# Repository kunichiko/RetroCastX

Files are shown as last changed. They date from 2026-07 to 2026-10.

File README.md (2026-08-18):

# RetroCastX

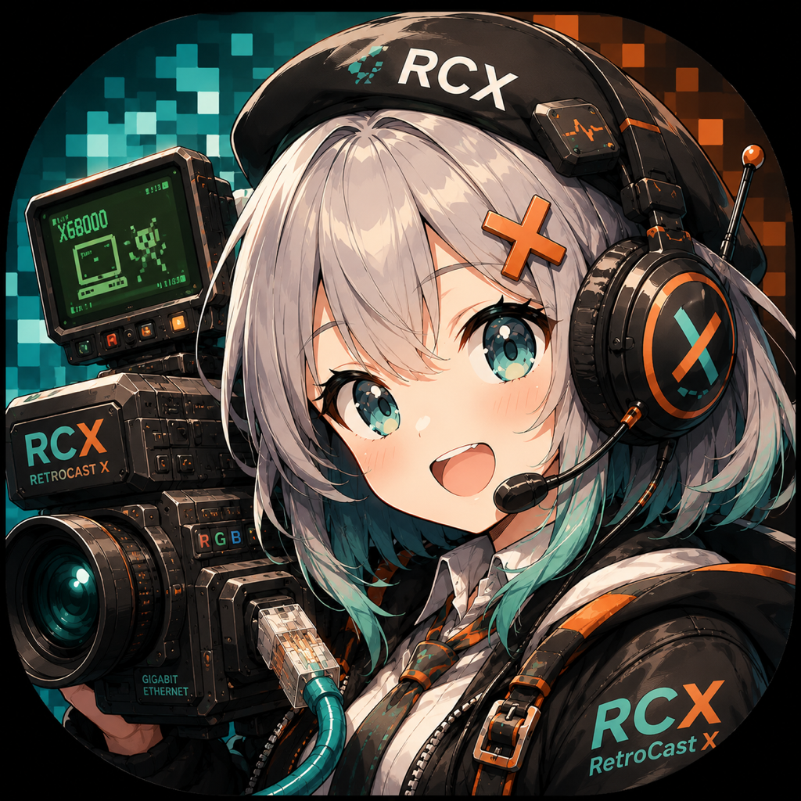
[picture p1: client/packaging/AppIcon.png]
RetroCastX


レトロPC(X68000 / PC-98 など)のアナログRGB信号を、フレームバッファレスで PC/Mac に伝送・表示するプロジェクト。

```
Retro PC ──アナログRGB──▶ ADC(TVP7002) ──24bit+PCLK──▶ FPGA(ECP5) ──UDP/GbE──▶ PC/Mac(再構成・表示)
```

## 設計思想

一般的なアップスキャンコンバータは変換器内でフレームバッファを構築し標準的なHDMI信号に整形するため、
機種固有のタイミング情報が失われ、遅延・モード切替時のブラックアウト・価格の問題が生じる。

RetroCastX は「変換器は馬鹿に徹し、知性はPC側に置く」:

- ADC でドットクロックを再生してサンプリングした**生のピクセルデータを、タイミング情報ごと**
  「1パケット≒1ライン」の UDP で送出する(FPGA はラインFIFO程度しか持たない)
- フレームの再構成・スケーリング・表示は PC/Mac 側で行う

これにより:

- **生タイミング保存**: VRR対応モニタなら 55.46Hz(X68000)等の非標準リフレッシュをそのまま表示可能
- **モード切替の無切断追従**: ゲーム中の解像度切替もヘッダ通知で追従
- **真のロスレス**: 8bit で取得し PC 側でパレット吸着(X68000 は本来 RGB 各5bit)
- **低遅延**: サブフレーム(ライン単位)伝送
- **安価**: フレームバッファ用メモリも高度な画像処理も変換器側に不要

## リポジトリ構成

```
docs/
  protocol-v0.md    伝送プロトコル仕様 v0(ドラフト)
  research/         部品・ボード調査レポート
gateware/           FPGA側(LiteX / Colorlight i5)※sim検証済み、実機未検証
hardware/           ADCフロントエンド基板(Atopile、HAT形式)
host/python/        PC側リファレンス実装(送信シミュレータ・受信・検証)
client/             ビューアアプリ(Rust + eframe/egui、Mac/Win/Linux)
```

## クイックスタート(ハードウェア不要)

送信シミュレータと受信器をループバックで動かす:

```sh
cd host/python
python3 -m retrocastx.tests.test_loopback   # プロトコルのE2E検証
python3 -m retrocastx.tests.test_videoin    # コンポジットの波形解析(合成波形で検証)
python3 -m retrocastx.tests.test_ntsc       # NTSC復調(合成6色で真値と照合)
python3 -m retrocastx.sender_sim &          # テストパターンをUDP送出
python3 -m retrocastx.receiver --dump out   # 受信して out/frame_NNNN.ppm に保存
```

## ハードウェア(フェーズ1〜2 想定)

| 役割 | 部品 | 備考 |
|---|---|---|
| FPGAボード | Colorlight i5 + 拡張基板 | ECP5-25F、GbE PHY ×2、SODIMM I/O 直結 |
| ADC | TI TVP7002 | OSSC と同一。15/24/31kHz 実証済み。ブレークアウト自作 |
| 参考回路 | [marqs85/ossc_pcb](https://github.com/marqs85/ossc_pcb) | アナログ入力段・TVP7002 周辺 |

調査の詳細は `docs/research/2026-07-25-hardware-survey.md` を参照。

## ステータス

- [x] 構想・部品調査
- [x] プロトコル v0 ドラフト(映像 LINE/MODE + 音声 AUDIO + 発見/購読 + CONFIG)
- [x] PC側リファレンス実装(シミュレータ + 受信器)
- [x] LiteX ゲートウェア step2(テストパターン送出+購読) — sim検証・ビットストリーム生成済み
- [x] TVP7002 ブレークアウト設計(音声3系統・ArgusX制御含む、電気設計検証まで)
- [x] ビューアアプリ雛形(Rust + eframe、sender_sim相手にE2E確認済み)
- [ ] ゲートウェア実機動作(ボード入手待ち)
- [ ] 基板発注(atopile部品API復旧後にフットプリント紐付け)
- [ ] 音声キャプチャ(gateware step4)・音声再生(client)
- [ ] 実機キャプチャ(X68000 / PC-98)

## ライセンス

ディレクトリごとに異なります。

| 対象 | ライセンス |
|---|---|
| `gateware/` `client/` `host/` | [Apache License 2.0](LICENSE) |
| `hardware/` | [CERN-OHL-S-2.0](hardware/LICENSE)(強い相互性のオープンハードウェアライセンス) |
| `docs/` | [CC BY-SA 4.0](docs/LICENSE) |

`hardware/` の CERN-OHL-S-2.0 は、**この設計を元に製品を作って頒布・販売する場合、
改変を含む設計一式(Complete Source)を公開し、製品または同梱文書に入手先を明記する**
ことを求めます。個人が自分用に作る分にはこの義務は発生しません。

ライセンスの対象外となるファイル(部品メーカーのデータシート、ベンダー由来の
KiCad シンボル・フットプリント等)については [NOTICE](NOTICE) を参照してください。

### 商標

**"RetroCast X"**(正式名称)および **"RetroCastX"**(ファイル名・識別子・
ハッシュタグ等で用いる短縮形)の名称、ロゴ、アイコン、基板シルク上のブランド
表記は、上記いずれのライセンスの許諾範囲にも含まれません
(Apache License 2.0 第6条)。空白の有無・大文字小文字の違いを問いません。

フォークや派生ハードウェアを頒布する場合は、別の名称を用いてください。

### ハードウェアの製造を検討されている方へ

本設計に基づくハードウェアの製造・頒布を計画されている場合、事前にご一報
いただけると嬉しいです。**ライセンス上の義務ではありません**が、既知の問題や
実装上の落とし穴を共有できますし、改善を上流に取り込める場合もあります。

## コントリビューション

歓迎します。手順と DCO(Signed-off-by)については [CONTRIBUTING.md](CONTRIBUTING.md)
を参照してください。特に**手元の実機での動作報告**が助かります。

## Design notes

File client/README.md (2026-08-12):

# RetroCast X(Viewer / クライアントアプリ)

Rust + eframe/egui(wgpuバックエンド)のクロスプラットフォーム・ビューア。
Mac/Windows/Linux を単一コードベースでカバーする。

```sh
cargo run --release                     # SUBSCRIBEをブロードキャストして実機ボードを受信
cargo run --release -- --board 192.168.10.50   # ボードIP指定
cargo run --release -- --no-subscribe   # 受け専用(sender_sim相手はこれ)
cargo run --release -- --fullscreen     # 低遅延フルスクリーン(下記、ESCで終了)
cargo run --release -- --headless 5 --no-subscribe  # GUIなしで受信統計のみ(検証用)
cargo test                              # プロトコル/アセンブラのユニットテスト
```

## Windows で使うときの必須設定: NICの受信バッファー

**これをやらないとパケットを1〜6%落とす**(映像に穴、音が途切れる)。Intel NIC の
`受信バッファー`(受信記述子リング)の既定 **256** が RetroCastX のパケットレート
(31kHz等倍で約35,000 pkt/s)に足りない。管理者PowerShellで:

```powershell
Set-NetAdapterAdvancedProperty -Name 'イーサネット' -RegistryKeyword '*ReceiveBuffers' -RegistryValue 2048
```

実測(同じ機械・同じ線): **256 → lost 1.7%**(間引き2で帯域1/3にしても落ちる)、
**2048 → lost 0.0013%**(等倍316Mbps、audio underruns 0)。

`SO_RCVBUF`(Viewerは64MB確保する)を増やしても効かない。捨てているのは
ソケットバッファではなく**その手前のNICドライバのリング**だから。切り分けは
`Get-NetAdapterStatistics -Name 'イーサネット' | fl ReceivedDiscardedPackets,ReceivedPacketErrors`
で、**errors≒0 なのに discards が大きい**ならこれ。詳細は
[docs/design-notes.md](../docs/design-notes.md)。

**アプリが自分で気付いて知らせる**(`src/netcheck.rs`)。README を読まなくても
分かるように、**起動時にモーダル**を出し、右パネルの Stats にも警告とコピー
できるコマンドを残す。二段構え:

1. **設定を読む。** ボードのIPから `GetBestInterfaceEx` で経路上のNICを引き
   (全アダプタを見ると Wi-Fi と有線が両方生きている機械で誤判定する)、
   LUID → GUID → レジストリの `*ReceiveBuffers` を読む。**読むだけなので管理者
   権限は不要**(実機の ACL は `BUILTIN\Users: ReadKey`)
2. **実測のロスを見る。** `*ReceiveBuffers` は NDIS の advanced property で、
   **ドライバが公開していなければ存在しない**。実機の15アダプタのうち持っていたのは
   Intel の有線だけで、TP-Link の Wi-Fi は持っていなかった。**無いことを「小さい」と
   扱うと嘘の警告になる**ので、その場合は黙って実測のロス率だけで判断する

**モーダルを出すのは設定チェックのときだけ。** 実際に設定を読んでいて
`Unsupported` / `Unknown` では絶対に出さないので、誤警告の経路が無い。しかも
直せば二度と出ない一度きりの修正で、放置すると確実に映像に穴が開く。
一方ロス率ベースの警告は**推定なうえセッション中に発火する**ので、プレイ中に
割り込ませずパネル内だけにしてある。

管理者権限が無くて直せない人に毎回出すのは敵対的なので「今後表示しない」
(設定の `netcheck_muted`)を用意した。**パネル内の表示は消さない** — 直したく
なったときに情報ごと消えていると困る。`--fullscreen` は UI 層が無いので
stderr にしか出せない。

ボードが見つかる前でも判定する(SUBSCRIBE の宛先で経路を引く)。**ボード発見を
待つと、新規の機械でいちばん警告が要る場面で黙ってしまう。**

`--netcheck <ボードのIP>` で GUI なしに結果だけ見られる。実機(Windows 11 26200)
で4通りとも確認済み: Intel有線 → `Known{2048}`「足りています」、同じNICを一時的に
256 にすると「小さすぎます」+ アダプタ名を埋めたコマンド、TP-Link Wi-Fi →
`Unsupported`、Bluetooth PAN → `Unknown`。値は **REG_SZ の文字列**で入る
(DWORD 決め打ちでは読めない)。

一時変更の検証は `Set-NetAdapterAdvancedProperty ... -NoRestart` で行う。
レジストリだけ書いてドライバを再起動しないので、**リンクが落ちず**(SSH越しでも
切れない)実際の受信性能も変わらないまま、読み取り側の判定だけ確かめられる。

sender_sim を相手にした動作確認:

```sh
(cd ../host/python && python3 -m retrocastx.sender_sim --pixfmt rgb555) &
cargo run --release -- --no-subscribe
```

## 配布(GitHub Actions)

`.github/workflows/viewer-release.yml` が Mac/Windows のビルドと配布をする。
構成は MimicX-app の `release-build.yml` に倣ってあり、**Secretsの名前も同じ**なので
同じ証明書とAPIキーをそのまま設定できる。

| きっかけ | すること |
|---|---|
| タグ `v1.2.3` を push | Releaseを作り zip を添付。macOSは署名+公証+staple |
| main へのPR | 両OSで `cargo test` + ビルドのみ(署名も公証もしない) |
| 手動実行(Actions画面) | プラットフォームを選んでビルド。Releaseは触らない |

**バージョンの正は `client/Cargo.toml`。** タグと食い違っていたら `prepare` で止まる
(`v0.2.0` を打つなら先に `version = "0.2.0"` にしてコミットする)。

必要な Secrets(**RetroCastXリポジトリにも登録が必要**。リポジトリのSecretsは
他リポジトリから見えないので、MimicX と同じ値をコピーする):

| Secret | 用途 |
|---|---|
| `MACOS_CERTIFICATE_BASE64` | Developer ID Application 証明書(.p12)のbase64 |
| `MACOS_CERTIFICATE_PASSWORD` | その .p12 のパスワード |
| `KEYCHAIN_PASSWORD` | CI上に作る一時キーチェーンのパスワード(任意の文字列) |
| `APPSTORE_ISSUER_ID` / `APPSTORE_KEY_ID` / `APPSTORE_PRIVATE_KEY` | 公証(notarytool)用のApp Store Connect APIキー |

Secretsが無くてもビルドは通り、**未署名**の `...-unsigned.zip` ができる(フォークや
PRのため)。ただし**タグからのリリースだけは署名必須**で、無ければエラーで止まる。

成果物:

    RetroCastX_macos-<version>.zip          「RetroCast X.app」universal(arm64+x86_64)、署名済み
    RetroCastX_windows-<version>.zip        RetroCastX.exe + README-first.txt
    RetroCastX_windows-setup-<version>.exe  同じ中身のインストーラ(Inno Setup、未署名)

macOSの `.app` は `packaging/macos/bundle.sh` が組み立てる。**CIのYAMLにロジックを
置かず**スクリプトにしてあるので、手元で同じものを作って試せる:

```sh
cargo build --release
packaging/macos/bundle.sh target/release/retrocastx-viewer 0.1.0 0 /tmp/out
open "/tmp/out/RetroCast X.app"
```

**Windowsはインストーラ版も作る**(`client/packaging/windows/retrocastx.iss`、
Inno Setup 6。`windows-latest` に preinstall されている)。中身は zip と同じで、
違いは**固定パスへ入る**ことだけだが、そこに意味がある:

> Windowsのファイアウォール/ローカルネットワークの許可は**実行ファイルのパス
> 単位**なので、zip を展開する場所を変えたり exe を置き換えたりするたびに
> 許可を聞かれ、**許可するまで映像が来ない**(数秒間まったく反応が無いように
> 見える)。インストーラなら次回以降その入れ替わりが起きない。

zip とインストーラで中身が食い違わないよう、**組み立ては1か所**(ワークフローの
`Package zip` が作る `dist/RetroCastX`)にして、ISCC はそれをそのまま入れる。
`AppId` の GUID は**一度決めたら変えない**(アップグレード判定とアンインストール
の識別が壊れる)。手元で作るときは .iss 冒頭のコメントの手順で。

**macOS はアイコンに角丸マスクをかけない。** 丸みも余白も素材側で作る決まりなので、
`make-icons.sh` は Apple の配置規則(1024の画布に本体824×824、角丸半径185.4、周囲は
透明)に合わせて `.icns` を作る。全面ベタのまま入れると **Dock で四角いアイコンに
なる**(Finderは小さく表示するので黒い角に気づけない。実際これで一度作り直した)。

**Windows も同じ絵を使う**(見た目を揃える方針)。Windowsのアイコンは全面ベタが
普通なので、他のアプリと並ぶと1割ほど小さく見える。全面ベタに戻したくなったら
`make-icons.sh` の ico / PNG の生成元を master に変えるだけでよい。

アイコンは `packaging/AppIcon.png`(1024×1024)が master で、そこから
`packaging/make-icons.sh` が3つを作る。**生成物もコミットしてある**(CIに画像変換
ツールを入れない方針。作り直したときは一緒にコミットする):

    packaging/macos/AppIcon.icns    .app に入る(bundle.sh が拾う)
    packaging/windows/AppIcon.ico   exe に埋め込む(build.rs が拾う)

Windows版はコンソール窓を出さずに起動する(`#![windows_subsystem = "windows"]`)。
コンソールから起動したときだけ `AttachConsole(ATTACH_PARENT_PROCESS)` で親の
コンソールへ出力を戻すので、`--headless` の表示は失われない。

**ただしスクリプトから呼ぶときは待たせること。** GUIサブシステムの実行ファイルは
シェルが終了を待たないので、`& exe --netcheck ...` や `cmd /c exe > log` では
**出力が間に合わず空になる**(実機でこれに引っかかった。exit code は 0 なので
気付きにくい)。PowerShell なら:

```powershell
Start-Process -FilePath .\RetroCastX.exe -ArgumentList "--netcheck","192.168.11.50" `
              -Wait -NoNewWindow -RedirectStandardOutput out.log
```

**exeへの埋め込みだけではタスクバーに出ない。** winit はウィンドウクラスを
`hIcon: 0` で登録し、`window_icon` が `None` なら明示的にアイコンを外すので、

    Explorer のファイルのアイコン → exe に埋め込んだリソース(build.rs)
    タイトルバー / タスクバー     → 実行時に設定する(src/appicon.rs)
    macOS の Dock                → .app の CFBundleIconFile(bundle.sh)

の3つが別経路になる。実行時用に `packaging/AppIcon-256.png` を埋め込んでいる
(1024pxを毎起動デコードするのは無駄なので256px)。

macOS で Dock が既定アイコンのままなら、**アイコン無しの版を一度起動したときの
キャッシュ**が残っている:

```sh
touch "/path/to/RetroCast X.app" && killall Dock
```

未対応(必要になったら):

- **Windowsの署名**: 証明書が無いので未署名。SmartScreenの警告は同梱の
  README-first.txt で案内している
- **ゲートウェア/Python側のCI**: このワークフローはViewerだけを見る

## 構成

- `src/protocol.rs` — プロトコルv0のパース(リファレンスは `host/python/retrocastx/protocol.py`)
- `src/assembler.rs` — LINE→フレーム再構成(RGBA8出力、ロス/迷子ライン統計)
- `src/receiver.rs` — UDP受信スレッド + SUBSCRIBEキープアライブ(2秒ごと)
- `src/main.rs` — eframe UI(映像表示 + モード/統計/発見ボードのサイドパネル)
- `src/remote_input.rs` — MimicX へのキー転送(CoreMIDI SysEx)
- `src/keytap.rs` — 物理キーの取り出し(macOS の AppKit イベント監視)
- `src/netcheck.rs` — NIC受信バッファーの確認(Windows、レジストリを読む)

## MimicX と組み合わせてリモート操作する(macOS)

映像は RetroCastX、キー入力は MimicX(HIDアダプタのホストアプリ)が実機へ送る。
macOS はフォーカスの無いアプリにキーイベントを配送しないので、RetroCastX の画面を
見ながら操作するには**RetroCastX が受けたキーを MimicX へ転送する**必要がある。
プロトコルの仕様は `docs/mimicx-remote-input.md`。

使い方:

1. MimicX を起動し、アダプタに接続して**キーボード操作画面に入る**
   (リモート入力のハンドラはこの画面が生きている間だけ動く)
2. RetroCastX の右パネル「Remote input」で転送を入れる、または **⌘+Shift+ESC**
3. 転送中は画面左上に赤いバッジが出る。**⌘+Shift+ESC かバッジのクリック**で解除

- 切り替えは **⌘+Shift+ESC**(F12 も受け付ける)。⌘ は X68000 のキーボードに無いので、
  組み合わせにすれば実機へ送りたい打鍵と衝突しない。**ESC 単独は実機の ESC**
  として送られる。
  Shift まで要るのは **⌘+ESC が macOS のシステムショートカットに取られていて
  アプリに届かない**ため(`AppleSymbolicHotKeys` id 73)。別の組み合わせに
  変えるときは、先に取られていないかを確かめること:

  ```sh
  defaults export com.apple.symbolichotkeys - | plutil -convert json -o - - \
    | python3 -c "import sys,json;[print(k, v['value']['parameters']) for k,v in json.load(sys.stdin)['AppleSymbolicHotKeys'].items() if v.get('enabled') and 'parameters' in v.get('value',{})]"
  ```

  出力の `parameters` は `(文字, キーコード, 修飾)`。ESC は 53、⌘ は 0x100000。
- 転送中は Tab / B などの RetroCastX 自身のキー操作もすべて実機へ行く。
  マウス操作(パネルやバッジ)は効いたままなので、キーが届かない環境でも戻れる。
- **⌘ 付きの打鍵は Mac の操作**として扱い、実機へは送らない。転送中でも
  ⌘Q で終了、⌘H で隠す、などがそのまま効く(終了時は全解放が走るので、
  キーが押しっぱなしで実機に残らない)。
- 起動時は必ずOFF(保存しない)。キーが黙って実機へ流れる状態で始まらないように。
- 数値欄(pll_div など)へ打ち込んでいる間は転送を止めて UI に譲る。欄から
  外れれば転送に戻る。
- ゲームパッドは転送しない。MimicX がフォーカス無しでも直接受け取るので、
  転送すると二重入力になる。
- Shift / Control / Option の左右、テンキー、JIS 配列のキー(¥ / ろ / かな /
  英数)も区別して送る。egui のキーイベントはこれらを落とし、修飾キーは macOS
  では keyDown を出さないので、AppKit のイベントを直接見ている(`src/keytap.rs`)。
- `--fullscreen` でも ⌘+Shift+ESC で転送できる。転送中の素の ESC は実機の ESC として
  送るので、終了するには先に ⌘+Shift+ESC で転送を切る。
- 経路の切り分けに `--mimicx-probe`。CoreMIDI の宛先一覧を出し、A を
  押して離すところまでを GUI 無しで試す。
- 「このキーが効かない」ときは `--log-keys`。受け取った物理キーと修飾の状態、
  送る usage を stderr へ出すので、**そもそもアプリに届いていない**のか、
  届いているが転送していないのかが分かる(OS が横取りする組み合わせを疑うとき)。

## 設計メモ

- v0.1 は egui 標準のテクスチャAPIで毎フレーム全面アップロード(512×512なら余裕)。
  **パレット吸着・CRTシェーダ・整数拡大以外のフィルタは egui_wgpu の paint callback
  (自前WGSLシェーダ)へ移行して実装する**(次段)

### VRR / 非標準リフレッシュ(55.46Hz等)の追従 — 検証結果(2026-07-27, Mac mini M4 Pro + 60Hz外部モニタ)

`examples/pace_probe.rs`(専用スレッドからwgpuサーフェスへ直接present)による実測:

| 構成 | present間隔 |
|---|---|
| eframe(ウィンドウ、vsync/no-vsyncとも) | **60Hzに量子化**(winitの再描画スケジューリングがディスプレイリンク駆動) |
| 専用スレッド + Immediate、ウィンドウ表示 | **60Hzに量子化**(コンポジタ律速。latency増でも変わらず) |
| 専用スレッド + Immediate、**フルスクリーン** | **ターゲット追従**: 90Hz指定→11.1ms/89.8Hz、55.46Hz指定→18.03ms/55.4Hz(σ~2.5ms) |

結論: **フルスクリーン(direct-to-display)+専用presentスレッド+Immediate** が
55.46Hz追従の実装形。レトロゲーム全画面用途と合致する。ウィンドウ表示時は
60Hz vsyncのジャダーを許容(それでも実用上は十分)。
再現: `cargo run --release --example pace_probe -- 55.46 --latency 3 --fullscreen`

この構成は `--fullscreen` モード(`src/fullscreen.rs`)として本実装済み:
フレーム到着駆動でpresentし、sender_sim 512×512@55.46Hz RGB555 に対して
**present間隔 18.03ms σ0.7ms = 55.46Hz追従・ロス0** を実測確認(2026-07-27)。
プライマリモニタに全画面表示(不可視ディスプレイ対策でモニタ明示)、
ニアレスト+整数拡大レターボックス、ESC/クローズで終了、統計はstderr。
タイムスタンプ駆動のジッタ平滑化(到着ゆらぎをドットクロック時刻で吸収)は次段。

Windows側は wgpu Immediate が DXGI allow-tearing にマップされるので FreeSync で同様の構成が取れる見込み。

#### ProMotionパネルでの追従確認(2026-08-06, MacBook Pro M5 Pro + 内蔵XDR 120Hz, macOS 26.4)

上記で残っていた「**パネルが実際に追従するか**」をProMotion実機で確認した。

app側(`--fullscreen`, 3024×1898全画面, sender_sim 512×512@55.46Hz RGB555):
**present間隔 18.03ms σ0.7ms = 55.46Hz・ロス0・237Mbps** — 別マシン(M4 Pro)の結果を再現。

パネル側は `MTLDrawable.presentedTime`(実際に画面へ出た時刻)で計測した。
**CADisplayLink と `CGDisplayModeGetRefreshRate` は使えない** — presentedTimeが明らかに
120Hz格子から外れている最中も両者は8.33ms/120Hzを報告し続ける(交差検証済み)。

| 構成 | presentedTime間隔 | 格子 |
|---|---|---|
| vsync + 全力present(基準) | 8.335ms σ1.6 | **8.333ms格子に残差0.000ms** → 素の状態は120Hz(計測器の妥当性確認) |
| vsync + 55.46Hz | 平均18.02ms **σ5.3** | 12.5 / 16.7 / 20.8 / 25.0ms に分散。**4.165ms(240Hz)格子に残差0.007ms** |
| Immediate + 55.46Hz(本実装の経路) | 平均18.00ms σ2.8 | どの格子にも乗らない(8.333ms格子の残差1.74ms ≒ ランダム相当)。投入時刻をそのままトレース |

読み取れること:

- パネルは**固定120Hzではなく可変している**(vsync時の間隔が240Hz刻みの離散値を取る)。
  ただし55.46Hzに**ロックはしない** — 240/N Hz の離散ステップを混ぜて平均をソースレートに
  合わせる挙動で、瞬間間隔は σ5.3ms 揺れる。ProMotionは任意レート同期ではない。
- Immediate(= `displaySyncEnabled=false`, 本実装が使う経路)では present が
  **120Hzにゲートされない**。フレームはソースタイミングのまま出る。
  この経路でパネルが走査タイミングまで打ち直しているかは presentedTime からは分離できない
  (どちらの場合も投入時刻に一致する)。最終判断は目視 or ハイスピードカメラ。

再現手順とプローブ(Swift/Metal)は `tools/present_probe.swift` を参照。
- 音声(AUDIO パケット, protocol-v0.md 参照)の再生は未実装。cpal クレートで
  リングバッファ再生を追加予定
- CONFIG パケット(音声ソース選択・ArgusX入力切替)のUIも未実装(プロトコル定義済み)
- インターレース: 現状の実装で自然に **weave 合成**になる(プロトコルの規約により
  LINE.line がフルフレーム行のため。検証済み)。**bob 表示**(フィールド縦2倍・
  フィールドレート表示、コーミングなし)は将来の表示オプション

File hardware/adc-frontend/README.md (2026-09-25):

# RetroCastX ADC フロントエンド(TVP7002 ブレークアウト)

レトロPCのアナログRGB(VGA HD-15経由)を TI TVP7002 でデジタル化し、
24bitパラレル + DATACLK/HSOUT/VSOUT/SOGOUT を Colorlight i5 EXTボードへ渡す
**HAT基板**(EXTのP1/P2/P4に直接スタック)。GbE MagJack・**音声入力4系統**・
ArgusX制御コネクタ搭載。回路は `main.ato`(Atopile)。

## v1.0 の変更点(v0.9.0 → v1.0)

v0.9.0(2026-08-19 発注、実機動作確認済み)からの差分。**電気的に効く変更**と
**部品・コネクタの入れ替え**を分けて書く。

### 入力コネクタ

| 端子 | v0.9.0 | v1.0 |
|---|---|---|
| アナログRGB | D-SUB15(2列DA-15, X68000式) | 変更なし |
| 第2映像入力 | J4: 2×5 ボックスヘッダ(要自作ケーブル) | **J13: ミニDIN8(FRAMEMEISTER互換)** |
| 第2入力のTTL同期 | 同ヘッダの9/10ピン | **J14: 1×3 ヘッダ(HSYNC/VSYNC/GND)** |
| S端子/コンポジット | J5: 2×4 ボックスヘッダ | **J15: 20芯FFC → 小亀基板**(`hardware/console-frontend`)。並びは `音声L/GND/音声R/GND/Pb/GND/C/GND/Y/GND/LED/GND/GPIO2/GND/GPIO1/GND/+3.3V/+3.3V/+5V/+5V`(全信号がGNDに隣接、電源は2本ずつ) |
| 光デジタル(S/PDIF) | J8: PLR135/**T** | J8: PLR135/**T10**(ランドが小さい) |
| デジタルRGB | J6: 1.25mm 単列8極(SMD) | **J6: 2×5 ボックスヘッダ(ストレート)**(XFCN BH254V-10P, C492442)。一般的な10芯フラットケーブルが使える。位置も別エッジへ移動 |
| USB-C | J2 | 変更なし |

### 電気的な変更

- **同期入力にプルアップ 10kΩ を追加**(R47-R50)。D-SUB と 1x3 ヘッダの
  HSYNC/VSYNC。未接続時にシュミット入力が浮いて自己発振し、捕捉側の `raw_ok` が
  誤って立つ不具合(`docs/TODO.md` 10-5b、実機 2026-09-06)の根本対策。
  **プルダウンではなくプルアップ**(レトロ機のTTL同期は負極性=アイドルHigh。
  オープンコレクタ出力の機種にも対応できる)
- **PCM1808 を2個 → 3個**。映像系統ごとに独立させ、受動加算の 1.5kΩ×4 を廃止
- **BIN_1 を実入力に昇格**(小亀基板の Pb / 予備線)。未使用終端の 10nF を撤去し、
  他のチャンネルと同じ前段(75Ω/100nF/220Ω/33pF)を付けた
- **S/PDIF受信の電源にフェライト+10µFを追加**(FB4/C96)。データシートの応用回路が
  47µH+0.1µF を要求しているのに v0.9.0 は 0.1µF だけだった
- **ネジ穴 M2.6 → M3**(穴2.8→3.2mm、パッド5.6→6.4mm)。ねじとスペーサの入手性
- ミニDIN8 の R/G/B/CSYNC に ESD を追加(v0.9.0 の 2x5 ヘッダ経路には無かった)
- **JTAGデバッグ端子(J3, 1×6ヘッダ)を削除**。「外部JTAG器を繋げるように」という保険
  だったが、**FPGAのJTAGへ届く経路はモジュール底面のパッド = ポゴピンしか無い**ので、
  ポゴピンが届かない場合の保険にはならない(CH347Fが壊れた場合にしか効かない)。
  J3 は欠番のまま(`tools/lock_designators.py` が番号の再利用を防ぐ)

### ソフト側に必要な追随(v1.0 基板を使うとき)

- 音声ソースが3系統になる(`i2s_dout_dsub` / `i2s_dout_din8` / `i2s_dout_kokame`、
  DOUT は SO-DIMM 141 / 139 / **129**)。AUDIOパケットの source 番号が増える
- 小亀基板のアナログスイッチ選択線が **SO-DIMM 148(K4)**、予備が150(K5)、
  小亀のシリアルLEDデータが **154(A2)**。プロファイルから駆動する
- ミニDIN8 のプロファイルは **SOGスライス閾値(CONFIG key 0x50)を下げる**
  (規格準拠ケーブルのCSYNCは0.3Vpp → 1/2分圧後0.15Vpp。既定のNTH=11=124mVでは
  振幅の83%を切ってしまう。NTH=7 = 79mV が50%点)

## 音声入力(4系統)

| 系統 | 経路 | 変換 |
|---|---|---|
| RGB端子音声 | J1(D-SUB15)**ピン10=L / ピン11=R** → **U13** PCM1808(直結) | 16bit/48kHz I2S |
| ミニDIN8音声 | J13 **ピン2=L / ピン1=R** → **U14** PCM1808(直結) | 16bit/48kHz I2S |
| 小亀基板音声 | J15(FFC **1=L / 3=R**)← RCA白/赤 → **U17** PCM1808 | 16bit/48kHz I2S |
| 光デジタル | J8(PLR135/T10 TOSLINK) → FPGA直結 | S/PDIFをゲートウェアでデコード |

- **クロック**: X3(12.288MHz XO =256fs@48kHz)は **FPGAにだけ**入る
  (SO-DIMM 130 = F1 = PCLKC6_1)。**ADCのSCKIはFPGAが出し直したもの**で、
  SO-DIMM 147(D2)から両ADCへ配る。BCK(143)= MCLK/4 = 3.072MHz、
  LRCK(145)= MCLK/256 = 48kHz も同じくFPGA生成の共通供給。
  **DOUTのみ個別**(U13=141, U14=139, U17=129)なのでアナログ3系統は同時キャプチャ可能。
  S/PDIFのDIRチップは不要(FPGAでデコード)

  ★**XOはADCに直接は繋がっていない。** 以前この節は「XO→両ADCのSCKIとFPGA」と
  書いていたが誤りで、音が出ない件の切り分けで探す場所を間違える原因になった
  (2026-09-03)。信号を追うときは必ず FPGA の出力(147)から見ること。

- ★**実装の注意: SCKI(6番)は DGND(5番)の真隣。** TSSOP-14 の 0.65mm ピッチなので
  5-6間がブリッジすると MCLK が GND に落ちる。**両ADCがMCLKを共有しているので、
  片方のICの下のブリッジで音声が2系統とも死ぬ。** 実際に v0.9.0 で発生した
  (2026-09-03)。そのときの症状:

  | 観測 | 値 |
  |---|---|
  | 転送される音声サンプル | 両ch**ビット単位で完全にゼロ**(入力無しならディザが出るはず) |
  | サンプルレート | 48kHz で正常(FPGA内部とBCK/LRCK生成は無事) |
  | ADC 7番(LRCK)/ 8番(BCK) | 正常に観測できる |
  | ADC 6番(SCKI) | **完全に平坦**(鈍りではない) |
  | ADC 1番(VREF) | **0V**(SCKIが無いとリセットが解けず基準電圧が立たない) |
  | アナログ5V(C60) | 正常 |

  VREF=0V は原因ではなく**結果**。この並びが出たら 5-6 間のブリッジを疑う
- **D-SUB音声の切り離しジャンパは削除した**(2026-08-11)。当初は「VGA HD-15の
  ピン4/11はID/DDCなので、一般VGAケーブルを挿す運用では切り離せるように」という
  理由で入れていたが、**コネクタを2列DA-15(X68000式)に変えた時点で3列のVGAケーブルは
  物理的に挿せなくなり**、この理由は消えていた。その後「LINE入力優先時」と読み替えられて
  いたが、**LINE入力はADCが別(U1=D-SUB / U2=LINE)でDOUTも個別**なので D-SUB 側を切る
  必要はない。よって直結にした
- どの系統を転送するかはアプリからCONFIGパケットで選択(複数同時も可)。
  詳細は `docs/protocol-v0.md` の AUDIO / CONFIG 参照

## デジタルRGB入力(TTL RGBI + HS/VS)

アナログRGB(TVP7002経由)とは**別経路**で、PC-6001mkII/SR・PC-8801・X1 等の
**デジタルRGB**を取り込む。TTLの R/G/B/I(輝度)4bit + HS + VS の6本。

```
J6(2×5 ボックスヘッダ) → ESD → 10kプルダウン → SN74LVC2G17 ×3 → FPGA(SO-DIMM P4クラスタ)
                                        (5Vトレラント・シュミット)
```

- **TVP7002は通さない**。デジタル値をADCに入れる意味は無く、TVPのH-PLLはアナログ用の
  ループフィルタ定数で固定されている。ドットクロックは**FPGA内で50〜100MHz程度の
  オーバーサンプリングから再生**する(または生サンプルのまま送ってPC側でデコードする)。
  よってクロック線は基板上に無い
- **レベル変換は必須**: レトロ機のデジタルRGBは5V TTLだが **ECP5のI/Oは5Vトレラントでは
  ない**。3.3V以上を直接入れると入力保護ダイオードが導通してFPGAを壊す。
  既存の同期バッファと**同じ SN74LVC2G17**(入力5.5Vまで許容・シュミット・出力3.3V CMOS)を
  dual×3個=6chで使う → **BOM行が増えない**
- **10kΩプルダウン**: ケーブル未接続時に入力が浮くとシュミットでも中間電位で発振する。
  各入力をGNDに落として「未接続=L」に確定。TTL出力(LOWシンク数mA)に対して10kは軽い。
  ※オープンコレクタ出力の機種を繋ぐ場合は、この抵抗を外して同じパッドに3.3Vへの
    プルアップを実装する
- **RCフィルタは入れない**。アナログ側と違い折り返しの問題が無く、逆にエッジが鈍って
  オーバーサンプリングでのドットクロック再生精度が落ちる
- **csync(複合同期)の機種**もHSピンに入れればゲートウェアで分離できる(4bit色は不変)
- アナログRGB経路とは**FPGAピンが別**なので、アナログ機とデジタル機を**両方繋いだままに
  してよい**(音声だけは排他 → デジタル機の音声は J6 の3.5mm LINE入力を使う)

### コネクタ(J6)と信号順 ── v1.0 で 2×5 ボックスヘッダへ

**XFCN BH254V-10P**(2×5 ボックスヘッダ、2.54mm、**ストレート/垂直**、LCSC: C492442)。

| pin | 1 | 2 | 3 | 4 | 5 | 6 | 7 | 8 | 9 | 10 |
|---|---|---|---|---|---|---|---|---|---|---|
| 信号 | GND | **R** | **G** | GND | **B** | **I** | GND | **HS** | **VS** | GND |

```
   1 GND    3 G    5 B    7 GND    9 VS      ← 奇数列
   2 R      4 GND  6 I    8 HS    10 GND     ← 偶数列
```

- **ピン番号 = フラットケーブルの導体順**。IDCは導体1本目がpin1、2本目がpin2…と
  交互に奇数列/偶数列へ入るので、ケーブル自作時に「導体のn本目 → n番ピン」で数えられる
- **なぜ 2×5 か**: 信号6本+GNDなので 2×4(8極)で足りるが、**秋月電子などで手に入り
  やすいのは10芯**。増えた2極をGNDに充てた
- ★**GNDを挟んで6本すべてが隣にGNDを持つ**ようにしてある。リボンケーブルは
  **隣の導体が帰り路**になるので、ここがクロストークと波形の鈍りに一番効く。
  R/G/B/I はドットクロック速度(機種により数〜14MHz)で変化するので無視できない。
  v0.9.0 の8極では信号6本+GND2本しか取れず GND は両端だけ(HS が GND に隣接しない)で、
  README にも「10極にするならGNDを1本おき」と書いてあった。v1.0 でそれを実現した
- **信号の順番は R/G/B/I → HS/VS のまま**(2026-08-11 に「ケーブル自作時の分かりやすさ
  優先」で決めた並び)。GNDを挟んだだけで色と同期の順序は変えていない
- ★**一度 右アングル(L型, BH254R-10P)にしたが、基板上の場所が足りずストレートに
  戻した**。L型はシュラウドが +y へ 8.8mm 伸びて外形 20.5 × 13.9mm になる。
  ストレートは **20.30 × 8.70mm** で y 方向が5mm以上小さい。**高さ方向には余裕がある**
  ので、リボンが基板に垂直に立つのは許容する判断
- ピン1は **x = -5.08, y = +1.27**(L型とは逆の角)。シルクの「1」とリボンの赤線の
  向きを必ず確認する。シュラウドの極性切り欠きがリボンの抜ける向きを決める
- 機種ごとの変換ケーブル(8ピンDIN等 → 2×5 IDC)は自作する。**5V TTLのまま入れてよい**

### SO-DIMM割当(P4クラスタの空き)

ピン昇順で **VS / HS / I / B / G / R** の並び(2026-08-11 変更。レイアウト上の交差を減らすため)。

| SO-DIMM | ボール | 信号 |
|---|---|---|
| 132 | F3 (PCLKC7_1) | drgb_vs |
| 136 | H3 | drgb_hs |
| 140 | H5 | drgb_i |
| 142 | J4 | drgb_b |
| 144 | J5 | drgb_g |
| 146 | K3 | drgb_r |

★以前は「HS をクロック対応ボール F3 に置いて将来 PLL 基準に使う余地を残す」として
いたが、この並べ替えで VS が F3 に来る。実用上の損失は小さい: **ECP5 の PLL は入力
下限が数MHz級**で、15〜31kHz の HS を直接 PLL のリファレンスにはできない。ドットクロック
再生は結局デジタル(オーバーサンプリング + 分周/DDS)で行うので、クロック網に載る利点は
ほとんど無い。必要になったら **G3(pin134, PCLKT7_1) / H4(pin138, GR_PCLK7_1) が未接続の
予備**として残っているのでそちらへ移せる
(外部ドットクロックを入れたくなったら、4個目のLVC2G17を足してここへ)。

## 将来拡張用デバッグ端子(J4, 2×15)

SO-DIMM **偶数側 pin54〜94**(pin56=GNDのみ除く)= 完全に連続した空きGPIO **20本**を
2×15ヘッダへ引き出す。ソケット上でも0.6mmピッチで一列に並ぶので、
SO-DIMM昇順 ↔ ヘッダ昇順の単調割当で**交差無し**に引ける。

| ヘッダpin | 1,2 | 3-10 | 11,12 | 13-20 | 21,22 | 23-26 | 27,28,29 | 30 |
|---|---|---|---|---|---|---|---|---|
| | GND | dbg1-8 | GND | dbg9-16 | GND | dbg17-20 | GND | 3V3 |

- **5列ごとにGNDカラム**を挟むのでロジアナのGNDクリップが近くに取れる
- **3V3は角(pin30、両隣はGND)**に置き、GPIOへの誤ショートを避ける
- ネット名 `dbg01_m1` … `dbg20_f18`(番号=SO-DIMM順、末尾=FPGAボール名)
- **dbg14 = J18 = GR_PCLK2_0(クロック対応)** → 外部クロック入力に使える
- **直列保護抵抗は入れていない**。外部回路を繋ぐ実験で保険が欲しければ各線に33〜100Ωを
  後付けする(20本ぶんの0402を常設するのは面積の無駄と判断)

| dbg | 1 | 2 | 3 | 4 | 5 | 6 | 7 | 8 | 9 | 10 |
|---|---|---|---|---|---|---|---|---|---|---|
| SO-DIMM | 54 | 58 | 60 | 62 | 64 | 66 | 68 | 70 | 72 | 74 |
| ボール | M1 | N2 | N3 | T2 | M3 | T3 | R3 | N4 | M4 | L4 |

| dbg | 11 | 12 | 13 | 14 | 15 | 16 | 17 | 18 | 19 | 20 |
|---|---|---|---|---|---|---|---|---|---|---|
| SO-DIMM | 76 | 78 | 80 | 82 | 84 | 86 | 88 | 90 | 92 | 94 |
| ボール | L5 | P16 | J16 | **J18** | J17 | H18 | H17 | G18 | H16 | F18 |

## ArgusX(RGBセレクタ、別プロジェクト)連携

J11(1×4: 3V3/SDA/SCL/GND)にTVP7002と共有のI2Cバスを引き出し。アプリからの
CONFIGパケット(target=ArgusX)をゲートウェアがI2C書き込みに中継し、セレクタの
入力切替をアプリから行える。ArgusXのI2Cアドレス/レジスタマップは同プロジェクト側で
確定後に反映。**I2Cアドレスの割当: TVP7002=0x5C(7bit)、MAC EEPROM=0x50/0x51
→ ArgusXは0x50-0x53と0x5Cを避けること**。

## MACアドレス(EUI-48 EEPROM)

U13/U14(24AA025E48)に工場書込みのグローバル一意MACを搭載。
ゲートウェアが起動時にI2Cで読み出してEthernetに設定する
(EEPROM未実装/読出し失敗時はローカル管理アドレス02:52:43:58:xx:xxへフォールバック)。
複数台運用・2ポートストライピング(ETH1追加時)でMAC衝突管理が不要になる。
EEPROMの空き領域(~250B)は個体設定(IP・ボード名等)の保存に使用
(旧計画のSPIフラッシュ設定ページを置き換え)。

## 回路の構成(根拠: TVP7002データシート SLES206C / OSSC rev1.8 実機回路)

- **アナログ入力**: VGA各色 → ESDアレイ → 75Ω終端 → 100nF ACカップリング → RIN_3/GIN_3/BIN_3。
  緑は追加で 1nF → SOGIN_3(Sync-on-Green対応)
- **同期入力**: HS/VS → ESD → SN74LVC2G17(シュミット、5Vトレラント)→ HSYNC_A/VSYNC_A。
  VSYNC側は 220Ω+1nF のRC遅延(データシート推奨: VSYNCエッジとHSYNCの完全一致を回避)。
  複合同期(csync)はHSYNCピンに入れれば内部セパレータが分離する(4線モード)
- **H-PLLループフィルタ**(唯一の必須外付け): FILT1→1.5kΩ+100nF→PLL_F、FILT2→4.7nF→PLL_F
- **27MHz発振器** → EXT_CLK(モード検出の安定化用。動作自体は同期駆動で可)
- **電源**: **本基板が電源マスター(既定)**。J10 USB-C(CCにRd 5.1kΩ実装 → PD充電器+
  C-Cケーブルで5V/3A受電可)から給電し、SJ1(閉=既定)でP1/P2/P4の5Vピン経由で
  **EXTボードへ逆給電**する。この運用ではEXTのスライドスイッチS1をOFFにし、EXTのUSB-Cは
  JTAG/UARTデータ専用とする。代替入力: J7 DCジャック(J10と排他)。合計消費 ≈1.2A。
  ※EXTボードのUSB-CはCC未接続(Rdなし)のためC-Cケーブルでは受電できない(回路図で確認済み)。
  5Vレールから →
  - AZ1117H-3.3 → 3.3V IO系(IOVDD、発振器、バッファ、プルアップ)
  - AZ1117H-3.3(別個)→ 3.3Vアナログ(A33VDD)
  - AZ1117H-ADJ + 120Ω/62Ω分圧 ≈1.896V → AVDD・PLL_AVDD(各フェライトビーズ経由)
  - TLV70019(1.9V)→ DVDD
- **未使用入力**: video系は10nF、SOG系は1nFでGNDへ(データシート指定)
- **ストラップ**: PWDN/TMS/CLAMP/COAST/HSYNC_B/VSYNC_B→GND、I2CA→GND(I2Cアドレス0xB8)、
  RESETB は2.2kプルダウン(FPGAがHighで解除)、SDA/SCL 2.2kプルアップ

## 主要部品

★この表は **`default.kicad_pcb` と `build/builds/default/default.bom.csv` から生成した**
(2026-08-13)。以前は手書きで、部品番号もデジグネータも実装と食い違っていた
(X1 が X322527MSB4SI → 実際は OT322527MJBA4SL、U5 が AZ1117H-ADJ → 実際は RT9013-18GB、
ESD が PESD5V0U4BW → 実際は EMZT6.8ET2R など)。値・在庫は LCSC 品番で確認すること。

★デジグネータは 2026-08-13 に **main.ato の宣言順**へ振り直した。旧番号との対応は
`docs/designator-map.md`。**手組みの試作機(V0)は旧番号のまま**。

| Ref | 部品 | メーカー | LCSC | 回路上の位置 |
|---|---|---|---|---|
| D1, D2, D3, D5, D6, D8, D10, D11, D12 | EMZT6.8ET2R | ROHM | C510333 | `esd_rgb, esd_sync2, esd_sync, drgb.esd[0], drgb.esd[1], esd_audio, esd_din8, esd_ffc, esd_audio2` |
| D7 | 1N4148W | ST(Semtech) | C81598 | `d_led` |
| D9 | USBLC6-2SC6 | STMICROELECTRONICS | C7519 | `esd_usb` |
| FB1, FB2, FB3, FB4 | MPZ1608S221ATA00 | TDK | C76815 | `fb_avdd, fb_pll, fb_audio, fb_spdif` |
| H1, H2, H3, H4, H5 | MountingHole_3.2mm_M3_Pad | — | — | `mount[0], mount[1], mount[2], mount[3], mount[4]` |
| J1 | DS1037-15FNAKT76-0CC | CONNFLY | C77836 | `vga` |
| J2 | TYPE-C-31-M-12 | 韩国韩荣 | C165948 | `usbc` |
| J6 | BH254V-10P | XFCN | C492442 | `j_drgb` |
| J7 | Header_2x15_P2.54mm | — | — | `j_dbg` |
| J8 | PLR135_T10 | — | — | `spdif` |
| J9, J10 | Header_1x4_P2.54mm | — | — | `j11_argus, j_oled` |
| J11, J12 | HR911130A | HANRUN | C54408 | `eth.jack, eth.jack2` |
| J13 | MJ373_8B | — | — | `din8` |
| J14 | Header_1x3_P2.54mm | — | — | `hdr_sync` |
| J15 | 0.5K-1.5-20PWB | HDGC | C2919559 | `ffc` |
| JP1 | SolderJumper_2_Bridged | — | — | `sj_ext5v` |
| LED1 | XL-2020RGBC-2812B | XINGLIGHT | C5349955 | `led_status` |
| PG1, PG2, PG3, PG4 | PogoPin_D1.0mm | — | — | `pogo_tck, pogo_tms, pogo_tdi, pogo_tdo` |
| TP1, TP2 | TestPoint_TH1 | — | — | `tp_ys, tp_led_do` |
| U1 | TVP7002PZP | TI | C3824085 | `tvp` |
| U2, U8, U10, U11, U12 | SN74LVC2G17DBVR | TI | C10429 | `buf_sync, buf_sync2, drgb.buf[0], drgb.buf[1], drgb.buf[2]` |
| U3, U4 | AZ1117H-3.3TRE1 | DIODES | C92517 | `supply.ldo_io, supply.ldo_a33` |
| U5 | RT9013-18GB | RICHTEK | C59969 | `supply.ldo_a19` |
| U6 | TLV70019DDCR | TI | C2862411 | `supply.ldo_d19` |
| U7 | CH347F | WCH | C18221627 | `ft2232.ch` |
| U9 | 1473005-4 | TE Connectivity | C428482 | `sodimm` |
| U13, U14, U17 | PCM1808PWR | TI | C55513 | `adc_dsub.adc, adc_aux.adc, adc_kokame.adc` |
| U15, U16 | 24AA025E48-I/SN | MICROCHIP | C46840 | `eeprom_mac0, eeprom_mac1` |
| X1 | OT322527MJBA4SL | YXC | C725995 | `osc` |
| X2 | X32258MSB4SI | YXC | C2682774 | `ft2232.xtal` |
| X3 | OT2JI-111-12.288M | YXC | C20617595 | `xo_audio` |

抵抗・コンデンサは値・パッケージ指定済み(atopileのピッカーが実部品を自動選定)。
パスコンの実配置レポートは `../../docs/decoupling-placement.html`(基板から生成)。
**現物の designator は `ato build` 後の `layouts/default/default.kicad_pcb` が正。**
番号は **main.ato の宣言順**に振ってあり(`tools/renumber_designators.py`)、
V0試作機の旧番号との対応は `docs/designator-map.md`。

## GbE 差動ペアの対応(2026-08-19 検証、v0.9.0 発注後)

**結論: 配線は正しい。** 3つの独立した根拠で一致を確認した。

### ★「どのペアをどこに繋いでも良い」は誤り

以前そう説明していたが間違いだった。実際に自動補正されるのは限られた範囲だけで、
利用者は手半田の試作基板で**リンクアップしない**現象として踏んでいる。

```
オートネゴシエーション(IEEE 802.3 Clause 28)は FLP バーストをペアA でしか流さない
  → 完了するまでペアC/D は一切使われない
  → ペアA が PHY の MDI1/MDI2 に来ていないと**リンク以前に成立しない**

Auto MDI/MDI-X(Clause 40.4.4)が直せるのはクロスケーブル相当の入れ替えだけ。
  A↔B と C↔D が同時に入れ替わるパターンのみ。任意の置換(A↔C など)は対象外
ペア内の極性(+/−)は自動補正される
```

→ **{A,B} は {MDI1,MDI2} に、{C,D} は {MDI3,MDI4} に**乗っていなければならない。

### 検証① HR911130A データシート(datasheets/HR911130A_HanRun_MagJack.pdf の Schematics)

magjack 内部は部品で固定されているので、基板側パッドと RJ45 接点の対応は一意に決まる。

| 基板パッド | 内部 | RJ45接点 | ペア |
|---|---|---|---|
| P2 | MDI0+ | J1 = pin 1 | A+ |
| P3 | MDI0− | J2 = pin 2 | A− |
| P4 | MDI1+ | J3 = pin 3 | B+ |
| P7 | MDI1− | J6 = pin 6 | B− |
| P5 | MDI2+ | J4 = pin 4 | C+ |
| P6 | MDI2− | J5 = pin 5 | C− |
| P8 | MDI3+ | J7 = pin 7 | D+ |
| P9 | MDI3− | J8 = pin 8 | D− |
| P1 | chip側センタータップ(4本内部共通) | — | — |
| P10 | Bob-Smith共通(内部 4x75Ω → 1000pF/2kV 経由) | — | — |

### 検証② 発注した基板の実配線(pcbnew から読み出し)

J11 / J12 とも下表どおり。SO-DIMM 側 16本もすべて `sodimm_i5.ato` の宣言と一致。

```
eth*_1_P/N → P2/P3 → ペアA (pin 1,2)   ← オートネゴがここを使う
eth*_2_P/N → P4/P7 → ペアB (pin 3,6)
eth*_3_P/N → P5/P6 → ペアC (pin 4,5)
eth*_4_P/N → P8/P9 → ペアD (pin 7,8)
```

### 検証③ 動作実績のある参照設計との突き合わせ

`kazkojima/colorlight-i5-tips` の **i5ether**(1000BASE-T netboot/nfsroot 実績あり)の
`i5ether.kicad_pcb` からネットリストを抽出し、トランス HX5008 の巻線対応
(chip側 pin N ↔ line側 pin 25−N。センタータップ4箇所 1↔24 / 4↔21 / 7↔18 / 10↔15 が
すべて一致することで確定)まで辿った結果:

```
MDI1P → RJ45 pin 1    MDI1N → pin 2   ペアA
MDI2P → pin 3         MDI2N → pin 6   ペアB
MDI3P → pin 4         MDI3N → pin 5   ペアC
MDI4P → pin 7         MDI4N → pin 8   ペアD
```

**極性まで含めて本基板と完全一致。** `chenzhuoyu/rainbow-board`(同じ magjack を
SO-DIMM 直結で使う独立実装)も同一だった。Bob-Smith の構成(75Ω → 1000pF内蔵 →
シャーシ、外部 4.7nF/2kV でGNDへ)も同じ。

※ i5ether は EXT ボードの P1 ヘッダ(2x15)に挿す設計で、そのヘッダ番号は
  `docs/sodimm-pinmap.html` の P1 番号と**一律 +4 ずれている**(i5ether の J1 pad
  5-12 と 23-30 ↔ 資料の P1·1-8 と 19-26)。オフセットが両ポートで同一なので
  相対関係は保たれており、上記の対応付けに影響しない。本基板は SO-DIMM 直結なので
  EXT の番号自体は無関係。

### ★実装時の注意

**1. 基板に ETH1/ETH2 のシルクが無い。** どちらの RJ45 がどちらか基板上で判別できない。

```
J11 (y=58.5, 上側)  eth2_* = SO-DIMM 偶数ピン 16/18/24/22/28/30/36/34
J12 (y=77.0, 下側)  eth1_* = SO-DIMM 奇数ピン 15/17/23/21/27/29/35/33
```

さらに**呼び名が資料間で逆**。`docs/sodimm-pinmap.html`(出典: wuxx ext-board 図)は
偶数ピンを Eth2 と呼ぶが、rainbow-board は同じ偶数ピンを ETH1 と呼ぶ。配線は同じで
ラベルだけの違いだが、ゲートウェアの PHY インデックス選択で迷う原因になる。
→ v1.0 でシルクに ETH1/ETH2 を入れること。

★**litex の eth index との対応(2026-09-02 実機で確定)**。以前ここには
「ETH2=jack(J11)=PHY0=litex eth1」と書いていたが**逆だった**。
`litex_boards/platforms/colorlight_i5.py` 自身にこう書いてある:

> The order of the two PHYs is swapped with the naming of the connectors on the
> board so to match with the configuration of their PHYA[0] pins.

```
platform.request("eth", 0) = コネクタ ETH2 = eth2_*(偶数ピン) = J11
platform.request("eth", 1) = コネクタ ETH1 = eth1_*(奇数ピン) = J12  ← gateware 既定
```

手組み試作機では配線がたまたま index=1 と一致していたので露見せず、v0.9.0 で J11 に
挿した瞬間に「リンクはするのに ARP も ping も返らない」という形で出た。
**判断はコネクタ表記ではなく SO-DIMM ピン番号の偶奇で行うこと。**
`retrocastx_stream.py --eth-phy {0,1}` で切り替えられる(既定 1 = J12)。
J11 へ移す場合は **seed 3 では index=0 の eth_rx が 122.55MHz(制約125)で閉じない**
のでシード探索が要る(index=1 は seed 3 で 131.51MHz PASS)。

**2. センタータップのネット名が入れ違っていた(2026-09-02 に main.ato 側を修正済み)。**

```
修正前  eth.jack.ct  = "eth1_ct"   ← jack は eth2_* を運ぶのに eth1_ct
        eth.jack2.ct = "eth2_ct"   ← jack2 は eth1_* を運ぶのに eth2_ct
修正後  eth.jack.ct  = "eth2_ct"   (= J11, C80, 表面)
        eth.jack2.ct = "eth1_ct"   (= J12, C81, 裏面)
```

電気的には各ポートに独立した 100nF が付いているだけなので無害だったが、
**この名前の逆転が実機デバッグで実害を出した**。v0.9.0 の実装で C81 が
未実装だったとき、「eth2_ct が載っていない」を J11 側の欠品と誤読した
(実際に欠品していたのは J12 の C81)。★**基板は v0.9.0 のまま**なので、
現物のシルク/ネット名は旧のまま。次に `ato build` を流した時点で新名称になる。

## Ethernet LED: PHY直結 / GPIO の二経路(2026-08-11)

MagJackのリンク/アクティビティLEDを **2経路**用意し、実装で選べるようにした。

```
経路A(既定) i5モジュール底面のPHY LEDパッド → ポゴピン(PG5-8) → 220Ω → MagJack pin11/14
経路B(代替) FPGA GPIO → はんだジャンパ(JP4-7, 既定=開) → 220Ω → 同じアノード
```

**きっかけ**: [chenzhuoyu/rainbow-board](https://github.com/chenzhuoyu/rainbow-board) が
JTAGと同じ流儀で、**PHYのLED出力をモジュール底面からバネ端子で拾って**MagJackのLEDへ
入れていた。同じ HR911130A 系MagJackで、LEDピンの割当(11/14=アノード, 12/13=カソード)も
本設計と一致していた。

- **経路Aの利点**: ゲートウェア不要(PHYが出す本物のリンク/アクティビティ)。
  **ビットストリームを焼く前から光る**ので「そもそもリンクしているか」が即分かる。
  FPGAのGPIO 4本(io_r1/io_t1/io_u1/io_y2)も解放される
- **経路Bへの逃げ道**: ポゴピンの接触不良やPHYパッド位置の食い違いに備え、GPIO側を
  直列はんだジャンパにしてある。**基板改造なしで切り替えられる**
- ★**同時に両方生かさないこと**。両方だとPHY出力とGPIO出力が440Ω越しに押し合う
  (≒7.5mA。壊れはしないが表示が濁る)。経路A運用時はゲートウェアでGPIOを入力にしておく
- 抵抗は **220Ω**(既存部品と同一 = BOM行が増えない)。3.3V・Vf≒2Vで約6mA。
  rainbow-boardは68Ω(≒19mA)だが、i5モジュール側に直列抵抗が入っている可能性があり
  (モジュール自身のLEDと並列にタップしている疑い)、PHYのLEDピンへ流し過ぎるリスクを
  避けて安全側にした。暗ければ100Ω→68Ωへ下げる

### ポゴピン位置(rainbow-boardの実測値)

SO-DIMMソケット原点からの相対位置。**JTAGの縦33mmが本設計の想定値と一致した**ので、
この座標系は信用できる。

| 端子 | 相対位置 | 本設計 |
|---|---|---|
| JTAG 1×04 | (−24.15, −33.30) | PG1-4(TCK/TMS/TDI/TDO) |
| ETH1 LEDs 1×02 | (−22.08, −29.59) | PG5(D2=緑) / PG6(D4=黄) |
| ETH2 LEDs 1×02 | (−22.15, −15.43) | PG7(D2=緑) / PG8(D4=黄) |

※rainbowのソケット向き基準。本設計はソケットの回転が違うので、レイアウト時に
「ソケット原点から見た同じ相対位置」へ置き換えること。rainbowのLED用ドリルは
**0.5mm**(JTAGの0.9mmより細い)。

### ネット名

`eth{1,2}_phy_led_d{2,4}`(PHYタップ) / `eth{1,2}_led_{g,y}_gpio`(GPIO) /
`eth{1,2}_led_{g,y}_gpio_sj`(ジャンパ〜抵抗) / `eth{1,2}_led_{g,y}_anode`(合流点)

### 2026-08 変更分(SO-DIMMソケット)

| Ref | 部品 | LCSC | 備考 |
|---|---|---|---|
| U11 | **TE 1473005-4** DDR2 SO-DIMM 200P ソケット(Right Angle=寝かせ型) | **C428482** | 在庫1636・$4.48。ベンダ純正フットプリント(ラッチ保持パッド・非対称位置決め穴・STEP付き) |
| PG5-PG8 | ポゴピン ×4 | — | PHY LEDタップ(手実装/DNP) |
| JP4-JP7 | はんだジャンパ ×4 | — | LED GPIO経路の選択(既定=開) |
| R27-R30 | 220Ω 0402 ×4 | C25091 | PHY LEDタップの直列抵抗 |

旧: JST DM-7D4-H2500(M)(C483268)のフットプリントを流用していたが、これは**モジュールが
基板に垂直に立つタイプ**だった。本設計は i5 を**寝かせる**前提(JTAGをモジュール底面へ
ポゴピンで接触させる)なので水平タイプへ差し替えた。

型番は [hansfbaier/colorlight-qmtech-adapter](https://github.com/hansfbaier/colorlight-qmtech-adapter)
の JLCPCB 発注用BOM(`jlcpcb/assembly/BOM-Colorlight2QMTech.csv`)から判明した
(`1473005-4,CN1,...,C428482`)。**LCSCで普通に買えるので手実装専用にせず実部品として
BOMに載せている**(JLCの実装ライブラリ収載は未確認)。

- 信号: 2列 × 100パッド、**列間 8.60mm**、パッド 0.35 × 2.0mm、span 63.00mm + キー切欠4.2mm
- **ラッチ保持SMDパッド 4.5 × 4.6mm ×2**(pad名201、同一ノード)→ GNDへ接続
- **位置決め穴 φ1.6 / φ1.1 の非対称**(向き間違い防止)。穴径=パッド径のPTHだったので
  アニュラー幅ゼロを避けるため **NPTHに修正済み**
- ボディ **71.5 × 26 × 5.2mm**(STEPより)。モジュールが基板を覆うので**その下の部品高さと
  ポゴピンの届く高さ**に注意

※途中で TE 1717254-1 の仕様表から「列間6.2mm」と判断したが誤りだった。TEの
"Reihenabstand" は基板ランドの列間ではない。実フットプリント3件
(TE 1473005-4=8.60mm / TE 1473149-4=8.20mm / KiCad標準のDDR4版=8.20mm)で確定させた。
**1473149-4 と 1473005-4 はランドが違う(8.2 vs 8.6mm)ので、買う型番と一致させること。**

詳細と発注前チェック項目は `docs/layout-guidelines.md` §0.5 を参照。

### 2026-08 追加分

デジタルRGB入力・デバッグ端子・ステータスLED・S-Video/コンポジット入力を追加した。
**部品と designator は上の「主要部品」表(基板から生成)を見ること。**
以前ここに手書きの表があったが、旧番号のまま残って上の表と食い違っていたので削除した。

## ビルド状態

`ato build` は **Verify electrical design(電気設計検証)まで全ステージ通過済み**。
最終段の部品選定(Picking parts)は atopile の部品API
(components.atopileapi.com)が必要だが、**2026-07-18頃からDNSレコード消失により
全世界的に停止中**([atopile#1829](https://github.com/atopile/atopile/issues/1829)、
0.15.7/main 両方で再現、2026-07-28時点でも未復旧)。

### オフライン部品取り込みの回避策(2026-07-28確立)

atopileの**検索・パラメトリック選定API**(atopileapi、死亡)とは別に、
**フットプリント実体はEasyEDA**(easyeda.com、生存)から取得できることを利用する。
`tools/ingest_parts.py` が、既知のLCSC番号を渡すと `ato create part` 相当を
オフラインで実行し `parts/<MFR_PN>/{.ato,.kicad_mod,.kicad_sym}` を生成する
(取得後のメーカー名enrich呼び出し=atopileapiのみスタブ化)。

```sh
/Users/ohnaka/.local/share/uv/tools/atopile/bin/python tools/ingest_parts.py C10429 C3824085 ...
```

生成された部品は `has_part_picked` traitを持つため、`ato build` の選定処理で
**スキップされ、atopileapiを叩かない**。よって**全部品をatomic part化(=各部品に
LCSC番号を割当てて取り込み)すれば、`ato build` が完全オフラインで通り、
ネットリスト・PCB・BOM・JLCfabデータまで生成できる**。

取り込み済み(2026-07-28、`parts/`): TVP7002, SN74LVC2G17, AZ1117H-3.3,
AZ1117H-ADJ, TLV70019, MPZ1608S221A, 27MHz OSC(X322527), VGA-002, DC005,
TYPE-C-31-M-12, HR911130A の11点。
未取り込み: PESD5V0U4BW(C5182054はEasyEDAにデータ無し→代替番号要選定)、
受動部品(各値のLCSC番号割当が必要)、音声系"要選定"部品(PCM1808/XO/TOSLINK/
3.5mmジャック/24AA025E48)。

## 発注前コネクタQA(2026-07-30、要対応)

atopile取り込み部品のフットプリント実パッドと、main.atoの(元・仮割り当て)ピン番号の
照合結果。`ato build` の「Could not match lead to pad」警告＝不一致のサイン。

| コネクタ | 実パッド | 状態 |
|---|---|---|
| D-SUB15 (DS1037) | 数値 1-17 | ✓ 整合(X68000配置はD-subピン番号通り)。実部品で最終目視のみ |
| DCジャック (DC005) | 1-3 | ✓ 整合(center/sleeve/switch)。極性のみ要確認 |
| PCM1808 / EEPROM / TVP等IC | 数値=データシート順 | ✓ 整合 |
| **USB-C (TYPE-C-31-M-12)** | A1B12/B1A12=GND, A4B9/B4A9=VBUS, A5=CC1, B5=CC2, A6/A7/B6/B7=D±, A8/B8=SBU, 1-4=シェル | ✓ **修正済**(標準USB-C配置で実パッド名へ再マッピング) |
| **MagJack (HR911130A)** | P1-P10(磁気部), 11-14(LED), SHIELD0/1 | ✓ **修正済**。公式データシート(`datasheets/HR911130A_HanRun_MagJack.pdf`)回路図どおり: P2/P3=MDI0±, P4/P7=MDI1±, P5/P6=MDI2±, P8/P9=MDI3±, P1=CT共通(0.1µF→GND), P10=Bob-Smith/シャーシ基準, 11-14=LED, SHIELD0/1=シェル。内蔵Bob-Smith前提でCTは1共通 |
| **3.5mmジャック (PJ-327C-4A)** | 1-4 (実4ピン) | ✓ **修正済**。データシート(`datasheets/PJ-327C-4A_HOOYA_3.5mmJack.pdf`)回路図どおり: 1=Sleeve(GND), 2=Tip(L), 3=検出スイッチ(未使用), 4=Ring(R) |

→ **`ato build` は全ターゲット成功**(netlist/PCB/BOM/pinout/power-tree/stackup)。
**全コネクタのピン配置を実データシートで確定済み**(発注前コネクタQA完了)。

## v0.9.0 発注済み (2026-08-19)

**生基板のみ**を発注した。部品は手半田で実装する(v1.0 で PCBA を予定)。

```
基板      100.000 x 100.000mm / 4層 (F.Cu / In1="GND" / In2="PWR" / B.Cu) / 1.6mm / ENIG
部品      190個
DRC       error 0件 / warning 192件 / 未配線 0件
製造データ layouts/default/production/RetroCast_X_v0.9.0.zip
git tag   v0.9.0-pcb
```

### ★デジグネータを凍結した

`tools/lock_designators.py --freeze v0.9.0` を実行し、190部品を
`tools/designator_lock.json` に記録した(接頭辞13種、最大値 C85/D9/FB3/FID3/H5/
J12/JP1/LED1/PG4/R46/TP2/U16/X3)。

以後の運用:

```sh
ato build                                  # 回路を変えたら
python3 tools/lock_designators.py          # ★番号を戻す(欠番は再利用しない)
python3 tools/restore_tuning_patterns.py   # ★等長配線を守る
python3 tools/restore_pcb_settings.py      # ★原点とリビジョンを戻す
```

**発注済みなので `tools/renumber_designators.py` は絶対に実行しないこと。**
番号が動くと発注済み基板の資料・写真・オシロのメモと食い違う。

### 残っている既知の警告

```
lib_footprint_issues  190件  ライブラリとの差異(意図的な編集によるもの)
connection_width        1件  ゾーン隅の丸め由来。角がある限り出る(pcbnewで個別除外)
```

## 残作業(発注前に必須)

★この節は**初期設計時**のもので、v0.9.0 の発注をもって大半は解消済み
(フットプリント紐付け・ピン照合・レイアウトはすべて完了、AZ1117H-ADJ は
RT9013-18 → TLV75718P へ置き換え済み)。履歴として残す。

1. **フットプリント紐付け**: VS Code の atopile 拡張で各ICを `ato create part`
   (上記LCSC ID)で取り込み、`main.ato` のスタブcomponentを置き換える
2. **ピン配置の照合**: VGA-002・DC005・PZ254V のピン番号は代表的な配列を仮定している。
   取り込んだフットプリントの実ピン番号と必ず照合すること
3. **レイアウト注意**:
   - DATACLK は i5 側で**クロック対応ピン(PCLK/GPLL入力)**に接続(上記対応表参照)
   - AZ1117H-ADJ は約0.9W発熱: SOT-223のタブに銅箔ベタ+サーマルビア
   - TVP7002 の露出パッドはGNDベタにはんだ付け(熱・電気両方の要件)
   - アナロググラウンドは入力コネクタ周りでベタを分離しすぎない(1点で結合)
4. **色深度**: 配線は各色上位8bit(R/G/B[9:2])。J4の空き6ピンは音声系で
   使い切ったため、10bit化する場合はP6ミラーヘッダの追加が必要
5. **音声まわり**: PCM1808のVCC(5Vアナログ)はFB経由で分離済み。レイアウトでは
   ADC・XOをGbE/映像系から離し、D-SUB音声の引き回しは映像RGBと並走させない。
   PCM1808/TOSLINK/3.5mmジャック/12.288MHz XOのスタブはピン番号仮割り当てなので
   フットプリント取り込み時にデータシート照合(main.ato内の注意書き参照)

## Colorlight i5 EXTボードとの接続(2026-07-25 調査確定)

- **EXTボードにRJ45は無い**。i5モジュール上のGbE PHY×2の差動ペア(MDI)はヘッダ**P1**
  (2×15)に出ているだけ。→ **本基板にMagJack(J8+J9)を搭載済み**。回路は
  [kazkojima氏 i5ether](https://github.com/kazkojima/colorlight-i5-tips)準拠
  (1000BASE-T netboot/nfsroot動作実績あり):MDIはDC結合のまま、PHY側CTは各0.1µF→GND
  (B50612Dは内部バイアスで無給電可)、Bob-SmithはMagJack内蔵、GND-シャーシ間4.7nF/2kV×2。
  **ETH2側ペア=LiteXのphy0** を使用(PHY番号とコネクタ名の対応は逆転に注意)
- EXTボードのGPIOヘッダは P2–P6(各2×15メス、GPIOは1ヘッダあたり18〜20本)。USB-C は
  DAPLink(JTAG書き込み+UARTコンソール)+VBUS。HDMIは出力のみ。SDスロット無し
- **EXTのUSB-C電源には要注意(回路図 schematic/i5-i9-extboard.pdf で確認)**: PDコントローラなし・
  **CC端子未接続(Rd 5.1kΩなし)**のため、規格準拠のC-Cケーブルでは受電不可(A→Cケーブル専用)。
  VBUS→ヒューズF1(定格不明)→スライドスイッチS1→5Vレール直結。
  → 本基板をJ10から給電しS1をOFFにする「逆給電」運用でこの問題を回避する
- **ECP5のクロック対応(PCLK)ボールが出ているヘッダ**(prjtrellis DB照合結果):
  - P2: J20(PCLKT2_0), K20(PCLKC2_0), L20(PCLKT3_1), L18(GR_PCLK3_1)
  - P3: E2(PCLKC7_0)
  - **P4: F2(PCLKT7_0), F1(PCLKC6_1), F3(PCLKC7_1), G3(PCLKT7_1), H4(GR_PCLK7_1)** ← 最多
  - P6: J18(GR_PCLK2_0)
- **HAT形式(スタック)を正式採用**: 本基板は裏面の2×15ピン(J2/J4/J8)でEXTボードの
  P2/P4/P1メスヘッダに直接嵌合する。ピン配置は1対1ミラーのため、寸法不一致時は
  2×15リボンケーブルでフォールバック可。**製作前にEXTボード実寸(ヘッダ間距離・
  i5モジュールの高さ・ソケット嵌合高さ≈11mm)の採寸が必須**
- 信号は P2/P4 の2ヘッダに集約(EXT側1ヘッダのGPIOは18〜20本でRGB24bitは1本に収まらない):
  - **J2 = P2ミラー**: R9-R2→J20,G20,L18,K20,M18,L20,N17,N18 / G9-G2→U17,P18,T17,U18,P17,M17,R18,R17 / B9-B6→C18,T18,U16,K18
  - **J4 = P4ミラー**: DATACLK→**F2(PCLKT7_0)**、B5-B2→E1,E4,H3,H5、HSOUT→J5、VSOUT→A2、
    SOGOUT→K4、FIDOUT→B2、SDA→K3、SCL→K5、RESETB→B3、
    音声: MCLK→**F1(PCLKC6_1)**、BCK→G3、LRCK→H4、DOUT(DSUB音声)→F3、
    DOUT(LINE)→J4、S/PDIF→E19(空きなし)

## RGB入力のアンチエイリアスフィルタ(必須)

TVP7002のアナログ入力に **220Ω直列 + 33pF並列** のローパスを入れている。
これは省略できない。試作機で後付けして効果を実測した。

### なぜ必要か

TVP7002のアナログ帯域は **350〜500MHz**(データシート実測値)ある一方、こちらの
サンプリングは **8〜44MHz** しかない。ナイキスト周波数(4〜22MHz)より上の雑音は
すべて折り返して絵に畳み込まれる。TVP内蔵の帯域制御(レジスタ 3Fh)は

    0h = Highest video bandwidth (default)
    Fh = Lowest video bandwidth (~95 MHz)

で最小でも50MHz以上あり、この用途には使えない。**外付けが必須**。

### 実測(X68000 31kHz 256x256、pll_divide=1104 / 34.775MHz)

試作機に 220Ω + 15pF(TVPの入力容量10pFと合わせて実効25pF、遮断28.9MHz)を
後付けした前後:

| | フィルタ前 | フィルタ後 |
|---|---|---|
| ノイズ(暗部の時間ゆらぎ) | 40〜60% | **3.9%** |
| 暗部の底(明線直後の残留) | 9.2 | **0.01** |
| エッジ後のリンギング | 19サンプル周期で6山(+3〜15) | **消滅** |

「暗いはずの所が暗くない」「エッジの右に減衰しながら繰り返す像が出る」という
2つの症状は、どちらも折り返しが原因だった。エッジそのものの立ち上がりは
2サンプル(58ns)で完了しており、フィルタによる鮮鋭度の低下は見られない。

なおリンギングは、サンプルクロックを変えても**サンプル数で一定(約19)**だった。
アナログの共振なら時間で一定になるはずで、この違いが折り返しだと見抜く決め手に
なった。ケーブル長(2m=往復20ns)では546nsの周期は説明できない点も一致する。

### 定数の選び方

TVPの入力容量10pF(データシート CI)が並列に入る。

| C(外付け) | 実効 | 遮断周波数 | 備考 |
|---|---|---|---|
| 15pF | 25pF | 28.9MHz | 試作で実測した値 |
| **33pF** | **43pF** | **16.8MHz** | 採用値 |
| 47pF | 57pF | 12.7MHz | さらに折り返しを削るが最細部が鈍る |

採用値の16.8MHzは、最も高いモード(31kHz 768ドット、ドットクロック34.78MHz)の
ナイキスト17.4MHzにほぼ一致する。隣接ドットが交互に変わる最細パターンは3dB
落ちるが、それはそもそも折り返す成分なので抑えるのが正しい。鮮鋭さを優先するなら
15〜22pFに下げる。

**c_aa は TVP の入力ピン直近に置くこと。** r_aa は結合コンデンサの直後で構わない。
R/G/B の3チャンネルとも同じ値にする(片方だけ違うと色ずれになる)。

### 補足: ビーズは使わないこと

映像信号にフェライトビーズを入れると、低周波ではインダクタとして振る舞うため
コンデンサとLC共振を作り、まさにここで消したリンギングを自分で作り込むことに
なる。ビーズは電源ライン専用。

### 未使用アナログ入力(基板設計では対応済み)

データシートは未使用のアナログ入力を10nFで、未使用SOG入力を1nFでGNDへ落とすよう
指定している。**main.ato では対応済み**(nc_caps × 7、nc_sog_caps × 2)。手半田の
試作機に無いだけなので、基板を起こせば解消する。

## TVP7002のレジスタ設定(実測で決めたもの)

初期化で書いている値のうち、**実測で効果を確認して決めた**ものを記録する。
どれも既定値のままでは症状が出る。

### 3Fh = 0Fh (アナログ映像帯域を最小に)

外付けRC(28.9MHz)を入れてもエッジの直後に残っていた**1つ目のエコー**が消える。

| 3Fh | 残留エコー(明線直後の超過) |
|---|---|
| 00h(最大帯域・既定) | +2.55 |
| 08h | +1.82 |
| 0Ch | +1.01 |
| **0Fh(最小≈95MHz)** | **+0.01** |

単調に減り、戻すと再現する。外付けが28.9MHzで切っているので効かないと予想したが
実際には完全に消えた。残留エコーの成分が95MHz以上にあり、単極RCでは95MHzを10dB
しか落とせなかったためと考えられる。

代償はエッジの立ち上がり(2サンプル=58ns)が変わらないまま、最細部の振幅が6%
落ちるだけ。

### 2Ah = 87h (ファインクランプのCMオフセットを有効に)

白ベタ領域の**先頭20サンプル(約576ns)だけ2〜3%暗くなる**症状が、GとBにだけ
出ていた(Rには出ない)。データシートで 2Ah は `Fine GB`(G/B共通)と `Fine R`
が別ビットになっており、症状の出方と一致した。

| 2Ah | R | G | B |
|---|---|---|---|
| 07h(既定) | +0.2 | +2.6 | +2.0 |
| 0Fh/17h/1Fh(時定数を短く) | +0.2 | +2.6 | +2.0 |
| **87h(CM Offset 有効)** | +0.1 | **+2.2** | **+0.3** |

**時定数(bit[4:3])は全く効かなかった**。効いたのは CM Offset(bit7)で、
データシートの "can be enabled to improve isolation and channel crosstalk" の
とおり、原因はクランプの応答ではなく**チャンネル間のクロストーク**だった。
白レベルは 102.7% → 102.8% で副作用は見られない。

### 残件: Green の +2.2%

Blue はほぼ解消したが Green に +2.2% が残っている。

測定した試作機は手半田で、**Green だけ信号線が長い**。切り分けの結果、これが
残差の原因と考えられる。

| 検証 | 結果 |
|---|---|
| X68000側で G と B を入れ替え | **症状は G のまま移らない** → 信号源は無罪 |
| 3chの立ち上がり時間 | 1.50サンプルで完全一致 → 部品値・半田付けに差なし |
| Green の AGND を最短化 | 変化なし |
| SOGIN_3(未配線)に0.01µF追加 | 変化なし |
| クランプ時定数 (2Ah bit[4:3]) | 変化なし |

信号を入れ替えても症状が基板の Green 経路に留まることから、**基板側で拾っている**
と判断できる。部品も設定も対称なので、残る非対称は配線長だけ。

CM Offset の効き方もこれで説明できる。あれは TVP 内部の分離を改善するものなので、
チップ内で完結する分(Blue)は解消したが、**基板上で拾っている分(Green)には
効かなかった**。

**基板を起こして3本を短く等長にすれば消える見込み**なので、この数字を基板設計の
判断材料にしないこと。基板版でも残る場合は、SOGスライサの停止(2Bh bit6)を試す
価値がある(未検証)。ただし将来 SOG 入力に対応する際に必要な経路なので、無効化
するなら実行時に切り替えられる形にすること。

### 08h/09h/0Ah = 35/33/39 (細ゲイン。白をフルスケール付近へ)

既定の 00h(ゲイン1.0)だと **白が 210/255 (82%) までしか届かず**、階調とSNRを2割
損していた。粗ゲインは既定で既に1.2倍あり、データシートも "For a normal PC graphics
input, the fine gain is used mostly" としているので、細ゲインで補う。
チャンネル別なのでホワイトバランスも同時に合う(Rが2%低かった分を補正)。

実測して決めた(白の90%点と、生1フレームでの255画素数):

| NFG (B,G,R) | 白の90%点 | 飽和画素 |
|---|---|---|
| (54, 51, 58) | 251.5 | 5626 |
| (45, 42, 49) | 244.5 | 608 |
| **(35, 33, 39)** | **237** | **0** |
| (26, 23, 30) | 229 | 0 |

飽和は不可逆で、ノイズの山か信号の山かを区別できない。3%明るくするために階調を失う
のは割に合わないので、飽和ゼロの点を選んだ。黒は全チャンネル 0 のままでクランプは
正常。CONFIG key 0x1C/0x1D/0x1E で実行時にも変更できる。

**症状としては「白い文字が薄いグレーに見える」という形で出る。** 明るいゲーム画面
では気付きにくく、白文字の多い画面で目立つ。補間や帯域の問題と紛らわしいので注意。

### 効かなかった/悪化した設定(再調査を避けるための記録)

**03h(VCOレンジ+チャージポンプ)** — TVP既定 A8h は VCO Medium(70〜135MHz用)で、
こちらのピクセルクロック(8.7〜44MHz)とは規定範囲が合っていない。データシートどおり
Ultra low + ICP=3 の 18h にして実測したが、**効果が無かった**。

**05h/06h(クランプ開始/幅)** — データシート Table 13 の PC graphics 推奨は 06h/10h
だが、**ノイズが3割悪化する**。落ち込みは僅かに改善する(G +1.5 → +1.1)が割に合わない。
推奨値はクランプ窓が狭く黒レベルの平均化が減るため。X68000のバックポーチは一般的な
PCより長いので、既定の広い窓(開始50・幅32)の方が有利だった。
**データシートの推奨がそのまま最適とは限らない例。**

31kHz 256x256(pll 1104)での実測。同じ並びを電源条件を変えて2回測り、いずれも同じ
関係になった。

| 条件 | ノイズ | R | G | B |
|---|---|---|---|---|
| 既定 A8h/32h/20h | **3.33%** | +0.7 | +1.5 | +0.9 |
| 03h=18h のみ | 3.28% | +0.7 | +1.4 | +0.9 |
| 05h/06h=06h/10h のみ | **4.41%** | +0.6 | +1.1 | +0.7 |
| 両方 | 4.65% | +0.7 | +1.1 | +0.7 |
| 既定に戻す(再現確認) | 3.24% | +0.7 | +1.5 | +0.9 |

**測定時の注意**: ノイズの絶対値は電源で大きく動く(下記)ので、条件間は必ず連続して
測り、最後に基準へ戻して再現を確認すること。また設定が本当に届いたかを毎回確認する
こと(CONFIG応答を見る)。**古いファームでキーが未対応だと設定が黙って無視され、
「効果なし」に見える**。実際それで一度誤った結論を出しかけた。

### ノイズは電源に強く依存する ← PCB設計で最重要

同じ設定・同じモードで、USBの接続経路を変えただけでノイズが3倍動いた。

```
1.1%  〜  3.3%  〜  3.9%     (接続経路の違いだけ)
```

試作時はUSBハブが4〜5段に連なっており、段数や挿す位置で電源の質が変わっていた。
レジスタ設定をいくら詰めても、この振れ幅の方がはるかに大きい。**基板では電源の質を
最優先すること**(アナログ電源の分離、デカップリング、USBから引く場合の経路)。
評価するときは電源条件を固定し、変えたら基準値を取り直すこと。

### 実行時に変更できる

切り分けのため CONFIG で変えられるようにしてある(ビルドし直さずにA/Bできる)。

| key | 対象 |
|---|---|
| 0x17 | 3Fh 映像帯域 (0〜15) |
| 0x18 | 2Ah ファインクランプ (8bit) |
| 0x19 | 03h PLL(VCOレンジ+チャージポンプ) |
| 0x1A | 05h クランプ開始位置 |
| 0x1B | 06h クランプ幅 |

## ★`ato build` の後に必ず実行すること

`ato build` は **atopile がモデル化していない要素を書き出し時に落とす**。
落ちるものが2種類あり、どちらも黙って消えるので毎回機械的に戻すこと。

```sh
python3 tools/restore_tuning_patterns.py   # GbEの等長配線が基板外へ飛ぶのを防ぐ
python3 tools/restore_pcb_settings.py      # 基板の原点とリビジョン番号を戻す
python3 tools/lock_designators.py          # 番号を戻す(欠番は再利用しない。発注後は必須)
python3 tools/gen_parts_table.py           # README の主要部品表を実装に追随させる
python3 tools/gen_designator_map.py        # docs/designator-map.md を実装に追随させる
python3 tools/gen_order_bom.py --tag v0.9.0 --boards 2   # 発注リスト
python3 tools/gen_order_xlsx.py --tag v0.9.0 --boards 2  # 調達管理表
```

`--check` を付けると書き換えずに食い違いだけ報告する
(`gen_parts_table.py` と `gen_designator_map.py`)。

★**対応表を放置すると実害が出る。** `designator-map.md` は手書きのままだったため
195行中129行の番号が実装とずれ、音が出ない件の切り分けで測る場所を間違えた
(2026-09-03)。生成ツールは「一度回して終わり」にせず、`ato build` のたびに回すこと。

### 1. 等長配線オブジェクト

`(generated ... (type tuning_pattern))` の中身が捨てられ、KiCad が開いたときに
パターンを作り直して **member の配線を基板外へ移動させる**。実際に2回発火し、
GbEの等長配線67本が x=277.5 まで飛んだ。詳細は `tools/restore_tuning_patterns.py`。

### 2. 基板の原点とリビジョン番号 (2026-08-19 に特定)

```
(title_block (rev "v0.9.0"))    リビジョン番号
(setup (grid_origin 87.5 149))  基板の原点(グリッド原点)
```

`title` は残るのに `rev` だけ消える。atopile の非テストコードには PCB の
title_block も grid_origin/aux_axis_origin も一切現れない(title_block は回路図側の
変換にしか出てこない)。

**実証**: 両方が入った状態で `ato build` を実行したら両方消えた。再現性あり。

**git履歴**: 消失は必ず `ato build` を伴うコミット、復活は pcbnew 作業のコミット。

```
47868cf  grid 復活   基板固定用M2.6ネジ穴を追加(pcbnew作業)
ab25097  grid 消失   配線途中のスナップショット
f916edc  grid 復活   配線途中のスナップショット
7156ba7  grid 消失   J9の3Dモデルオフセットを反映(ato build)
34391de  grid 復活   配線途中のスナップショット
715e368  grid 消失   デジグネータを宣言順に振り直す(ato build)
fa3fe14  grid+rev 復活  v0.9.0の製造データを出した時点を記録(pcbnew作業)
ac85734  grid+rev 消失  FT2232HL を CH347F に置き換える(ato build)
```

利用者は4回設定し直しており、そのたびに次の build で失われていた。
**grid_origin はガーバー/ドリルの出力原点**なので、消えたまま製造データを出すと
座標系が変わり、実装機データや過去の版と突き合わせられなくなる。

値は `tools/pcb_settings.json` に置いて git で追跡する。pcbnew で変えたら
`python3 tools/restore_pcb_settings.py --capture` で取り込み直すこと。

### 落ちないが書式が変わるもの(実害なし)

`ato build` は他にも書式を正規化する: パッドの `(layers)` の並び順、数値の桁、
`(locked no)` 等の既定値の明示、カスタムパッドの `(fill yes)`/`(anchor circle)` の削除。
J2(USB-C)のカスタムパッド4個で確認したところ、**実効形状のバウンディングボックスは
1.300x0.600mm で前後完全一致**しており、KiCad が既定値で同じ形に解決する。実害はない。

## 手半田実装用の発注リスト(DigiKey / Mouser)

`ato build` が出す `build/builds/default/default.bom.csv` は **JLCPCB 発注用**で、
LCSC 品番が主役になっている。この基板は中国国内ブランド(UNI-ROYAL の抵抗、FH の
コンデンサ、HANRUN の RJ45、YXC の水晶など)を多用しているので、そのまま DigiKey や
Mouser の BOM ツールに投げても**半分近くが「該当なし」で落ちる**。

`tools/gen_order_bom.py` が `tools/order_sourcing.json` の読み替え表を当てて、
アップロードできる形に整える。

```sh
python3 tools/gen_order_bom.py --tag v0.9.0            # 1枚分
python3 tools/gen_order_bom.py --tag v0.9.0 --boards 5 # 5枚分
```

| 出力 | 用途 |
|---|---|
| `orders/<tag>/digikey-bom.csv` | DigiKey myLists → BOM Manager にアップロード |
| `orders/<tag>/mouser-bom.csv` | Mouser BOM ツールにアップロード |
| `orders/<tag>/lcsc-bom.csv` | LCSC でしか買えない分 |
| `orders/<tag>/README.md` | 人が読む用(注意点・読み替え理由つき) |

アップロード用 CSV には**実在する製造元品番だけ**を載せている。汎用ピンヘッダや
ネジを説明文のまま混ぜると照合結果が「該当なし」だらけになって読めなくなるので、
それらは README の「どこでも買える汎用品」に分けてある。

★読み替え表に無い LCSC 品番があるとエラーで止まる。回路を変えたら
`tools/order_sourcing.json` も更新すること(黙って落とさないための仕掛け)。

### 調達管理用の Excel

どの部品をどこで買ったか間違えないように、チェックリストを生成する。

```sh
python3 tools/gen_order_xlsx.py --tag v0.9.0 --boards 2
```

`orders/<tag>/purchase-tracker.xlsx` が出る。3シート構成:

| シート | 内容 |
|---|---|
| 調達管理 | 部品を縦に並べ、状態をドロップダウンで選ぶ。行の色が自動で変わる |
| 発注先まとめ | 仕入先ごとの品目数・総個数・確認済み金額・アップロード用ファイル |
| 注意事項 | 発注前に確認すべきこと(`order_sourcing.json` の note を転記) |

状態は `未発注`(赤) / `発注済み`(黄) / `到着済み`(緑) / `手持ち在庫あり`(緑) /
`不要`(灰) から選ぶ。下部に「◯◯ / 46 品目」の進捗カウントが出る。

★**再生成しても「状態」「注文番号/日付」「備考」は引き継がれる。**
デジグネータ列をキーに既存ファイルから読み戻すので、部品構成を変えても
入力済みのチェックが消えない。

★単価が `未確認` の品目は小計に入っていない(`tools/prices.json` に無いもの)。
合計は常に下限。DigiKey 分は BOM ツールの結果を prices.json に足せば埋まる。

発注先は**どの発注CSVに載っているか**で決めている。`order_sourcing.json` の
status から引こうとすると、`status=ok` の品目は `alt_mpn` を持たないため MPN で
照合できず全部が「秋月電子等」に落ちる(2026-08-19に踏んだ)。
「digikey-bom.csv に載っている = DigiKey で買う」が定義そのものなのでそれに従う。

### 入手性で注意が要る部品

| 部品 | 事情 |
|---|---|
| U1 TVP7002PZP | TI が生産終了方向。**Mouser は取扱なし**、DigiKey のみ(2026-08 時点 184個 $12.04)。手半田で失敗する可能性を考えると予備を1個持っておきたい |
| U7 CH347F | WCH は DK/Mouser 扱い無し。LCSC / AliExpress / 秋月 |
| J1/J2/J6/J11/J12 | コネクタはフットプリントが製品固有。**代替不可**なので LCSC で買う |
| LED1 WS2812B-2020 | 2020 サイズは DK/Mouser では稀。5050 は入るが footprint が合わない |

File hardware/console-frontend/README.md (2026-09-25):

# RetroCastX 小亀基板(コンソール入力基板) v1.0

家庭用ゲーム機向けの入力端子を引き受けて、**0.5mmピッチ20芯FFC(10cm)**で
メイン基板(`hardware/adc-frontend`)へ渡すサブ基板。外形はメイン基板と同じ
**10cm × 10cm**、取付穴は M3 ×5(メイン基板の H1-H5 と同じ位置にしてスペーサで重ねられる)。

```
  S端子(ミニDIN4) ─┬─ESD─ 75Ω ─ 100n ─┬(bias 1.65V)─┐
                   │                                  ├ SPDT ch1 ─ FFC 1 ─→ GIN_1 / SOGIN_1
  コンポジット(黄) ─┴─ESD─ 75Ω ─ 100n ─┘              │   (ESD: D2=CVBS/音声L/R
                                                       (選択 = FFC 13 = FPGA GPIO)
  S端子C ───────────ESD─ 75Ω ─ 100n ──┬──────────────┤    D3=S端子Y/C・Pr/Pb)
  コンポーネントPr(赤)─ESD─ 75Ω ─100n ─┘              └ SPDT ch2 ─ FFC 3 ─→ RIN_1

  コンポーネントPb(青)─ESD────────────────────────────── FFC 5 ─→ BIN_1(終端はメイン基板側)
  音声L(灰/黒) ─ESD─ 10k ─────────────────────────────  FFC 7 ─→ PCM1808 #3
  音声R(赤)   ─ESD─ 10k ─────────────────────────────  FFC 9 ─→ PCM1808 #3
  シリアルLED ×2 ←── FFC 11(データ)/ 16(+5V, ダイオードで4.2V)
```

Y/C分離も復調もこの基板ではやらない。メイン基板の TVP7002 で 8fsc サンプリング
して、Viewer(PC側)でデコードする(`docs/composite-video-plan.md`)。

## FFC ピン配置(メイン基板と共通)

メイン基板(J15)側の番号で書く。**小亀基板(J1)は逆順(n ↔ 17-n)**。

| pin | 信号 | pin | 信号 |
|---|---|---|---|
| 1 | 音声L | 11 | LED_DATA |
| 2 | GND | 12 | GND |
| 3 | 音声R | 13 | GPIO2(予備) |
| 4 | GND | 14 | GND |
| 5 | Pb(スイッチを通らない) | 15 | GPIO1(スイッチ選択) |
| 6 | GND | 16 | GND |
| 7 | C / Pr(スイッチ出口) | 17 | +3.3V |
| 8 | GND | 18 | +3.3V |
| 9 | Y / CVBS(スイッチ出口) | 19 | +5V |
| 10 | GND | 20 | +5V |

**信号は全部が両隣にGNDを持ち、電源は2本ずつ**(2026-09-22 に16芯から20芯へ)。
16芯のときは制御3本(LED_DATA/GPIO2/GPIO1)が並んでいて、800kHzのLEDデータが
隣のGPIOと並走していた。電源を2本にしたのは往復抵抗を半分にするため。

★**ケーブルの向き(type A / type D)は発注前に確認すること。** FFCは両端の接点が
同じ面か反対面かで「n番 ↔ n番」と「n番 ↔ 17-n番」が入れ替わる。**このネットリストは
ストレート(n ↔ n)前提**。2枚の基板の向きを決めたら紙に描いて種別を選び、
**通電前にテスターで pin1↔pin1 を当たること**。1ピンずれると +5V が GPIO に当たる。

## 入力の切り替え(TS5A23159 / 1本の選択線)

真理値表(データシート SCDS201H Table 2: IN=L → NC-COM が ON)。

| GPIO1 | FFC 1 (→GIN_1/SOGIN_1) | FFC 3 (→RIN_1) | FFC 5 (→BIN_1) | 使える入力 |
|---|---|---|---|---|
| **L(既定・10kプルダウン)** | CVBS(黄) | Pr(赤) | Pb(青) | コンポジット / **YPbPrコンポーネント** |
| H | S端子 Y | S端子 C | (Pb) | S端子 |

- **既定をコンポジットにした理由**: ゲートウェアがこのGPIOを駆動しない状態でも
  「黄色いケーブルを挿しただけで映る」ようにするため。S端子とコンポーネントは
  Viewer で明示的に選ぶ操作を伴うので、そのときに H へ駆動される。
- **同期(SOGIN_1)はスイッチの出口から分岐している**ので、映像と同期が必ず
  一緒に切り替わる。人が触る物理スイッチだと「設定はコンポジットなのにスイッチは
  S端子側」という食い違いを作れてしまう(`docs/TODO.md` 10-5)。
- break-before-make なので、切り替えの瞬間に2つのソースが繋がることはない。

## 75Ω終端と中点バイアス(この基板の設計の要点)

**終端はこの基板のジャック側に置く**。メイン基板の `VideoInputChannel` が持つ
75Ω(`r_term`)は、**この基板で終端するチャンネル(Y/C)では実装しない**。
両方に入れると合計37.5Ωになり振幅が半分になる。

終端の直後に 100nF で直流を切り、10kΩ で 1.65V(VCC/2)へ持ち上げてから
スイッチに入れている。理由は**スイッチの信号範囲が GND〜VCC** だから:

```
出力にコンデンサが入っている機種(AC結合)を 75Ω でGNDへ終端すると、
波形の平均が0Vになるので同期先端が負に潜る
    暗い絵(平均0.35V)  同期先端 ≈ -0.35V
    白い絵(平均0.85V)  同期先端 ≈ -0.85V   ← 絶対最大 -0.5V を超える
潜る量が絵の明るさで動くので、スイッチの保護ダイオードが同期先端だけを食う。
同期先端は SOG スライサが見ている場所なので、明るい絵のときだけ同期が乱れる。
```

v0.9.0(2x4ヘッダ)は同じ 75Ω→100nF の並びだったが、終端ノードに能動素子が
無かったので問題にならなかった。スイッチを入れる v1.0 では効いてくる。

Pb だけはスイッチを通らないので直流結合のまま渡し、終端もメイン基板側
(`ch_b1` の 75Ω)に任せている。

## 部品(LCSC)

| 部品 | 型番 | LCSC | 備考 |
|---|---|---|---|
| ミニDIN4(S端子) | **マル信 MJ-373/4B** | — (手実装) | 千石/マルツ/モモハラ。3=Y / 4=C / 1,2=GND / スロット3本=シェル |
| RCA ×5 | **RCA-105**(色違い) | — (手実装) | AliExpress等。黄/白/赤/黒/青が同寸法で揃う。**2端子・両方とも軸線上** |
| FFCコネクタ | HDGC 0.5K-1.5-**20**PWB | C2919559 | 下接点・フリップロック・右アングル |
| アナログスイッチ | TI TS5A23159DGSR | C42751 | 2ch SPDT, Ron 1Ω, break-before-make |
| ESD ×2 | ROHM EMZT6.8ET2R | C510333 | メイン基板と同じ(5パッド版フットプリント) |
| シリアルLED ×2 | XINGLIGHT XL-2020RGBC | C5349955 | MSL3(JLCの焼成不要) |

ミニDIN4はLCSCに無いので**フットプリントをメーカー図面から自作**した
(`parts/_mech/MJ373_4B.kicad_mod`。φ1.2×4 + スロット2.8×0.8×3、原点=嵌合面)。
メイン基板のミニDIN8(マル信 MJ-373/8B)と同じハウジング/ランド枠。

RCAは**フットプリントをメーカー図面から自作**した(`parts/_mech/RCA105.kicad_mod`)。
ランドは **2端子だけで、両方ともコネクタの軸線上**:

    pad1  スロット 2.30 × 1.50  @ 嵌合面から 4.80  → シェル(GND)
    pad2  スロット 1.00 × 2.30  @ 嵌合面から 8.30  → 中心導体(信号)

★**極性は現物で導通確認すること。** 2端子しかないので取り違えると映像をGNDへ短絡する
(「筒の外側 ↔ pad1」「中心の穴 ↔ pad2」を当てれば10秒)。
★**同じ RCA-105 でも出品元で寸法が違うことがある**ので、4.80/8.30 とスロット寸法を実測してから発注する。
★外形と並べ方(枠10.0mm・筒がφ8.3で9.3mm張り出す・ピッチは12.5mm)は
`docs/layout-guidelines.md` の1章にまとめた。

レイアウトの指示は `docs/layout-guidelines.md`(外形・コネクタ形状・配置・配線ルール)。

## ビルド

```
ato build                               # ネットリスト/PCB/BOM を生成
```

部品の取り込み(atopileの部品APIが落ちているときのオフライン手順)は
メイン基板と同じ `tools/ingest_parts.py`:

```
~/.local/share/uv/tools/atopile/bin/python tools/ingest_parts.py C2939342 ...
```

★**ESDアレイ(EMZT6.8ET2R)を取り込み直したら `tools/fix_esd_land.py` を必ず走らせる**
(取り込み時のフットプリントはリードの無い裸パッドを含む6パッド版で、パッド幅も
0.28mmしかない)。いまリポジトリに入っているのはメイン基板で修正した5パッド版。

## 発注前チェックリスト

1. **FFCの向き**: type A(同面接点)+ 対向配置の前提で小亀側を逆順(n↔17-n)にしてある。
   紙に描いて確認し、通電前に pin1↔pin1 を導通確認
2. **ミニDIN4のピン**: 現物で「3番がプラグの輝度ピン」を導通確認(図面の
   PCB穴図のパッド番号=ミニDIN4の標準ピン番号として扱っている)
3. **RCA-105 の極性とランド**: pad1=GND / pad2=信号 を導通確認し、4.80/8.30 を実測
4. **メイン基板側の 75Ω**: `ch_y` / `ch_c` の `r_term` を実装しない指定になっているか
   (v1.0 の main.ato では `VideoInputChannelNoTerm` を使う。未対応なら手で外す)
5. 取付穴の位置をメイン基板と合わせる(M3 ×4)

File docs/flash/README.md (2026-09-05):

# ブラウザからのゲートウェア書き込み (WebUSB)

RetroCastX v0.9.0 基板の FPGA (Colorlight i5 / ECP5 LFE5U-25F) の SPI フラッシュを、
Chrome / Edge から書き換えるためのページ。

公開 URL: <https://kunichiko.github.io/RetroCastX/flash/>

```
ブラウザ ──WebUSB──▶ CH347F (IF4, vendor class 0xff)
                       └─JTAG─▶ ポゴピン ─▶ Colorlight i5 の TCK/TMS/TDI/TDO
                                              └─ ECP5 background SPI ─▶ SPIフラッシュ
```

## なぜ WebUSB で書けるのか

CH347F は複合デバイスで、UART0/UART1 は CDC-ACM (OS のシリアルドライバが掴む) だが、
**JTAG は interface 4 の vendor class 0xff** に分かれている。ここにはどの OS の
カーネルドライバも割り当たらないので、ブラウザが `claimInterface(4)` できる。
UART を使いながら同時に JTAG を叩けるのはこのため。

MimicX の CH32 書き込みと違い、**BOOT ボタンや時間制限のあるモード遷移は不要**。
USB を挿せばいつでも書ける。

## 動作環境

- **ブラウザ**: Chrome, Edge (WebUSB 対応が必要。Safari / Firefox は非対応)
- **OS**: macOS / Linux / ChromeOS / Android は追加作業なし
- **Windows のみ準備が必要**: CH347F は BOS ディスクリプタも MS OS ディスクリプタも
  持たないため、Windows が interface 4 に WinUSB を自動割り当てしない。Zadig を
  「Options → List All Devices」で開き、`UART+SPI+I2C+JTAG (Interface 4)` を選んで
  WinUSB をインストールする。WCH 純正の CH347 ドライバが入っていると競合する。
  **★interface 4 であることを必ず確認すること。** 0〜3 は UART(CDC-ACM)なので、
  そちらに当てるとシリアルが使えなくなる

Windows / Chrome + Zadig での書き込みは 2026-09-06 に実機で確認済み
(macOS / Chrome は 2026-09-04)。

## 配布ビットストリームの追加

通常は **`gw-vX.Y.Z` タグを push すれば CI が自動でやる**
(`.github/workflows/gateware-release.yml`)。ビルド → タイミング検査 →
Release 作成 → `bitstreams/` への配置と `manifest.json` の更新まで行う。
手順は `gateware/README.md` の「リリース」を参照。

★**実体をここに置くのは GitHub Release のアセットが
`access-control-allow-origin` を返さないため**(2026-09-04 実測)。Pages 上の
このページから fetch するには同一オリジンに無ければならない。

手で足す場合は `bitstreams/manifest.json` に追記し、同じディレクトリに `.bit` を置く。

```json
{
  "bitstreams": [
    { "name": "v0.9.0", "file": "retrocastx_v0.9.0.bit",
      "date": "2026-09-04", "note": "TVP7002 キャプチャ + 音声3系統" }
  ]
}
```

一覧に無いものはページ上で「ローカルファイルから選択」で書ける。開発中は
`gateware/build/colorlight_i5/gateware/colorlight_i5.bit` を直接選べばよい。

## 実測

v0.9.0 基板 + macOS / Chrome で、350KB のビットストリームを TCK 3.75MHz で
**消去 + 書き込み + ベリファイ + 再コンフィグ 合わせて約 7 秒**
(2026-09-04 実機確認)。基板のフラッシュは GigaDevice 2MB (JEDEC `0xc84015`) で、
ブロックプロテクトは出荷状態でかかっていない。

## ファイル

| ファイル | 内容 |
|---|---|
| `ch347.js` | CH347F の WebUSB トランスポートと JTAG TAP ステートマシン |
| `ecp5.js` | ECP5 の background SPI 移行、SPI NOR 操作、Lattice `.bit` パーサ |
| `index.html` | UI |
| `simtest.mjs` | 開発用。ECP5 + SPI フラッシュのシミュレータ相手に全経路を通す |

実機を止めずに検証できる。ビットストリームを渡さなければ直近のビルド結果を使う:

```sh
node docs/flash/simtest.mjs [path/to/foo.bit]
```

TAP 遷移・ビット順・SPI 手順・ページ書き込みループを、偽の CH347 パケット層越しに
検証し、最後に「フラッシュの中身がビットストリームと一致するか」まで確かめる。
`ch347.js` / `ecp5.js` を触ったら流すこと。ビットストリームを渡さず直近のビルド結果も
無ければテスト側が合成するので、FPGA ツールチェーンの無い環境でも走る。

`.github/workflows/flasher-test.yml` が `docs/flash/**` を触った PR で自動実行する。

## コマンドラインとの対応

同じことを openFPGALoader でやる場合:

```sh
./gateware/bitstore.sh flash-perm <名前>
#  = openFPGALoader -b colorlight-i5 -c ch347_jtag -f --unprotect-flash <file>.bit
```

`ch347.js` / `ecp5.js` は openFPGALoader (Apache-2.0) の `src/ch347jtag.cpp`,
`src/lattice.cpp`, `src/spiFlash.cpp` の ECP5 経路を JavaScript に移植したもの。
手順は次のとおり:

1. SRAM を消して FPGA を止める (PRELOAD → ISC_ENABLE → ISC_ERASE → ISC_DISABLE)
2. `IR=0x3A` + `DR={0xFE,0x68}` で background SPI に入る
3. SPI のバイトはビット反転して shiftDR。CS は SHIFT-DR に居る間だけアサートされる
4. WREN / RDSR / 64KB ブロック消去 / ページプログラム / ベリファイ
5. `LSC_REFRESH (0x79)` でフラッシュから再コンフィグ

## 実装上の落とし穴

- **`transferIn` / `transferOut` にはタイムアウトが無い**。libusb の
  `libusb_bulk_transfer(..., timeout)` に相当する引数が WebUSB には存在せず、
  デバイスが応答しないと Promise が永久に解決しない。`ch347.js` では全転送を
  `Promise.race` で包んでいる。libusb 版のコードを移植するときは、捨て読みや
  ステータス待ちをそのまま持ってこないこと
- **IN 転送は必ず 512 バイト要求する**。応答より短い長さを要求すると babble に
  なるため、短く読まずに実際の長さで検証する
- **1回の `transferIn` で応答が全部来るとは限らない**。CH347 はデータをクロック
  アウトしながら小分けに返してくるので、期待バイト数に達するまで読み継ぐこと
  (openFPGALoader の `usb_xfer` が `while (rlen) { ... rlen -= actual_length; }` と
  書いているのはこのため)。ここを 1 回読みにすると、短い応答では動くのに
  509 バイトのベリファイ読み出しだけが壊れる、という分かりにくい形で出る。
  `simtest.mjs` の偽デバイスは応答を意図的に分割して、この前提が入り込んだら
  落ちるようにしてある
- **応答の同期が一度ずれると以降の通信が全部化ける**。`ch347.js` は `desynced`
  フラグを立て、UI は復帰を試さず再接続を促す。再接続時の `setClock` は正しい
  4 バイト応答が出るまで読み捨てて同期を取り直す(WebUSB には「タイムアウト付きの
  空読み」が無いため、期待している通信そのものでリカバリしている)
- **JTAG は書き込み中のビットストリームと独立**。壊れたビットストリームを書いても
  同じ経路で書き直せるので、文鎮化はしない

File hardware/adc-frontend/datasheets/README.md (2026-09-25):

# データシート置き場(ADCフロントエンド)

メーカー配布のPDFは**再配布が許諾されていないためコミットしていません**(`.gitignore` 済み)。
必要なときは各自で入手して、このディレクトリに下表の名前で置いてください。
`main.ato` のコメントはこの名前で参照しています。

多くは可否の記載自体がありませんが(=許諾なし)、Everlight PLR135/T は
データシート本文で明示的に禁止しています。

> These specification sheets include materials protected under copyright of
> EVERLIGHT corporation. Please don't reproduce or cause anyone to reproduce
> them without EVERLIGHT's consent.

**新しい部品を追加するときは、データシートPDFをコミットしないこと。**
この表に1行足して、入手元だけ残してください。

| ファイル | 内容 | 入手元 |
|---|---|---|
| `HR911130A_HanRun_MagJack.pdf` | HanRun HR911130A(1000BASE-T MagJack、トランス・チョーク・Bob-Smith内蔵RJ45) | LCSC [C54408](https://www.lcsc.com/product-detail/C54408.html) |
| `PJ-327C-4A_HOOYA_3.5mmJack.pdf` | PJ-327C-4A(3.5mm ステレオジャック、SMD 4P) | LCSC [C145813](https://www.lcsc.com/product-detail/C145813.html) |
| `emzt6.8e.pdf` | ROHM EMZT6.8ET2R(4ch コモンアノード ESDアレイ、EMD5 / SC-75A)。D1〜D6, D8 | LCSC [C510333](https://www.lcsc.com/product-detail/C510333.html) / ROHM 製品ページで型番検索 |
| `MJ-373-8B_Marushin_MiniDIN8.pdf` | マル信無線電機 MJ-373/8B(ミニDIN 8ピンジャック、基板取付)。J13。**このPDFのPCB穴図から `parts/_mech/MJ373_8B.kicad_mod` を自作した** | モモハラ電機部品 [図面PDF](https://www.mepc.jp/store/pdf/est/drawing/MJ-373-8B.pdf) / 千石電商・マルツの商品ページ |
| `plr135-t.pdf` | Everlight PLR135/T(TOSLINK 光受信モジュール)。J8。文書番号 DPL-0000018_Rev.4 | 秋月電子 [109595](https://akizukidenshi.com/catalog/g/g109595/) |

LCSC の製品ページ内「Datasheet」リンク、または秋月の商品ページからPDFを取得できます。

**注意(PLR135)**: v0.9.0 に実装するのは **PLR135/T**(秋月
[109595](https://akizukidenshi.com/catalog/g/g109595/)、文書 DPL-0000018_Rev.4)で、
上表の `plr135-t.pdf` がその資料です。

以前は **PLR135/T10**(秋月 [109597](https://akizukidenshi.com/catalog/g/g109597/)、
別文書 DPL-0000031_Rev.4)を選定していましたが、DigiKey で廃品種・在庫0になったため
2026-08-19 に T へ切り替えました(取付穴が φ1.15/5.08mm → φ3.20/7.62mm と違うので
ランドも作り直しています)。`parts/_mech/PLR135_T10.kicad_mod` は履歴として
残していますが**使っていません**。経緯は `parts/_mech/mech.ato` の
`SpdifRxModule` の docstring を参照。

## メモ

これらの資料から確認した内容(ピン配置・内蔵終端の構成など)は `main.ato` の
コメントに書き出しています。データシートが手元になくても設計の根拠は追えるように
しているので、再ダウンロードは実際にピン配置を検証し直すときだけで足ります。

なお TVP7002(TI SLES206C)は `docs/datasheets/` 側に置く運用です。

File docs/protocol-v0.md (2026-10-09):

# RetroCastX 伝送プロトコル v0(ドラフト)

RFC 4175(RTP Payload Format for Uncompressed Video)の「ライン単位パケット化 + ピクセルオフセット」
の考え方を下敷きにした、UDP 上の独自軽量プロトコル。将来 RTP でラップして標準ツールと接続する余地を残す。

- トランスポート: UDP / IPv4。デフォルトポート **34600**
- バイトオーダー: **リトルエンディアン**(FPGA・x86/ARM 双方で自然なため)
- 再送なし。パケットロスは受信側が前フレームのラインで補完(シーケンス番号で検出のみ行う)
- 1パケット = 1ライン(または MTU 超過時はラインの断片)。標準MTU(1500)とジャンボフレーム両対応

## 共通ヘッダ(8 bytes)

| offset | size | field | 説明 |
|---|---|---|---|
| 0 | u8 | magic | `0x52` ('R') |
| 1 | u8 | version | `0x00` |
| 2 | u8 | type | 0=LINE, 1=MODE, 2=AUDIO, 3=INFO, 4=SUBSCRIBE, 5=CONFIG |
| 3 | u8 | flags | type 依存(下記) |
| 4 | u16 | frame | フレームカウンタ(VSYNC ごとに +1、ラップあり) |
| 6 | u16 | seq | 全パケット共通のシーケンス番号(ロス検出用、ラップあり) |

## LINE パケット(type=0)

共通ヘッダに続き 12 bytes のラインヘッダ、その後ピクセルデータ。

| offset | size | field | 説明 |
|---|---|---|---|
| 8 | u16 | line | フレーム内ライン番号(0 = アクティブ領域先頭) |
| 10 | u16 | offset_px | この断片の先頭ピクセルの、ライン内オフセット(断片化時以外 0) |
| 12 | u16 | count_px | この断片に含まれるピクセル数 |
| 14 | u8 | pixfmt | 0=RGB888(3B/px), 1=RGB555(2B/px), 2=RGB565(2B/px), 3=YC8(2B/px) |
| 15 | u8 | mode_id | 現在有効な MODE 記述子の ID(タイミング変更検出用) |
| 16 | u32 | timestamp | この断片の先頭ピクセルサンプル時点のドットクロックカウンタ値 |

flags: bit0 = LAST_FRAGMENT(このパケットでラインが完結)、bit1 = FIELD_ODD(インターレース奇数フィールド)

- `timestamp` は FPGA 内でピクセルクロックをフリーランカウント(32bit、ラップあり)した値。
  受信側はこれで HSYNC/VSYNC タイミング(ライン間隔・フレーム間隔)を再構成できる。
- ラインが MTU に収まらない場合は `offset_px` を進めて複数パケットに分割(RFC 4175 と同じ発想)。
  例: 768px × RGB888 = 2304B → 標準MTUでは 2 断片。ジャンボフレーム(MTU 9000)なら常に 1 断片。

### pixfmt = 3 (YC8)

**復調していない生のADC値**を運ぶための形式。2B/px で、

| byte | 内容 |
|---|---|
| 0 | 緑チャネル 8bit。コンポジットなら **CVBS そのもの**、S-Video なら **Y** |
| 1 | 赤チャネル 8bit。S-Video の **C**(コンポジット運用では未接続なので≒0) |

- **2B/px は RGB555 と同じ**なので、断片化・MTU計算・受信側のバッファ確保は共通。
  1B/px の専用形式にすれば帯域は半分になるが、詰め方が全部別系統になる。
- 色副搬送波の位相を推定するには 8bit が必要。RGB555 の 5bit ではカラーバーストが
  9コード p-p しか無く精度が足りない(詳細は `composite-video-plan.md` §3)。
- **この形式では「黒でない範囲」の最適化は成立しない。** ブランキングもカラーバーストも
  ライン全体が中身なので、ボードは常に 1ライン = htotal 画素を送る
  (CONFIG key 0x36 を 3 にすると key 0x30 相当が自動で有効になる)。
- 受信側の既定の見せ方は **Y をグレースケールに置くだけ**。1ラインの波形
  (同期チップ→ブリーズウェイ→カラーバースト→映像)がそのまま絵になるので、
  クランプとゲインが合っているかを目で確認できる。復調は別レイヤの仕事。

### インターレース(MODE mflags bit0=1)の規約

X68000 の 15kHz 512×512 系などのインターレースモード用。**受信側の再構成コードは
プログレッシブと共通**になるよう、座標系はフルフレームで統一する:

- MODE の `vactive` は**フルフレームの行数**(両フィールド合計)、`vtotal` も同様
- 共通ヘッダの `frame` は**フィールドごとに +1**(フィールド=伝送単位のフレーム)
- LINE の `line` は**フルフレーム座標の行番号**。ゲートウェアが
  `2×フィールド内行 + フィールド極性` を計算して付与する
- 奇数フィールドの LINE は flags bit1(FIELD_ODD)を立てる(受信側での
  bob 表示やフィールド極性の統計用。weave 合成だけなら参照不要)
- 受信側はフィールドを受けるたびに半分の行だけ更新されたフレームを得る
  (fill_ratio ≈ 0.5 が正常値)。前フィールドの行が残るため**自然に weave 合成**になる
- **bob 表示**(フィールドを縦2倍して フィールドレートで表示。動きが滑らかで
  コーミングなし)は受信側の表示オプションとして実装(FIELD_ODD で半行オフセット)

## MODE パケット(type=1)

タイミング記述子。**変更時に即時送出**し、以後も毎秒 1 回程度再送(途中参加の受信器のため)。
`mode_id` をインクリメントすることで、受信側は LINE ヘッダの `mode_id` 不一致から
「新しい MODE をまだ受けていない」ことを検出できる。

| offset | size | field | 説明 |
|---|---|---|---|
| 8 | u8 | mode_id | 記述子 ID(変更ごとに +1、ラップあり) |
| 9 | u8 | pixfmt | 以後の LINE の既定ピクセル形式 |
| 10 | u16 | mflags | bit0=interlace, bit1=hsync 極性(1=負), bit2=vsync 極性 |
| 12 | u16 | hactive | 水平有効ピクセル数 |
| 14 | u16 | htotal | 水平トータル(ドットクロック数) |
| 16 | u16 | vactive | 垂直有効ライン数 |
| 18 | u16 | vtotal | 垂直トータルライン数 |
| 20 | u32 | dotclk_hz | 再生ドットクロック周波数 [Hz](FPGA で実測) |
| 24 | u32 | hfreq_mhz_x1000 | 水平周波数 [mHz](=Hz×1000、実測) |
| 28 | u32 | vfreq_mhz_x1000 | 垂直周波数 [mHz](=Hz×1000、実測) |

★**キャプチャ版のゲートウェアでは hactive / vactive は「有効映像の大きさ」ではない。**

- `hactive` はラインバッファの幅(ビルド時の定数 `width`、いまは **2048**)。
  ラインの頭(hs_offset=0)からブランキングごと取り込み、中身のある範囲だけを
  送るので、全モードの htotal(15kHz 1216 / 24kHz 1408 / 31kHz 1104 / NTSC 8fsc 1820)
  が入る幅にしてある。実際の1ラインのサンプル数は `htotal`
- `vactive` は**半ライン単位のスロット数**(インターレースの第2フィールドを半ライン
  ずれた位置に置くため)で、`(vtotal − vbp) × 2`。NTSC なら 263 × 2 = 526
- 有効映像の位置と大きさは受信側が絵から実測する(Viewer の act_x/act_y/act_w/act_h)

### ANNOUNCE の fw_version と caps

`fw_version` は `gw-vX.Y.Z` タグから作る **u16** で、
`bit15:12=major(0〜15) bit11:6=minor(0〜63) bit5:0=patch(0〜63)`。
タグが無いビルドは `0x0000`。

★**16進の桁に揃えるより範囲を優先している。** 4/4/8 なら 0.9.2 が `0x0902` と
そのまま読めるが、パッチが15で頭打ちになる(gw-v0.9.0〜0.9.2 を2日で3つ出した
実績があり、活発な時期には溢れる)。表示側が復号して "0.9.2" と出すので、
人が16進のまま読む場面は無い。
**中身まで一意に指したいときは CONFIG key 0x09(ビルド元コミットのSHA)を読む。**

`caps` の **bit0 = MACを基板のEEPROMから読めた**。0 なら全基板共通のフォールバック
アドレスで動いているので、**同じLANに2枚繋ぐと衝突する**。出荷検査で弾くこと。

## AUDIO パケット(type=2)

音声サンプル。入力は3系統あり(基板仕様)、**複数系統の同時転送も可**
(パケットごとに `source` が付くため受信側で分離できる)。どの系統を送るかは
CONFIG(key 0x0001)で選択する。

| offset | size | field | 説明 |
|---|---|---|---|
| 8 | u8 | source | 0=RGB端子(D-SUB15)音声, 1=LINE入力, 2=S/PDIF |
| 9 | u8 | format | 0=PCM s16le 2ch(L/Rインターリーブ) |
| 10 | u16 | nsamples | このパケットのサンプルフレーム数(L+Rで1) |
| 12 | u32 | rate_hz | 実サンプルレート(アナログ=48000、S/PDIFは受信ストリームの実測) |
| 16 | u32 | timestamp | 先頭サンプル取得時点の**ドットクロックカウンタ**(LINEと同一カウンタ → A/V同期はこれで取る) |
| 20 | ... | samples | L0 R0 L1 R1 ... (s16le) |

- 目安: 48kHz で 240サンプル/パケット(5ms) → 980B、200pkt/s、~1.6Mbps/系統
- flags: 予約(0)
- S/PDIFの44.1kHz等は `rate_hz` で通知(受信側でリサンプルするか、そのまま再生)

## CONFIG パケット(type=5)

アプリ→ボードの設定読み書き。ボードは同レイアウトに flags bit0(REPLY)を立て、
`value` に現在値(SET後は反映値)を入れてユニキャスト返信する。応答が来なければ
アプリが再送する(冪等)。

| offset | size | field | 説明 |
|---|---|---|---|
| 8 | 6B | mac | 宛先ボードMAC(全FF=ワイルドカード)。応答時は**ボード自身のMAC** |
| 14 | 2B | reserved | 0 |
| 16 | u8 | target | 0=キャプチャボード, 1=ArgusX(RGBセレクタ、I2C経由) |
| 17 | u8 | op | 0=SET, 1=GET |
| 18 | u16 | key | 下表 |
| 20 | u32 | value | SET時の設定値 / 応答時の現在値 |

- SUBSCRIBEと同じMAC照合を行い、一致またはワイルドカードのときのみ反応する。
  応答の mac にはボード自身のMACが入るため、静的IP衝突環境でも応答元を判別できる

キー(ドラフト):

| target | key | 意味 |
|---|---|---|
| 0 (board) | 0x0001 | audio_enable_mask: bit0=RGB端子音声, bit1=LINE, bit2=S/PDIF |
| 0 (board) | 0x0002 | spdif_rate_hz: S/PDIFの実測サンプルレート[Hz]。**読み取り専用**。0 ならデコーダがサンプルを出していない |
| 0 (board) | 0x0003 | spdif_fifo_level: S/PDIF送出FIFOの滞留サンプル数。**読み取り専用**。レートが出ているのにここが0なら詰まりは後段 |
| 0 (board) | 0x0004 | spdif_ui: S/PDIFデコーダのUI長を16倍した固定小数点。**読み取り専用**。45MHz なら 48kHz≒117 / 44.1kHz≒128。整数では 7.32 と 7.97 を区別できず復号が成立しない |
| 0 (board) | 0x0005 | spdif_resyncs: デコーダを立て直した回数。**読み取り専用**。増えていれば上記の状態に落ちて自動復帰している |
| 0 (board) | 0x0006 | mac_info: bit0=EEPROMから読めた / bit1=0x51側を使った / bit3:2=失敗箇所(1=アドレスNACK 2=レジスタNACK 3=読出アドレスNACK)。**読み取り専用** |
| 0 (board) | 0x0007 | mac_lo: 使用中のMAC 下位32bit。**読み取り専用** |
| 0 (board) | 0x0008 | mac_hi: 使用中のMAC 上位16bit。**読み取り専用** |
| 0 (board) | 0x0009 | build_id: ビルド元コミットの短縮SHA(u32)。**読み取り専用**。タグが同じでも中身の違うビットストリームを区別できる |
| 0 (board) | 0x0046 | net_mode: bit0=静的IPを使う(0=MAC由来のリンクローカル) |
| 0 (board) | 0x0047 | static_ip: 静的IPv4(ネットワークバイト順の整数)。**0 は静的扱いしない** |
| 0 (board) | 0x0048〜0x004B | name0〜3: ボード名16バイトを4語に分けたもの(UTF-8, NUL詰め, リトルエンディアン) |
| 0 (board) | 0x004C | ident_save: SET 1=EEPROMへ焼く / GET 0=未実行 1=実行中 2=成功 3=失敗 |
| 0 (board) | 0x004D | ident_ee: bit0=妥当な設定ページがあった bit2:1=1未設定/2破損/3EEPROM無応答。**読み取り専用** |

- **0x0046〜0x004B の SET は即座に効き、0x004C で焼くまでは電源で消える。**
  試してから決められるようにするため。焼く前に電源を切れば元に戻る
- **個体設定はMACを指名して送ること。** ブロードキャストのまま撃つと、同じLANの
  全ボードが同名・同IPになる。`retrocastx.identity` は既定で発見→1枚に指名し、
  複数見つかったら `--mac` を要求する
| 1 (ArgusX) | 0x0001 | 映像入力選択(値の意味はArgusX側仕様で定義) |
| 0 (board) | 0x0022 | sync_ctl (TVP reg 0Eh): 0x52=5線 / 0x53=4線TTL C-SYNC / 0x5B=SOG |
| 0 (board) | 0x0050 | sog_thresh (TVP reg 10h): SOGスライス閾値 |
| 0 (board) | 0x0051 | sep_thresh (TVP reg 11h): 同期セパレータ閾値 |
| 0 (board) | 0x0052 | precoast (TVP reg 12h): プリコースト[ライン]。最低1が必要 |
| 0 (board) | 0x0053 | postcoast (TVP reg 13h): ポストコースト[ライン]。最低1が必要 |
| 0 (board) | 0x0054 | syncdet (TVP reg 14h): 同期検出ステータス。**読み取り専用** |
| 0 (board) | 0x0055 | lines_per_frame (TVP reg 37h:38h): TVPが測ったライン数/フレーム。**読み取り専用** |
| 0 (board) | 0x0056 | clocks_per_line (TVP reg 39h:3Ah): TVPが測ったDATACLK数/ライン。**読み取り専用** |

- 0x0054〜0x0056 は **TVP自身の測定値**で、ボードのキャプチャロジックに依存しない。
  SOG(映像レベルC-SYNC)運用では生同期ピンが無信号になり 0x002A〜0x002C が使えないため、
  「H/Vが入力にロックしているか」を判定できる唯一の絶対測定になる
- 0x0050 は 5bit値。TVP reg 10h の下位3bitはクランプ選択で共用されているので、
  **閾値(0x0050)とクランプ選択(0x005E)を別キーで持ち、書き込み時に連結する**。
  1本のキーで生の8bitを書くと、片方を触るともう片方を巻き込んで壊れる

### 映像入力の方式切り替え用のキー

| target | key | 説明 |
|---|---|---|
| 0 (board) | 0x0036 | pixfmt: 伝送ピクセル形式。0=RGB888 / 1=RGB555(既定) / 3=YC8(生8bit) |
| 0 (board) | 0x0037 | black_th: 非黒判定の閾値(成分の上位5bit と比較, 0..31)。既定0。**上げると暗い絵の中身が範囲から外れて送られなくなる** |
| 0 (board) | 0x005E | clamp_sel (TVP reg 10h[2:0]): bit2=Blue bit1=Green bit0=Red。0=ボトム 1=ミッド |
| 0 (board) | 0x005F | coarse_gain_gb (TVP reg 1Bh): **[7:4]=Green [3:0]=Blue**。Gain = 0.5 + N/10 |
| 0 (board) | 0x0065 | coarse_off_g (TVP reg 1Fh[5:0]): 粗アナログオフセット Green。10h=+64コード |
| 0 (board) | 0x0067 | coarse_gain_r (TVP reg 1Ch): **[7:4]=Reserved [3:0]=Red**。1Bhとビット割りが違う |
| 0 (board) | 0x0068 | coarse_off_r (TVP reg 20h[5:0]): 粗アナログオフセット Red |
| 0 (board) | 0x0069 | in_mux1 (TVP reg 19h): [7:6]=SOG [5:4]=R [3:2]=G [1:0]=B、00=_1/01=_2/10=_3 |

**0x005E と 0x005F は必ずセットで動かす。** ミッドレベルクランプにするとブランキングが
コード512に座るので、白側(+100 IRE)に使えるヘッドルームが半分になる。既定の粗ゲイン
1.2倍のままではコンポジット(1Vpp=140 IRE)が飽和する(データシート 1Bh は
「Vpp × Gain < 1Vpp」を要求する)。数値の内訳は `composite-video-plan.md` §2。

**0x005F と 0x0067 は同じ「1.2倍」でも値が違う**(1Bh=0x77 / 1Ch=0x07)。
1Bh は Blue と Green の2チャネルぶんを1バイトに詰めているため。

**0x0069 は入力方式の切り替えに必須。** 以前はビルド時定数だったので、SOG の入力ピンが
違う機種(MSXのC-SYNCは SOGIN_2)に切り替えるにはビットストリームの焼き直しが要った。
なお **HSYNC_A/_B・VSYNC_A/_B の選択は 19h ではなく 1Ah bit0/bit2**(key 0x005D)。

- 0x0010〜0x002C・0x0030〜0x0036・0x0040〜0x0045 は画枠パラメータと診断用の
  読み出しに割り当て済み。**新しい設定キーは 0x0050 以降から取る**
  (0x0023〜0x0026 は診断キーと衝突する)
- **0x0013〜0x0016 は空いていない。** インターレース判定が「設定」から「測定」へ
  移ったのでゲートウェアは読まなくなったが、`CFG_KEY_INTERLACE` などの名前が
  host/client に残っているので再利用してはいけない。
  現時点で真に空いているのは 0x002E〜0x002F / 0x0038〜0x003F / 0x004E〜0x004F /
  0x006B 以降(0x0046〜0x004D は個体設定で使用)

キーの割り当ては `host/python/retrocastx/protocol.py` の `CFG_KEY_*` を正とし、
ゲートウェア側は `gateware/retrocastx_stream.py` の `reply_cases` と対応させる。

- ArgusX宛のCONFIGは、ゲートウェアがI2Cバス(TVP7002と共有、J11コネクタ)経由で
  ArgusXへ中継する。ArgusXのI2Cアドレス・レジスタマップはArgusX側で確定後に反映
- 認証なし(同一LAN前提)。SETは全て冪等な値設定のみとする
- **ブロードキャスト可**(SUBSCRIBEと同様)。PCとボードのサブネットが食い違う構成
  (直結・DHCPなし等)ではユニキャストがOSのルーティングで送れないため、
  アプリはCONFIGもブロードキャストで送ってよい。ただし同一LANの全ボードに
  適用されるため、複数ボード環境ではDHCP導入後にユニキャストで送ること
- ブロードキャストで送る場合、**アプリは応答の flags bit0(REPLY)を必ず検査する**。
  ブロードキャストは自分自身の送信パケットにもループバックするため、REPLYを見ないと
  自分の要求を応答と誤認し、SETが常に成功・GETが常に送った値に見える(実際に踏んだ)

## INFO / ANNOUNCE パケット(type=3)

ボードの自己紹介。**発見(Discovery)と生存確認**に使う。共通ヘッダに続き 32 bytes:

| offset | size | field | 説明 |
|---|---|---|---|
| 8 | 6B | mac | ボードのMACアドレス |
| 14 | 4B | ip | ボードが自認するIPv4(参考値。**受信側はUDP送信元アドレスを正とする**) |
| 18 | u16 | udp_port | データ/制御ポート |
| 20 | u16 | fw_version | ファームウェアバージョン |
| 22 | u16 | caps | 能力ビット(bit0=TVP7002, bit1=アナログ音声, bit2=S/PDIF, bit3=ArgusX接続) |
| 24 | 16B | name | ボード名(UTF-8, NUL詰め)。EEPROMの設定ページ由来。未設定なら `retrocastx-i5` |

## SUBSCRIBE パケット(type=4)

アプリ→ボード。共通ヘッダに続き 8 bytes。**ブロードキャスト可**。

| offset | size | field | 説明 |
|---|---|---|---|
| 8 | 6B | mac | 宛先ボードのMAC。全FF(`ff:ff:ff:ff:ff:ff`)=ワイルドカード(全ボード) |
| 14 | 2B | reserved | 0 |

- ボードは **mac が自分のMACと一致、またはワイルドカード** のときのみ反応する。
  一致しなければ完全に無視(応答もストリーム切替もしない)
- flags bit0 = ANNOUNCE_ONLY: 1なら発見のみ(ボードはANNOUNCEを送信元へユニキャスト返信)
- flags bit0 = 0 なら、ボードは以後の映像ストリームの送り先を**このパケットの送信元**に切り替え、
  ANNOUNCEを返す。購読は最後のSUBSCRIBEから10秒で失効(アプリは定期再送する)
- **複数ボード運用**: ワイルドカードでの本購読(ANNOUNCE_ONLY=0)は全ボードが同時に
  ストリームを向けてくるため単一ボードLAN専用。複数ボード環境では
  ①ワイルドカード+ANNOUNCE_ONLY で発見 → ②ANNOUNCE で各ボードのMACを取得 →
  ③目的ボードのMACを指名して本購読、とする(ブロードキャスト送信のままでよい)

## アドレッシングと発見の設計

- **MACアドレス**: 基板のEUI-48 EEPROM(24AA025E48、ポートごとに1個)から
  起動時に読み出したグローバル一意アドレスを使用。EEPROM未実装/読出し失敗時は
  ローカル管理アドレス `02:52:43:58:xx:xx`("RCX"、既定 `02:52:43:58:00:01`)に
  フォールバック
- **個体設定の保存先**: MACと同じ EUI-48 EEPROM の空き領域(0x00..0x1F)。
  0x00-01 magic 'RX' / 0x02 ver / 0x03 flags / 0x04-07 静的IP / 0x08 チェックサム /
  0x10-1F 名前。**書込みは8バイトページ単位で、ヘッダ(magic のあるページ0)を最後**に
  焼く。途中で電源が落ちたページは magic が古いまま = 「未設定」として捨てられる
- **発見はアプリ起点**: アプリが `255.255.255.255:34600` へ SUBSCRIBE(ANNOUNCE_ONLY) を
  ブロードキャスト → ボードがユニキャストで ANNOUNCE 返信。
  ボード側受信はブロードキャスト対応(LiteEth `with_broadcast=True`)なので、
  **ボードとPCのサブネット設定が食い違っていても同一L2セグメントなら発見できる**
- **IPアドレス**: 既定は **MAC由来のリンクローカル**(RFC 3927、`169.254.<mac[4]>.<mac[5]>`、
  第3オクテットは 1..254 に丸める)。基板ごとに違う値になるので、複数台を同じLANに
  繋いでも衝突しない。**固定の 192.168.10.50 は繋ぐ相手を選んだ**ため廃止
- **静的IP**: CONFIG 0x0046/0x0047 で設定し、0x004C で EEPROM に焼ける。
  ルータを跨ぐ構成(ブロードキャストが届かない)向けの逃げ道。
  **既定はオフ。** 自前のツールはどれも固定IPを必要としない(発見はブロードキャスト、
  映像の送り先は SUBSCRIBE の送信元)ので、通常は設定する理由が無い
- **設定を間違えても行方不明にはならない**: 受信は宛先IPを見ずに通し
  (LiteEth `with_broadcast=True`)、応答は受信パケットから学習したMACへ返すので、
  **サブネットが食い違うPCに直結してもブロードキャストで発見でき、その場で戻せる**
  (実測: ホストが 192.168.11.0/24 のみ、ボードが 169.254.132.41 の状態で
  `discover` が発見)
- **DHCP** は LiteEth 同梱のハードウェアDHCPクライアント(`liteeth/core/dhcp.py`)で
  導入できる。**入れるならリンクローカルで先に上げ、リースが取れたら乗り換える**:
  OSのAPIPAが嫌われるのは「先にDHCPを待って、諦めてから」落ちるからで、
  自前実装なら逆順にできる(RFC 3927 も並行動作を認めている)。
  アプリ→ボードは全てブロードキャスト可、ボード→アプリは宛先を直接解決する
  (ゲートウェイ概念なし=全てオンリンク扱い)ため、DHCPサーバの無い直結構成
  (PC側も169.254.x.x自己割当)でもサブネット不一致のまま全通信が成立する。
  ただし**ARPで引くだけでは足りない**: Windows は別サブネットの送信元から来た
  ARP要求に応答しない(strong host model)。そのためボードは**受信パケットから
  相手のMACを学習**して返す(`gateware/retrocastx_net.py`、design-notes 参照)
- 映像の送り先はSUBSCRIBE送信元に動的に決まるため、アプリ側のIP設定は不要

## 帯域の目安

| モード | アクティブレート | RGB888 | RGB555 |
|---|---|---|---|
| 768×512@55.46(X68000 31kHz) | ~24 Mpx/s | ~580 Mbps | ~390 Mbps |
| 640×400@56.4(PC-98 24kHz) | ~14 Mpx/s | ~350 Mbps | ~230 Mbps |
| 512×512@55.46(X68000 15kHz) | ~8 Mpx/s | ~190 Mbps | ~130 Mbps |

ヘッダオーバーヘッドは 20B/ライン + UDP/IP/Ether 42B ≒ ライン当たり 62B(2304B に対し 2.7%)。

## 受信側の再構成方針

1. MODE を受けてフレームバッファ(hactive×vactive)を確保
2. LINE を `frame`/`line`/`offset_px` に従って書き込み
3. VSYNC 相当は「`frame` が進んだこと」で検出(将来: FRAME_END フラグの追加を検討)
4. 表示は 2 通り:
   - **フレーム同期モード**: フレーム完成を待って表示(実装が簡単、遅延 ≦1フレーム)
   - **レースザビームモード**: 受信したラインから逐次テクスチャ更新(最小遅延、VRR 前提)
5. パレット吸着(オプション): 機種プロファイル(例: X68000 = RGB 5bit)に基づき
   受信 8bit 値を最近傍のネイティブパレット値にスナップ

## 未決事項(v1 へ向けて)

- AUDIO: 24bit対応(format=1)、ADPCM等の圧縮形式の要否
- CONFIG: ArgusX側のI2Cアドレス・レジスタマップ確定後のキー定義
- FRAME_END / ブランキング明示パケットの要否
- 前方誤り訂正(FEC)や XOR パリティラインの要否(GbE 有線ではロスは稀の想定)
- RTP ヘッダでのラップ(Wireshark での解析性と標準ツール接続のため)
- 圧縮モード(ラインRLE / 前ライン差分)— レトロ画面は圧縮が非常に効くはず

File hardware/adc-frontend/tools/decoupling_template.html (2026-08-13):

RetroCastX · ADC フロントエンド

# パスコン配置レポート

← ドキュメント一覧 ◐ テーマ切替

このページは default.kicad_pcb から生成している(hardware/adc-frontend/tools/gen_decoupling_html.py)。 以前は手書きの表だったが、デジグネータを振り直したり部品を足し引きするたびに嘘になったので生成に切り替えた。 載っているのは「置くべき場所の希望」ではなく実際にどれだけ近く置けたかの実測で、配線後のレビュー用。 各コンデンサについて、ネットを共有する最も近いIC・コネクタを対象とし、そのネットに繋がる対象側のピン番号と、 最も近いピアまでの距離を出してある。距離が大きい順に並べてあるので、上から見ていけば妥協した箇所が分かる。 設計意図の注記は atopile_address をキーに引いているので、番号を振り直しても壊れない。

5mm超 2〜5mm 2mm以内

## 距離の目安

- 2mm以内 ループ面積が効く箇所(PLLループフィルタ、アンチエイリアス、コア電源)はここに入れたい。ビアを挟まないこと
- 2〜5mm 通常のパスコンとして妥当。パッド → コンデンサ → GND の経路を短く、GNDビアはコンデンサ直下に
- 距離が出るのはパスコン(片側GND)だけ。直列/結合コンデンサは抵抗を挟んだ先のICが拾われて無意味な数字になるので「—」にしてある。GND-シャーシ間のブリッジも同様
- 5mm超 レール上のバルクや終端なら実害は小さい。コア電源やPLLでこれが出ていたら見直す

## 注記の「要確認」について

- 旧版に手書きの設計意図があったが、その後に値かパッケージが変わっているものには 要確認 を付けて注記を伏せてある。 流用すると嘘になるため。書き直したら tools/decoupling_notes.json に atopile_address をキーに追記すること

座標・距離・ピン番号はすべて hardware/adc-frontend/layouts/default/default.kicad_pcb から機械的に算出。部品を動かしたら再生成すること。
典拠: TVP7002 データシート SLES206C / PCM1808 SLES177B の Layout Example / PLR135 データシート / hardware/adc-frontend/docs/layout-guidelines.md

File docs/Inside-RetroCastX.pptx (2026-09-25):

## Inside RetroCastX

Copyright (c) 2026. Kunihiko Ohnaka. All rights reserved.

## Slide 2

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
6866
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
I2CA
RESETB
DVDD
IOGND
R0
R2
R4
R5
R7
R9
IOVDD
G1

SCL
TMS
PWDN
GND
IOVDD
R1
R3
IOGND
R6
R8
IOGND
G0

GIN1
AVDD
AVDD
AGND
RIN2
A33GND
A33VDD
BIN3
BIN1
AGND
FIDOUT
HSOUT

SOGIN1
AGND
AGND
AVDD
RIN3
RIN1
A33VDD
A33GND
BIN2
AVDD
NSUB
VSOUT
SOGOUT

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
IOVDD
DVDD
B1
B3
B5
B7
B9
IOGND

G2
G4
G6
G8
IOGND
GND
B0
B2
B4
B6
B8
DTCLK
IOVDD

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
SOGIN2
SOGIN3
A33GND
A33VDD
NSUB
PLLF
FILT1
PLLAVDD
PLLAGND
HSYNCA
VSYNCB
COAST

GIN2
GIN3
GIN4
A33VDD
A33GND
PLLAG
FILT2
PLLAGND
PLLAVDD
HSYNCB
EXTCLK
VSYNCA
CLAMP

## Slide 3

GIN1
AVDD
AVDD
AGND
RIN2
A33GND
A33VDD
BIN3
BIN1
AGND
FIDOUT
HSOUT

SOGIN1
AGND
AGND
AVDD
RIN3
RIN1
A33VDD
A33GND
BIN2
AVDD
NSUB
VSOUT
SOGOUT

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
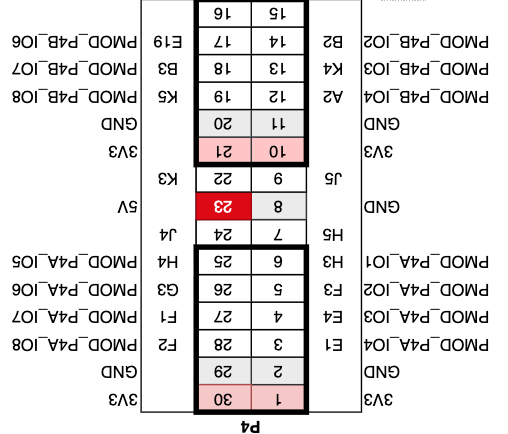
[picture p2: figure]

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
SOGIN2
SOGIN3
A33GND
A33VDD
NSUB
PLLF
FILT1
PLLAVDD
PLLAGND
HSYNCA
VSYNCB
COAST

GIN2
GIN3
GIN4
A33VDD
A33GND
PLLAG
FILT2
PLLAGND
PLLAVDD
HSYNCB
EXTCLK
VSYNCA
CLAMP

IOVDD
DTACLK
B8
B6
B4
B2
B0
GND
IOGND
G8
G6
G4
G2

IOGND
B9
B7
B5
B3
B1
DVDD
IOVDD
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
I2CA
RESETB
DVDD
IOGND
R0
R2
R4
R5
R7
R9
IOVDD
G1

SCL
TMS
PWDN
GND
IOVDD
R1
R3
IOGND
R6
R8
IOGND
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
6866
64
62
60
58
56
54
52

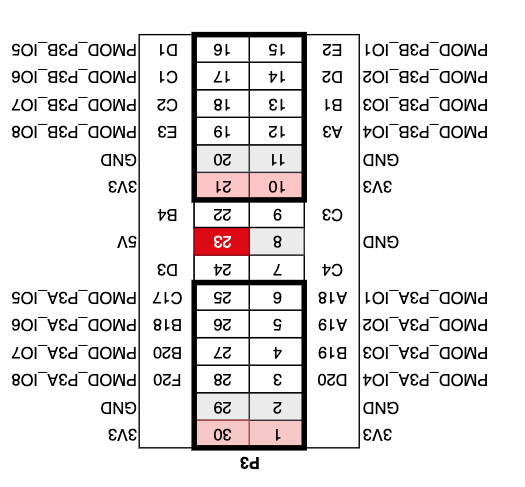
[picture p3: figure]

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
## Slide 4

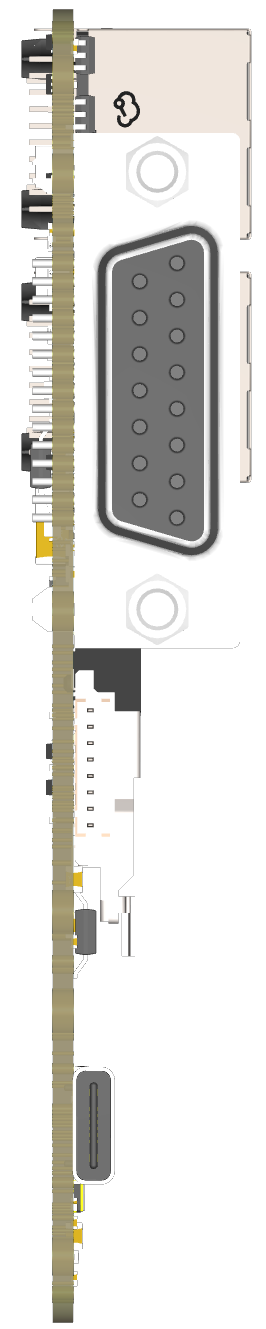
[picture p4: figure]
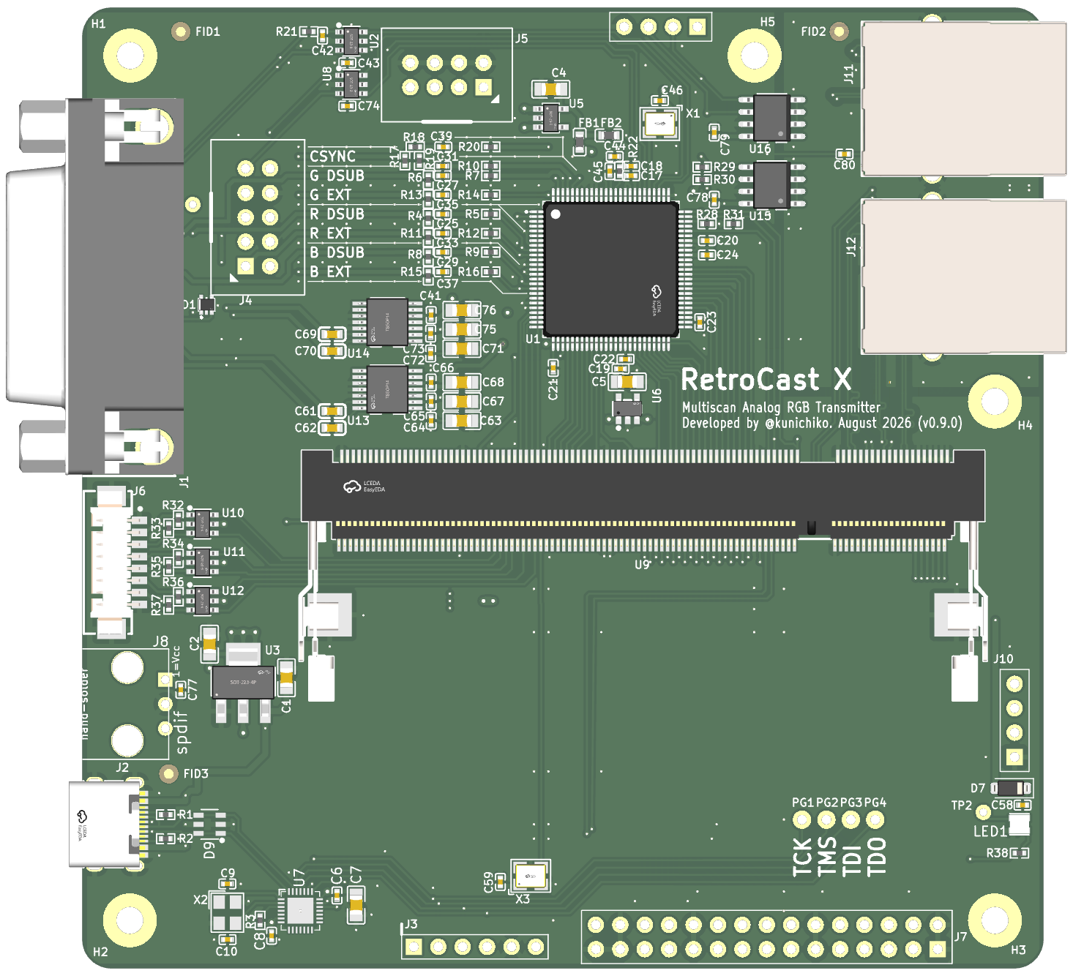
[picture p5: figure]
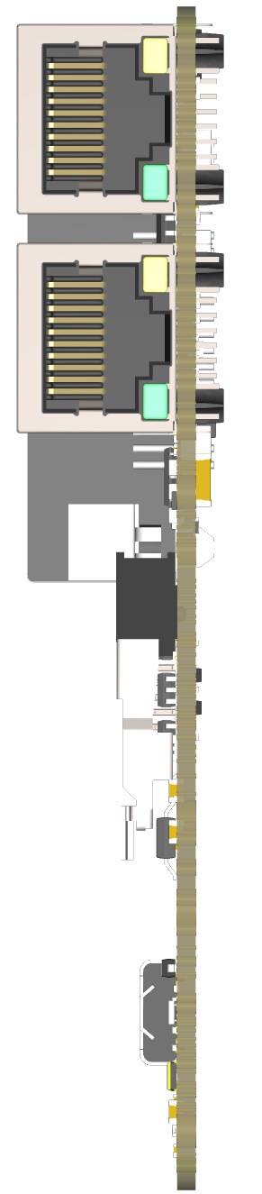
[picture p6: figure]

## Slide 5

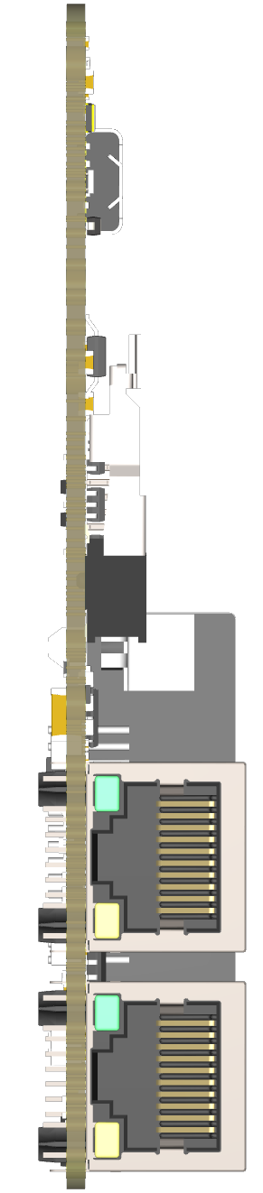
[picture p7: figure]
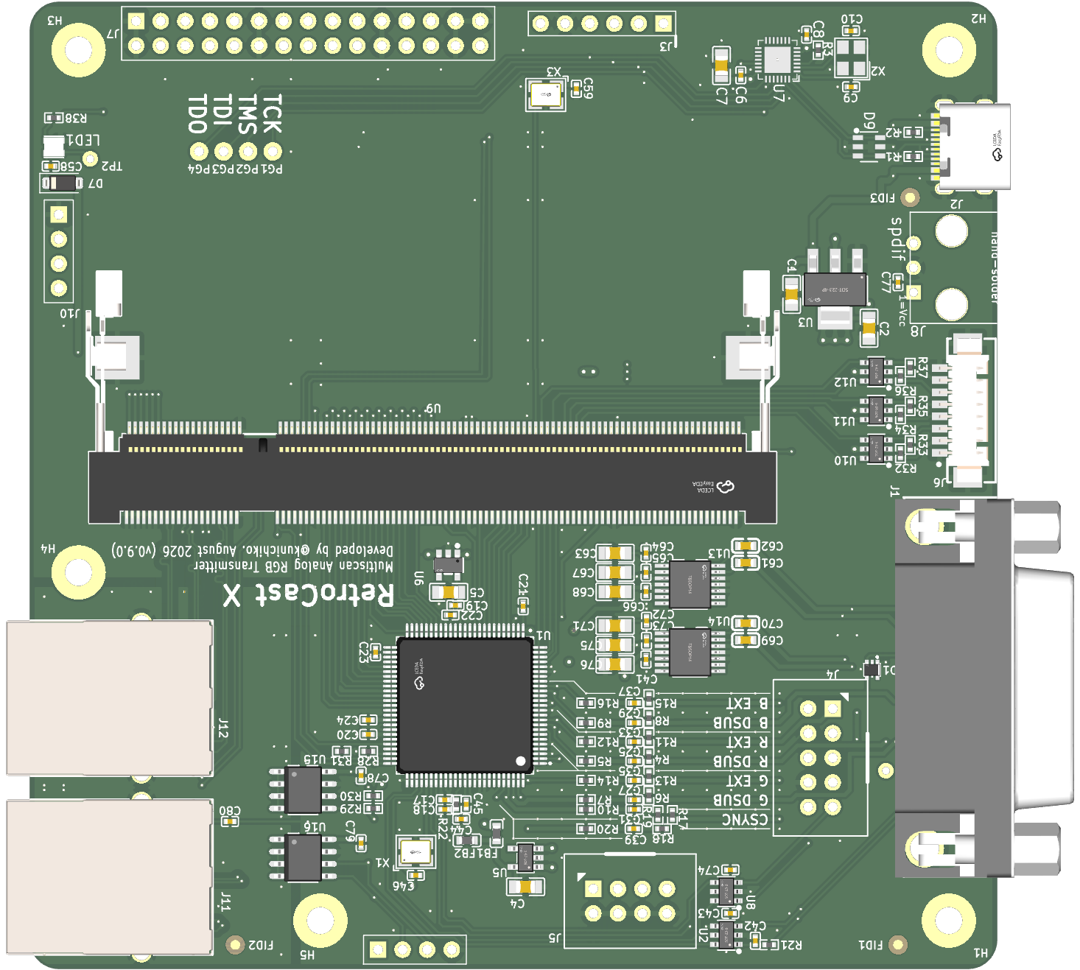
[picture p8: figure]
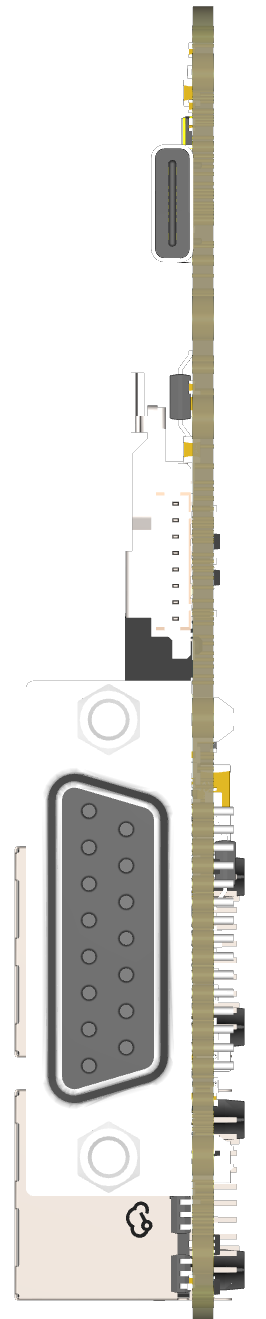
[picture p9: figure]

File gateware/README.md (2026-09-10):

# RetroCastX ゲートウェア(Colorlight i5 / LiteX)

**ステータス: step2(テストパターン・ストリーマ)実装済み・シミュレーション検証済み**(実機は入手待ち)。
ローカル環境: `~/opt/oss-cad-suite` + `gateware/.venv`(LiteX一式、gitignore済み)。

```sh
export PATH="$HOME/opt/oss-cad-suite/bin:$PATH"
.venv/bin/python retrocastx_stream.py --build   # -> build/colorlight_i5/gateware/colorlight_i5.bit
.venv/bin/python sim_stream.py                  # 実機不要のプロトコル検証(Migenシミュレーション)
.venv/bin/python sim_arp.py                     # 受信からのARP学習(retrocastx_net.py)の検証
.venv/bin/python sim_status.py                  # 共有I2C(TVP7002 + OLED)の検証
.venv/bin/python sim_eeprom_cfg.py              # 個体設定ページ(EEPROM)の読み書き検証
.venv/bin/python sim_drgb.py                    # デジタルRGB(生成器→測定器のループバック)
```

## デジタルRGB(TTL RGBI + HS/VS)

デジタルRGBを出せる実機が無いので、**デバッグ端子から試験信号を出して
デジタルRGB入力へ戻す**(`gateware/retrocastx_drgb.py`)。レベル変換器と
コネクタを含む**本番の経路**を通るので、実機が来たときに疑う場所が論理だけになる。

ジャンパ(6本 + GND):

| J4(デバッグ端子) | | J13(デジタルRGB) |
|---|---|---|
| pin3 dbg1 | → | pin2 R |
| pin4 dbg2 | → | pin3 G |
| pin5 dbg3 | → | pin4 B |
| pin6 dbg4 | → | pin5 I |
| pin7 dbg5 | → | pin6 HS |
| pin8 dbg6 | → | pin7 VS |
| pin1/2 GND | → | pin1 or 8 GND |

狙うタイミングは PC-8001 / mkII 系(**14.31818MHz / htotal 910 / fH 15,734Hz**
= NTSC そのもの。8001 はコンポジット出力も持つので NTSC 準拠でないと成立しない)。
★この値は μPD3301 の実装解析(Web)によるもので、**回路図やサービスマニュアルの
ような一次資料では未確認**。実機が入ったら検算すること。

生成側は sys の整数分周(45MHz / 3 = 15.0MHz、htotal 953)で **fH を実機に
0.035% まで合わせる**。ドットクロックの絶対値は違うが、受け側は同期から作り直す
ので問題にならない。新しいクロックドメインを作らないのが肝
(eth_rx のタイミングが配置シード次第で落ちる基板なので)。

    python3 -m retrocastx.cfg get 0x0070   # fH
    python3 -m retrocastx.cfg get 0x0075   # 極性(測定値。決め打ちしていない)
    python3 -m retrocastx.cfg get 0x0077   # 1ドット縞の色変化回数

★**ループバックで確かめられないこと**: 生成側と測定側が同じクロックなので、
送り側と受け側のクロック差(ドリフト)は試験できない。そこは実機でしか出ない。

`retrocastx_i2c.py` は起動時に基板の EUI-48 EEPROM(24AA025E48)から
**MACと個体設定(ボード名 / 静的IP)** を読む。`sim_eeprom_cfg.py` は EEPROM を
**書込みまで含めて**模擬する ─ 8バイトページの折り返し、書込み中の無応答
(ACKポーリングが要る)、EUI-48 の書込み保護。手を抜いた実装がここで落ちる。

個体設定の変更は CONFIG 0x0046〜0x004D で、ホスト側は:

```sh
python3 -m retrocastx.identity                        # いまの設定を見る
python3 -m retrocastx.identity --name x68k-desk --save
python3 -m retrocastx.identity --ip auto --save       # リンクローカルに戻す
```

`retrocastx_net.py` は UDP/IPコアに「受信パケットから相手のMACを学習する層」を足した
もの(`LiteEthUDPIPCore` の代わり)。ARP要求に応答しない相手 ─ 別サブネットの
Windows ─ へも返せるようにするため。理由と挟む位置はファイル冒頭と
[docs/design-notes.md](../docs/design-notes.md) を参照。

step2 の内容(全てハードウェア実装、CPU不介在):

- **SUBSCRIBE受信**: 映像の送り先をSUBSCRIBE送信元(IP/ポート)に動的切替。
  最後のSUBSCRIBEから10秒で購読失効(PC側が2秒ごとに再送)
- **ANNOUNCE**: 毎秒送出 + SUBSCRIBE受信時に送信元へ即時ユニキャスト返信(発見用)
- **MODE**: 購読開始時に即時送出 + 毎秒再送
- **LINE**: テストパターン(`host/python` の `pattern.make_frame` と同一)を
  RGB555・512×512・30fps で 1ライン=1パケット送出(~126 Mbps)

`sim_stream.py` は UDPポート直結のシミュレーションで、生成パケットを
PC側実装(`protocol.py`/`receiver.FrameAssembler`)にそのまま食わせ、
再構成フレームが `pattern.make_frame` と(RGB555量子化を除き)**ビット一致**する
こと、MODEがLINEに先行すること、購読タイムアウトで停止することを確認する。

実機到着後の疎通手順:

```sh
# PC側(同一L2セグメント、192.168.10.x を推奨。発見だけなら食い違っていても可)
python3 -m retrocastx.discover                        # ANNOUNCEが見えること
python3 -m retrocastx.receiver --subscribe --dump out # SUBSCRIBE送出+パターン受信
```

タイミング収束済み(step2+音声, seed=3): **eth_rx 135.4MHz(制約125)/
sys 49.9MHz(制約45)/ aud 182.8MHz(制約12.29)**。
ポイントは `LiteEthUDPIPCore(..., with_sys_datapath=True)`(CRC等の広幅処理をsysドメインへ
移し、125MHzのethドメインは8bit幅の軽い経路のみにする)。これ無しではeth_rxが93MHz止まり。
sysは音声パス追加時に50→**45MHz**へ変更(50MHzでは収束せず。45MHz×32bit=180MB/sで
GbE線速125MB/sに対しなお十分)。

## 構成

- ターゲット: Colorlight i5(ECP5 LFE5U-25F-6BG381C + GbE PHY ×2)+ 拡張基板
- フレームワーク: [LiteX](https://github.com/enjoy-digital/litex) + [LiteEth](https://github.com/enjoy-digital/liteeth)
  - LiteEth の UDP/IP コアはハードウェア実装(データパスにCPU不介在)なので、
    「ADC→ラインFIFO→UDP送出」を全てゲートウェアで完結できる
- 参考実装: [enjoy-digital/colorlite](https://github.com/enjoy-digital/colorlite)
  (5A-75B 上の LiteEth UDP/Etherbone デモ。CRG・PHY 配線はこれに倣う)

## ネットワーク設計(2026-07-26 決定)

- **MAC**: 基板のEUI-48 EEPROM(24AA025E48 ×2、0x50=ETH0/0x51=ETH1)から起動時に
  読み出す(グローバル一意)。**実装済み**(2026-09-08)。0x50 が応答しなければ 0x51 を試し、
  どちらも駄目ならローカル管理アドレス `02:52:43:58:00:01` へ落ちる。
  読み出し結果は CONFIG key 0x06〜0x08 で確認できる
- **IP**: 既定は **MAC から導いたリンクローカル `169.254.<mac[4]>.<mac[5]>`**
  (RFC 3927。第3オクテットは 1..254 に丸める)。**実装済み**(2026-09-08)。
  ★**出荷時に他人のサブネットの住所を名乗らないため。** 従来の 192.168.10.50 は
  利用者が同じ範囲を使っていれば衝突し、基板を2枚繋げば基板同士でも衝突した。
  この構成では**ホスト→ボードはブロードキャスト、ボード→ホストはSUBSCRIBEの
  送信元を学習**するので、IPに求められるのは「衝突しないこと」だけ。
  ★**IPを直接指定する運用はできなくなる**(ホストが169.254のアドレスを持たないため)。
  必要なら EEPROM の設定ページで固定IPを上書きできるようにする(フェーズ3)
- **DHCP**: LiteEth同梱のハードウェアクライアント(`liteeth/core/dhcp.py`、CPU不要)が
  使える。ただし**PC直結ではDHCPサーバがいない**ので、導入するならOSと同じく
  「DHCPを試して駄目ならリンクローカル」の二段構えが要る
- **発見**: アプリがSUBSCRIBE(ANNOUNCE_ONLY)をブロードキャスト → ボードがANNOUNCEを
  ユニキャスト返信(受信は `with_broadcast=True` で対応済み。LiteEthの通常UDP送信パスに
  ブロードキャストの特別扱いが無いため、ボード発ブロードキャストは使わない設計)
- **ストリーム送り先**: SUBSCRIBE送信元に動的設定(step2で実装)。PC側のIP固定は不要になる

## ブリングアップ計画

1. **step0**: LED点滅 + JTAG書き込み確認(`--build --load`)
2. **step1**: 固定ペイロード(ANNOUNCE)のUDP連続送出、PC側で受信確認
   (step2のコードに置き換え済み。ANNOUNCEビーコンとしてstep2にも含まれる)
3. **step2**: テストパターン生成器 + プロトコルv0のLINE/MODEパケタイザ + SUBSCRIBE購読
   (**コード実装済み・シミュレーションでPC側実装とビット一致を検証済み**。
   実機での `receiver --subscribe` 表示確認が残タスク)
4. **step3**: SODIMM I/O にTVP7002ブレークアウトを接続、実信号キャプチャへ
   (DATACLKのクロック対応ピン割当は hardware/adc-frontend の J4=F2/PCLKT7_0 で確定済み)。
   **ライン断片化の実装が必要**: step2のパケタイザは1ライン=1パケット前提
   (768px RGB888 = 2324B > MTU1500。クライアント側は断片化受信を
   768×512@55.46/533Mbpsで検証済みなので、ゲートウェア側のみ)。
   **インターレース対応**: TVP7002のFIDOUT(フィールド識別)はJ4のB2に配線済み。
   規約は protocol-v0.md で確定(line=フルフレーム行・frame=フィールドごと+1、
   受信側は無修正でweave合成になることを検証済み)。ゲートウェアは
   FIDOUTから行番号 2n+field を計算してFIELD_ODDフラグを立てるだけ
5. **step4(音声+CONFIG)**: **コード実装済み・sim検証済み**(retrocastx_audio.py)。
   - I2Sキャプチャ×2: MCLK 12.288MHz(F1/PCLKC6_1)="aud"ドメイン、BCK/LRCK分周
     生成、DOUT(F3/J4)から上位16bit取得、AsyncFIFOでsysへ。PCM1808波形モデルで
     ビット一致検証(sim_audio.py)
   - S/PDIFデコーダ(E19): sysクロックでBMC復号(UI長EWMA追従、プリアンブル
     B/M/W判別、レート実測)。非整数UI(8.14サイクル)の波形でビット一致検証
   - AUDIOパケット送出(ソース別FIFO、複数同時可)+ CONFIG受信/応答
     (音声マスク・ArgusX仮レジスタ)を統合sim(sim_stream.py シナリオC)で検証
   - 実機残タスク: TVP7002のI2C初期化、ArgusX宛CONFIGのI2C中継(仮レジスタを置換)、
     MAC EEPROM(24AA025E48@0x50)の起動時読み出し→MAC設定(読めなければLAAへ
     フォールバック。Ethernetの有効化をEEPROM読了まで保留する)

## ツールチェーン(macOS)

```sh
# オープンソースFPGAツール一式(yosys / nextpnr-ecp5 / prjtrellis / openFPGALoader)
brew install yosyshq/tap/oss-cad-suite   # または GitHub Release のバイナリを展開してPATHへ

# LiteX(専用venv推奨)
python3 -m venv ~/litex-env && source ~/litex-env/bin/activate
pip install meson ninja
wget -O litex_setup.py https://raw.githubusercontent.com/enjoy-digital/litex/master/litex_setup.py
mkdir -p litex-src && cd litex-src
python3 ../litex_setup.py --dev --init --install    # ★--dev を必ず付ける
```

### ★`--dev` を必ず付けること

`litex_setup.py` は起動時に**自分自身と `litex_repos.py` を upstream の master で
無条件に上書きする**。`litex_repos.py` は各リポジトリを sha1 で固定している
このリポジトリの管理対象ファイルなので、`--dev` を付けずに走らせると**固定が
丸ごと消えて、次のビルドが別バージョンの LiteX で行われる**。

`--dev` は自動更新を止めるフラグで、`GITHUB_ACTIONS=true` のときは clone URL を
SSH に書き換えない作りになっているため、CI でもそのまま使える。

固定を今の環境で取り直したいときは:

```sh
cd litex-src && python3 ../litex_setup.py --dev --freeze --freeze-output=../litex_repos.py
```

### ★タイミングはビルドの成否で分からない

LiteX は nextpnr に `--timing-allow-fail` を渡すので、**タイミング違反でもビルドは
成功する**。しかも eth_rx(125MHz要求)や sys(45MHz要求)は配置シード次第で通ったり
落ちたりする(`retrocastx_stream.py` の `--seed` のコメント参照)。

★**見るのは「ルーティング後の最終値」**。nextpnr は Max frequency を2回出し、
**配置後の見積りは通っているビルドでも普通に FAIL している**。ログを頭から grep すると
健全なビルドを落とす(CI の初回実行で実際に踏んだ: crg_clkout は見積り 44.62MHz FAIL、
最終 55.27MHz PASS)。クロックごとに最後の報告を見ること。

CI(`.github/workflows/gateware-release.yml`)はこれを自動で検査して落とす。
判定結果はジョブサマリに表で出る。

## リリース

`gw-vX.Y.Z` の注釈付きタグを push すると、`gateware-release.yml` が

1. 固定した LiteX + oss-cad-suite でビルド
2. タイミング検査(`FAIL at` があれば落とす)
3. WebUSB フラッシャのシミュレータに通す
4. GitHub Release を作成して `.bit` を添付
5. 同じ `.bit` を main の `docs/flash/bitstreams/` に commit し `manifest.json` を更新

まで行う。5 まで済むと <https://kunichiko.github.io/RetroCastX/flash/> の一覧に出て、
ブラウザから焼けるようになる。

```sh
git tag -a gw-v0.9.0 -m "gw-v0.9.0: タイトル

タグの注釈メッセージが Release の本文と、フラッシャの一覧の説明文になる。"
git push origin gw-v0.9.0
```

★**前置きの `gw-` は必須。** Viewer のリリース(`viewer-release.yml`)が `v*.*.*`
で走るので、素の `v0.9.0` を打つと両方動いてしまう。

タグを打たずに CI のビルドだけ試したいときは、Actions から
`Gateware Release` を手動実行する(既定では Release も docs/ への配置もせず、
成果物は artifact から取れる。`seed` も指定できる)。

## ビルド・書き込み(ボード入手後)

```sh
python3 retrocastx_stream.py --build            # bitstream生成
openFPGALoader -b colorlight-i5 build/colorlight_i5/gateware/colorlight_i5.bit   # SRAMへロード(揮発)
openFPGALoader -b colorlight-i5 -f build/... # SPIフラッシュへ書き込み(元のLED受信カードFWは事前に --dump-flash で退避推奨)
```

## メモ(調査結果より)

- i5 の SODIMM エッジは約100本のI/OがバッファなしでFPGA直結(5A-75Bと違い改造不要)
- ピクセルクロック(TVP7002のDATACLK、最大~80MHz)は**クロック対応ピン(GPLL入力)**に
  割り当てること。拡張基板のピン引き出しとBG381ピンアウトの照合が必要(未実施)
- GbE PHY は RGMII。LiteEth の `LiteEthPHYRGMII` を使用(litex-boards の colorlight_i5 ターゲット参照)

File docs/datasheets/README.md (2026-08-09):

# データシート置き場

メーカー配布のPDFは**再配布可否が不明なのでコミットしていません**(`.gitignore` 済み)。
必要なときは各自で入手して、このディレクトリに同じ名前で置いてください。

| ファイル | 内容 | 入手元 |
|---|---|---|
| `tvp7002.pdf` | TI TVP7002 (ビデオADCフロントエンド) | https://www.ti.com/product/TVP7002 |

## メモ

TVP7002について、この資料から確認した内容はコードのコメントに書いています。
特に同期処理まわりは実測と食い違う点があるため、根拠を残すようにしています。

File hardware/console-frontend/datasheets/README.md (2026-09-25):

# データシート置き場(小亀基板)

メーカー配布のPDFは**再配布が許諾されていないためコミットしていません**(`.gitignore` 済み)。
必要なときは各自で入手して、このディレクトリに下表の名前で置いてください。
`main.ato` / `parts/_mech/mech.ato` のコメントはこの名前で参照しています。
扱いの方針はメイン基板の `hardware/adc-frontend/datasheets/README.md` と同じです。

| ファイル | 内容 | 入手元 |
|---|---|---|
| `MJ-373-4B_Marushin_MiniDIN4.pdf` | マル信無線電機 MJ-373/4B(ミニDIN 4ピンジャック = S端子、基板取付)。**このPDFのPCB穴図から `parts/_mech/MJ373_4B.kicad_mod` を自作した** | モモハラ電機部品 [図面PDF](https://www.mepc.jp/store/pdf/est/drawing/MJ-373-4B.pdf) / 千石電商・マルツの商品ページ |
| `ts5a23159.pdf` | TI TS5A23159(2ch SPDT アナログスイッチ)。U1。ピン番号と真理値表(SCDS201H Table 2)の根拠 | [TI 製品ページ](https://www.ti.com/product/TS5A23159) / LCSC [C42751](https://www.lcsc.com/product-detail/C42751.html) |
| `RCA-105.png` | RCA-105(RCAジャック、右アングル、2端子)。**この図面から `parts/_mech/RCA105.kicad_mod` を自作した**(嵌合面からpad1=4.80 / pad2=8.30、スロット2.30×1.50 と 1.00×2.30) | AliExpress の商品ページの画像(例: [1005006152724809](https://ja.aliexpress.com/item/1005006152724809.html))。出品元ごとに寸法が違うことがあるので**買った現物で実測する** |
| `emzt6.8e.pdf` | ROHM EMZT6.8ET2R(4ch コモンアノード ESDアレイ) | LCSC [C510333](https://www.lcsc.com/product-detail/C510333.html) |

ミニDIN4のランドは**メーカー図面から画像解析で実測**して確定しました
(φ1.2×4 が x=8.5/11.0・y=±3.25、シェル用スロット 2.8×0.8 が (4.7,0) と (5.5,±6.85)、
原点=嵌合面)。**メイン基板のミニDIN8(MJ-373/8B)と同じハウジング枠**です。

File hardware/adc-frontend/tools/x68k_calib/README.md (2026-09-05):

# X68000 校正パターン FD イメージ

ADC(TVP7002)のゲイン・オフセットを合わせるためのテストパターンを、
**Human68k を介さずフロッピーのブートセクタから直接起動**して表示する。

XEiJ で動作確認済み(2026-09-02)。

## 作る / 動かす

```sh
make            # calib.xdf (1,261,568バイト = 2HD の生セクタ列) を作る
make run        # XEiJ で FD0 から起動して確認
make check      # ツールチェーンのパスが通っているかだけ見る
```

ツールチェーンは `X68000_MSX_Simulator` と同じ流儀。ソースは UTF-8 で管理し、
HAS060 が要求する CP932 へ変換したシャドウを `build/` に作ってからアセンブルする。
パスは `~/.human68k.mk` か `local.mk` で上書きできる。

```
calib.has --(CP932変換)--> build/calib.has --(run68 HAS060.X)--> build/calib.o
          --(run68 hlk.x)--> build/calib.x --(mkxdf.py)--> calib.xdf
```

## 画面の構成(512x512 / 65536色)

| 行 | 内容 | 目的 |
|---|---|---|
| 0-63 | グレー32段(各16px幅) | ゲイン・オフセットの同時校正 |
| 64-127 | 赤32段 | R チャンネル単独 |
| 128-191 | 緑32段 | G チャンネル単独 |
| 192-255 | 青32段 | B チャンネル単独 |
| 256-319 | 1px幅の白/黒縦縞 | ドット復元(逆フィルタ)の検証 |
| 320-383 | 2px幅 | 同 |
| 384-447 | 4px幅 | 同 |
| 448-511 | 左半分白 / 右半分黒 | 白レベルと黒レベルの基準 |

65536色モードは 1ワードが `GGGGG RRRRR BBBBB I` なので、**パレットを介さず
5bit×3 を直接指定できる**。階調 n は `(n<<11)|(n<<6)|(n<<1)`(I=0)で、
X68000 本来の32階調をそのまま出せる。

## 読み方

| 見えるもの | 意味 |
|---|---|
| 階調の**抜け**(コードが飛ぶ) | ゲインが高すぎる |
| 階調の**重複**(隣接段が同じコード) | ゲインが低すぎる |
| 上端だけ重複 | クリップしている |
| 32段が32コードに載る | **ロスレスが成立している証拠** |

★このモードは 768x512 のテキスト画面と **pll_div が違う**。Viewer の
「→ 適用」(実測 fH から htotal を算出)か「自動調整」で合わせ直すこと。

## ブートセクタとして守るべき制約

IPL ROM は「論理セクタ0の 1024 バイトを `$002000` へ読み、そこから実行」
するだけなので、以下は破ると黙って動かなくなる。`mkxdf.py` が機械的に検査する。

- **先頭命令は BRA.B / BRA.W**(先頭バイトが `$60`)
- **1 セクタ(1024B)以内**。超えるなら自分で追加セクタを読む処理が要る
- **再配置が無いこと = 完全に PC 相対で書く。** HLK の既定ベースは `$002000`
  ではないので、絶対アドレスのラベル参照が残ると壊れる。ハードウェアアドレス
  (`$C00000` 等)は即値なので対象外
- **実行開始が先頭と一致していること**

## 出典

- [X68000 Human68Kを使わずにプログラムを実行する](https://zenn.dev/morian/articles/ab313ec56c4c4f) — IPL の仕様
- [x68000-dev-guide / graphics.md](https://github.com/JC-000/x68000-dev-guide/blob/master/docs/graphics.md) — GRBi ビット配置、`_CRTMOD` モード表、GVRAM
- [X68k/IOCS - Data Crystal](https://datacrystal.tcrf.net/wiki/X68k/IOCS) — `_CRTMOD`=$10 / `_G_CLR_ON`=$90
- [XEiJ コマンドラインパラメータ](https://stdkmd.net/xeij/parameter.htm) — `-fd0=` / `-boot=fd0`

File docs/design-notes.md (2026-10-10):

# 設計メモ

実装を読んでも分からない「なぜそうなっているか」と、追いかけて分かったことを残す。
TODO.md が「次にやること」、こちらが「決着した知見」。

---

## 測定系を先に疑う

このプロジェクトで何度も同じ形で止まった。**「効かない」「壊れている」という観測は、
測定系の欠陥でも全く同じ形で出る。** 実測値を根拠に議論する設計なので、道具が間違って
いると全部が狂う。

実際に踏んだもの:

| 落とし穴 | 症状 | 正しい理解 |
|---|---|---|
| LINEパケットの `ts` の定義 | 隣接行の差が htotal にならず「同期が動いている」と誤読 | `ts` は**ライン先頭 + offset_px**(断片ごとに正しいサンプル時刻を持たせるため)。比べるなら offset を引く |
| entry 変換の式 | 全行が不一致に見えた | `offset_px`/`count_px`[画素] → entry(2画素)は、末尾が `(offset + count - 1)//2` |
| SIMの `hs_offset` | 全画素が1ずれ、不具合と誤認 | RGBは1段・HSOUT/VSOUTは2段のレジスタで受けるので、駆動側が置いた画素と取り込みの x に固定のずれがある。SIMでは `hs_offset=1` で打ち消す |
| A/B比較の交絡 | 「範囲が FIFO段数ぶん遅れる」という誤った結論 | 全ライン送信モード(key 0x30)は送出負荷が60倍違い、FIFOの滞留状態が変わる。**同条件を2回取った自己一致率**を先に出して、ばらつきの下限を示すこと |
| `cap_drops` の読み方 | 42289という値を見て「FIFOが溢れている」と誤読 | 購読していない間は誰もFIFOを抜かないので当然溢れる(92.4%)。**動作中は0**。読むなら購読しながら時間差で2回 |
| 手書きのテストパケット | 「Windowsのパケットが届いていない」と誤読 | 自作の SUBSCRIBE が22バイトだった(本物は16)。ボードは長さを見るので無視される。**プロトコルは実装(`proto.pack_*`)を使う** |
| 自分のブロードキャストの回り込み | 受信種別の CONFIG を「ボードの応答」と誤読 | ブロードキャストで送ると自分にも返ってくる。送信元IPで区別する |
| ファイアウォール(Windows) | Pythonテストが受信できないのを「経路の問題」と誤読 | 受信の許可ルールは**実行ファイル単位**。python.exe にルールが無ければ落ちる。Viewer には有る |
| **再ビルド直後の初回起動**(Windows) | 最初の7秒ボードから何も返らず、「ARP学習が効いていない」「Wi-Fi併用でブロードキャストが逃げた」と2つ誤診した | 新しい実行ファイルには**ローカルネットワーク通信の許可ダイアログ**が出る。許可するまで通信できない=数秒待たされるのが正常。判定するなら2回目の起動で見る |
| 他マシンでの確認中に購読した | 相手側が `waiting for stream` になり、原因を延々と誤って探した | **購読先はボードに1つだけ**。他マシンで確認している間は絶対に購読しない |
| `clocks/line`(TVP reg 39h:3Ah)の単位 | 1820でロックしているのに410と出て「H-PLLが外れている」と誤報した(判定式を書いた本人が踏んだ) | **DATACLKではなく内部基準クロック(約6.5MHz)で数えている**。`fH = 基準 / clocks per line` なので 6.44M/15699 = 410 が正解。H-PLLのロックは `pll_divide × fH` がDATACLKになるかで見る |
| CONFIGのユニキャストが届かない | 新しく焼いたファームで全キーが「応答なし」になり、**書き込みが失敗したと誤診**した | ボードとPCでサブネットが違うと、ユニキャストはデフォルトゲートウェイへ流れて着かない。`--board 255.255.255.255` なら通る。`discover` はL2ブロードキャストなので動いてしまい、勘違いを誘う(`cfg.py` の docstring に既出。**書いてあったのに踏んだ**) |
| 新旧ファームの判定に対照を取らなかった | 「新キーが応答しない=旧ファームが動いている」と結論したが、**旧キーも応答していなかった**(=通信の問題) | 「新しい機能が無い」を主張するときは、**必ず既存の機能が応答することを同時に示す**(陽性対照) |

いま残してある道具は自己検算を持たせてある。`span_check.py` は起動時に
`算術の自己検算: OK` を出す。

### 合わせ込みは既知の点を2つ以上使う(1つだと符号の誤りが「オフセット」に化ける)

NTSC復調で V(R-Y)軸の符号を逆に書いていた。**1色だけで合わせていたら、
「色相オフセットが要るのだな」で片付いて気づけなかった。**

実際に踏んだ手順(2026-08-14):

1. PS2起動画面の ○=赤 / △=緑 という**既知の2色**に対し色相を掃引した
2. どの回転でも**両方は同時に合わなかった**。2色の開きが 149.8°(本来240°)
3. **回転では2色の開きは変わらない**ので、これは回転で説明できない誤り
4. V を反転すると開きが 200.4° になり、○の誤差も -85.7° → -1.0° に落ちた

一般化すると: **回転(オフセット)は「点の間の関係」を変えない。** だから
関係が合わない時点で、オフセットでは直らない種類の誤りが確定する。1点しか
無いと必ずオフセットで合ってしまい、誤りが隠れる。

回帰試験(`tests/test_ntsc.py`)は合成信号で**必ず6色**を通し、さらに
「符号を逆にした信号ではどう回しても合わない」ことまで確かめる
(そこまでやらないと、常にPASSする無意味な試験になっていても気づけない)。

### syncdet(TVP reg 14h)は「信号が来ているか」の判定に使えない

実測(2026-08-14)。**何も繋がっていない SOGIN_1 / SOGIN_2 を選んでも、
`syncdet` は SOGD=1 / AHS=1 / AVS=1(=0x6D)を返す。** 浮いた入力で
SOGスライサが自己発振するためと思われる。これを信号の有無に使うと必ず誤判定する
(実際、コンポジットが繋がっているのに「msx」と自動判定した)。

使えるのは **fH(key 0x58)の安定性**。同じ実測:

```
SOG=_1 未接続       fH = 28309 → 29529 Hz   単調に漂う
SOG=_2 未接続       fH = 29766 → 30734 Hz   単調に漂う
SOG=_3 コンポジット fH = 15734 → 15733 Hz   収束して動かない
```

未接続は「範囲外の値をゆっくり漂う」、本物は「規定値に収束して動かない」という形で
必ず分かれる。**2回読んで一致するか**を見ればよい。入力MUXを切り替えてから
fH が落ち着くまで**約3秒**かかる。

そして**陰性対照を必ず取ること**。`videoin auto` は未接続のはずの SOGIN_1 を
先に測り、そこが「安定」と出たら判定を中止する。判定器が壊れているときに
それらしい答えを返す方が、答えないより悪い。

### チャネルに同期パルスが本当に載っているかを確かめる方法

「絵は出ているのに同期が無い」ように見えるとき、クランプの効き方を疑うのか
信号そのものが無いのかを、オシロ無しで切り分けられる。

**クランプ窓(reg 05h/06h)を動かして、基準がどう動くかを見る。**

    clamp_start=200(バースト後のバックポーチ)  → バックポーチが基準レベルに座る
                    (230 は実測で映像の頭に食い込んだ。composite-video-plan.md の訂正参照)
    clamp_start=50 (同期チップの上)             → 同期チップが基準レベルに座る

本物の同期パルスがあれば、この2条件で**同期チップ域とバックポーチ域の差が
40 IRE ぶん(粗ゲイン0.5倍なら約37コード)入れ替わる**。信号に同期が無ければ
どちらも同じ値のままで、差はノイズぶん(数コード)しか動かない。

クランプはDCレベルを動かすだけでライン内のAC成分を消さないので、
**「ブランキング期間が数コード以内でフラット」なら、その時点で同期もバーストも
その信号には載っていない**と断定してよい。

## 原因の段を挟み込む(3段の窓)

行欠けの原因特定に効いた手法。データが通る各段に窓を作り、同じ行の値を突き合わせる。

```
pixドメイン(key 0x32)  push した瞬間の ln_first/ln_last の生値
FIFO出口  (key 0x34)  pop した瞬間の先頭の {row, x_lo, x_hi}
電線                   実際のパケットの offset_px/count_px
```

このときの結果は「pixは正しい / FIFO出口も正しい / 電線だけ違う」で、**原因の段が
一意に決まった**。片方だけ見ていると、どちらがずれているのか永久に決まらない。

## 行欠け/横ずれの原因(解決済み)

症状は2つに見えていたが原因は1つだった。

- 当初: 全幅の明るい横線の直後3行が2サンプル早く取り込まれる(横ずれ)
- 範囲計算の整合性を直した後: 全黒行の直後の数行がまるごと欠ける

原因は**送信側でヘッダの値の取り方が揃っていなかったこと**。

```
row / ts / frame  送出開始時にFIFO先頭から直接スナップショット
offset_px         先頭を毎サイクル追いかける2段レジスタ経由  ← これ
```

両者が同じFIFOエントリを指す保証がなく、範囲だけが `fifo_depth` ライン遅れて乗って
いた(depth 4→4ライン、8→8ライン の2点で確認)。内容のある行が空(`count_px=0`)で
送られれば行が欠け、隣の行の範囲が付けば絵が横にずれる。

**修正**: 範囲も row/ts と同じ瞬間に先頭からラッチし、派生値(断片数・長さ)は次の
サイクル(FSMの `LPREP` 状態)でそのラッチ値だけから作る。同一エントリ由来が構造的に
保証される。組合せ経路を短く保つための段分けは維持した(組合せで作ると sys が
42.4MHz まで落ちた実績がある)。

**教訓**: 同じエントリから来るべき値を別の経路で取ってはいけない。段を分けるなら
「どの段のどのエントリから出た値か」を揃える。パイプラインの深さを合わせるだけでは
足りず、**同じ読み出し操作から取る**必要がある。

## 否定された筋(記録)

同じ道を二度通らないために残す。いずれも実測で否定した。

- **DATACLKの位相 / H-PLL / 電源(VCOのsupply pushing)**
  LINEパケットの `ts` から `offset_px` を引いた隣接差が**全524箇所で htotal と一致**。
  HSOUTとDATACLKの関係は1行も動いていない。**基板の設計変更は不要**。
  当初 TODO で最有力候補としていた筋で、PCB の電源分離を疑ったが、そちらではなかった。
- **メタFIFOの溢れ**: 動作中の `cap_drops` は0。送出は最悪(全ライン送信)でも
  ライン周期1587サイクルのうち562サイクルしか使わない。
- **面(face)の追い越し**: `nface` を8→16にしても症状は変わらない。
- **キャプチャの非黒判定**: pixドメインの窓で、push 時点の値が内容と完全一致。
- **受信側の配置**: `assembler.rs` は `offset_px` を行ごとに絶対位置として反映している。
- **`recv_from` の syscall律速**: 「受信スレッドが27000パケット/秒に届かない」と見て
  いたが違った。NICの受信リングが既定256で溢れていただけで、2048にしたら
  35,600 pkt/s を lost 0.0013% で捌く。詳細は下の「受信の取りこぼしは…」を参照。

## nface / fifo_depth をなぜ既定のままにするか

`nface=8` / `fifo_depth=4`(`assert nface >= fifo_depth + 2`)。行欠けを追う過程で
16/8 に振ったが、原因は別だったので大きくする理由が無い。

深くしない方がよい理由:

- 実測で耐性が要る場面が無い。通常モードも全ライン送信モードも `cap_drops` は0
- 滞留が深いほどキャプチャ→送出の遅延が増える
- **滞留が深いほど「別エントリを参照する」種類のバグの被害が大きくなる**。実際、
  depth を深くしたら症状が4ライン→8ラインに悪化した。浅い方が異常に気づきやすい

将来深くする必要が出たら、根拠は `cap_drops`(key 0x33)で測れる。

## 受信の取りこぼしは NIC の受信リングだった(解決 2026-08-10)

**PC側の準備として必須**: Windows の Intel NIC は `受信バッファー`(受信記述子リング)の
既定が **256** で、これが RetroCastX のパケットレートに全く足りない。

    Set-NetAdapterAdvancedProperty -Name 'イーサネット' -RegistryKeyword '*ReceiveBuffers' -RegistryValue 2048

256 → 2048 にしただけの実測(同じ機械・同じ線・同じビットストリーム):

    間引き2(1/3, 102Mbps) / 受信バッファー 256   lost 1.7%      audio underruns 576
    間引き0(等倍, 316Mbps) / 受信バッファー 2048  lost 0.0013%   audio underruns 0
                                                 (23 / 1,727,115、約35,600 pkt/s)

**`SO_RCVBUF` を大きくしても効かない理由**: 捨てているのはソケットバッファではなく
**その手前のNICドライバのリング**。64MBのソケットバッファはリングの下流なので、
リングで溢れた分には触れない。256エントリは 35,600 pkt/s では**約7ms分**しかない。

**層を決める測り方**(これで一発で分かる):

    Get-NetAdapterStatistics -Name 'イーサネット' | fl ReceivedDiscardedPackets,ReceivedPacketErrors

| 見えたもの | 意味 |
|---|---|
| errors ≒ 0 かつ **discards が大きい** | フレームは正しく受けたが置き場所が無い = **リング溢れ**(このケース。7 と 220,680) |
| errors が増える | 物理層/ケーブル/リンク速度 |
| どちらも0なのに lost が出る | アプリまで届いている = ソケットバッファか受信スレッド。`netstat -s -p udp` の受信エラーを見る |

**「間引き」は対策になっていなかった。** 落ちるのはバーストで起きるので、平均帯域を
1/3にしてもリングは溢れる(実際 102Mbps でも 1.7% 落ちた)。等倍に戻してよい。

**否定された筋**: 「`recv_from` が27000回/秒に届かない(syscall律速)」は誤りだった。
リングを増やしたら 35,600 pkt/s を取りこぼしなく処理できている。受信スレッドを
複数にする案・キュー操作をまとめる案は**不要**。

## 実機を動かすときの準備

### ビットストリームは SRAM とフラッシュで別物

    openFPGALoader -c cmsisdap file.bit                 SRAM。電源で消える
    openFPGALoader -c cmsisdap --write-flash file.bit    SPIフラッシュ。残る

SRAMにしか書かずに作業を続けると、ボードの電源が入り直した時点で**フラッシュに
入っている古いビットストリームに戻る**。実際これで修正済みの不具合が再発し、
同時にネットワークも切れていたためネットワークだけの問題と誤診した。
実機で確認したい変更は、確認が済んだらフラッシュに書く。

### Viewer は宛先を指定せずに起動する

`--board` を付けない(既定)と SUBSCRIBE をブロードキャストで送る。ボードは
SUBSCRIBE の**送信元アドレスとポート**を覚えてそこへ返すので、Mac 側に
ボードのサブネットのアドレスは要らない。

    ./target/release/retrocastx-viewer          ← これだけでよい

`--board 192.168.10.50` を付けるとユニキャストになり、Mac に 192.168.10.0/24 への
経路が必要になる。`ifconfig en0 alias 192.168.10.1 ...` はそのための細工だが、
`ifconfig` は永続しないので Mac を再起動するたびに消える。**指定しなければ不要。**
ユニキャスト指定で3秒間応答が無ければ、Viewer はブロードキャストへ自動で落ちる
(逆に昇格はしない。宛先サブネットへの経路が必要になるため)。

なぜサブネットが違っても届くのか、と**どこまで成り立つのか**:

`LiteEthUDPIPCore` は `netmask`/`gateway_ip` を持つが既定は `None` で、このSoCも
渡していない。無効なら宛先IPを**そのままARPで引く**(`liteeth/core/ip.py:167-173`)。
だから同じL2セグメントに持ち主がいれば届く……**相手がARPに応答すれば**。

**ここがOSによって違う。** macOS/BSD は、送信元が別サブネットのARP要求にも応答する。
**Windows は応答しない**(strong host model)。そのため

    Mac(192.168.11.21)   ← ボードのARPに応答する    → 動く
    Windows(192.168.11.35) ← 応答しない              → ボードは送れない

**macOS だけで検証するとこの違いを見落とす。** 実際、design-notes に
「LiteEth にサブネットマスクもゲートウェイも無いのでサブネットが違っても届く」と
断定して書いてしまい、Windows で数時間迷った。

間にルータがある場合も成立しない(ルータはARPを転送しない)。

### ボードのARPキャッシュは2エントリしかない

`LiteEthUDPIPCore(..., arp_entries=1, ...)` が既定で、`LiteEthARPCache` は
`max(entries, 2)` なので実質2エントリ。この環境では3つのIPが関わる:

    192.168.10.1    ANNOUNCE の既定宛先(HOST_IP)
    192.168.11.21   Mac
    192.168.11.35   Windows

**2エントリで3つを回すので常に追い出しが起きる。** しかも Windows は再学習のための
ARPに応答しないので、一度追い出されると復帰しない。「さっきまで動いていたのに
動かなくなった」「電源を入れ直しても直らない」という捉えにくい形で出る。

いまは前段に学習した表(`ArpLearner`、次節)が入り、そこで答えられる相手はこの
キャッシュまで来ない。本物のキャッシュに残るのは**こちらから先に送る相手**
(ANNOUNCE の初期宛先など)だけなので、`arp_entries=4` にしてある。

**当座の回避(2026-08-10まで使っていた。いまは不要)**: Windows 側にボードと同じ
サブネットのアドレスを足す。同一サブネットになればARPが素直に成立する。

    New-NetIPAddress -InterfaceAlias 'イーサネット' -IPAddress 192.168.10.35 -PrefixLength 24

これを消すときの注意: **手動アドレスを足すとインターフェースがDHCPを使わなくなる**
ことがある。実際、消したあと DHCP が取れず 169.254 になった。
`Get-NetIPInterface -InterfaceAlias 'イーサネット' | fl Dhcp` で確認し、
必要なら `Set-NetIPInterface -InterfaceAlias 'イーサネット' -Dhcp Enabled`。

**本筋の対策(実装済み・Windows実機で確認済み 2026-08-10)**: 受信したパケットから
相手のMACを学習する。次節を参照。**この回避は不要になった。**

### 受信パケットからMACを学習する(gateware/retrocastx_net.py)

こちらへ向けて来たパケットの「イーサネット送信元MAC + IPヘッダの送信元IP」を覚え、
宛先MACの解決にそれを使う。**SUBSCRIBE を受けた瞬間に相手のMACが分かるので、ARPの
往復自体が不要になる。** 相手がARPに応答しない環境でも返せる。

**どこに挟んだか。** LiteEthのARPキャッシュ(`LiteEthARPCache.update`)へ流し込む
のが素直に見えるが、この口は `LiteEthARPTable` のFSMが既に駆動しているので外から
足せない(migenの多重ドライバ)。キャッシュ自体も学習の置き場所に向かない:

- 書き込みがラウンドロビンで、同じIPを畳まない。同一IPの重複エントリができ、検索は
  先に見つかった側(=古いMAC)を返しうる
- 1秒ごとに全消去する。ただし消去タイマは**検索でもリセットされる**ので、映像が
  流れている間は実質消えない ─ 「消えるときだけ消える」読みにくい挙動になる

そこで **IP TX から見た「ARPテーブル」の位置に自前の表(`ArpLearner`)を差し込んだ**。
学習済みなら即答し、未知なら本物のARPテーブルへ委譲して応答を中継する。表は4エントリ、
IPで畳む(同じIPならMACだけ更新)。LiteEth本体は無改造 ─ `gateware/litex-src` は
`litex_setup.py` で取ってくるものでリポジトリに入っておらず、パッチを当てても残らない。
そのため `LiteEthUDPIPCore` の構成(MAC + ARP + IP + ICMP + UDP)だけを
`RetroCastXUDPIPCore` として持ってきている。

**何から学習するか(絞る理由)。** `LiteEthIPRX` は `with_broadcast=True` で宛先IPを
問わず通すので、そのまま学習させるとLANのブロードキャスト/マルチキャスト
(mDNS/SSDP/NetBIOS)で狭い表が埋まり、肝心の購読者が追い出される。学習するのは
**こちらへ向けられたものだけ**に絞ってある:

    自IP宛のIPパケット          ping等も含む(ICMP応答もARP無しで返せる)
    自UDPポート宛のUDPパケット   SUBSCRIBE/CONFIG。既定ではブロードキャストで来る
    自IP宛のARP                 LiteEthARPRX が自IP宛だけを通す

**組合せ経路にしてはいけない。** 学習の出力を組合せでARPの表につなぐと
「IPヘッダのレジスタ → ICMP/UDPのデコード → UDP RXのFSM → 表の比較 → 書き込み
イネーブル」が1サイクルの経路になり、実測22.9ns(sys 45MHz = 22.2ns に対し未達、
nextpnr 43.6MHz)。**1段レジスタを挟んで解決**(sys 54.7MHz PASS、
LUT4 11196 = 46%、DFF 6737 = 27%。レジスタを挟んだ方がLUTも減った)。
学習が1サイクル遅れても誰も困らない。**論理を足したら sys のクリティカルパスを
見る** ─ 範囲計算の段分け(42.4MHz)、CONFIG応答の If/Elif 連鎖(38〜44MHz)に続く
3例目。いずれも「受信/設定の経路から広いマルチプレクサや比較器へ組合せで入る」形。

**検証**: `gateware/sim_arp.py`(実機不要)。応答しないARPテーブルを差し込んで
「相手がARPに応答しない」状況を再現し、SUBSCRIBE相当を1つ受けるだけでARPを一度も
引かずにユニキャスト解決できること、IPで畳むこと、溢れたら古い順に使い回すこと、
本物のARPの応答待ち(最悪800ms)の間も学習を取りこぼさないことを確認している。

**simの範囲外**: RXへのタップ(`ip.rx` / `udp.rx` / `arp.rx`)はスタブで置き換えて
いるので、LiteEthの実際の信号の並びまでは確かめていない。根拠は「Depacketizer は
ヘッダを `sr` に載せたままパケット分保持し、ヘッダ由来のフィールドはそこから
組合せで出る」というLiteEthの実装(`liteeth/packet.py`)で、ビルドが通ることで
属性名の存在は確認できる。**ここが違っていたときの症状は key 0x40 が増えないこと。**

**実機の結果(2026-08-10)。これで確認できたと言える根拠**:

Windows(`イーサネット` に `192.168.11.35/24` だけ。`192.168.10.35` は削除済み =
ボードとは別サブネット)から Viewer を `--board` なしで起動し、**532フレーム /
55.5fps / 314〜363Mbps / lost 1.1% / orphan 0 を受信**(起動から1秒以内に開始。
`--headless 10`)。そのときボードのカウンタは

    表で即答  (0x41)   1,437 → 579,334   約58万回
    ARPへ委譲 (0x42)       5 →       5   **1回も増えていない**

`0x42` が動かないことが決め手。Windows のMACをARPで引く必要があったなら必ず 0x42 が
増え(そして応答が無いので失敗し)、映像は出ない。ANNOUNCE のユニキャスト返信
(`INFO=1`)が届いているのも同じことを示す。Mac(192.168.11.21)からも同様に確認。

**読み方の注意**: `0x43`(最後に学習した相手)は診断ツール自身のパケットで上書き
される。Macから読むと必ず自分が見える。**判定に使うのは 0x41/0x42 の増減**。

**診断カウンタの読み方**: `python3 -m retrocastx.arp_check`

    key 0x40  学習した回数            増えない = 受信から学習できていない
    key 0x41  学習した表で即答した数   増える   = 学習した表で解決している
    key 0x42  本物のARPへ委譲した数    **購読中に**増え続けるなら学習が効いていない
    key 0x43  最後に学習した相手のIP
    key 0x44/0x45  同 MAC(下位4B / 上位2B)

0x42 は購読前でも増える(下記のANNOUNCEの初期宛先を毎秒引き直すため)。見るのは
**購読して映像が流れている間に増え続けないか**。

そもそも応答が1つも返らなければ、それが症状そのもの(受信はできているのに返せて
いない)。

**GETはまとめて投げない。** ボードのCONFIG応答は「1つ分の保留」しか持たない
(`cfg_pending` と `cfg_key`/`cfg_reply_val` が1組)。6キーを連続で投げると応答が
上書きされて落ちる ─ 実機で6キー中1つだけ返らない形で出た。`arp_check` は1キーずつ
送って応答を待ち、返らなかったキーだけ再送する。**他の診断ツールも同様**。

なお **ANNOUNCE の初期宛先 `192.168.10.1` は誰も応答しないことがあり**、
その解決は8回×100ms=最悪800msかけて失敗する。この間IP TXは止まるが、購読前なので
映像には影響しない(SUBSCRIBE を受けた時点で ANNOUNCE の宛先は送信元へ切り替わる)。

帯域の心配は要らない。ブロードキャストになるのは Viewer が送る側だけ。

    SUBSCRIBE(keepalive)   Viewer→ボード  ブロードキャスト  約40B × 0.5回/秒
    CONFIG                 Viewer→ボード  ブロードキャスト  操作時だけ
    MODE / LINE / AUDIO    ボード→Viewer  **ユニキャスト**   約500Mbps

映像はユニキャスト(`retrocastx_stream.py` の `dst_ip, sub_ip`)なので、スイッチは
MAC学習によりMacのポートにしか流さない。

**未対応の懸念**: `255.255.255.255` をどのインターフェースから出すかはOSが選ぶ。
Wi-Fiと有線が両方有効な環境では、ブロードキャストがWi-Fi側へ出てボードに届かない
可能性がある(いまはソケットを `0.0.0.0` に束縛しOS任せ)。実害が出たら、
インターフェースごとに送信元アドレスを変えて総当たりし、応答があったものを使う
形にする。有線1本の環境では問題にならないので後回しにしている。
**まだ実害は観測していない**(2026-08-10に「Wi-Fi併用のせいで最初の7秒出なかった」
と一度誤診したが、原因は再ビルド直後の許可ダイアログだった。下の表を参照)。
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

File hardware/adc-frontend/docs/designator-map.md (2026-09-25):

# デジグネータ対応表

デジグネータは **main.ato の宣言順**に振ってある。上から下へ読むとほぼ機能ブロック順に
番号が並ぶ。振り直しは `tools/renumber_designators.py` を実行するだけ
(`ato build` 後に走らせる。`keep_designators`が既定trueなので以後は維持される)。

**手組みの試作機(V0)は「V0」列の番号**なので、実機の写真やオシロのメモを読むときは
この表で読み替えること。V0列が空欄のものは後から追加した部品。

## 仕組み
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

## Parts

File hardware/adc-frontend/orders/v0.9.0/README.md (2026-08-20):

# RetroCast X 手半田実装 発注リスト (v0.9.0, 2枚分)

`tools/gen_order_bom.py` が生成。**手で編集しない**(再生成で消えます)。
元データは `build/builds/default/default.bom.csv` と `tools/order_sourcing.json`。

## アップロード方法

| 販売店 | ファイル | 手順 |
|---|---|---|
| DigiKey | `digikey-bom.csv` | myLists → BOM Manager → Create New BOM → アップロード → 列を対応付け → 一括カート投入 |
| Mouser | `mouser-bom.csv` | BOM ツール → 新規 BOM → アップロード → 列を対応付け → 一括カート投入 |
| LCSC | `lcsc-bom.csv` | BOM Tool にアップロード(LCSC 品番で直接照合) |

どちらも**アップロード時に列の対応を画面で選べる**ので、ヘッダ名が違っても通ります。
照合は製造元品番(MPN)で行われます。

## 数量について

`Quantity` には**手半田用の予備を含めて**あります(0402 は +20%/最低+10個、
安価な IC は +2個、高価な部品は予備なし)。素の必要数は下表の「基板1枚」列です。

## ★発注前に必ず確認すること

| 部品 | 品番 | 注意 |
|---|---|---|
| C1 | CL21A106KAYNNNE | ★DigiKey 在庫切れ(2026-08-19 利用者確認)のため LCSC 発注へ移した。元の選定品(Samsung CL21A106KAYNNNE)がそのまま在庫2,758,420個 $0.0795@50。DigiKey で買うなら Murata GRM21BR61E106KA73L か YAGEO CC0805KKX5R8BB106 (いずれも 10uF/25V/X5R/0805/±10% で等価、在庫あり) |
| C42 | CL05B102KB5NNNC | FH(風華)は DK/Mouser 扱い無し。同容量・同耐圧の Samsung へ |
| C45 | CL05B472KB5NNNC | 同上 |
| C82 | CC1812KKX7RDBB472 | ★2kV 耐圧は必須。LANケーブルはサージや建物間の電位差を拾うため Bob-Smith 終端の ブリッジには 2kV が標準で、耐圧は落とせない。LCSC なら同じ Yageo 品が $0.24@25。DigiKey で買うなら KYOCERA AVX 1812GC472KAT1A($0.49@25、4700pF/2000V/X7R/±10%/1812 で完全同スペック、在庫42,893)が Yageo(154円)より安い |
| D1 | EMZT6.8ET2R | 2026-08-18 データシート確認済。実物は EMD5 で**5ピン**。フットプリントは tools/fix_esd_land.py で ROHM 推奨の5パッド(外側0.4/中央0.3)に作り直したので、リードの載らない裸パッドは無くなった(pad番号=データシートのリード番号) |
| D7 | 1N4148W-7-F | 1N4148W は各社互換。Diodes 版が DK/Mouser とも潤沢 |
| D9 | USBLC6-2SC6 | ★DigiKey 在庫切れ(2026-08-19 利用者確認)のため LCSC 発注へ移した。LCSC は ST 純正が在庫33,840個 $0.1432@10。DigiKey には Slkormicro($0.18) / GOODWORK($0.04) / UMW($0.91) の互換品表示があるが、USB データラインの保護なので**接合容量が効く**(ST は Cj typ 0.8pF I/O-GND)。セカンドソースは容量規定を確認してから使うこと。ST 純正が買えるなら純正で。 |
| J1 | DS1037-15FNAKT76-0CC | ★X68000 用 DA-15(メス/15ピン2列/ライトアングル/スルーホール)。DK/Mouser の DA-15 は取付穴・シェル寸法が異なりフットプリントに合わない。2026-08-18 時点 LCSC 自社在庫 112個 / $0.43 で問題なし |
| J2 | TYPE-C-31-M-12 | いわゆる TYPE-C-31-M-12。DK/Mouser の USB-C は各社独自フットプリント |
| J11 | HR911130A | HANRUN HR911130A。★2026-08-18 時点で調達先が分かれる:
  LCSC   **在庫切れ**(Notify Me のみ、$2.17@10 / $1.92@30)
  JLCPCB Assembly Parts Lib に **5,165個**(Extended、¥401.14@1+ / ¥307.76@31+、Full Reel 31個)
→ v1.0 の PCBA は JLCPCB 側で調達できるので問題なし。2個/枚なので16枚以上なら 31+ の価格帯に入る。
→ v0.9.0 の手半田分は AliExpress で調達する(定番品)。
フットプリントは HanRun HR911105A/HR911130A 系の事実上の業界標準配置(10ピン2列千鳥+LED4+シールド2)なので互換品が多い。公称互換品: LINK-PP LPJG0806FBNL(★使うならピン表の突き合わせが必要)。
★AliExpress で買う場合は内蔵トランス品質のばらつきに注意。10/100 は通っても 1000Base-T でリンクが不安定になる例がある。届いたら1個で先にリンク確認すること |
| LED1 | XL-2020RGBC-2812B | ★Worldsemi WS2812B-2020(C965555)から変更(2026-08-19)。理由は吸湿性ランク:
  WS2812B-2020 MSL 5a → JLCPCB が48時間の焼成(60℃)を要求し追加料金
  XL-2020RGBC  MSL 3  → 焼成不要
JLCPCB は MSL5以上で焼成を要求する。LCSC 在庫も 35,115個→175,745個 と5倍、単価差は $0.074→$0.093 の2セントのみ。WS2812B 互換の1本線プロトコルで 信号割り当ても DI=3/DO=1/GND=2/VDD=4 と同一。★ランドは違う(パッドが x 方向 ±0.92→±0.68 と内寄り)ので基板のフットプリントも差し替え済み。
2020 サイズは DK/Mouser では稀なので引き続き LCSC 調達 |
| R1 | 0402WGF5101TCE | ★DigiKey 在庫切れ(2026-08-19 利用者確認)のため LCSC 発注へ移した。元の選定品(UNI-ROYAL 0402WGF5101TCE)が在庫6,406,000個 $0.0043@100。★USB Type-C の CC1/CC2 プルダウンなので **5.1kΩ±1% は規格上の要求**(Rd = 5.1k で Default USB Power = 5V/500mA〜3A を宣言する)。値を変えてはいけない。DigiKey で買うなら YAGEO RC0402FR-075K1L の在庫が戻るのを待つか同等の1%品 |
| R4 | RC0402FR-0775RL | ★映像の終端抵抗。1% 品を使うこと(75Ω 整合がずれると映像レベルが狂う) |
| R18 | RC0402FR-071K5L | 音声ミキシング用。4本は誤差が揃っている方が左右バランスが良い |
| U1 | TVP7002PZP | ★2026-08-18 調査。**廃番ではない**(TI 製品ページは ACTIVE)。ただし流通在庫が薄く、DigiKey 184個 $12.04 / 工場リードタイム26週 / **Mouser は取扱なし** / LCSC 自社在庫4個。以前『生産終了方向』と書いたが言い過ぎだった(根拠にした TI の PCN は本品種を特定したものではない)。LCSC の Other Suppliers に2,973個あるが EOL 品のブローカー在庫で再マーキングの懸念があるため勧めない。PCBA 用は DigiKey で確保して JLCPCB へ委託送付(または JLCPCB の Pre-Order / Global Sourcing)する。★TVP70025IPZP は後継品ではなく上位互換でもない: 90MSPS/10bit固定/WXGA止まりで $16.56 と高く、ピン配置もレジスタマップも互換の保証が無い |
| U2 | SN74LVC2G17DBVR | ★DigiKey 在庫切れ(2026-08-19 利用者確認)のため LCSC 発注へ移した。LCSC は TI 純正が在庫22,242個 $0.2403@30。DigiKey には UMW の同型番互換品($0.19)がある。5V トレラント入力の シュミットバッファで同期信号の整形に5個使うので、代替を使うなら VIH/VIL のヒステリシス幅を確認すること |
| U5 | TLV75718PDBVR | RICHTEK は DK/Mouser 扱い無し。TLV757P は SOT-23-5 で 1=IN/2=GND/3=EN/4=NC/5=OUT、RT9013 とピン配置一致。1.8V は TVP7002 AVDD 推奨 1.8〜2.0V 内 |
| U7 | CH347F | WCH は DK/Mouser 扱い無し。LCSC / AliExpress / 秋月 で入手 |
| X1 | OT322527MJBA4SL | ★DigiKey は高い(Abracon ASEM1-27.000MHZ-LC-T が471円)。LCSC なら元の選定品が $0.43。DigiKey 内の安価品 ECS-3225MVLC-270-CN-TR($1.16)は**電源1.8〜3.3Vで使えない** (X1 は AZ1117H-3.3 ±2% = 最大3.37V から給電)。1.6〜3.6V の ECS-3225MV 系に 27MHz は無い |
| X2 | X32258MSB4SI | CH347F 用。LCSC で $0.19。DigiKey の 3225 8MHz 在庫品は ABM8AIG-8.000MHZ-1Z-T($1.17)しか無く CL=18pF になるので、元の CL=20pF 品を LCSC で買う方が安くて正確 |
| X3 | OT2JI-111-12.288M | 48kHz x 256fs。DigiKey は Epson SG3225CAN が445円、ECS-TXO-3225MV-122.8-TR でも $2.18。LCSC なら元の選定品が $0.30 |

## 読み替えた部品 (9品目)

元の選定は LCSC 前提なので、DigiKey/Mouser で買える同等品に差し替えています。
**値・パッケージ・耐圧は等価**ですが、発注前に一度確認してください。

| 部品 | 元(LCSC) | 読み替え先 | 内容 |
|---|---|---|---|
| C42 | FH 0402B102K500NT | Samsung Electro-Mechanics CL05B102KB5NNNC | 1nF 0402 X7R 50V MLCC |
| C45 | FH 0402B472K500NT | Samsung Electro-Mechanics CL05B472KB5NNNC | 4.7nF 0402 X7R 50V MLCC |
| D7 | ST(Semtech) 1N4148W | Diodes Incorporated 1N4148W-7-F | 汎用スイッチングダイオード SOD-123 |
| R3 | UNI-ROYAL 0402WGF1002TCE | YAGEO RC0402FR-0710KL | 10k 0402 1% 1/16W |
| R4 | UNI-ROYAL 0402WGF750JTCE | YAGEO RC0402FR-0775RL | 75R 0402 1% 1/16W |
| R5 | UNI-ROYAL 0402WGF2200TCE | YAGEO RC0402FR-07220RL | 220R 0402 1% 1/16W |
| R18 | UNI-ROYAL 0402WGF1501TCE | YAGEO RC0402FR-071K5L | 1.5k 0402 1% 1/16W |
| R28 | UNI-ROYAL 0402WGF2201TCE | YAGEO RC0402FR-072K2L | 2.2k 0402 1% 1/16W |
| U5 | RICHTEK RT9013-18GB | Texas Instruments TLV75718PDBVR | 1.8V LDO SOT-23-5 |

## DigiKey / Mouser では買えない部品 (14品目)

**フットプリントが製品固有**のため代替が効きません。LCSC / AliExpress 等で
別途手配してください。

| 部品 | LCSC | 品番 | 内容 |
|---|---|---|---|
| C1, C2, C3, C4, C5, C7, C60, C63, C67, C68, C71, C75, C76 | C15850 | CL21A106KAYNNNE | 10uF 0805 X5R 25V MLCC |
| C82, C83, C84, C85 | C309511 | CC1812KKX7RDBB472 | 4.7nF 2kV X7R 1812(RJ45 シャーシ-論理GND ブリッジ) |
| D9 | C7519 | USBLC6-2SC6 | USB 2ライン ESD 保護アレイ SOT-23-6 |
| J1 | C77836 | DS1037-15FNAKT76-0CC | D-SUB 15pin(DA-15 2列)メス スルーホール |
| J2 | C165948 | TYPE-C-31-M-12 | USB Type-C レセプタクル 16pin SMD |
| J6 | C7436577 | YTC-A1251-08ABW | 1.25mm ピッチ 8pin SMD コネクタ |
| J11, J12 | C54408 | HR911130A | RJ45 パルストランス内蔵 10/100/1000 スルーホール |
| LED1 | C5349955 | XL-2020RGBC-2812B | フルカラーLED 2020(WS2812B互換, 制御IC内蔵) |
| R1, R2 | C25905 | 0402WGF5101TCE | 5.1k 0402 1% 1/16W(USB-C CC プルダウン) |
| U2, U8, U10, U11, U12 | C10429 | SN74LVC2G17DBVR | デュアルシュミットバッファ SOT-23-6 |
| U7 | C18221627 | CH347F | USB-HS → JTAG+UART ブリッジ QFN-28 |
| X1 | C725995 | OT322527MJBA4SL | 27MHz アクティブ発振器 3.2x2.5mm 4pad 3.3V CMOS |
| X2 | C2682774 | X32258MSB4SI | 8MHz 水晶 3.2x2.5mm 4pad CL=20pF |
| X3 | C20617595 | OT2JI-111-12.288M | 12.288MHz アクティブ発振器 3.2x2.5mm 4pad 3.3V CMOS |

## ★品番指定のない調達品 (2品目) — CSV には入れていません

LCSC 品番を持たないので BOM ツールでは照合できません。**AliExpress 等で手配**します。

| 部品 | 数 | 品名 | 内容 |
|---|---|---|---|
| PG1-PG4 | 8 | バネ付きコンタクトピン(圧入TH, 胴径1.0mm, 基板上高さ約3mm) | ★必須部品。「任意。未実装でも動作する」と書いていたのは誤り(2026-08-19訂正)。SO-DIMM コネクタに JTAG は通っておらず、i5 モジュール底面のテストパッド(TCK/TMS/TDI/TDO)へバネ接触させるこの4本が**基板上の CH347F から FPGA へ届く唯一の経路**。J3(jtag_hdr)は同じネットへの並列引き出しなので単独では i5 に届かない。無い場合は |
| (module) | 2 | Colorlight i5 (ECP5) | SO-DIMM FPGA モジュール本体。AliExpress 等 |

## どこでも買える汎用品 (8品目)

品番を指定する意味が無いのでアップロード用 CSV には**入れていません**
(説明文を混ぜると照合結果が「該当なし」だらけになるため)。秋月・千石・
マルツ等でまとめて買う方が早いです。

| 部品 | 数 | 品名 | 内容 |
|---|---|---|---|
| J3 | 2 | ピンヘッダ 1x6 2.54mm | JTAG。秋月・千石等で可 |
| J4 | 2 | ボックスヘッダ 2x5 2.54mm | 第2映像入力(AUX)。シュラウド付 |
| J5 | 2 | ボックスヘッダ 2x4 2.54mm | S-Video + 音声。シュラウド付 |
| J7 | 2 | ピンヘッダ 2x15 2.54mm | デバッグ |
| J9 | 2 | ピンヘッダ 1x4 2.54mm | Argus |
| J10 | 2 | ピンヘッダ 1x4 2.54mm | OLED |
| J8 | 2 | PLR135/T | S/PDIF 光受信モジュール。秋月電子 109595(150円)。★PLR135/T10 は DigiKey 廃品種・在庫0、代替の PLR237/T10BK も在庫0だったため 形状違いの PLR135/T へ変更。ランドが違うのでフットプリントも差し替え済み |
| H1-H5 | 10 | M2.6 ネジ + スペーサ | 取付穴。基板発注には含まれない |

## 全品目

| 部品 | 基板1枚 | 発注数 | 入手先 | 品番 | 内容 |
|---|---|---|---|---|---|
| C1, C2, C3, C4, C5, C7, C60, C63, C67, C68, C71, C75, C76 | 13 | 36 | LCSC | CL21A106KAYNNNE | 10uF 0805 X5R 25V MLCC |
| C6, C8, C11, C12, C13, C14, C15, C16, C17, C18, C19, C20, C21, C22, C23, C24, C25, C27, C29, C31, C33, C35, C37, C39, C41, C43, C44, C46, C47, C49, C51, C55, C56, C57, C58, C59, C64, C65, C66, C72, C73, C74, C77, C78, C79, C80, C81 | 47 | 113 | DK/Mouser | CL05B104KO5NNNC | 100nF 0402 X7R 16V MLCC |
| C9, C10 | 2 | 14 | DK/Mouser | CL05C220JB5NNNC | 22pF 0402 C0G 50V MLCC |
| C26, C28, C30, C34, C36, C38, C48, C50 | 8 | 26 | DK/Mouser | CL05C330JB5NNNC | 33pF 0402 C0G 50V MLCC |
| C42 | 1 | 12 | DK/Mouser(読替) | CL05B102KB5NNNC | 1nF 0402 X7R 50V MLCC |
| C45 | 1 | 12 | DK/Mouser(読替) | CL05B472KB5NNNC | 4.7nF 0402 X7R 50V MLCC |
| C53, C54 | 2 | 14 | DK/Mouser | CL05B103KB5NNNC | 10nF 0402 X7R 50V MLCC |
| C61, C62, C69, C70 | 4 | 18 | DK/Mouser | CL10A105KB8NNNC | 1uF 0603 X5R MLCC |
| C82, C83, C84, C85 | 4 | 10 | LCSC | CC1812KKX7RDBB472 | 4.7nF 2kV X7R 1812(RJ45 シャーシ-論理GND ブリッジ) |
| D1, D2, D3, D4, D5, D6, D8 | 7 | 16 | DK/Mouser | EMZT6.8ET2R | ROHM 4ch コモンアノード ESD アレイ EMD5(SC-75A) |
| D7 | 1 | 4 | DK/Mouser(読替) | 1N4148W-7-F | 汎用スイッチングダイオード SOD-123 |
| D9 | 1 | 4 | LCSC | USBLC6-2SC6 | USB 2ライン ESD 保護アレイ SOT-23-6 |
| FB1, FB2, FB3 | 3 | 8 | DK/Mouser | MPZ1608S221ATA00 | フェライトビーズ 220R@100MHz 0603 |
| J1 | 1 | 2 | LCSC | DS1037-15FNAKT76-0CC | D-SUB 15pin(DA-15 2列)メス スルーホール |
| J2 | 1 | 4 | LCSC | TYPE-C-31-M-12 | USB Type-C レセプタクル 16pin SMD |
| J6 | 1 | 4 | LCSC | YTC-A1251-08ABW | 1.25mm ピッチ 8pin SMD コネクタ |
| J11, J12 | 2 | 6 | LCSC | HR911130A | RJ45 パルストランス内蔵 10/100/1000 スルーホール |
| LED1 | 1 | 4 | LCSC | XL-2020RGBC-2812B | フルカラーLED 2020(WS2812B互換, 制御IC内蔵) |
| R1, R2 | 2 | 14 | LCSC | 0402WGF5101TCE | 5.1k 0402 1% 1/16W(USB-C CC プルダウン) |
| R3, R32, R33, R34, R35, R36, R37 | 7 | 24 | DK/Mouser(読替) | RC0402FR-0710KL | 10k 0402 1% 1/16W |
| R4, R6, R8, R11, R13, R15, R17, R23, R25 | 9 | 28 | DK/Mouser(読替) | RC0402FR-0775RL | 75R 0402 1% 1/16W |
| R5, R7, R9, R10, R12, R14, R16, R20, R21, R24, R26, R27, R38, R43, R44, R45, R46 | 17 | 44 | DK/Mouser(読替) | RC0402FR-07220RL | 220R 0402 1% 1/16W |
| R18, R19, R22, R39, R40, R41, R42 | 7 | 24 | DK/Mouser(読替) | RC0402FR-071K5L | 1.5k 0402 1% 1/16W |
| R28, R29, R30, R31 | 4 | 18 | DK/Mouser(読替) | RC0402FR-072K2L | 2.2k 0402 1% 1/16W |
| U1 | 1 | 2 | DK/Mouser | TVP7002PZP | ビデオデジタイザ HTQFP-100 |
| U2, U8, U10, U11, U12 | 5 | 12 | LCSC | SN74LVC2G17DBVR | デュアルシュミットバッファ SOT-23-6 |
| U3, U4 | 2 | 6 | DK/Mouser | AZ1117H-3.3TRE1 | 3.3V LDO SOT-223 |
| U5 | 1 | 4 | DK/Mouser(読替) | TLV75718PDBVR | 1.8V LDO SOT-23-5 |
| U6 | 1 | 4 | DK/Mouser | TLV70019DDCR | 1.9V 200mA LDO SOT-23-5 |
| U7 | 1 | 4 | LCSC | CH347F | USB-HS → JTAG+UART ブリッジ QFN-28 |
| U9 | 1 | 2 | DK/Mouser | 1473005-4 | DDR3 SO-DIMM 204pin ソケット |
| U13, U14 | 2 | 5 | DK/Mouser | PCM1808PWR | ステレオ ADC TSSOP-14 |
| U15, U16 | 2 | 5 | DK/Mouser | 24AA025E48-I/SN | 2kbit EEPROM + EUI-48 MAC SOIC-8 |
| X1 | 1 | 4 | LCSC | OT322527MJBA4SL | 27MHz アクティブ発振器 3.2x2.5mm 4pad 3.3V CMOS |
| X2 | 1 | 4 | LCSC | X32258MSB4SI | 8MHz 水晶 3.2x2.5mm 4pad CL=20pF |
| X3 | 1 | 4 | LCSC | OT2JI-111-12.288M | 12.288MHz アクティブ発振器 3.2x2.5mm 4pad 3.3V CMOS |
| J3 | 1 | 2 | 汎用品 | ピンヘッダ 1x6 2.54mm | JTAG。秋月・千石等で可 |
| J4 | 1 | 2 | 汎用品 | ボックスヘッダ 2x5 2.54mm | 第2映像入力(AUX)。シュラウド付 |
| J5 | 1 | 2 | 汎用品 | ボックスヘッダ 2x4 2.54mm | S-Video + 音声。シュラウド付 |
| J7 | 1 | 2 | 汎用品 | ピンヘッダ 2x15 2.54mm | デバッグ |
| J9 | 1 | 2 | 汎用品 | ピンヘッダ 1x4 2.54mm | Argus |
| J10 | 1 | 2 | 汎用品 | ピンヘッダ 1x4 2.54mm | OLED |
| J8 | 1 | 2 | 汎用品 | PLR135/T | S/PDIF 光受信モジュール。秋月電子 109595(150円)。★PLR135/T10 は DigiKey 廃品種・在庫0、代替の PLR237/T10BK も在庫0だったため 形状違いの PLR135/T へ変更。ランドが違うのでフットプリントも差し替え済み |
| PG1-PG4 | 4 | 8 | LCSC | バネ付きコンタクトピン(圧入TH, 胴径1.0mm, 基板上高さ約3mm) | ★必須部品。「任意。未実装でも動作する」と書いていたのは誤り(2026-08-19訂正)。SO-DIMM コネクタに JTAG は通っておらず、i5 モジュール底面のテストパッド(TCK/TMS/TDI/TDO)へバネ接触させるこの4本が**基板上の CH347F から FPGA へ届く唯一の経路**。J3(jtag_hdr)は同じネットへの並列引き出しなので単独では i5 に届かない。無い場合はモジュール底面へ直接ケーブルを半田付けする逃げ道はある。
## 必要寸法(ドリル1.0mm / パッド1.9mm / 2.54mmピッチ x4)
  基板〜モジュール裏の間隙 2.6mm(★ソケット種で変動。実機で測ってから買うのが確実)
  基板上高さ > 2.6mm(接触する) かつ 基板上高さ - 2.6mm <= ストローク(底突きしない)
  → 自由長 3.0〜3.2mm / 全圧縮 2.5mm以下 / 胴径 約1.0mm
## 入手先
  AliExpress  「Spring Loaded Pogo Pin Through Holes PCB Height 3mm」系。高さを3/4/5/6...mm から選べる汎用品で $0.94/10個。設計時に想定していたのはこれ。
  DigiKey     Mill-Max 0984-0-15-20-64-14-11-0 $1.04@1 在庫2,734個。胴径1.09mmは合うが**自由長3.91mm/全圧縮2.90mmで背が高すぎ**、間隙2.6mmでは0.3mm底突きする。他の Mill-Max シリーズで自由長3mm級を探すこと。Harwin P1113CV3 は自由長24mm・推奨穴2.4mmで全く合わない。
  JLCPCB      Assembly Parts Lib に1,211品目あるが、在庫の多いものは D=2mm 系でドリル1.0mmに入らない。
## PCBA に出す場合
★has_part_removed のまま**自分で手半田する**のを勧める。理由:
  1. 高さがこの基板固有のスタックアップに依存し、実測してから選びたい
  2. バネと金メッキが加熱で劣化する。半田が筒内へ吸われるとプランジャが動かなくなる
  3. JLC の在庫品でドリル1.0mm/高さ3mm級に合うものが見つかっていない
どうしても JLC に付けさせるなら、適合品を特定した上で委託(Consignment)する。 |
| H1-H5 | 5 | 10 | 汎用品 | M2.6 ネジ + スペーサ | 取付穴。基板発注には含まれない |
| (module) | 1 | 2 | LCSC | Colorlight i5 (ECP5) | SO-DIMM FPGA モジュール本体。AliExpress 等 |

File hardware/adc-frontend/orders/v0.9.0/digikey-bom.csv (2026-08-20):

Quantity | Manufacturer Part Number | Manufacturer | Customer Reference | Description
113 | CL05B104KO5NNNC | SAMSUNG | C6, C8, C11, C12, C13, C14, C15, C16, C17, C18, C19, C20, C21, C22, C23, C24, C25, C27, C29, C31, C33, C35, C37, C39, C41, C43, C44, C46, C47, C49, C51, C55, C56, C57, C58, C59, C64, C65, C66, C72, C73, C74, C77, C78, C79, C80, C81 | 100nF 0402 X7R 16V MLCC
14 | CL05C220JB5NNNC | SAMSUNG | C9, C10 | 22pF 0402 C0G 50V MLCC
26 | CL05C330JB5NNNC | SAMSUNG | C26, C28, C30, C34, C36, C38, C48, C50 | 33pF 0402 C0G 50V MLCC
12 | CL05B102KB5NNNC | Samsung Electro-Mechanics | C42 | 1nF 0402 X7R 50V MLCC
12 | CL05B472KB5NNNC | Samsung Electro-Mechanics | C45 | 4.7nF 0402 X7R 50V MLCC
14 | CL05B103KB5NNNC | SAMSUNG | C53, C54 | 10nF 0402 X7R 50V MLCC
18 | CL10A105KB8NNNC | SAMSUNG | C61, C62, C69, C70 | 1uF 0603 X5R MLCC
16 | EMZT6.8ET2R | ROHM | D1, D2, D3, D4, D5, D6, D8 | ROHM 4ch コモンアノード ESD アレイ EMD5(SC-75A)
4 | 1N4148W-7-F | Diodes Incorporated | D7 | 汎用スイッチングダイオード SOD-123
8 | MPZ1608S221ATA00 | TDK | FB1, FB2, FB3 | フェライトビーズ 220R@100MHz 0603
24 | RC0402FR-0710KL | YAGEO | R3, R32, R33, R34, R35, R36, R37 | 10k 0402 1% 1/16W
28 | RC0402FR-0775RL | YAGEO | R4, R6, R8, R11, R13, R15, R17, R23, R25 | 75R 0402 1% 1/16W
44 | RC0402FR-07220RL | YAGEO | R5, R7, R9, R10, R12, R14, R16, R20, R21, R24, R26, R27, R38, R43, R44, R45, R46 | 220R 0402 1% 1/16W
24 | RC0402FR-071K5L | YAGEO | R18, R19, R22, R39, R40, R41, R42 | 1.5k 0402 1% 1/16W
18 | RC0402FR-072K2L | YAGEO | R28, R29, R30, R31 | 2.2k 0402 1% 1/16W
2 | TVP7002PZP | TI | U1 | ビデオデジタイザ HTQFP-100
6 | AZ1117H-3.3TRE1 | DIODES | U3, U4 | 3.3V LDO SOT-223
4 | TLV75718PDBVR | Texas Instruments | U5 | 1.8V LDO SOT-23-5
4 | TLV70019DDCR | TI | U6 | 1.9V 200mA LDO SOT-23-5
2 | 1473005-4 | TE Connectivity | U9 | DDR3 SO-DIMM 204pin ソケット
5 | PCM1808PWR | TI | U13, U14 | ステレオ ADC TSSOP-14
5 | 24AA025E48-I/SN | MICROCHIP | U15, U16 | 2kbit EEPROM + EUI-48 MAC SOIC-8

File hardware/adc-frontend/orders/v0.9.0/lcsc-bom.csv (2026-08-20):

Quantity | LCSC Part Number | Manufacturer Part Number | Designator | Description
36 | C15850 | CL21A106KAYNNNE | C1, C2, C3, C4, C5, C7, C60, C63, C67, C68, C71, C75, C76 | 10uF 0805 X5R 25V MLCC
10 | C309511 | CC1812KKX7RDBB472 | C82, C83, C84, C85 | 4.7nF 2kV X7R 1812(RJ45 シャーシ-論理GND ブリッジ)
4 | C7519 | USBLC6-2SC6 | D9 | USB 2ライン ESD 保護アレイ SOT-23-6
2 | C77836 | DS1037-15FNAKT76-0CC | J1 | D-SUB 15pin(DA-15 2列)メス スルーホール
4 | C165948 | TYPE-C-31-M-12 | J2 | USB Type-C レセプタクル 16pin SMD
4 | C7436577 | YTC-A1251-08ABW | J6 | 1.25mm ピッチ 8pin SMD コネクタ
6 | C54408 | HR911130A | J11, J12 | RJ45 パルストランス内蔵 10/100/1000 スルーホール
4 | C5349955 | XL-2020RGBC-2812B | LED1 | フルカラーLED 2020(WS2812B互換, 制御IC内蔵)
14 | C25905 | 0402WGF5101TCE | R1, R2 | 5.1k 0402 1% 1/16W(USB-C CC プルダウン)
12 | C10429 | SN74LVC2G17DBVR | U2, U8, U10, U11, U12 | デュアルシュミットバッファ SOT-23-6
4 | C18221627 | CH347F | U7 | USB-HS → JTAG+UART ブリッジ QFN-28
4 | C725995 | OT322527MJBA4SL | X1 | 27MHz アクティブ発振器 3.2x2.5mm 4pad 3.3V CMOS
4 | C2682774 | X32258MSB4SI | X2 | 8MHz 水晶 3.2x2.5mm 4pad CL=20pF
4 | C20617595 | OT2JI-111-12.288M | X3 | 12.288MHz アクティブ発振器 3.2x2.5mm 4pad 3.3V CMOS

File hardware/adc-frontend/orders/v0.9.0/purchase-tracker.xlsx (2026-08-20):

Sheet: 調達管理
RetroCast X 調達管理 (v0.9.0 / 2枚分) | tools/gen_order_xlsx.py が生成。状態・注文番号・備考は再生成しても引き継がれます
状態 | デジグネータ | 品名/内容 | 発注先 | 品番 | メーカー | 発注数 | 単価 | 小計(円) | 注文番号/日付 | 備考
発注済み | U1 | ビデオデジタイザ HTQFP-100 | DigiKey | TVP7002PZP | TI | 2 | $12.0400 | 4094
未発注 | U9 | DDR3 SO-DIMM 204pin ソケット | AliExpress | 1473005-4 | TE Connectivity | 2 | $9.5900 | 3261 |  | LCSCでも1つ注文してみた
発注済み | U13, U14 | ステレオ ADC TSSOP-14 | DigiKey | PCM1808PWR | TI | 5 | $1.5900 | 1352
発注済み | D1, D2, D3, D4, D5, D6, D8 | ROHM 4ch コモンアノード ESD アレイ EMD5(SC-75A) | DigiKey | EMZT6.8ET2R | ROHM | 16 | $0.1983 | 539
発注済み | C6, C8, C11, C12, C13, C14, C15, C16, C17, C18, C19, C20, C21, C22, C23, C24, C25, C27, C29, C31, C33, C35, C37, C39, C41, C43, C44, C46, C47, C49, C51, C55, C56, C57, C58, C59, C64, C65, C66, C72, C73, C74, C77, C78, C79, C80, C81 | 100nF 0402 X7R 16V MLCC | DigiKey | CL05B104KO5NNNC | SAMSUNG | 113 | $0.0066 | 127
発注済み | R5, R7, R9, R10, R12, R14, R16, R20, R21, R24, R26, R27, R38, R43, R44, R45, R46 | 220R 0402 1% 1/16W | DigiKey | RC0402FR-07220RL | YAGEO | 44 | $0.0061 | 46
発注済み | C26, C28, C30, C34, C36, C38, C48, C50 | 33pF 0402 C0G 50V MLCC | DigiKey | CL05C330JB5NNNC | SAMSUNG | 26 | 未確認
発注済み | C42 | 1nF 0402 X7R 50V MLCC | DigiKey | CL05B102KB5NNNC | Samsung Electro-Mechanics | 12 | 未確認
発注済み | C45 | 4.7nF 0402 X7R 50V MLCC | DigiKey | CL05B472KB5NNNC | Samsung Electro-Mechanics | 12 | 未確認
発注済み | C53, C54 | 10nF 0402 X7R 50V MLCC | DigiKey | CL05B103KB5NNNC | SAMSUNG | 14 | 未確認
発注済み | C61, C62, C69, C70 | 1uF 0603 X5R MLCC | DigiKey | CL10A105KB8NNNC | SAMSUNG | 18 | 未確認
発注済み | C9, C10 | 22pF 0402 C0G 50V MLCC | DigiKey | CL05C220JB5NNNC | SAMSUNG | 14 | 未確認
発注済み | D7 | 汎用スイッチングダイオード SOD-123 | DigiKey | 1N4148W-7-F | Diodes Incorporated | 4 | 未確認
発注済み | FB1, FB2, FB3 | フェライトビーズ 220R@100MHz 0603 | DigiKey | MPZ1608S221ATA00 | TDK | 8 | 未確認
発注済み | R18, R19, R22, R39, R40, R41, R42 | 1.5k 0402 1% 1/16W | DigiKey | RC0402FR-071K5L | YAGEO | 24 | 未確認
発注済み | R28, R29, R30, R31 | 2.2k 0402 1% 1/16W | DigiKey | RC0402FR-072K2L | YAGEO | 18 | 未確認
発注済み | R3, R32, R33, R34, R35, R36, R37 | 10k 0402 1% 1/16W | DigiKey | RC0402FR-0710KL | YAGEO | 24 | 未確認
発注済み | R4, R6, R8, R11, R13, R15, R17, R23, R25 | 75R 0402 1% 1/16W | DigiKey | RC0402FR-0775RL | YAGEO | 28 | 未確認
発注済み | U15, U16 | 2kbit EEPROM + EUI-48 MAC SOIC-8 | DigiKey | 24AA025E48-I/SN | MICROCHIP | 5 | 未確認
発注済み | U3, U4 | 3.3V LDO SOT-223 | DigiKey | AZ1117H-3.3TRE1 | DIODES | 6 | 未確認
発注済み | U5 | 1.8V LDO SOT-23-5 | DigiKey | TLV75718PDBVR | Texas Instruments | 4 | 未確認
発注済み | U6 | 1.9V 200mA LDO SOT-23-5 | DigiKey | TLV70019DDCR | TI | 4 | 未確認
発注済み | U2, U8, U10, U11, U12 | デュアルシュミットバッファ SOT-23-6 | LCSC | SN74LVC2G17DBVR |  | 12 | $0.2403 | 447
発注済み | C1, C2, C3, C4, C5, C7, C60, C63, C67, C68, C71, C75, C76 | 10uF 0805 X5R 25V MLCC | LCSC | CL21A106KAYNNNE |  | 36 | $0.0795 | 444 |  | MOQ40
発注済み | C82, C83, C84, C85 | 4.7nF 2kV X7R 1812(RJ45 シャーシ-論理GND ブリッジ) | LCSC | CC1812KKX7RDBB472 |  | 10 | $0.2414 | 374
発注済み | X1 | 27MHz アクティブ発振器 3.2x2.5mm 4pad 3.3V CMOS | LCSC | OT322527MJBA4SL |  | 4 | $0.4311 | 267
発注済み | X3 | 12.288MHz アクティブ発振器 3.2x2.5mm 4pad 3.3V CMOS | LCSC | OT2JI-111-12.288M |  | 4 | $0.3033 | 188
発注済み | J1 | D-SUB 15pin(DA-15 2列)メス スルーホール | LCSC | DS1037-15FNAKT76-0CC |  | 2 | $0.4268 | 132
発注済み | X2 | 8MHz 水晶 3.2x2.5mm 4pad CL=20pF | LCSC | X32258MSB4SI |  | 4 | $0.1942 | 120
発注済み | D9 | USB 2ライン ESD 保護アレイ SOT-23-6 | LCSC | USBLC6-2SC6 |  | 4 | $0.1432 | 89 |  | MOQ5
発注済み | LED1 | フルカラーLED 2020(WS2812B互換, 制御IC内蔵) | LCSC | XL-2020RGBC-2812B |  | 4 | $0.0925 | 57
発注済み | R1, R2 | 5.1k 0402 1% 1/16W(USB-C CC プルダウン) | LCSC | 0402WGF5101TCE |  | 14 | $0.0043 | 9 |  | MOQ100
発注済み | J2 | USB Type-C レセプタクル 16pin SMD | LCSC | TYPE-C-31-M-12 |  | 4 | 未確認 |  |  | MOQ5
発注済み | J6 | 1.25mm ピッチ 8pin SMD コネクタ | LCSC | YTC-A1251-08ABW |  | 4 | 未確認 |  |  | MOQ10
発注済み | U7 | USB-HS → JTAG+UART ブリッジ QFN-28 | LCSC | CH347F |  | 4 | 未確認
手持ち在庫あり | J11, J12 | RJ45 パルストランス内蔵 10/100/1000 スルーホール | AliExpress | HR911130A |  | 6 | $2.1665 | 2015 |  | 4個在庫あり
未発注 | (module) | SO-DIMM FPGA モジュール本体。AliExpress 等 | AliExpress | Colorlight i5 (ECP5) |  | 2 | 未確認
未発注 | PG1-PG4 | ★必須部品。「任意。未実装でも動作する」と書いていたのは誤り(2026-08-19訂正)。SO-DIMM コネクタに JTAG は通っておらず、i5 モジュール底面のテストパッド(TCK/TMS/TDI/TDO)へバネ接触させるこの4本が* | AliExpress | バネ付きコンタクトピン(圧入TH, 胴径1.0mm, 基板上高さ約3mm) |  | 8 | 未確認
不要 | H1-H5 | 取付穴。基板発注には含まれない | 秋月電子等 | M2.6 ネジ + スペーサ |  | 10 | 未確認
手持ち在庫あり | J10 | OLED | 秋月電子等 | ピンヘッダ 1x4 2.54mm |  | 2 | 未確認
未発注 | J3 | JTAG。秋月・千石等で可 | 秋月電子等 | ピンヘッダ 1x6 2.54mm |  | 2 | 未確認
未発注 | J4 | 第2映像入力(AUX)。シュラウド付 | 秋月電子等 | ボックスヘッダ 2x5 2.54mm |  | 2 | 未確認
未発注 | J5 | S-Video + 音声。シュラウド付 | 秋月電子等 | ボックスヘッダ 2x4 2.54mm |  | 2 | 未確認
未発注 | J7 | デバッグ | 秋月電子等 | ピンヘッダ 2x15 2.54mm |  | 2 | 未確認
発注済み | J8 | S/PDIF 光受信モジュール。秋月電子 109595(150円)。★PLR135/T10 は DigiKey 廃品種・在庫0、代替の PLR237/T10BK も在庫0だったため 形状違いの PLR135/T へ変更。ランドが違うのでフッ | 秋月電子等 | PLR135/T | EVERLIGHT | 2 | 未確認
未発注 | J9 | Argus | 秋月電子等 | ピンヘッダ 1x4 2.54mm |  | 2 | 未確認
合計 |  |  |  |  |  |  |  |  | ★単価「未確認」の品目は小計に入っていません
進捗 | 未発注
 | 発注済み
 | 到着済み
 | 手持ち在庫あり
 | 不要

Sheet: 発注先まとめ
発注先ごとの内訳
発注先 | 品目数 | 総個数 | 確認済み金額(円) | アップロード用ファイル
DigiKey | 21 | 401 | 6157 | orders/<tag>/digikey-bom.csv
LCSC | 13 | 106 | 2128 | orders/<tag>/lcsc-bom.csv
AliExpress | 4 | 18 | 5275 | (手動。RJ45・ポゴピン・i5モジュール)
秋月電子等 | 8 | 24 | 未確認 | (手動。ピンヘッダ・ネジ・PLR135/T)
為替: DigiKey は USD x 170、LCSC/AliExpress は USD x 155。確定額は各社の BOM ツールで出すこと。

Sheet: 注意事項
★発注前に確認すること
部品 | 品番 | 注意
C42 | CL05B102KB5NNNC | FH(風華)は DK/Mouser 扱い無し。同容量・同耐圧の Samsung へ
C45 | CL05B472KB5NNNC | 同上
D7 | 1N4148W-7-F | 1N4148W は各社互換。Diodes 版が DK/Mouser とも潤沢
R18 | RC0402FR-071K5L | 音声ミキシング用。4本は誤差が揃っている方が左右バランスが良い
R4 | RC0402FR-0775RL | ★映像の終端抵抗。1% 品を使うこと(75Ω 整合がずれると映像レベルが狂う)
U5 | TLV75718PDBVR | RICHTEK は DK/Mouser 扱い無し。TLV757P は SOT-23-5 で 1=IN/2=GND/3=EN/4=NC/5=OUT、RT9013 とピン配置一致。1.8V は TVP7002 AVDD 推奨 1.8〜2.0V 内
U2 | SN74LVC2G17DBVR | ★DigiKey 在庫切れ(2026-08-19 利用者確認)のため LCSC 発注へ移した。LCSC は TI 純正が在庫22,242個 $0.2403@30。DigiKey には UMW の同型番互換品($0.19)がある。5V トレラント入力の シュミットバッファで同期信号の整形に5個使うので、代替を使うなら VIH/VIL のヒステリシス幅を確認すること
C1 | CL21A106KAYNNNE | ★DigiKey 在庫切れ(2026-08-19 利用者確認)のため LCSC 発注へ移した。元の選定品(Samsung CL21A106KAYNNNE)がそのまま在庫2,758,420個 $0.0795@50。DigiKey で買うなら Murata GRM21BR61E106KA73L か YAGEO CC0805KKX5R8BB106 (いずれも 10uF/25V/X5R/0805/±10% で等価、在庫あり)
C82 | CC1812KKX7RDBB472 | ★2kV 耐圧は必須。LANケーブルはサージや建物間の電位差を拾うため Bob-Smith 終端の ブリッジには 2kV が標準で、耐圧は落とせない。LCSC なら同じ Yageo 品が $0.24@25。DigiKey で買うなら KYOCERA AVX 1812GC472KAT1A($0.49@25、4700pF/2000V/X7R/±10%/1812 で完全同スペック、在庫42,893)が Yageo(154円)より安い
X1 | OT322527MJBA4SL | ★DigiKey は高い(Abracon ASEM1-27.000MHZ-LC-T が471円)。LCSC なら元の選定品が $0.43。DigiKey 内の安価品 ECS-3225MVLC-270-CN-TR($1.16)は**電源1.8〜3.3Vで使えない** (X1 は AZ1117H-3.3 ±2% = 最大3.37V から給電)。1.6〜3.6V の ECS-3225MV 系に 27MHz は無い
X3 | OT2JI-111-12.288M | 48kHz x 256fs。DigiKey は Epson SG3225CAN が445円、ECS-TXO-3225MV-122.8-TR でも $2.18。LCSC なら元の選定品が $0.30
J1 | DS1037-15FNAKT76-0CC | ★X68000 用 DA-15(メス/15ピン2列/ライトアングル/スルーホール)。DK/Mouser の DA-15 は取付穴・シェル寸法が異なりフットプリントに合わない。2026-08-18 時点 LCSC 自社在庫 112個 / $0.43 で問題なし
X2 | X32258MSB4SI | CH347F 用。LCSC で $0.19。DigiKey の 3225 8MHz 在庫品は ABM8AIG-8.000MHZ-1Z-T($1.17)しか無く CL=18pF になるので、元の CL=20pF 品を LCSC で買う方が安くて正確
D9 | USBLC6-2SC6 | ★DigiKey 在庫切れ(2026-08-19 利用者確認)のため LCSC 発注へ移した。LCSC は ST 純正が在庫33,840個 $0.1432@10。DigiKey には Slkormicro($0.18) / GOODWORK($0.04) / UMW($0.91) の互換品表示があるが、USB データラインの保護なので**接合容量が効く**(ST は Cj typ 0.8pF I/O-GND)。セカンドソースは容量規定を確認してから使うこと。ST 純正が買えるなら純正で。
LED1 | XL-2020RGBC-2812B | ★Worldsemi WS2812B-2020(C965555)から変更(2026-08-19)。理由は吸湿性ランク: WS2812B-2020 MSL 5a → JLCPCB が48時間の焼成(60℃)を要求し追加料金 XL-2020RGBC MSL 3 → 焼成不要 JLCPCB は MSL5以上で焼成を要求する。LCSC 在庫も 35,115個→175,745個 と5倍、単価差は $0.074→$0.093 の2セントのみ。WS2812B 互換の1本線プロトコルで 信号割り当ても DI=3/DO=1/GND=2/VDD=4 と同一。★ランドは違う(パッドが x 方向 ±0.92→±0.68 と内寄り)ので基板のフットプリントも差し替え済み。 2020 サイズは DK/Mouser では稀なので引き続き LCSC 調達
R1 | 0402WGF5101TCE | ★DigiKey 在庫切れ(2026-08-19 利用者確認)のため LCSC 発注へ移した。元の選定品(UNI-ROYAL 0402WGF5101TCE)が在庫6,406,000個 $0.0043@100。★USB Type-C の CC1/CC2 プルダウンなので **5.1kΩ±1% は規格上の要求**(Rd = 5.1k で Default USB Power = 5V/500mA〜3A を宣言する)。値を変えてはいけない。DigiKey で買うなら YAGEO RC0402FR-075K1L の在庫が戻るのを待つか同等の1%品
J2 | TYPE-C-31-M-12 | いわゆる TYPE-C-31-M-12。DK/Mouser の USB-C は各社独自フットプリント
U7 | CH347F | WCH は DK/Mouser 扱い無し。LCSC / AliExpress / 秋月 で入手
J11 | HR911130A | HANRUN HR911130A。★2026-08-18 時点で調達先が分かれる: LCSC **在庫切れ**(Notify Me のみ、$2.17@10 / $1.92@30) JLCPCB Assembly Parts Lib に **5,165個**(Extended、¥401.14@1+ / ¥307.76@31+、Full Reel 31個) → v1.0 の PCBA は JLCPCB 側で調達できるので問題なし。2個/枚なので16枚以上なら 31+ の価格帯に入る。 → v0.9.0 の手半田分は AliExpress で調達する(定番品)。 フットプリントは HanRun HR911105A/HR911130A 系の事実上の業界標準配置(10ピン2列千鳥+LED4+シールド2)なので互換品が多い。公称互換品: LINK-PP LPJG0806FBNL(★使うならピン表の突き合わせが必要)。 ★AliExpress で買う場合は内蔵トランス品質のばらつきに注意。10/100 は通っても 1000Base-T でリンクが不安定になる例がある。届いたら1個で先にリンク確認すること

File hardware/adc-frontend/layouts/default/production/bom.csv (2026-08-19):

Designator | Footprint | Quantity | Value | LCSC Part #
C1, C2, C3, C4, C5, C60, C63, C67, C68, C7, C71, C75, C76 | C0805 | 13 | 10µF ±10% | C15850
C10, C9 | C0402 | 2 | 22pF ±5% | C70464
C11, C12, C13, C14, C15, C16, C17, C18, C19, C20, C21, C22, C23, C24, C25, C27, C29, C31, C33, C35, C37, C39, C41, C43, C44, C46, C47, C49, C51, C55, C56, C57, C58, C59, C6, C64, C65, C66, C72, C73, C74, C77, C78, C79, C8, C80, C81 | C0402 | 47 | 100nF ±10% | C1525
C26, C28, C30, C34, C36, C38, C48, C50 | C0402 | 8 | 33pF ±5% | C70465
C32, C40, C52 | C0402 | 3 | 33pF ±5%
C42 | C0402 | 1 | 1nF ±10% | C1523
C45 | C0402 | 1 | 4.7nF ±10% | C1538
C53, C54 | C0402 | 2 | 10nF ±10% | C15195
C61, C62, C69, C70 | C0603 | 4 | 1µF ±10% | C15849
C82, C83, C84, C85 | C1812 | 4 | 4.7nF ±10% | C309511
D1, D2, D3, D4, D5, D6, D8 | EMT6_L1.6-W1.2-P0.50-LS1.6-BL | 7 |  | C510333
D7 | D_SOD-123 | 1 |  | C81598
D9 | SOT-23-6_L2.9-W1.6-P0.95-LS2.8-BL | 1 |  | C7519
FB1, FB2, FB3 | L0603 | 3 |  | C76815
J1 | DSUB-TH_DS1037-15FNAKT74-0CC | 1 |  | C77836
J10, J9 | Header_1x4_P2.54mm | 2
J11, J12 | RJ45-TH_HR911130A | 2 |  | C54408
J2 | USB-C_SMD-TYPE-C-31-M-12_1 | 1 |  | C165948
J3 | Header_1x6_P2.54mm | 1
J4 | BoxHeader_2x5_P2.54mm | 1
J5 | BoxHeader_2x4_P2.54mm | 1
J6 | CONN-SMD_8P-P1.25_YTC-A1251-08ABW | 1 |  | C7436577
J7 | Header_2x15_P2.54mm | 1
J8 | PLR135_T | 1
LED1 | LED-SMD_4P-L2.0-W2.0-BR-1 | 1 |  | C5349955
PG1, PG2, PG3, PG4 | PogoPin_D1.0mm | 4
R1, R2 | R0402 | 2 | 5.1kΩ ±1% | C25905
R10, R12, R14, R16, R20, R21, R24, R26, R27, R38, R43, R44, R45, R46, R5, R7, R9 | R0402 | 17 | 220Ω ±1% | C25091
R11, R13, R15, R17, R23, R25, R4, R6, R8 | R0402 | 9 | 75Ω ±1% | C25133
R18, R19, R22, R39, R40, R41, R42 | R0402 | 7 | 1.5kΩ ±1% | C25867
R28, R29, R30, R31 | R0402 | 4 | 2.2kΩ ±1% | C25879
R3, R32, R33, R34, R35, R36, R37 | R0402 | 7 | 10kΩ ±1% | C25744
TP1, TP2 | TestPoint_TH1 | 2
U1 | HTQFP-100_L14.0-W14.0-P0.50-LS16.0-BL-EP6.2 | 1 |  | C3824085
U10, U11, U12, U2, U8 | SOT-23-6_L2.9-W1.6-P0.95-LS2.8-BL | 5 |  | C10429
U13, U14 | TSSOP-14_L5.0-W4.4-P0.65-LS6.4-BL | 2 |  | C55513
U15, U16 | SOIC-8_L4.9-W3.9-P1.27-LS6.0-BL | 2 |  | C46840
U3, U4 | SOT-223-3_L6.5-W3.4-P2.30-LS7.0-BR | 2 |  | C92517
U5 | SOT-23-5_L3.0-W1.7-P0.95-LS2.8-BR | 1 |  | C59969
U6 | SOT-23-5_L2.9-W1.6-P0.95-LS2.8-BR | 1 |  | C2862411
U7 | QFN-28_L4.0-W4.0-P0.40-BL-EP2.7 | 1 |  | C18221627
U9 | SO-DIMM-SMD_200P-P0.60_1473005-4 | 1 |  | C428482
X1 | OSC-SMD_4P-L3.2-W2.5-BL | 1 |  | C725995
X2 | CRYSTAL-SMD_4P-L3.2-W2.5-BL | 1 |  | C2682774
X3 | OSC-SMD_4P-L3.2-W2.5-BL | 1 |  | C20617595

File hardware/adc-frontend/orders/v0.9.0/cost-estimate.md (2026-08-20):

# RetroCast X 部品代の集計 (v0.9.0, 2枚分)

`tools/cost_estimate.py` が生成。**手で編集しない**(再生成で消えます)。
元データは `orders/<tag>/*.csv` と `tools/prices.json`。

★**価格の根拠(URL)と取得日を持つ品目だけ**を合計しています。
価格未取得の品目は金額に入れていないので、合計は常に**下限**です。

## 合計(実測分のみ / 未取得 19品目を含まず)

```
2枚分の発注総額       13,561円 以上
1枚あたり(発注額÷2)       6,780円 以上   ← 予備・端数込みの実支出
1枚あたり(正味BOM)          5,940円 以上   ← 員数ぶんだけの原価
```

為替: DigiKey は USD x 170、LCSC/AliExpress は USD x 155。
DigiKey Japan の円建て価格は USD x 約170 だった(利用者実測: ASEM1 $2.77 -> 471円)。LCSC/AliExpress は USD 建てなので実勢レート寄りの155で換算。いずれも概算なので、確定額は各社の BOM ツールで出すこと。

## 価格を確認済みの品目 (17)

| 部品 | 発注数 | 単価 | 小計 | 取得日 | 根拠 |
|---|---:|---:|---:|---|---|
| U1 TVP7002PZP | 2 | $12.0400@1 | 4,094円 | 2026-08-18 | [measured](https://www.digikey.com/en/products/detail/texas-instruments/TVP7002PZP/1765836) |
| U9 1473005-4 | 2 | $9.5900@1 | 3,261円 | 2026-08-19 | [measured](https://www.digikey.com/en/products/result?keywords=1473005-4) |
| J11, J12 C54408 | 6 | $2.1665@10 ★数量不足 | 2,015円 | 2026-08-18 | [measured](https://www.lcsc.com/product-detail/C54408.html) |
| U13, U14 PCM1808PWR | 5 | $1.5900@1 | 1,352円 | 2026-08-19 | [measured](https://www.digikey.com/en/products/result?keywords=PCM1808PWR) |
| D1, D2, D3, D4, D5, D6, D8 EMZT6.8ET2R | 16 | $0.1983@25 ★数量不足 | 539円 | 2026-08-19 | [measured](https://www.digikey.com/en/products/result?keywords=EMZT6.8ET2R) |
| U2, U8, U10, U11, U12 C10429 | 12 | $0.2403@30 ★数量不足 | 447円 | 2026-08-19 | [measured](https://www.lcsc.com/product-detail/C10429.html) |
| C1, C2, C3, C4, C5, C7, C60, C15850 | 36 | $0.0795@50 ★数量不足 | 444円 | 2026-08-19 | [measured](https://www.lcsc.com/product-detail/C15850.html) |
| C82, C83, C84, C85 C309511 | 10 | $0.2414@25 ★数量不足 | 374円 | 2026-08-18 | [measured](https://www.lcsc.com/product-detail/C309511.html) |
| X1 C725995 | 4 | $0.4311@10 ★数量不足 | 267円 | 2026-08-18 | [measured](https://www.lcsc.com/product-detail/C725995.html) |
| X3 C20617595 | 4 | $0.3033@10 ★数量不足 | 188円 | 2026-08-18 | [measured](https://www.lcsc.com/product-detail/C20617595.html) |
| J1 C77836 | 2 | $0.4268@5 ★数量不足 | 132円 | 2026-08-18 | [measured](https://www.lcsc.com/product-detail/C77836.html) |
| C6, C8, C11, C12, C13, C14,  CL05B104KO5NNNC | 113 | $0.0066@250 ★数量不足 | 127円 | 2026-08-19 | [measured](https://www.digikey.com/en/products/result?keywords=CL05B104KO5NNNC) |
| X2 C2682774 | 4 | $0.1942@5 ★数量不足 | 120円 | 2026-08-18 | [measured](https://www.lcsc.com/product-detail/C2682774.html) |
| D9 C7519 | 4 | $0.1432@10 ★数量不足 | 89円 | 2026-08-19 | [measured](https://www.lcsc.com/product-detail/C7519.html) |
| LED1 C5349955 | 4 | $0.0925@50 ★数量不足 | 57円 | 2026-08-19 | [measured](https://www.lcsc.com/product-detail/RGB-LEDs-Built-in-IC_XINGLIGHT-XL-2020RGBC-WS2812B_C5349955.html) |
| R5, R7, R9, R10, R12, R14, R RC0402FR-07220RL | 44 | $0.0061@200 ★数量不足 | 46円 | 2026-08-19 | [measured](https://www.digikey.com/en/products/result?keywords=RC0402FR-07220RL) |
| R1, R2 C25905 | 14 | $0.0043@100 ★数量不足 | 9円 | 2026-08-19 | [measured](https://www.lcsc.com/product-detail/C25905.html) |

★数量不足 = その単価が適用される数量に発注数が届いていない。実際はもっと高くなります。

## ★価格未取得 (19品目) — 上の合計に**含まれていません**

| 部品 | 発注数 | 仕入先 |
|---|---:|---|
| C26, C28, C30, C34, C36, C38, C48, CL05C330JB5NNNC | 26 | DK |
| C42 CL05B102KB5NNNC | 12 | DK |
| C45 CL05B472KB5NNNC | 12 | DK |
| C53, C54 CL05B103KB5NNNC | 14 | DK |
| C61, C62, C69, C70 CL10A105KB8NNNC | 18 | DK |
| C9, C10 CL05C220JB5NNNC | 14 | DK |
| D7 1N4148W-7-F | 4 | DK |
| FB1, FB2, FB3 MPZ1608S221ATA00 | 8 | DK |
| J2 C165948 | 4 | LCSC |
| J6 C7436577 | 4 | LCSC |
| R18, R19, R22, R39, R40, R41, R42 RC0402FR-071K5L | 24 | DK |
| R28, R29, R30, R31 RC0402FR-072K2L | 18 | DK |
| R3, R32, R33, R34, R35, R36, R37 RC0402FR-0710KL | 24 | DK |
| R4, R6, R8, R11, R13, R15, R17, R2 RC0402FR-0775RL | 28 | DK |
| U15, U16 24AA025E48-I/SN | 5 | DK |
| U3, U4 AZ1117H-3.3TRE1 | 6 | DK |
| U5 TLV75718PDBVR | 4 | DK |
| U6 TLV70019DDCR | 4 | DK |
| U7 C18221627 | 4 | LCSC |

価格を足すときは、実際に販売ページを見て `tools/prices.json` に
`source` と `fetched` を付けて追記してください。
DigiKey 分は `digikey-bom.csv` を BOM ツールに投げれば一括で確定します。

## 汎用品 (8品目) — 金額未計上

ピンヘッダ・ネジ等。秋月・千石等でまとめ買いする前提で、単価を持っていません。

| 部品 | 数/枚 | 品名 |
|---|---:|---|
| J3 | 1 | ピンヘッダ 1x6 2.54mm |
| J4 | 1 | ボックスヘッダ 2x5 2.54mm |
| J5 | 1 | ボックスヘッダ 2x4 2.54mm |
| J7 | 1 | ピンヘッダ 2x15 2.54mm |
| J9 | 1 | ピンヘッダ 1x4 2.54mm |
| J10 | 1 | ピンヘッダ 1x4 2.54mm |
| J8 | 1 | PLR135/T |
| H1-H5 | 5 | M2.6 ネジ + スペーサ |

## 価格を確定できていないものの覚え書き

- **Colorlight i5 (ECP5)**: ★2026-08-19 利用者が AliExpress で確認したところ **約5,000円**。私が会話中に『$15〜25(2,300〜3,900円)』と述べたのは根拠の無い記憶で誤り(2021年頃の$12.99が頭にあった)。出品者差が大きく、$14.96〜66.73 の幅がある(i9・キャリアボード付きを含む)。商品ページを直接取得できなかったため measured にはしない。

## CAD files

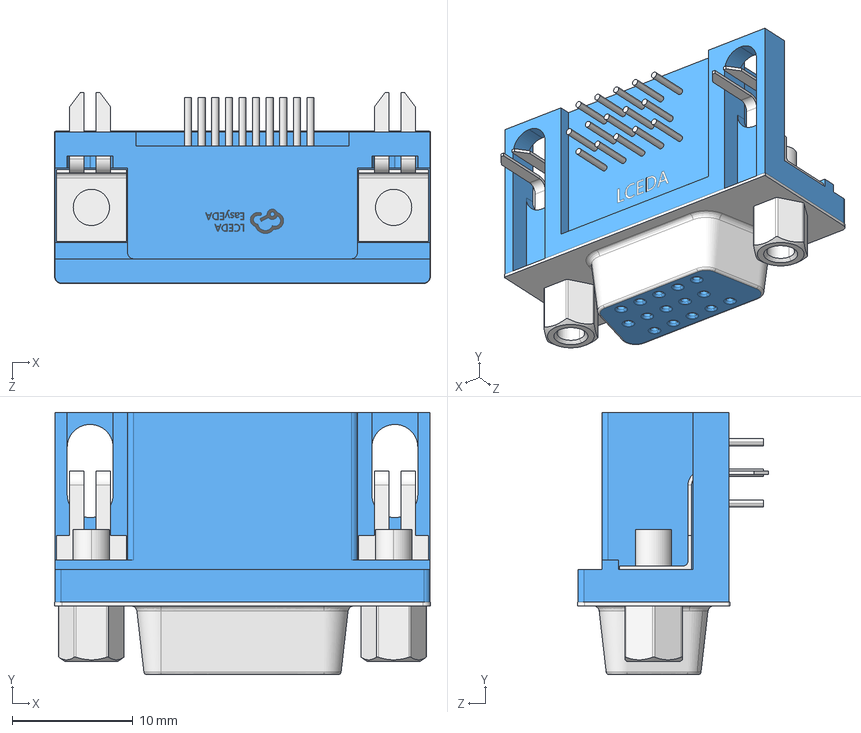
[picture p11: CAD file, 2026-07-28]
hardware/adc-frontend/parts/BOOMELE_VGA_002/D-SUB-TH_VGA-002.step
31.1 x 21.7 x 15.8 mm

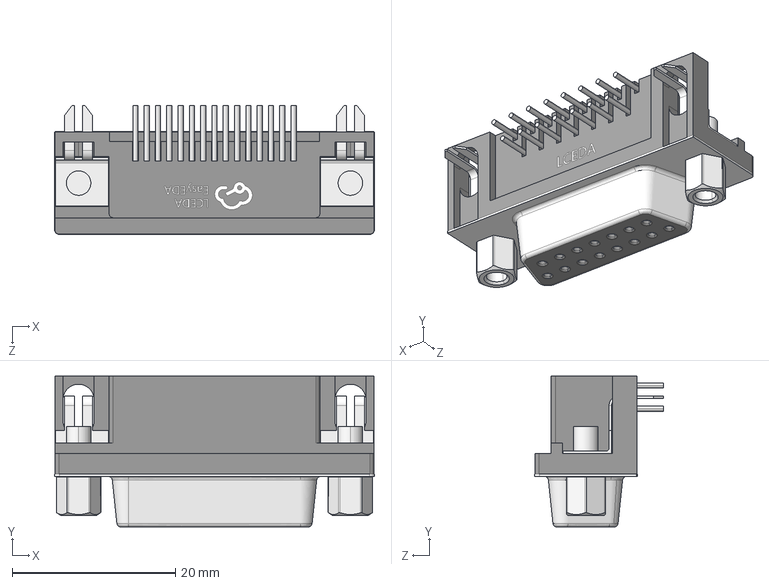
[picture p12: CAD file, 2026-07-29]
hardware/adc-frontend/parts/CONNFLY_DS1037_15FNAKT76_0CC/DSUB-TH_DMR-15P-F-WI.step
39.2 x 18.5 x 15.8 mm

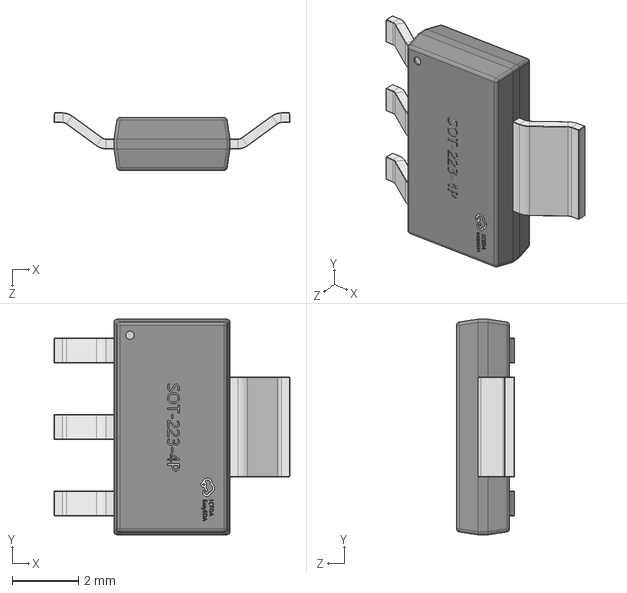
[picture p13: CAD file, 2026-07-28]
hardware/adc-frontend/parts/DIODES_AZ1117H_3_3TRE1/SOT-223-4P_L6.5-W3.5-H1.6-LS7.0-P2.30.step
7.11 x 6.50 x 1.75 mm

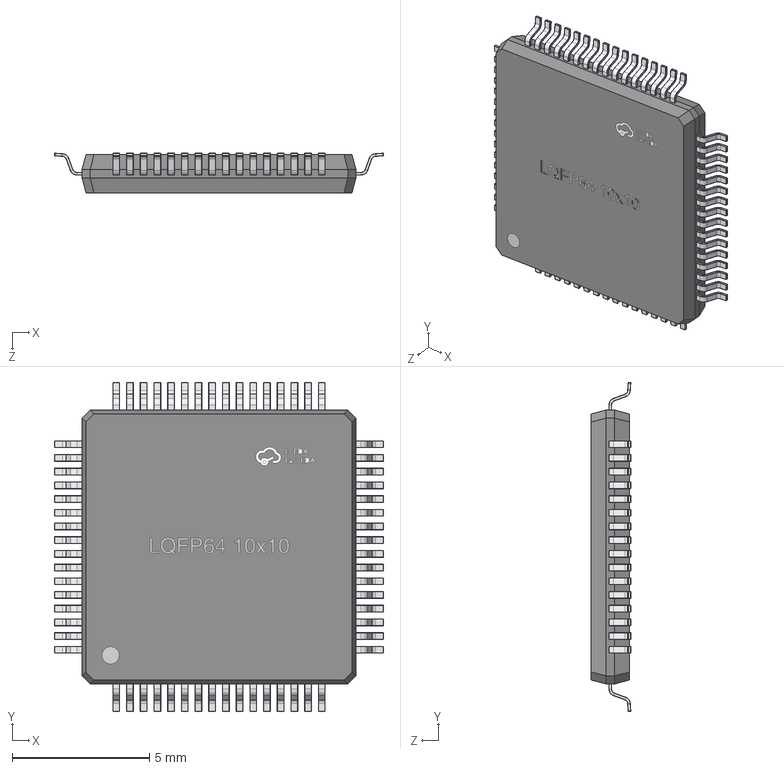
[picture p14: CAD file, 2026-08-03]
hardware/adc-frontend/parts/FTDI_FT2232HL_REEL/LQFP-64_L10.0-W10.0-H1.4-LS12.0-P0.50.step
12.0 x 12.0 x 1.45 mm

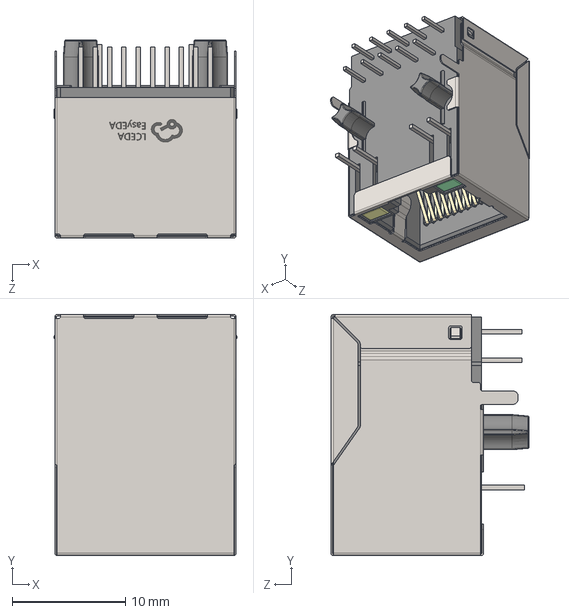
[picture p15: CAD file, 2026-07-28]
hardware/adc-frontend/parts/HANRUN_HR911130A/RJ45-TH_HR911130A.STEP
16.1 x 21.3 x 17.5 mm

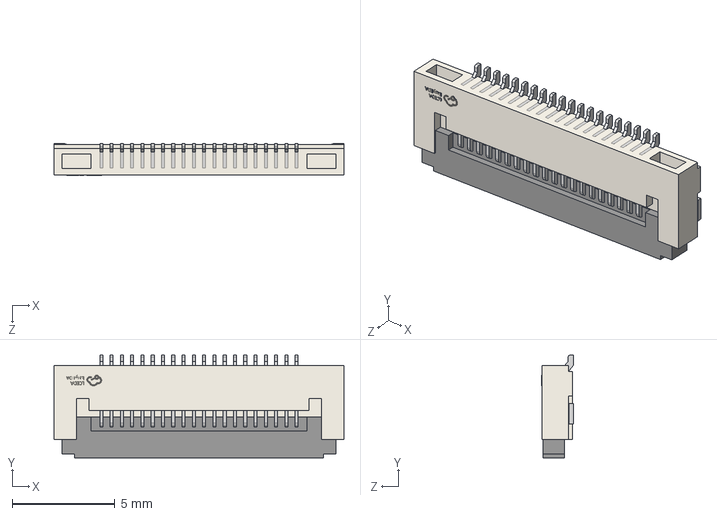
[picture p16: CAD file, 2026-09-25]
hardware/adc-frontend/parts/HDGC_0_5K_1_5_20PWB/FPC-SMD_20P-P0.50_HDGC_0.5K-1.5-20PWB.step
14.1 x 5.00 x 1.54 mm

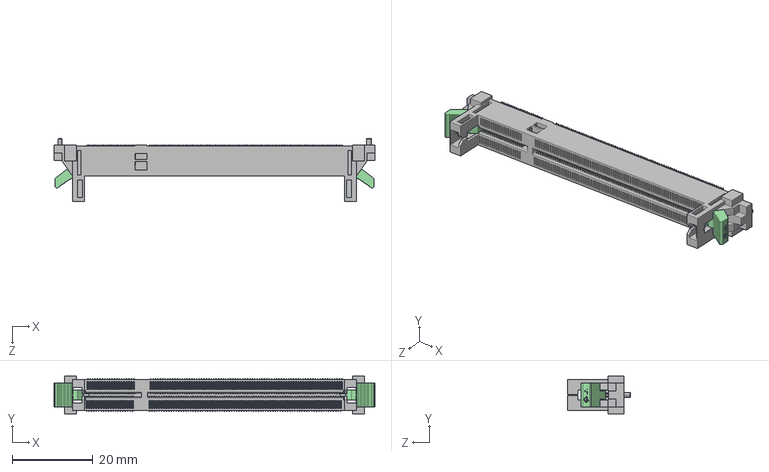
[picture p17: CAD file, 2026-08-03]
hardware/adc-frontend/parts/JST_DM_7D4_H2500_M/DIMM-SMD_DM-7D4-H2500-M.step
79.6 x 9.40 x 15.6 mm

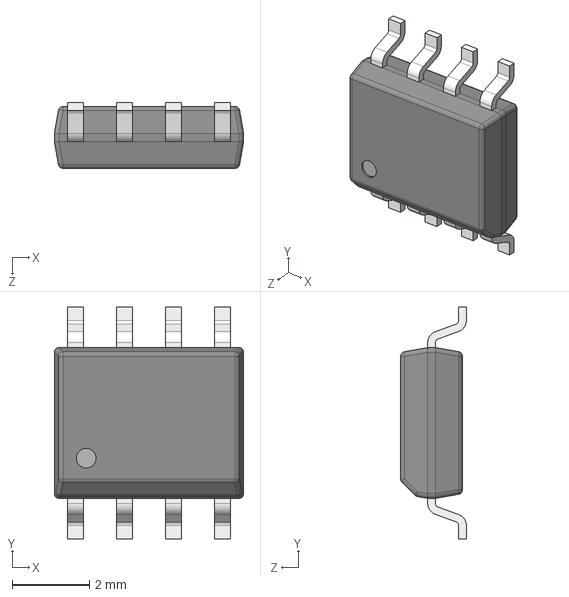
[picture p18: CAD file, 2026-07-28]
hardware/adc-frontend/parts/MICROCHIP_93LC56BT_I_SN/SOIC-8_L4.9-W3.9-H1.7-LS6.0-P1.27.STEP
4.90 x 6.00 x 1.70 mm

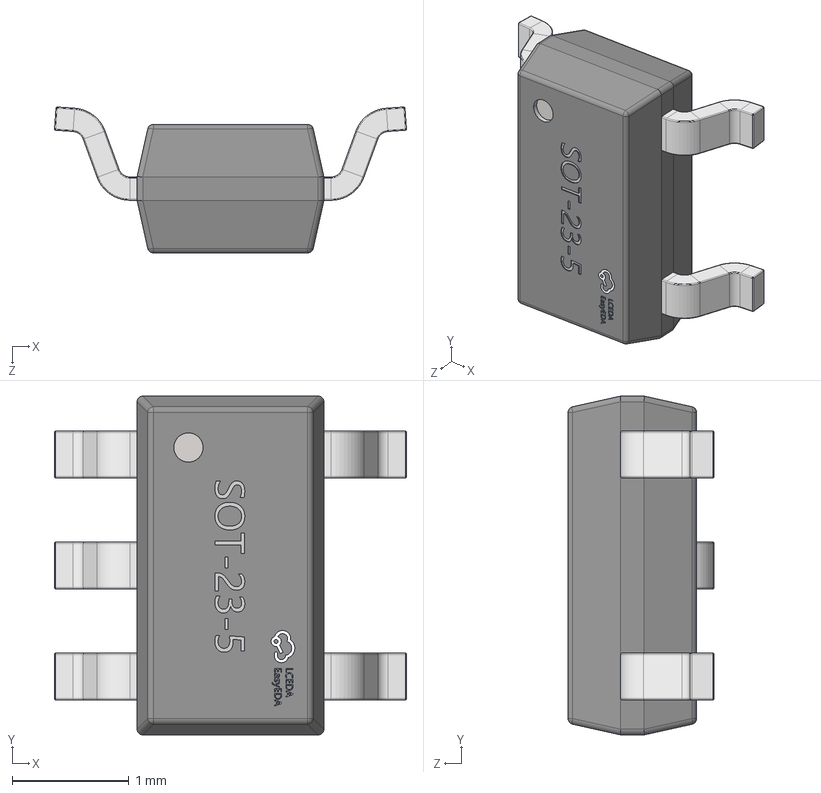
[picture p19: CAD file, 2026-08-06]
hardware/adc-frontend/parts/RICHTEK_RT9013_18GB/SOT-23-5_L2.9-W1.6-H1.1-LS2.8-P0.95.step
3.01 x 2.90 x 1.25 mm

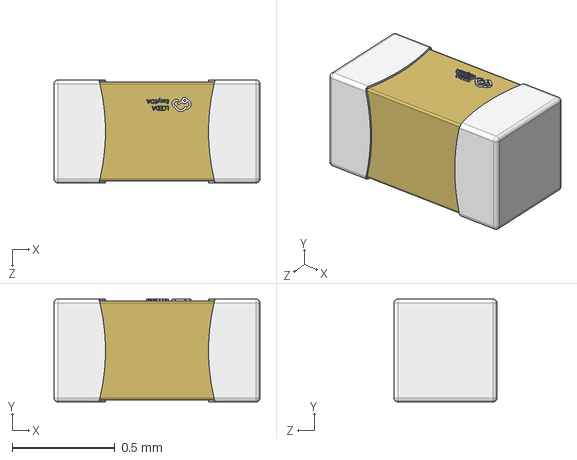
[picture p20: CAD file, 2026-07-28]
hardware/adc-frontend/parts/SAMSUNG_CL05C330JB5NNNC/C0402_L1.0-W0.5-H0.5.step
1.00 x 0.5 x 0.5 mm

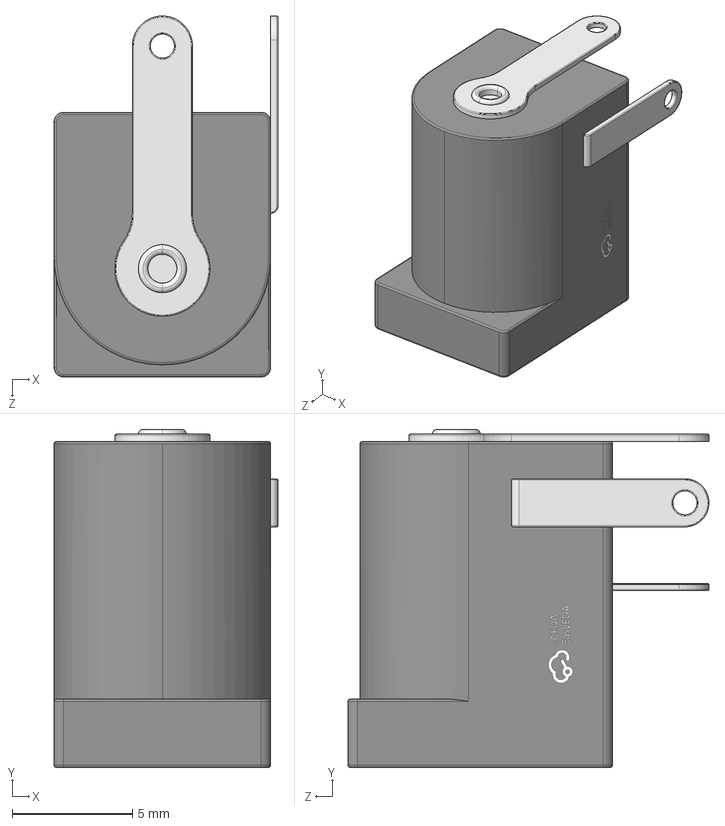
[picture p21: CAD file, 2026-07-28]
hardware/adc-frontend/parts/SHOU_HAN_DC005/DC-IN-TH_DC005.step
9.30 x 14.1 x 15.0 mm

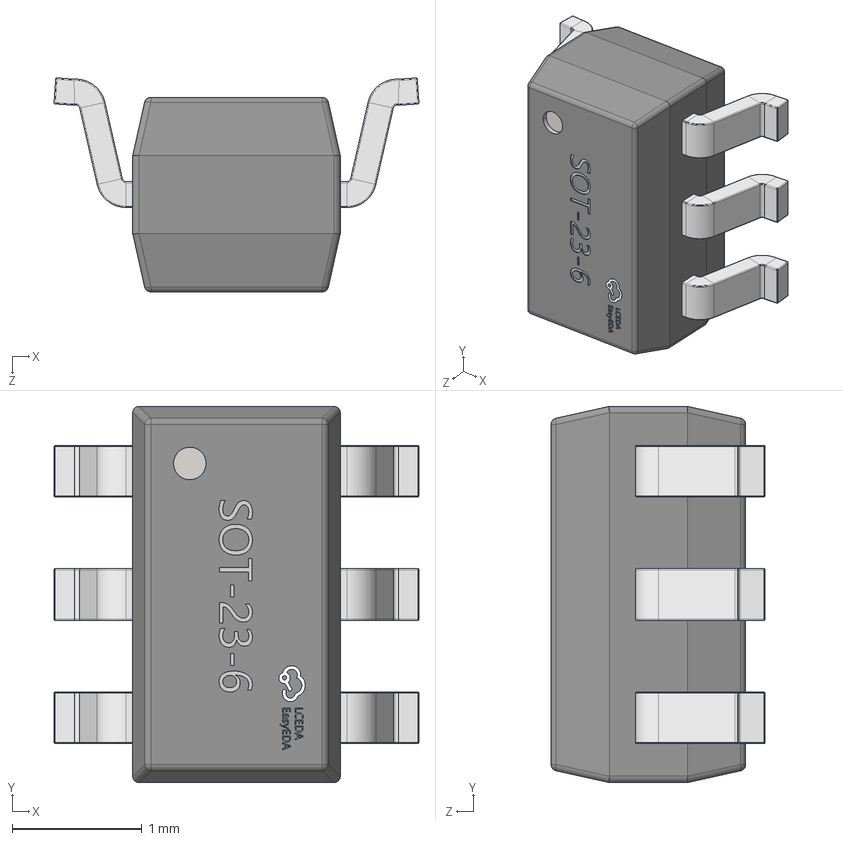
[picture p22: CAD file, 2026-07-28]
hardware/adc-frontend/parts/ST_USBLC6_2SC6/SOT-23-6_L2.9-W1.6-H1.5-LS2.8-P0.95.step
2.81 x 2.90 x 1.65 mm

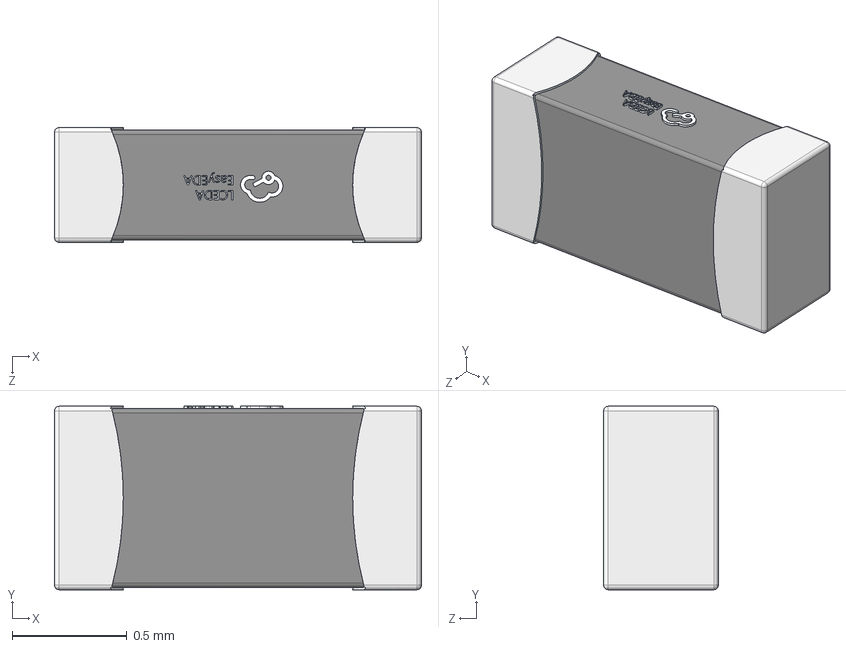
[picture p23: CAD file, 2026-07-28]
hardware/adc-frontend/parts/TDK_MPZ1608S221ATA00/L0603_L1.6-W0.8-H0.5_BEAD.step
1.60 x 0.8 x 0.5 mm

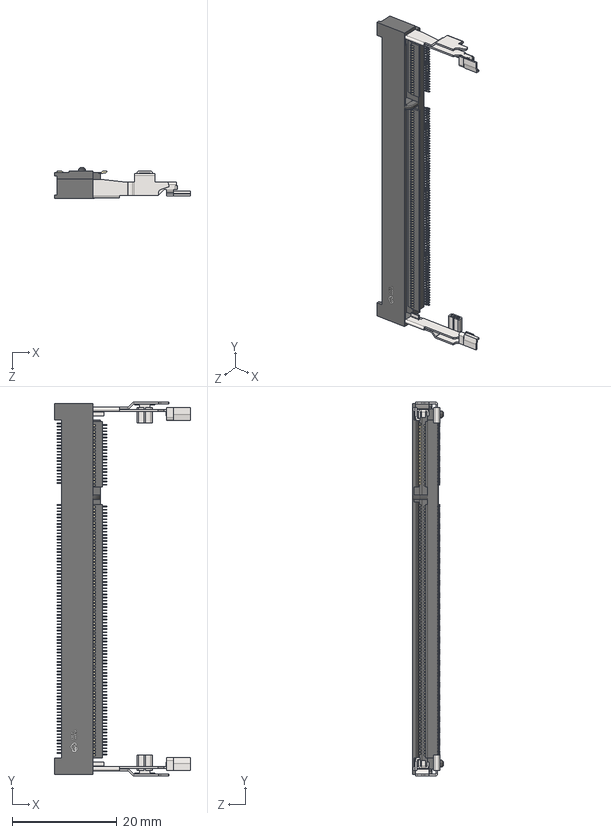
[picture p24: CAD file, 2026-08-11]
hardware/adc-frontend/parts/TE_Connectivity_1473005_4/SO-DIMM-SMD_L71.5-W26-H5.2_200P-P0.60_1473005-4.step
26.0 x 71.5 x 5.90 mm

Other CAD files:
hardware/adc-frontend/parts/TI_PCM1808PWR/TSSOP-14_L5.0-W4.4-H1.0-LS6.4-P0.65.step
hardware/adc-frontend/parts/TI_TLV70019DDCR/SOT-23-5_L2.9-W1.6-P0.95-LS2.8-BR.step
hardware/adc-frontend/parts/TI_TVP7002PZP/HTQFP-100_L14.0-W14.0-H1.20-P0.50-LS16.0-BL-EP6.2.step
hardware/adc-frontend/parts/UNI_ROYAL_0402WGF1002TCE/R0402_L1.0-W0.5-H0.4.step
hardware/adc-frontend/parts/UNI_ROYAL_0402WGF1202TCE/R0402_L1.0-W0.5-H0.4.step
hardware/adc-frontend/parts/UNKNOWN_PJ_327C_4A/AUDIO-SMD_L11.8-W6.0-H5.0-4P.step
hardware/adc-frontend/parts/UNKNOWN_TYPE_C_31_M_12/USB-C_SMD-TYPE-C-31-M-12.step
hardware/adc-frontend/parts/WCH_CH347F/QFN-28_L4.0-W4.0-P0.40-BL-EP2.7.step
hardware/adc-frontend/parts/Worldsemi_WS2812B_2020/LED-SMD_4P-L2.0-W2.0-H0.8-TL_WS2812B-2020.step
hardware/adc-frontend/parts/XFCN_BH254V_10P/IDC-TH_10P-P2.54-V-R2-C5-S2.54.STEP
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

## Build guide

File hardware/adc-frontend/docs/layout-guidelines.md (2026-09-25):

# RetroCastX ADCフロントエンド レイアウト指示書

> ## ★デジグネータ振り直しについて (2026-08-13)
>
> V1発注前に、デジグネータを **main.ato の宣言順**へ振り直した(185個中171個が変更)。
> **この文書は日付入りの設計ログなので、以下の記述は当時の番号のまま残してある**
> (書き換えると当時の記録が読めなくなるため)。読み替えは `designator-map.md` を参照。
>
> よく出てくるものだけ抜き出すと:
>
> | 本文の表記 | 現在 | 部品 |
> |---|---|---|
> | U10 | **U1** | TVP7002 |
> | U11 | **U10** | SO-DIMMソケット |
> | U13 | **U7** | FT2232H |
> | J10 | **J1** | D-SUB15 |
> | J13 | **J5** | デジタルRGB端子 |
> | J9 | **J2** | USB-C |
> | J2 / J11 | **J10 / J11** | MagJack |
> | U14/U15/U16 | **U11/U12/U13** | デジタルRGBバッファ |
> | D4/D5 | D4/D5 | デジタルRGB ESD(変わらず) |
> | X2 | **X3** | 音声12.288MHz XO |
>
> また本文には**既に削除された部品への言及**が残っている(PHY LEDタップのポゴピン PG5-8、
> はんだジャンパ JP4-7、3.5mm LINE入力ジャック、J7 DCジャック、ArgusX 2×8 ヘッダ)。
> §9.7 の「Ethernet LED の二経路」は経路Bのみ(FPGA GPIO直結)に一本化済み。

> ## ★v1.0 で増えた部品と配置の要点 (2026-09-21)
>
> 回路は `main.ato` に入って `ato build` が通っている。**新規部品は基板外の原点付近に
> 置かれているので、これらを配置するのが v1.0 のレイアウト作業**。
>
> | 新規 | 部品 | 置き場所 |
> |---|---|---|
> | J13 | ミニDIN8(FRAMEMEISTER互換, **マル信 MJ-373/8B**) | 旧 J4(2x5ヘッダ)の空き地。**フットプリントの x=0 が嵌合面なので、そこに基板外形を合わせる**。奥行12.7 / フランジ14.0×13.0 / シェル用スロット3本(2.8×0.8) |
> | J14 | 1×3 ヘッダ(HSYNC/VSYNC/GND) | J13 の近く。DNPなので基板内側でよい |
> | J15 | **20芯FFC**(0.5mmピッチ、下接点、右アングル、HDGC 0.5K-1.5-20PWB / C2919559) | **小亀基板を向ける辺**。1番ピンにシルクを打つ。全信号がGNDに隣接し、電源は2本ずつ |
> | U17 + C88-C96 | 3個目の PCM1808 とそのパスコン | 既存 U13/U14 の隣。**VREF/VCC/VDD の 10µF+0.1µF はIC直近**(データシートのLayout Example) |
> | D10/D11/D12 | ESDアレイ ×3(ミニDIN8 / FFC / 小亀音声) | **各コネクタの直近**。ESDは経路が短いほど効く |
> | R47-R50 | 同期入力のプルアップ 10kΩ | バッファ(U2/U8)の入力側 |
> | R51/R52/C86/C87 | BIN_1(Pb)の前段 75Ω/100nF/220Ω/33pF | **33pF は TVP のピン直近**(他チャンネルと同じ) |
> | R53 | 小亀LEDデータの直列220Ω | **SO-DIMM側に寄せる**(源端整合) |
> | FB4/C96 | S/PDIF電源のフェライト+10µF | J8 の直近 |
> | J6 | デジタルRGBを **2×5 ボックスヘッダ(ストレート)**(XFCN BH254V-10P / C492442)へ変更 | 外形 **20.30 × 8.70mm**。L型(20.5 × 13.9mm)は場所が足りず却下した(高さ方向には余裕があるのでリボンが垂直に立つのは許容)。**別エッジへ移動**する前提。ピン1は **x=-5.08, y=+1.27**(L型とは逆の角)。シュラウドの切り欠き=リボンの抜ける向きを空いている側へ |
> | H1-H5 | M3(φ3.2、パッド6.4mm)へ拡大 | 穴が0.4mm太り、パッドが0.8mm大きくなる。**四隅の部品を寄せすぎないこと** |
>
> **削除された部品**: J3(JTAGデバッグ用1×6ヘッダ)、J4(旧・第2入力の2x5ボックスヘッダ)、J5(2x4 S-Videoヘッダ)、D8相当の
> esd_svideo、受動加算の1.5kΩ×4(r_mix_*)、BIN_1 の未使用終端 10nF、
> ch_y/ch_c の 75Ω終端(小亀基板側へ移した)。**旧配線が宙に浮いて残るので、
> 新しい部品をその位置に置けば繋がる**(2026-08-14 と同じ要領)。
>
> ★**フットプリントを差し替えたときの手順**は小亀基板の指示書
> (`../../console-frontend/docs/layout-guidelines.md` の 4.5)にまとめてある。要点だけ:
> **(1) `ato build` を2回**(1回目は新しいパッドにネットが付かない)/
> **(2) 消したブロックの `(at x y rot)` を控えて書き戻す**(配置が失われる)/
> **(3) `lock_designators.py` は最後の build の後**/ **(4) ゾーンを塗り直す(`B`)**。
>
> 基板の版数(title_block の rev)は **`v1.0` へ上げること**。`ato build` が rev と
> grid_origin を落とすので、`tools/restore_pcb_settings.py` と
> `tools/pcb_settings.json` の値も v1.0 に更新する。

TVP7002混載(アナログRGB + 高速デジタル + GbE + 音声)基板のPCBレイアウト方針。
KiCadでの配置・配線はこの指示書に沿って行う。根拠は各部データシート + OSSC rev1.8 +
kazkojima i5ether。回路は `main.ato`、ネットリスト/PCBは `ato build` が生成(配置は保持される)。

---

## 0. 基板全体・スタックアップ・グラウンド

- **層構成: 4層 1.6mm を設定済み**(`default.kicad_pcb` の physical stackup)。
  L1=F.Cu(信号) / **L2=In1.Cu(GNDプレーン)** / **L3=In2.Cu(PWRプレーン)** / L4=B.Cu(信号)。
  スタックアップは **JLCPCB JLC04161H-7628 相当**: L1-L2間プリプレグ=7628 **0.2104mm**(εr 4.6)、
  コア 1.065mm、内層銅 0.5oz(0.0152mm)、外層銅 1oz(0.035mm)、ENIG。上部プリプレグを厚い7628に
  したのは、GbE 100Ω差動をL1で実用的なトレース幅(≈0.2mm)で引けるようにするため(3313の0.1mmだと
  0.09mm級の細線が必要で歩留まり悪化)。★JLC発注時にこのスタックアップを明示指定すること。
  **`ato build` はこのスタックアップ設定を保持する**(検証済み)。
  GbE差動ペアとDATACLK(~80MHz)の特性インピーダンス制御と、L2ベタGNDによる
  リターン経路確保のため。2層では高速系の品質確保が困難。
- **グラウンド: L2 を極力ベタの単一GNDプレーンにする**(分割しない)。混載基板は
  「面分割」より「**配置で分離**」が現代的ベストプラクティス。
  - アナログ区画(D-SUB15→前段→TVPアナログ電源側)とデジタル区画(TVPデジタル出力→
    スタッキングヘッダ)を**物理的に左右で分け**、デジタルのリターン電流がアナログ入力の
    下を通らないようにする。
  - GbE磁気部の下は**GND/電源プレーンをくり抜き**(keepout)、シャーシGNDと論理GNDを
    その部分だけ分離(絶縁ギャップ、下記6章)。
- **TVP7002の露出パッド(EP, pin101)は直下に多数のサーマルビアでL2 GNDへ**(熱+電気)。
- 基板外形は**仮120×90mm**。★EXT基板実寸(P1/P2/P4ヘッダ位置・間隔、i5モジュール高さ、
  ソケット嵌合高さ≈11mm)で確定させること。スタッキングヘッダ3本がEXTと1対1で嵌合する
  位置が最優先の物理拘束。

## 0.5 SO-DIMMソケット(U11)— 水平(寝かせ)タイプ / 2026-08 差し替え

以前は JST DM-7D4-H2500(M)(C483268)のフットプリントを流用していたが、これは
**モジュールが基板に垂直に立つタイプ**だった。本設計は i5 モジュールを**基板と平行に
寝かせる**前提(JTAGとPHY LEDをモジュール底面パッドへポゴピンでバネ接触させるため)なので、
水平タイプ(right angle module orientation)の実部品へ差し替えた。

型番は [hansfbaier/colorlight-qmtech-adapter](https://github.com/hansfbaier/colorlight-qmtech-adapter)
の JLCPCB 発注用BOM から判明した(`1473005-4,CN1,...,C428482`)。

**採用部品: TE 1473005-4 (LCSC C428482, 在庫1636・$4.48)**。ベンダ純正フットプリントを
`tools/ingest_parts.py` で取り込んだ(ラッチ保持パッド・非対称位置決め穴・STEP付き)。

| 項目 | 垂直(旧流用) | TE 1473005-4(採用) |
|---|---|---|
| 列間 | 6.6mm | **8.60mm** |
| パッド | 2.0 × 0.4mm | 0.35 × 2.0mm |
| 列内ピッチ / 列間ずれ | 0.6 / 0.3mm | 同じ(MO-224) |
| span | 63.00mm + キー切欠4.2mm | 同じ |
| ラッチ保持SMDパッド | なし | **4.5 × 4.6mm ×2**(pad名201)→ GND |
| 位置決め穴 | φ1.05/φ1.45(垂直部品のもの) | **φ1.6 / φ1.1 の非対称**(向き間違い防止) |
| ボディ | — | **71.5 × 26 × 5.2mm**(STEP) |

★列間について: TE 1717254-1 の仕様表の "Reihenabstand 6.2mm" は**基板ランドの列間では
なかった**。実フットプリント3件(TE 1473005-4=8.60 / TE 1473149-4=8.20 / KiCad標準の
DDR4版=8.20mm)で確定。**1473149-4 と 1473005-4 はランドが違うので、買う型番と一致させること。**

### モジュールが基板を覆う(最重要の物理制約)

寝かせると i5 モジュールが基板の上に張り出す。**Colorlight i5 は 68 × 36mm** で、
JEDEC標準の SO-DIMM モジュール(67.6 × 30mm)より **6mm 深い**。SO-DIMMエッジコネクタを
使っているだけの独自寸法のモジュールなので、MO-224 の 30mm で見積もると足りない。

ソケット本体は **71.5 × 26 × 5.2mm**(取り込んだSTEPより)。

- **モジュール下に入る部品はスタックハイト(5.2mm)より低くしなければならない**。
  電解コンデンサや背の高いコネクタは置けない
- **ポゴピン(PG1-4=JTAG, PG5-8=PHY LED)の自由長3mm が届くかを必ず確認**。
  mech.ato は「モジュール裏〜基板間隙 2.6mm → 約0.4mm圧縮」を想定しているが、
  採用品のスタックハイトは5.2mmなので**そのままでは届かない可能性が高い**。
  長いポゴピンにするか4.0mm品のソケットにするかを実測で決める。
  届かないと**JTAG書き込みとPHY LEDの両方が成立しない**
- モジュールが寝る方向はフットプリントのローカル+x(下記「向きと配置」)。配置時の
  回転で決まるので、**モジュールが盤外へはみ出さない向き**にし、覆われる区画を意図的に選ぶ
- STEPが付いているので **3Dビューアでモジュール下のクリアランスを目視確認できる**

### 向きと配置

フットプリントのローカル座標では**信号列が y 方向**に並ぶ(x=−8.1 が奇数ピン、
x=+0.5 が偶数ピン、ラッチパッドが x=+8.1、位置決め穴が x=−3.9)。
シルクは **x −9.0〜+17.0**(=ボディ26mm)なので、**モジュールは +x 方向へ寝る**。
本設計では U11 を回転させて使うので、盤外へモジュールがはみ出さない向きを選ぶこと。

### ★発注前に確認すること

1. **スタックハイト 5.2mm とポゴピンの整合** — ★**2026-09-02 に v0.9.0 実機で
   顕在化し、長尺ポゴへの差し替えで解決。基板改版は不要だった。**

   `mech.ato` は「モジュール裏〜基板間隙 2.6mm・ポゴピン自由長3mm」を想定していたが、
   採用したソケット(TE 1473005-4)のスタックハイトは 5.2mm。**自由長3mmでは届かず、
   JTAG が一切通らなかった**。

   実機での切り分け(この形で出るので次回の目印に):

   ```
   無圧            検出 0/141   TDO は浮いて High (Raw IDCODE 0xffffffff)
   モジュールを押す 検出 79/79   IDCODE 0x41111043 が安定して読める
   ```

   **無圧で0・押圧で全数**という分かれ方をしたら、まずここを疑う。間欠接触では
   なく「単純に届いていない」の指紋。

   長尺ポゴへ差し替え後は **既定速度 3.75MHz で 18/18 検出、SRAMロードも押さえずに
   一発**(差し替え前は 0.469MHz へ落として手で押さえ、ロード成功まで37回リトライ)。

   ※差し替え直後に一度 `TDO is stuck at 0` が出たが、モジュールが座り切って
     いなかっただけの過渡状態だった。座り直すと解消。**この症状で XY 位置を
     疑う必要はない**(ポゴ列の位置は 29.42mm で、README の「縦33mm」との
     3.88mm 差は原点定義の違い)。

   ★**PHY LEDタップ(PG5-8)は実装から消えている**ので、こちらは無関係。
     Ethernet LED は GPIO 直結の1経路のみ(§9.7 参照)。
2. **買う型番とランドの一致**: 汎用品で代替する場合、列間8.60mm・ラッチパッド位置・
   位置決め穴径(φ1.6/φ1.1の非対称)を実測で確認する
3. **JLCの実装ライブラリ収載は未確認**。実装対象外なら手はんだになるが、
   200本0.6mmピッチなので極力JLCに実装させたい

## 1. 配置の大方針(信号の流れ)

```
[左辺] 映像入力(D-SUB15 / 2x8) → [中央左] アナログ前段 → [中央] TVP7002
   → [下辺] スタッキングヘッダ(FPGAへ24bit+DATACLK)
   → [右辺] GbE(MagJack×2)
[上辺] 電源(USB-C/DC) と 音声(PCM1808/XO/ジャック/TOSLINK)
```
- 映像は左→右へ一方向に流し、アナログ入力とデジタル出力を離す。
- 電源は上辺にまとめ、各レールを各負荷へ最短で分配。
- **クリティカルネット優先度: ① GbE MDIペア ② TVP DATACLK(ドットクロック~80MHz)
  ③ アナログRGB入力 ④ 音声MCLK(12.288MHz)**。この順で最短・最良の経路を確保。

## 2. ネットクラス / 線幅 / クリアランス

**設定済み**(`layouts/default/default.kicad_pro`、`net_settings.classes` + `netclass_patterns`)。
`ato build` はこの `.kicad_pro` を上書きしないので設定は保持される。

| ネットクラス | 線幅(既定) | クリアランス(下限) | ビア | 差動幅/ギャップ | 割当パターン(実ネット名) |
|---|---|---|---|---|---|
| Default | 0.20mm | **0.127mm** | 0.45/0.25 | — | 上記以外すべて |
| Power | 0.40mm | 0.20mm | 0.8/0.4 | — | `power_5v*` `p5v_ext` `p3v3_io*` `p3v3_a*` `p3v3_ext` `p1v9_a*` `p1v9_d*` `hdr_p4-p3v3_ext` |
| GbE_diff | 0.20mm | 0.40mm | 0.45/0.25 | **0.20/0.13mm** | `eth?_?_P` `eth?_?_N` (8ペア) |
| Analog_RGB | **0.20mm** | **0.20mm** | 0.45/0.25 | — | `vin_*` `rin3` `gin3` `bin3` `sogin3` |
| Clock | 0.25mm | 0.25mm | 0.45/0.25 | — | `dataclk` `ext_clk` `audio_mclk` `audio_bck` `audio_lrck` |

**「線幅」は新規配線時の既定値、「クリアランス」はDRCが見る下限**という違いに注意。
太さは配線しながら `W`キーで候補から切り替えられる(候補:
0.1 / 0.127 / 0.15 / 0.2 / 0.25 / 0.4 / 0.6 / 0.8mm)。ビアも `V`キーで
0.45/0.25(ファンアウト用)・0.6/0.3(汎用)・0.8/0.4(電源)から選べる。

★2026-08-12の変更2件:
- **Analog_RGB を 0.30/0.25 → 0.20/0.20 に緩和**。映像入力が2系統になってTVPから
  引き出す本数とビアが増え、ファンアウト区間を出た後で詰まった。線幅0.25→0.20mmの
  直流抵抗増は100mmで0.194→0.243Ω(直列220Ωに対し0.088%→0.110%、RGB555の0.007 LSB)。
  アンチエイリアスで21.9MHzに落としているので伝送線として扱う長さ(波長の1/20=381mm)にも
  届かない。**ただしスイッチングする信号と並走させないのは配置で担保すること**。
  なおビアは元から0.45/0.25でDefaultと同一(他クラスより厳しくはなかった)。
- **GbE_diff の割当を差動ペアだけに絞った**。`eth1_*`/`eth2_*` だとLED8本
  (`eth*_led_*`)とセンタータップ2本(`eth*_ct`)まで巻き込み、静的な信号に
  スキュー±0.15mm・ビア2本・対他ネット0.6mmが掛かって配線が無用に難しくなっていた。

### 微細ピッチの引き出し(2026-08 更新)

**旧設定(Default クリアランス0.20mm・ビア0.6/0.3)では 0.5mmピッチQFPと
0.6mmピッチSO-DIMMからファンアウトできなかった**ので、JLCPCB 4層の実能力に合わせて
下限を緩めた。数字の根拠は
[JLCPCB PCB capabilities](https://jlcpcb.com/capabilities/pcb-capabilities)(2026-08確認):

| 項目 | JLC 4層の下限 | 本基板の設定 | 備考 |
|---|---|---|---|
| 線幅 / 間隔 | 0.09 / 0.09mm | 0.10mm(基板最小値) | ネットクラス下限は 0.127mm(5mil) |
| ビア 穴 / 径 | 0.15 / 0.25mm | **0.25 / 0.45mm** | 「穴0.15mm」「穴0.2-0.25mmで径0.45mm未満」は**追加費用**。0.25/0.45が無償の下限 |
| ビア穴間 | 0.20mm | 0.20mm | 基板最小値 min_hole_to_hole |
| PTHパッド穴間 | 0.45mm | 0.45mm | KiCadは穴間を1種類しか持てないので `.kicad_dru` 側で Pad-Pad のみ0.45mmに戻す |
| 銅-基板外形 | ≧0.20mm | 0.25mm | **旧設定は0.5mmで過剰**。基板端の配線が通らなかった |
| シルク 線幅 / 文字高 | 0.15mm / 1.0mm | 0.15mm / 1.0mm | |

実際に通るかの計算(いずれもDefaultクラス):

- **0.5mmピッチQFP**(パッド幅0.28mm, 隣接パッド間0.22mm)
  - パッドから真っ直ぐ外へ: 0.15mm線 → 隣パッドまで 0.36-0.075 = **0.285mm** ✓
  - **パッドの間を通り抜けることは不可**(0.127線でも0.381mm必要 > 0.22mm)。
    内側のピンは外周へ出したあとビアで落とす(ドッグボーン)
  - ビアは0.5mmピッチに1列では入らない(0.45+0.127=0.577mm必要)ので**2列に千鳥**
- **0.6mmピッチSO-DIMM**(パッド幅0.4mm)
  - 0.15mm線で真っ直ぐ: 隣パッドまで 0.4-0.075 = **0.325mm** ✓
  - ビアは0.6mmピッチの1列でぎりぎり合法(0.577mm ≤ 0.6mm、穴間0.35mm ≥ 0.2mm)
- **電源(Power)の 0.4mm線は 0.5mmピッチパッドから直接出せない**
  (0.36-0.2 = 0.16mm < 0.20mm)。**パッド直近だけ0.2mmでネックダウンしてから広げる**

### ゾーン(GNDベタ)のクリアランス

ゾーンのクリアランスは **0.25mm**。0.5mmだとベタが引っ込み過ぎて微細ピッチ部品の下で
リターン経路が切れる。

★2026-08-13に実際に適用した。それまで「0.5→0.25にした」と書いてあったが、
  **実際には `.kicad_pro` の `defaults.zones.min_clearance` が 0.5 のままで、
  新規ゾーンを作ると0.5になっていた**(記述が事実と食い違っていた)。現在は
  - `defaults.zones.min_clearance` = 0.25 … 新規ゾーンの既定
  - 既存ゾーン7つ … 個別に 0.25 へ書き換え済み
  の両方を適用してある。ゾーンは gnd / chassis(F.Cu) と
  p3v3_a / avdd / p5v / ft_vcore_1v8 / p3v3_io(In2.Cu)の計7つ(以前は4つだった)。

★既定値の変更は**新規ゾーンにしか効かない**。ゾーンを追加したら、そのゾーンの
  クリアランスが0.25mmになっているか確認すること。

### 最小サーマルスポーク数は 1(2026-08-13 変更)

`min_resolved_spokes` を **2 → 1** にした。2のままだとDRCが大量にエラーを出す。

サーマルスポークはベタとパッドを繋ぐ「橋」で、数が多いほど熱と電気の接続が良い。
2本要求するのが定石だが、この基板は
  - 0.5mmピッチ(TVP7002/FT2232H)や0.6mmピッチ(SO-DIMM)のパッドが密集していて、
    パッドの周囲にスポーク2本ぶんの逃げが取れない
  - 映像入力が2系統になって部品密度がさらに上がった
ため、2本を維持するのは現実的でない。

1本でも電気的な接続は成立する(DRCの `min_connection` 0.1mm は別途効いている)。
★ただし**熱を持つ部品は例外**。LDO(U4/U5)やTVP7002の露出パッドのように放熱が要る
  ところは、スポーク数ではなく**サーマルビアの本数**で稼ぐこと(0章・7章参照)。
  小さなパスコンやプルアップ抵抗のGND側は1本で問題ない。

- **差動ペア認識**: GbEネットは `+/-` でなく大文字 `_P`/`_N` 接尾辞(例 `eth1_1_P`/`eth1_1_N`)。
  KiCadの差動ペアルータ(ホットキー`6`)/DRC結合チェックは `+/-` か大文字 `P/N` のみ認識するため、
  main.ato/mech.ato側で小文字→大文字化済み。8ペア(eth1_1〜eth1_4=ポート1, eth2_1〜eth2_4=ポート2)。
- **GbE_diff 差動幅/ギャップ 0.20/0.13mm** = 設定済みスタックアップ(H=0.2104mm/εr4.6)での
  エッジ結合マイクロストリップ解析値 ≈100Ω(W0.2/S0.13→99Ω, W0.2/S0.15→102Ω)。
  ★解析値なので**配線前にJLCの[インピーダンス計算](https://jlcpcb.com/impedance)またはKiCad内蔵の
  インピーダンス計算(Board Setup>Physical Stackup、スタックアップ設定済みなので即使える)で最終確認**すること。
- **カスタムDRC設定済み**(`default.kicad_dru`): GbEペア内スキュー≤0.15mm、非結合区間≤5mm、
  ビア数≤2/本、対他ネットクリアランス≥0.6mm、クロックのビア数≤3。配線するとこれらが自動チェックされる。
- **Analog_RGBのネット名**(2026-08-12にTVPの入力番号へ揃えて改名。自動命名は全廃):
  D-SUB15経路 = `vin_r3`/`vin_g3`/`vin_b3`(コネクタ側) → `vin_*3_ac`(0.1uF結合後)
  → `rin3`/`gin3`/`bin3`(TVPピン)。sync-on-green は `vin_g3_sog_ac` → `sogin3`。
  第2入力(2x5ヘッダ)経路 = 同じ並びで `*2`。CSYNCは
  `vin_csync2` → `vin_csync2_div`(1/2分圧後) → `vin_csync2_ac` → `sogin2`。
  以前は `c_ac-power-hv` のようなatopileの自動命名だったが追跡不能なので廃止した。
- SYNC(`hsync`/`vsync`/`hsync_a`/`hsout`/`vsout`/`fidout`)はDefault。長くなければ問題ない。
- 電源はできるだけ**L3プレーンのゾーン**で供給し、トレースは引き出しのみ。
- 高速信号(GbE/DATACLK)は**層をまたがない**(またぐ場合は隣接にGNDリターンビア)。

## 3. アナログRGB前段(D-SUB15 直近)

- **75Ω終端(R75)と100nF ACカップリング(C100nF)は D-SUB15 のR/G/Bピン直近**に置く。
  順序: コネクタ → ESD(EsdArray4) → 75Ω終端(→アナログGND) → 100nF直列 → TVP RIN_3/GIN_3/BIN_3。
- **ESDアレイ(ROHM EMZT6.8)は各入力をコネクタに最も近い位置**で保護(ストレス経路最短)。
- 緑のSOGカップリング(1nF)はGIN経路の近く。
- RGB3本は**等長・並走・周囲をアナロググラウンドでガード**。ビアを避け極力L1で。
- この区画のGNDはアナロググラウンド。デジタル出力(下辺)から遠ざける。

## 4. TVP7002(中央)

- **各電源ピン群に100nFデカップリングを"そのピンの直近"に**(合計14個, `dec_caps`)。
  ピンとキャップの間のループ面積を最小化。A33VDD/AVDD/PLL_AVDD/DVDD/IOVDDそれぞれ。
- **AVDD/PLL_AVDDのフェライトビーズ(fb_avdd/fb_pll)はTVP側**に置き、1.9Vアナログから分離。
- **H-PLLループフィルタ(r_filt 1.5k, c_filt1 100nF, c_filt2 4.7nF)は FILT1/FILT2/PLL_F
  (pin87/88/89)の直近**。ここが最も敏感。ループを小さく、他の信号から隔離。
- EP(pin101)→サーマルビア→GND(0章)。
- **デジタル出力(R/G/B[9:2] 24本 + DATACLK + HSOUT/VSOUT/SOGOUT/FIDOUT)は
  TVPの出力側(pin29-65側)から下辺のスタッキングヘッダ(hdr_p2/hdr_p4)へ短く**。
  **DATACLK(pin28→hdr_p4 F2/PCLKT7_0)は最短・直下GND連続**。
- 制御抵抗(r_i2ca/r_sda/r_scl/r_rst 各2.2k)とI2CはTVPの制御側(pin70-77)近く。
- 27MHz OSC(osc)+デカップリング(c_osc)は EXT_CLK(pin80)近く。

## 5. 同期(SYNC)

- 同期ESD(esd_sync)は D-SUB15 のHSYNC/VSYNCピン直近。
- VSYNC RC遅延(r_vs 220Ω + c_vs 1nF)とバッファ(LVC2G17)は同期経路上、TVPに近い側。
- バッファのVCCデカップリング(c_buf 100nF)はLVC2G17直近。

## 6. GbE(右辺・MagJack×2)

- **MagJack(HR911130A)は基板端**に開口を外へ向けて配置。J8(P1)からMDIペアを最短で。
- **MDI0-3±は差動ペア(GbE_diff)。ペア内で等長、短く、直線的に**。EXT P1(j8)から
  各MagJackへ。ペアの下はL2 GND連続。
- **チップ側センタータップ共通(P1ピン)→ 0.1µF → 論理GND**(各ポート1個、MagJack直近)。
- **P10(Bob-Smith/シャーシ基準)と SHIELD0/1 → シャーシGND**。
- **磁気部の下は論理GND/電源プレーンをくり抜き(keepout)**、シャーシGNDアイランドを作る。
- **論理GND ⇄ シャーシGND 間は 4.7nF/2kV(各ポート2個)で結合**(HV Yキャップ、
  絶縁ギャップをまたいで配置)。沿面/空間距離を確保。
- LED(pin11-14)はP1に信号が来ていないため未接続(配線不要)。

## 7. 電源(上辺)

- **入力**: USB-C(J10相当, CCにRd 5.1k×2をコネクタ直近)/ DCジャック。SJ1でEXTへ逆給電。
- **AZ1117-ADJ(1.9Vアナログ, ldo_a19)は約0.9W発熱** → SOT-223タブ下に**銅箔ベタ+
  サーマルビア**。他の熱源(他LDO)と離す。分圧抵抗(r_fb_top 120Ω/r_fb_bot 62Ω)は
  ADJピン直近(ノイズ拾い防止)。
- 各LDO入出力のバルクコン(10µF)はLDO直近。レール別に負荷へ最短分配。
- レール整理: 5V→{IO 3.3V(ldo_io), アナログ3.3V(ldo_a33), 1.9Vアナログ(ldo_a19)},
  IO 3.3V→1.9Vデジタル(ldo_d19, TLV70019)。**アナログ系LDOはアナログ区画寄り**に置く。

## 8. 音声(上辺〜中央上)

- **PCM1808×2(adc_dsub/adc_line)**: 入力ACカップリング(1µF)を各入力直近、VREFデカップ
  (10µF+100nF)を各ADC直近。
- **12.288MHz XO(xo_audio)は両ADCのSCKIに近接**し、MCLK配線を短く(クロックネットクラス)。
  BCK/LRCKはFPGA(hdr_p4)から。DOUTは個別にhdr_p4へ。
- 音声アナログ5V(fb_audioでデジタル5Vから分離, c_5va 10µF)はADC VCCへ。
- 音声入力のESD(esd_audio)はジャック/コネクタ直近。
- **音声区画は電源スイッチング系やデジタルから離す**(ハム/ノイズ対策)。

## 9. TOSLINK(PLR135, 手実装)

- **C1(c_spdif 100nF)は Vcc-GND 間、TOSLINKの7mm以内**(データシート必須要件)。
- ★**L2=47µH(電源直列)が現設計に未実装**。データシート推奨。追加を検討
  (Vcc直列にフェライト/インダクタ。ノイズ源からの絶縁)。→ main.ato修正候補。
- 光受信は感度が高いので、高速デジタル/スイッチングから離す。

## 9.5 デジタルRGB入力(J13 + U14/U15/U16 + D4/D5)— 2026-08 追加

```
J13(1.25mm 8極, 基板端) → D4/D5(ESD) → 10kプルダウン → U14/U15/U16(LVC2G17) → SO-DIMM P4クラスタ
```

- **J13 は基板端**にコネクタ開口を外向きに。右アングルSMDなのでケーブルは横に出る。
  取付タブ(pad9/10)はGNDに落とす=実装強度を稼ぐので、GNDベタに接続すること
- **D4/D5(ESD)は J13 直近**。保護はストレス経路が短いほど効く(アナログ側と同じ方針)
- **U14/U15/U16 は J13 とSO-DIMMの間**に置く。5V TTLが基板上を長く走らないよう
  **バッファはコネクタ寄り**に置き、バッファ後の3.3V信号でSO-DIMMまで引く
- **各バッファのVCCデカップリング100nFはIC直近**(3個)
- **5V TTL区間(`drgbi_*`)をアナログRGB前段・音声アナログと並走させない**。
  ドットクロック速度(最大14MHz程度)でフルスイングするので、
  アナログRGB入力(§3)からは物理的に離す。デジタル区画側に寄せて配置する
- 3.3V側(`drgb_*`)6本はDefaultクラスで可。等長は不要(FPGA内でオーバーサンプリング
  するので数百ps差は無関係)。ただし **HS/VS は色4bitと束ねず、GNDを隣に添えて引く**
  (同期を1回取り落とすと1フレーム崩れる)
- SO-DIMM側の受けは pin132/136/140/142/144/146 = P4クラスタの偶数側。
  ソケット上で x方向に連続して並ぶので、6本まとめて素直に引ける

## 9.6 将来拡張用デバッグ端子(J4, 2×15)— 2026-08 追加

- 引き出すのは **SO-DIMM 偶数側 pin54〜94**(pin56=GNDのみ除く)の20本。
  ソケット上で **x=146.8〜158.8mm・y=103.0mm** に0.6mmピッチで一列に並ぶ
  (ソケット原点 146.65,99.70 / 180°回転時の実測値)
- **SO-DIMM昇順 ↔ ヘッダpin昇順の単調割当**にしてあるので、素直に扇形に広げれば
  交差は出ない。ヘッダは**ソケットの下側(y>103の領域)**に置くのが最短
- 近傍の既存部品: X2(音声XO, 157.3/101.8)・U4/U5(EEPROM, 155.9/111.6 と 165.4/112.2)・
  U8(TLV70019, 146.3/112.9)。**X2(12.288MHz)の直下を20本で横切らないこと**
  (音声MCLKにデジタルノイズが乗る)。ヘッダはこれらより下(y≈125〜140)に置き、
  X2の下を避けて左右どちらかに寄せて通す
- 2×15の外形は 35.6×5.1mm(パッド中心間)。基板の下辺側(y=149)までは余裕がある
- **未使用のままでも構わない**(手実装/DNP)。基板にパッドさえあれば後から生えてくる

## 9.7 Ethernet LED の二経路(PG5-8 / JP4-7)— 2026-08-11 追加

```
経路A(既定) i5モジュール底面PHY LEDパッド → ポゴピン(PG5-8) → 220Ω(R27-30) → MagJack pin11/14
経路B(代替) FPGA GPIO → はんだジャンパ(JP4-7, 既定=開) → 220Ω(R16-19) → 同じアノード
```

- **ポゴピン位置は rainbow-board の実測値**(SO-DIMMソケット原点からの相対):
  JTAG 1×04 = (−24.15, −33.30) / ETH1 LEDs = (−22.08, −29.59) / ETH2 LEDs = (−22.15, −15.43)。
  JTAGの縦33mmが本設計の既存想定と一致したので座標系は信用できる。
  **rainbowのソケット向き基準なので、本設計の回転に合わせて置き換えること**
- ポゴピンはモジュール下(=モジュールが覆う領域)に入るので、**周囲に背の高い部品を置かない**
- **JP4-7 は手が届く位置に**(既定=開。閉じてGPIO経路に切り替える運用があるため)
- ★**両経路を同時に生かさないこと**。アノードで押し合う(≒7.5mA)。
  経路A運用時はゲートウェアでGPIO(io_r1/io_t1/io_u1/io_y2)を入力にしておく

## 10. MACアドレスEEPROM

- 24AA025E48×2(0x50/0x51)はI2Cバス(TVP/ArgusXと共有)上。各100nFデカップリング直近。
- MagJack近く(将来のポート別ID対応)に置くと配線が素直。

## 11. コネクタ/ヘッダ配置(物理)

- **スタッキングヘッダ hdr_p2(P2)/hdr_p4(P4)/eth.j8(P1)は下辺**、EXT基板と1対1嵌合。
  ★位置・間隔はEXT実寸で確定(最優先)。裏面実装(ハット)。
- 外部コネクタは基板端に開口を外向き: D-SUB15(左), MagJack×2(右), USB-C/DC(上),
  3.5mm/TOSLINK(上), 2x8ボックスヘッダ(左, ArgusXリボン)。
- ArgusX 2x8はD-SUB15と同一前段に並列(排他使用)。近接配置でスタブ最短。

## 12. 作業手順(推奨)

1. EXT採寸 → スタッキングヘッダ3本と基板外形を確定。
2. 外部コネクタを基板端に配置(開口方向確定)。
3. TVP7002を中央に、上記ブロックを1〜10の近接ルールで配置。
4. GNDプレーン(L2)敷設、GbE磁気部keepout/シャーシアイランド作成。
5. 配線: ①GbEペア ②DATACLK ③アナログRGB ④音声MCLK → 残り。
6. `kicad-cli pcb drc` でDRC。ネットクラス/差動ペア/クリアランス違反を潰す。
7. `ato build` で回路変更を反映(配置は保持)。差分は都度DRC再確認。

### ★`ato build` と pcbnew を同時に開かないこと

**`ato build` は必ず `default.kicad_pcb` を書き換える**(`--exclude-target pcb` を
付けても "Updating PCB" ステージは走る。ターゲット指定では止められない)。
pcbnew が同じファイルを開いたままだと:

- pcbnew はメモリ上の**古い**基板を保持している
- そこで保存すると **atopile が追加した部品・ネットが消える**
- `~default.kicad_pcb.lck` は単なる助言でロックにはならない

手順を守る:

1. pcbnew で**保存して閉じる**
2. `ato build` を実行
3. pcbnew を開き直す(`File > Revert` でも可)

**フットプリントを差し替えたときは `ato build` を2回流すこと。** 1回目は基板上の
フットプリントを新しいものに置き換えるだけで、**そのパッドにネットが付かない**
(実測: U11差し替え直後は 123あったネット割当が0になった)。2回目で復帰する。
1回目の状態で保存/配線すると、ソケットが全ピン未接続に見える。

また**パッド位置が動いた差し替えでは、既存のゾーン塗りが古くなる**。U11の列間を
6.6→6.2mmにした直後、`clearance` 違反が 70→247件に増えたが、その +177件は全て
「古い塗りとパッドの距離不足」だった(ゾーン再フィルで70件に戻ることを検証済み)。
**pcbnew で `B` を押してゾーンを再フィルする**こと。あわせて既存4ゾーンの
クリアランスを 0.5→0.25mm にする(§2 のゾーン項参照)。

`ato build` が部品を追加した場合、新規フットプリントは**基板外(y=0近辺)に置かれる**ので
そこから盤内へドラッグする。既存部品の座標・配線・ゾーン・スタックアップ・
`.kicad_pro`(ネットクラス)・`.kicad_dru` は保持される(検証済み)。
なお `tools/ingest_parts.py` で部品を取り込むと `fp-lib-table` が更新されるため、
その場合も **pcbnew の再起動が必要**(atopile自身がそう警告する)。

### DRCの読み方(2026-08 時点の既知の残件)

未配置・未配線の段階では大量に出る。**配置/配線で自然に消えるもの**と
**発注前に必ず潰すもの**を分けて見る。

| 種別 | 数 | 位置づけ |
|---|---|---|
| `silk_overlap` / `silk_over_copper` / `silk_edge_clearance` | 199/146/27 | 見た目のみ。最後にリファレンス文字を整理する |
| `shorting_items` / `clearance` / `solder_mask_bridge` | 38/70/55 | 大半は**基板外に積まれた未配置部品の重なり**。配置後に再評価する |
| `starved_thermal` / `isolated_copper` | 16/8 | ゾーン敷設のやり直しで解消する |
| `copper_edge_clearance` | 5 | **要対応**: J9(USB-C) pad2/3・J2 SHIELD0 が外形から0.176mm(JLC下限0.2mm)。数十µm内側へ寄せる |
| `text_height` | 1 | **要対応**: 0.8mmのシルク文字が1つ(JLC下限1.0mm)。1.0mmに直す |
| U11パッドとの重なり | — | **要対応**: **C3(音声VREFコンデンサ)が U11 のパッド上に完全に重なっている**(距離0.000mm)。X2(12.288MHz XO)もU11パッドに近すぎる。ソケット差し替え前から出ていた指摘なので、SO-DIMM周辺の配置をやり直すこと |

`annular_width`(アニュラー幅ゼロ)と `padstack` は各10件あったが **2026-08に解消済み**。
原因はEasyEDA由来フットプリントの**機械取付穴が「穴径=パッド径のPTH」**になっていたこと
(アニュラーリングが負になり製造不可の指摘)。J2/J11(MagJack)・J6(3.5mmジャック)・
J9(USB-C)・U11(SO-DIMMソケット)の各2穴を **NPTH(`np_thru_hole`)に変更**した。
これらは樹脂ボスの位置決め穴なので非メッキが正しい。`parts/*/*.kicad_mod` と
`default.kicad_pcb` の両方を直してある(再取り込みすると戻るので注意)。

## レビュー分担

- 人(KiCad): 2〜5の配置・配線をインタラクティブに実施。
- AI: ネットクラス/差動ペア/DRCルールのセットアップ、DRCレビュー、制約逸脱の指摘、
  回路変更(main.ato)反映。EXT採寸値をもらえばヘッダ位置/外形を確定。

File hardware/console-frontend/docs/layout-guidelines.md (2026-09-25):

# RetroCastX 小亀基板(コンソール入力基板) レイアウト指示書

回路は `main.ato`(atopile)。ネットリスト/PCBは `ato build` が生成し、**配置は保持される**。
メイン基板側の指示書は `../../adc-frontend/docs/layout-guidelines.md`。

---

## 0. 基板全体

| 項目 | 値 | 理由 |
|---|---|---|
| 外形 | **100 × 100 mm** | メイン基板と同じ。JLCの最安枠に収まる |
| 層数 | **2層で足りる** | 信号は数本・数十mmしかない。裏面をベタGNDにすれば映像(〜30MHz)には十分。メイン基板(4層)と違ってDDRもGbEも無い |
| 板厚 | 1.6mm | **コネクタのスロット寸法が t=1.6 前提**(図面の "T:1.6")。変えてはいけない |
| 取付穴 | **M3 ×5(H1-H5)** | メイン基板と同じ個数・同じ座標にする。基板左上を原点にすると H1 (5,5) / H2 (5,95) / H3 (95,95) / H4 (95,41) / H5 (70,5)。四隅の3つ + 辺の途中2つという配置(メイン基板は残る1隅をコネクタが占めている)。**片方が4個だとスペーサが1本浮く** |
| 裏面 | ベタGND(切らない) | 映像の帰り電流の経路。スリットを入れると同期にリンギングが乗る |

★金属スペーサ・金属筐体だと論理GNDが筐体に落ちる点はメイン基板と同じ注意
(あちらは MagJack のシャーシGND島を 4.7nF/2kV で分離している)。

---

## 1. ★RCAジャック(RCA-105)の形状 — ここが配置を決める

メーカー図面(出品ページの画像に入っている)から読んだ寸法。**2端子しかなく、
両方ともコネクタの軸線上**にある。

```
        側面(軸を含む断面)                          嵌合面から見た正面
   ←─ 9.30 ─→|←──── 10.00±0.20 ────→
   ┌──────────┐ 嵌合面                       ┌────────────┐  ┬
  ( φ8.30    │  ★ = 基板外形をここに合わせる  │  ╭──────╮  │  │ 5.00
   └──────────┘  │                           │  │ φ3.50│  │  ┴ ← 筒の軸
        筒は基板の外へ  │  ┌─ pad1 (4.80)      │  ╰──────╯  │
        9.30 張り出す  │  │  ┌─ pad2 (8.30)    └──┬──┬────┘  13.00
                      ▼  ▼  ▼                    │足│        │
   ────────────────────┼──┼──┼─── 基板 (t=1.6)    └──┘        ┴
                       └──┴──┘ 足 3.70          ←── 10.00 ──→
                                                 筒の軸は基板面から 8.00
```

| 寸法 | 値 |
|---|---|
| フランジ(基板に載る枠) | **10.00 幅 × 13.00 高** |
| 本体の奥行 | 嵌合面から後ろへ **10.00 ±0.20** |
| 筒 | **φ8.30 ±0.10**、嵌合面から**前へ 9.30 張り出す** |
| 筒(軸)の高さ | 基板面から **8.00**(フランジ上端から 5.00 下) |
| 足 | 3.70 長(t=1.6 なら裏へ 2.1 出る) |
| ランド | pad1 = スロット **2.30 × 1.50** @ 嵌合面から 4.80 / pad2 = スロット **1.00 × 2.30** @ 8.30。**どちらも軸線上(y=0)** |
| 極性 | **pad1 = シェル(GND)、pad2 = 中心導体(信号)** ← ★現物で導通確認すること |

- 図面は**裏面視(Printed-bottom view)**だが、2パッドとも軸線上なので鏡像にしても同じ。
  そのまま表面のフットプリント(`parts/_mech/RCA105.kicad_mod`)に使っている。
- フットプリントの**原点 = 嵌合面 × 軸**。silk が基板に載る 10×10 の枠、F.Fab に
  筒の張り出し(x = −9.3〜0)を描いてあるので、**基板外形を x=0 に合わせる**だけでよい。

### 並べる間隔は 12〜13mm

枠は 10.0mm なので物理的には 10.5mm ピッチで並ぶが、**RCAプラグの握りは φ10〜14mm ある**。
10.5mm ピッチだと隣同士に同時に挿せない。AV機器のパネルも 12.5mm 前後なので、
**12.5mm を基準**にする(5個で 62.5mm)。

### ミニDIN4(MJ-373/4B)の形状

| 寸法 | 値 |
|---|---|
| フランジ | 14.0 幅 × 13.0 高 |
| 本体の奥行 | 嵌合面から後ろへ 12.7 |
| ランド | φ1.2 ×4(x = 8.5 / 11.0、y = ±3.25)+ シェル用スロット 2.8×0.8 ×3((4.7, 0) 縦、(5.5, ±6.85) 横) |
| 原点 | 嵌合面(x=0) × 中心線(y=0)。**RCAと同じ流儀**なので基板外形を x=0 に合わせる |

---

## 2. コネクタの並び

100mm の辺に 6 個並べる。合計幅は 14.0(ミニDIN4)+ 12.5 × 5 = 76.5mm なので余裕がある。

```
   ┌──────────────────────────────────────────────────────────┐ ← この辺を前面にする
   │  S端子    赤      青      黄      白      赤              │
   │ (DIN4)   (Pr)    (Pb)  (CVBS)  (音声L) (音声R)           │
   │  14.0    12.5    12.5   12.5    12.5    12.5             │
   │          └─ コンポーネント(Y=CVBS兼用/Pr/Pb) ─┘           │
   │                          └─ コンポジット+音声(黄白赤) ─┘   │
   └──────────────────────────────────────────────────────────┘
```

- **コンポーネント3本(Pr / Pb / Y=CVBS兼用)が隣り合う**ようにしてある。YPbPr で
  使うときに3本のケーブルが1か所にまとまる。
- 同時に **CVBS(黄)→ 音声L(白)→ 音声R(赤)** が並ぶので、黄白赤の3本AVケーブルも
  そのまま挿せる。
- **赤が2個(Pr と 音声R)あるが両端に分かれる**ので混同しにくい。それでも
  シルクには `Pr` / `AUDIO R` と必ず書く。
- 音声L に白が無い色ロットを買った場合は灰か黒にして、シルクで `L` と明示する。
- S端子を端に置くのは、ミニDIN4のフランジが 14mm で一番大きいため。

---

## 3. 配置の大方針(信号の流れ)

```
ジャック ── ESD ── 75Ω終端 ── 100nF ── (中点バイアス 10k) ── スイッチ ── FFC
 前面の辺        ↑ここまで各ジャックの直近          ↑基板中央       ↑FFCの辺
```

| 部品 | 置き場所 |
|---|---|
| **D2**(ESDアレイ) | **CVBS / 音声L / 音声R** = 右の3ジャックの直近(1chあまる) |
| **D3**(ESDアレイ) | **S端子C / S端子Y / Pr / Pb**(io1..io4 の順)= 左の3ジャックの直近。Y と C を入れ替えてミニDIN4 との交差を消してある |
| R2/R4/R6/R8(75Ω) | **ジャックの足のすぐ横**(終端は送り出しから見て一番奥に置きたいが、この基板では「スイッチより手前」が必須条件) |
| C2/C3/C5/C6(100nF 結合) | 75Ωの直後 |
| R1/R3/R5/R7(10k バイアス) | 各チャンネルの結合コンデンサの直後。**vbias ノードは C1(10µF)の近くへ集める** |
| U1(TS5A23159) | **FFCコネクタ(J1)の近く**。スイッチの出口から FFC までを短くする |
| R9(選択線プルダウン) | U1 の IN1/IN2 のそば |
| R10-R13(10k) | 音声2本とバイアス分圧。音声の 10k はジャックのそば |
| LED1/LED2 + D1 + C4 | **ジャックの近く**(光って見える位置)。D1 と C4 は LED の電源のそば |
| J1(FFC) | メイン基板を向ける辺。**1番ピンにシルクを打つ** |

---

## 4. 配線ルール

- **映像線(Y/C/CVBS/Pr/Pb)は裏面ベタGNDの上を通す。** 線幅 0.3mm、長さは 40mm 以内を
  目安に。8fsc(28.6MHz)でも 40mm は電気的に短い(往復0.4ns)ので特性インピーダンスは
  問わないが、**ベタの切れ目の上は通さない**。
- **LED_DATA(800kHz、立ち上がりが速い)を映像線と長く並走させない。** 間にGNDを挟むか、
  基板の別の辺を回す。メイン基板側に直列220Ω(源端整合)が入っている。
- **vbias(1.65V)は AC的にはGND扱い。** C1(10µF)をバイアス分圧の直近に置き、
  そこから各チャンネルの 10k へ配る。ここが長いと 4 チャンネル間の漏れが増える
  (10k → vbias → 10k の経路。C1 が効いていれば -70dB 級)。
- **シェル/GNDは太く。** RCAの pad1 とミニDIN4のスロット3本は、裏面ベタへビアで直接。
  ジャックのシェルは静電気の入口なので、細いネックを作らない。
- 3.3V/5V は FFC から来るだけなので細くてよい(LEDの 5V だけ 0.4mm 以上)。

---

## 4.5 ★フットプリントを差し替えたときの手順(踏んだ罠)

`main.ato` で部品の品番/サイズを変えると、`ato build` は**既存のフットプリントを
その場で置き換える**(配置・回転・配線・ゾーンはそのまま残る。これは助かる)。
ただし2つ落とし穴がある。**2026-09-21 に 0402 → 0603 の差し替えで両方踏んだ。**

1. **1回目の build では新しいパッドにネットが付かない。**
   差し替えとネット割当が同じパスで走るため、置き換わったパッドが `(net …)` を
   持たない状態で書き出される。症状は **pcbnew でラッツネストが出ない** / DRCの
   「未配線」が減る(ネットの無いパッドは接続判定の対象外)/ パッドが他ネットの
   配線に乗っていると `shorting_items` が出る。
   → **`ato build` をもう一度走らせる**。それだけで直る。確認方法:

          grep -c '(pad ' layouts/default/default.kicad_pcb   # パッド総数
          # ネット未割当パッドが0であること(下のワンライナーで数える)
          python3 -c "import re,pathlib;s=pathlib.Path('layouts/default/default.kicad_pcb').read_text();\
          print(sum(1 for m in re.finditer(r'\(pad \"[^\"]+\"[\s\S]{0,700}?(?=\(pad \"|\Z)',s) \
          if not re.search(r'\(net \d+ \"', m.group(0))))"

2. **ゾーンの塗りが古いまま残る。** パッドが大きくなった分だけGNDベタが食い込み、
   `clearance`(ゾーン 0.5mm に対して現状 0.03mm)と `solder_mask_bridge` が大量に出る。
   → **pcbnew で `B`(全ゾーンを塗り直す)**。ヘッドレスなら:

          /Applications/KiCad/KiCad.app/Contents/Frameworks/Python.framework/Versions/3.9/bin/python3 -c \
          "import pcbnew;b=pcbnew.LoadBoard('layouts/default/default.kicad_pcb');\
           pcbnew.ZONE_FILLER(b).Fill(b.Zones());pcbnew.SaveBoard('layouts/default/default.kicad_pcb',b)"

   0402→0603 ではこれで銅箔系の違反(clearance / shorting / mask bridge)が**全部ゼロ**に
   なった。残るのは `silk_overlap`(シルクの重なり、31→67件)だけで、これは大きい部品に
   した代償なので、配置の微調整とシルクの整理で潰す。

★**PCBファイルを消して作り直すのは禁止。** 配置が飛ぶ(2026-09-21 に実際に飛ばした)。
フットプリントのプロパティ(LCSC番号等)が古いまま残るときだけ、
`(property "atopile_address" "<名前>")` で該当ブロックを特定して**その1個だけ**消す。

3. ★**ブロックを1個消す場合も、その部品の配置は失われる。**(2026-09-22、メイン基板の
   J13 で踏んだ。(86.8, 107.2) に置いてあったものが (86.3, 107.5) にずれた。)
   **消す前に `(at x y [rot])` を控えて、build のあとに書き戻すこと。**
   pcbnew を開ける状況なら **Tools → Update Footprints from Library** の方が安全
   (位置・回転を保ったままライブラリの内容だけ更新される)。
4. ★**`lock_designators.py` は最後の `ato build` の後に走らせる。** ロックの後に
   build すると PCB 側のデジグネータだけが欠番に戻ることがある(同じく J13 で踏んだ。
   ロックは「変更なし」と言うのに PCB は J3 になっていた)。**最後に PCB を直接
   grep して確かめる**のが確実。
戻せる保険は `build/builds/default/backups/default.<時刻>.kicad_pcb` と
`build/builds/default/default.pcbnew-0.<時刻>.kicad_pcb`(毎ビルドの直前状態)。

## 5. 製造(JLCPCB)

- **2層・t=1.6・HASL** で足りる。部品はSMDが 20 個ちょっと(0402中心)で、
  **コネクタ類(RCA×5、ミニDIN4)は手実装**なので PCBA から外れる(`has_part_removed`)。
- **スロット穴(PTH)が4種類ある**。ガーバー/ドリルを出したあと、
  **スロットが route コマンドとして出ているか**を確認すること(円穴に化けていると
  コネクタが入らない)。

  | 部品 | スロット |
  |---|---|
  | RCA-105 ×5 | 2.30×1.50 と 1.00×2.30(各ジャック2個) |
  | MJ-373/4B | 0.8×2.8 ×1、2.8×0.8 ×2 |

  JLCのPTHスロット最小幅は 0.5mm なので、いずれも余裕がある。
- フィデューシャル(FID1-3)は非対称に3個。0.5mmピッチ(FFCコネクタとVSSOP-10)が
  あるので入れておく。

---

## 6. 発注前チェックリスト

`../README.md` の末尾にも同じものがある。**レイアウトを終えた時点で全部当たること。**

1. **FFCの向き**: type A(同面接点)で2枚を同一平面・開口部を向かい合わせにする前提で、
   小亀側のピン割当を**逆順(n ↔ 17-n)**にしてある。紙に描いて確認し、
   **通電前にテスターで pin1↔pin1 の導通**を見る
2. **RCA-105 の極性**: pad1=シェル(GND)/pad2=中心導体(信号)を現物で導通確認。
   2端子しかないので取り違えると**映像をGNDへ短絡する**
3. **RCA-105 のランド**: 買った現物で 4.80/8.30 とスロット寸法を実測
   (同じ「RCA-105」でも出品元で微妙に違うことがある)
4. **ミニDIN4**: 3番がプラグの輝度ピンに導通するか
5. **メイン基板側の 75Ω**: `ch_y`/`ch_c` が `VideoInputChannelNoTerm`(終端なし)に
   なっているか。両方で終端すると振幅が半分になる
6. 取付穴が**5個**で、メイン基板と同じ座標(H1 5,5 / H2 5,95 / H3 95,95 / H4 95,41 /
   H5 70,5)になっているか(重ねられるか)

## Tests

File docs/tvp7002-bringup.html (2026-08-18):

RetroCastX · TVP7002 hand-wire bring-up

# TVP7002 最小動作確認チェックリスト

手配線で TVP7002(100-TQFP)を最低限動かす手順。Stage A=電源+リセット+I2Cで「生存確認」、Stage B=実映像を取り込む。ピン番号はデータシート(SLES206C)準拠。

◐ テーマ切替

前提: 100-TQFP(0.5mmピッチ)+裏面PowerPAD。生チップは QFP100→変換基板にハンダ付けしてから配線。PowerPAD(裏面)はGNDに落とす。電源は実質 3.3V と 1.8〜1.9V の2系統でよい(低圧レールは全て推奨1.8〜2.0V)。シーケンス不要(全レール500ms以内に安定)。

## 電源 電源・GND(全ピン給電)

各電源ピン群に 0.1µF を至近配置 + 各レールに 10µF バルク。AVDD/PLLはフェライトビーズ経由が理想(ベンチは直結でも可)。

レール | ピン | 接続先
A33VDD | 13, 14, 93, 94 | 3.3V
IOVDD | 26, 41, 53, 66 | 3.3V
AVDD | 4, 6, 7, 19 | 1.8〜1.9V
PLL_AVDD | 84, 85 | 1.8〜1.9V
DVDD | 39, 69 | 1.8〜1.9V
A33GND | 12, 15, 92, 95 | GND
AGND | 3, 5, 8, 20 | GND
PLL_AGND | 83, 86, 90 | GND
DGND | 40, 68 | GND
IOGND | 27, 42, 54, 60 … | GND
NSUB | 21, 91 + 裏PAD | GND

## Stage A 電源+リセット+I2C(生存確認)

これが真の最小構成。ストラップを配線し、I2Cで応答すればチップは生きている。

- 70 PWDN → GND(Highでパワーダウン=Lowで通常動作)
- 71 RESETB → 10kΩで3.3Vプルアップ(任意でGNDへ押しボタン)。電源安定後1µs以上Low→Highで解除
- 73 I2CA → GND(2.2〜10k)。アドレス 0x5C(7bit)/ 0xB8書 0xB9読
- 72 TMS → GND(スキャンテスト無効)
- 76 CLAMP → GND ・ 77 COAST → GND(未使用入力)
- 80 EXT_CLK → GND(外部クロック不使用=内部リファレンスで動作)
- 74/75 SCL/SDA → 2.2kΩで3.3Vプルアップ → I2Cマスタ(Arduino / RPi / Bus Pirate 等)
- 79/82 VSYNC_B / HSYNC_B → GND(未使用同期入力)

✔ 生存確認: I2Cスキャンで 0x5C がACK すれば電源+チップOK。さらに R/W レジスタ(例 0x01)に書いて読み戻し一致で疎通確定。ここまでで「動いている」ことが確認できる。

## Stage B 実映像の取り込み(アナログ+同期+PLL+観測)

Stage A に以下を追加。1chでもDATACLKの確認は可能(RGBを見るなら3ch)。

- アナログ入力 映像源 →(75Ω終端→GND)→(直列0.1µFでAC結合)→ RIN_3=9 / GIN_3=98 / BIN_3=16(SOG使用時 SOGIN_3=97)
- 同期 3.3V TTL: HSYNC → HSYNC_A=81 ・ VSYNC → VSYNC_A=78
- H-PLLループフィルタ(映像クロック生成に必須) FILT1(87) —[1.5kΩ]— 節点 —[0.1µF]— PLL_F(89) FILT2(88) —[4.7nF]— PLL_F(89)
- 観測 ロジアナ/オシロで DATACLK(28), HSOUT(24), VSOUT(23), データ R/G/B[9:0]
- I2Cレジスタ初期化(必須): 入力選択 19h/1Ah、ライン数 01h/02h を入力モードに設定。無設定では出力は無意味。→ DATACLKが回り始める

初期化列: 本プロジェクトの初期化列はデータシート SLES206C を典拠に自前で起こしたもので、gateware/retrocastx_i2c.py の WR_REG/WR_VAL にある。OSSC(marqs85/ossc)のTVP7002初期化コードは、レトロ周波数で実績のある設定値と突き合わせる裏取りの資料として参照できる(GPL-3.0 のためコードの取り込みは不可。設定値も一致していない)。完全な回路は当リポジトリ main.ato(module App / VideoInputChannel)が実装済み。

典拠: TI TVP7002 データシート SLES206C(ピン機能・推奨動作条件・PLLフィルタ値・電源電流)。回路実装 = 当リポジトリ hardware/adc-frontend/main.ato。

電源メモ: AVDD/PLL_AVDD/DVDD 推奨 1.8〜1.9〜2.0V(本基板は AVDD/PLL=1.85V, DVDD=1.9V)。A33VDD/IOVDD=3.3V。全電源ピンは基板側でも全数結線済みを確認済み。

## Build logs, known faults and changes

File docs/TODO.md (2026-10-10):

# 次にやること

セッションをまたいで引き継ぐための作業リスト。優先度順。
済んだものは削除し、新たに分かったことは根拠(実測値)とともに追記する。

決着した知見(原因が判明した不具合、否定された筋、測定の落とし穴)は
[design-notes.md](design-notes.md) に置く。こちらは「次にやること」だけ。

## 0. 2026-08-15 に片付いたこと(次のセッションへの引き継ぎ)

**S端子まで通って安定して動いている。** この日に確定したことだけ先に:

- **コンポジットの「細い縦線が二重」は PS2 の出力そのもの**だった。オシロで
  AC結合前を直接見て確認済み。S端子の Y では単一の深い谷になる。復調も基板も無罪
- **S端子を実装**(赤chのバースト検出で自動判定、コムは一切使わない)。
  Y は素通し、C は直交復調するだけ。クロスカラーもドットクロールも原理的に無い
- **S端子の SOGスライス閾値は 20**(既定 0x0B だと暗部を同期と誤認してフィールド
  極性が判定できず、絵が半ライン上下に震えた)。16〜24 が正解の窓
- **Yはボトムクランプ + クランプ窓を同期チップの中(60幅40)**。輝度の分解能が
  1.61倍(1 IRE = 0.900 → 1.450コード)になり、白の飽和が消えた
- **ゲートウェアの SOG測定の張り付きを修正**(lowmax にリセット経路が無く、飽和
  すると電源を入れ直すまで復帰しなかった)。SPIフラッシュへ書き込み済み
- **音声のクロック差(12.5ppm)を ASRC で吸収**。滞留が目標80msに張り付く
- **表示レートの謎を解決**(取りに行く回数が来る回数と同じだった)。確率モデルごと
  design-notes に記録した
- **画調の調整**(彩度・明るさ・コントラスト・色相・ガンマ)を Viewer に追加。
  既定は「信号どおり」で、そこは実測で正しいことを確認済み

★**復調の校正は信号内の基準に紐づいている**(同期40 IRE / バースト40 IRE p-p /
  黒0 IRE / 白100 IRE を全部実測で確認)。画調はその上に載せる好みの調整で、
  校正の方は触らない。ここを混ぜると後で数値で追えなくなる。

残っている画質の課題は**カラーバーの映像源**だけ(色相の絶対確認に要る)。

## 0c. Ethernet まわりの名前がずれている ── **v1.0で直す**(2026-09-11)

同じものを指す名前が5通りある。

| 概念 | 片方 | もう片方 |
|---|---|---|
| i5モジュールのシルク | ETH2 | ETH1 |
| v0.9.0 のデジグネータ | J11 | J12 |
| main.ato のモジュール名 | `jack` | `jack2` |
| litex の eth index | 0 | 1 |
| LED の GPIO | R1 / T1 | U1 / Y2 |

対応は実測で確定済み(design-notes.md「Ethernet PHY からリンク状態を取る」)。
`main.ato` の誤った docstring も修正済み。**残っているのは名前の整理だけ。**

### v1.0 でどうするか

**ETH1/ETH2 という呼び方を自分たちの基板から無くす。** これは i5 モジュール側の
シルクであって、こちらが引き継ぐ理由が無い。引き継いだせいで、デジグネータの
振り順(J11=ETH2)と逆になり、さらに litex の index とも逆になった。

1. シルクを **litex の index に合わせた名前**にする(例 `LAN0` / `LAN1`)。
   ゲートウェアの `--eth-phy` の値がそのまま読める
2. デジグネータも index の順に振る(J11 = index 0)
3. `main.ato` のモジュール名を `jack_eth0` / `jack_eth1` にする
4. 文書から ETH1/ETH2 を消す。どうしても i5 側のシルクを指すときは
   「i5モジュールのETH1」と明示する

★ここは半日溶かした前科がある。**名前ではなく実測で確かめてから書く。**

## 0a'. ✅配置次第で NTSC の TVP 同期が乱れる ── TVP の RESETB のグリッチだった(2026-10-09)

**原因**: `retrocastx_i2c.py` が TVP の RESETB と I2C の SCL/SDA を、FSM の状態を
**組合せでデコードした値のまま**ピンへ出していた。ポーリングで状態が回り続けるので、
状態が変わる瞬間に配線遅延の差で RESETB に短い Low が出ると TVP が部分リセットされ、
HSOUT が抜ける(オシロで HSOUT の抜けを確認)。グリッチが出るかは配置で決まるので、
**同一の合成結果でもシードで当たり外れが分かれ、同じ .bit なら毎回同じ**になっていた。

**修正**: 3本ともレジスタから出す(SDA入力も2段で受ける)。

| 同一合成・シード違い(headless 30秒中 60fps の秒数) | 2 | 6 | 7 | 11 | 12 |
|---|---|---|---|---|---|
| 修正前(デジタルRGBなし) | 0 | 0〜3 | 1 | 0 | 30 |
| 修正前+`--no-mclk-out` | 29 | 2 | 0 | 1 | 29 |
| **修正後(デジタルRGB入り)** | **30** | **30** | **30** | **30** | **30** |

修正後 seed 2 は 180秒でも 180/180。壊れる対照版と交互に焼いて、測定系が正常なことも確認した。

**途中で外れた仮説(同じ道を辿らないこと)**: デジタルRGB(外した3本が当たり配置だっただけ)/
TVP 設定の化け(全キー同一、書き直しても不変)/ MCLK の結合(止めても5本中3本壊れる)/
SOG スライス閾値(0〜31 全域で不変)/ 電源・SOG入力のノイズ(MSO1074 で見えず)。

**旧 0a(X68000 で10〜20秒に一度乱れる、配置次第)も同じ原因だったとみてよい。** #34 は FPGA 側で
症状を濾していただけ。gw-v0.9.4(Webフラッシャで書込み)で、NTSC(PS2 S端子)の10〜20秒周期の
揺れも X68000 の乱れも出ていない(2026-10-09 実機)。再発したらここへ戻ること。

**★2026-10-10 に PS2 コンポジットで同じ見た目の揺れが出たが、原因は別だった。**
SOG の垂直検出が HSOUT の端と同じクロックに重なると、ゲートウェアの SOG 測定が
永久に凍り(垂直間隔 35 / 位相 1419 のまま、`sog_vth` を振っても動かない)、
フィールド極性が判定できずに 480i の2フィールドを同じスロットへ書いていた。
60Hz 表示とのうなりでフィールドが飛ぶと縦揺れに見える。gw-v0.9.5 で修正
(`retrocastx_capture.py` の「検出はこのブロックより後ろに置く」)。
**見分け方**: `cfg get 0x63`(sog_vlines)が 262/263 でなく、`0x62`(sog_vphase)が
交互に変わらないなら SOG 測定の凍結。電源の入れ直しで戻るのも同じ。

**判定の手順**(タイミング成立だけでは分からない): 焼く → GUI の Viewer が入力設定を自動で書く
(電源断で消えるため)のを待つ → GUI を閉じて `retrocastx-viewer --headless 30` の fps と
「NTSC復調: N行ロック」を数える。

## 0b. デジタルRGB(RGBI)入力 ← **配線待ち。ここから再開する**(2026-09-09)

**状態: ブランチ `gateware-digital-rgb`。実機に焼き済み、未マージ。**
生成器と測定器まで。**絵にする部分(キャプチャ)はまだ無い。**

★**焼き直すと消える。** リリース版のビットストリーム(gw-v0.9.3 等)には
入っていないので、WebUSB等で焼き直したら `gateware-digital-rgb` を
ビルドし直すこと(seed 3 で全ドメイン成立を確認済み)。

### 何のためにこうしたか

デジタルRGBを出せる実機が無い。**何も繋がずにキャプチャを書くと、動かないときに
「経路が悪いのか論理が悪いのか」を切り分けられない**。そこでデバッグ端子から
擬似信号を出し、J13 へ戻して**レベル変換器とコネクタを含む本番の経路**を通す。

★**キャプチャより先に測定器を作った。** 経路が生きているかを、ライン組立や
パケット送出と切り離して確かめられる。ここが通ってから絵にする。

### 配線(6本 + GND)

| J4(デバッグ端子) | | J13(デジタルRGB) |
|---|---|---|
| pin3 dbg1 | → | pin2 **R** |
| pin4 dbg2 | → | pin3 **G** |
| pin5 dbg3 | → | pin4 **B** |
| pin6 dbg4 | → | pin5 **I** |
| pin7 dbg5 | → | pin6 **HS** |
| pin8 dbg6 | → | pin7 **VS** |
| pin1 または 2(GND) | → | pin1 または 8(GND) |

dbg 側は 3.3V CMOS 出力、J13 側は SN74LVC2G17 の入力(しきい値約1.6V)なので
そのまま繋がる。J13 のコネクタとケーブルは調達済み(2026-09-09 時点で未配線)。

★**上の表は v0.9.0 基板(1.25mmピッチ 単列8極)の番号。** v1.0 では同じ端子が
**2×5 ボックスヘッダ**になり、番号が1つずれる(両端がGNDになるため):

    v1.0 の J6:  1=GND 2=R 3=G 4=GND 5=B 6=I 7=GND 8=HS 9=VS 10=GND
                 (GNDを挟んで6本すべてが隣にGNDを持つ並び)

v1.0 基板でこのループバックをやるときは
dbg1→pin2(R) / dbg2→pin3(G) / dbg3→pin5(B) / dbg4→pin6(I) /
dbg5→pin8(HS) / dbg6→pin9(VS)、GND → pin1/4/7/10 のどれか。

### 検証手順と期待値

    cd host/python
    python3 -m retrocastx.cfg get 0x0070    # fH
    python3 -m retrocastx.cfg get 0x0072    # vtotal
    python3 -m retrocastx.cfg get 0x0073    # 1ラインのsysクロック数
    python3 -m retrocastx.cfg get 0x0074    # 生レベル
    python3 -m retrocastx.cfg get 0x0075    # 極性(測定値)
    python3 -m retrocastx.cfg get 0x0077    # 1ドット縞の色変化回数  ★本命

| キー | 配線前(確認済み) | 配線後の期待 |
|---|---|---|
| 0x0070 fH | 0 | **15733** 付近 |
| 0x0072 vtotal | 0 | **262** |
| 0x0073 ライン長 | 0 | **2860** 付近(45MHz ÷ 15733) |
| 0x0074 生レベル | **0**(プルダウンが効いている) | 動く |
| 0x0075 極性 | 0 | **0x3**(HS/VSとも負極性と測定) |
| 0x0077 1ドット縞 | 0 | **639** 付近 |
| 0x0078 生成器 | **0x3**(動作中) | 0x3 |

**0x0077 が本命。** 639 付近まで出れば、コネクタ・レベル変換・ドット位置合わせ
まで全部通ったことになる。★色が読めるだけでは足りない ─ カラーバーは
ドットクロックが2倍ずれていても「合っている」ように見える。

### 値から原因へ(ここで時間を使わないために)

| 症状 | 疑うところ |
|---|---|
| 0x0074 が 0 のまま | 配線か、生成器が止まっている(0x0078 を確認)。dbg側の結線を疑う |
| 0x0074 は動くが 0x0070 が 0 | HS/VS の線だけ繋がっていない、または極性の測定が終わる前 |
| 0x0075 が 0x0 | 正極性と測定された。`cfg set 0x0078 1` で生成器を正極性にして再確認 |
| 0x0072 が 262 でない | HS か VS の取り違え(pin6/pin7 の逆挿し) |
| 0x0077 が 300 前後 | ドットを1つおきに拾っている。位相ではなく **htotal(0x0079)が倍か半分** |
| 0x0077 が 0〜数十 | 位相が合っていない。下の「クロック再生」へ進む |

### クロック再生(次にやること)

外部からドットクロックは来ない(J13 にクロック線は無い)。**オーバーサンプリング
して同期から作り直す**。いまは HS に載せているだけ:

    HS〜HS の sys クロック数を測り(hlen)、1ラインを htotal 等分する
    acc += htotal ; acc >= hlen なら { acc -= hlen ; dot += 1 }   ★除算器を置かない
    acc を hlen/2 から始めてドットの中央で拾う

**実機(14.31818MHz)では 45 / 14.318 = 3.14 サンプル/ドット**しかなく、
これだけでは足りない見込み:

| 誤差 | 大きさ |
|---|---|
| サンプル格子の量子化 | ±0.5サンプル = ±0.16ドット |
| HSエッジの分解能 | ±1サンプル = ±0.32ドット |
| hlen の量子化がライン端まで積む | ±1サンプル = ±0.32ドット |

合計 **最悪0.8ドット** → ライン終端で隣のドットを拾う。足す予定:

1. **ライン長を256ライン平均**する(割らずに `htotal×256` 対 `hlen_sum` で回す)。
   3つ目が消える
2. **位相を映像のエッジから測る**。色の変化は必ずドット境界で起きるので、
   1フレームぶんの「変化した位置」のヒストグラムの山が真値。半ドットずらして
   サンプルする。2つ目が消える。★**絵を見て合わせないで済む**(真っ黒でも
   破綻しない。変化が無いフレームでは前の位相を保持)

残るのは ±0.16ドットで十分。**予備の手**: ドットクロックが速い機種
(28.6MHz級 = 1.57サンプル/ドット)では足りないので、ECP5 の `IDDRX1F` で
両エッジ取りにして**実効90MHz**にする。新しいクロックドメインを作らずに
分解能を2倍にできる。

★**1と2は、ループバックが通ってから**にする。12.288MHz なら 3.66 サンプル/ドット
あるので、いまの方式でも通るかもしれない。**実機の 3.14 で足りるかは、そこが
分かってから詰める**方が無駄がない。

### 生成側の作り(なぜこの値か)

生成器は**音声用の外部XO(12.288MHz、aud ドメイン)**で動かす。sys の元になる
25MHz とは**別の水晶**なので:

- **本物のドリフト**が入る(2つの水晶の ppm 差)
- 1ドットが 45/12.288 = **3.662サンプル**という**分数**になる

★**sys の整数分周(45/3 = ちょうど3.000サンプル/ドット)では試験にならなかった。**
整数比だとドット境界が毎ライン同じ位相に来るので、**受け側の分数アキュムレータが
一度も効かないまま「通った」ことになる**。最初そう書いていて、指摘で気付いた。

    生成 12.288MHz / htotal 781 → fH 15,733.7Hz   実機比 -0.004%
    実機 14.31818MHz / htotal 910 → fH 15,734.3Hz  = NTSC そのもの

★**14.31818MHz / 910 は「おそらく正しい」止まり。** 出どころは μPD3301 の
実装解析(Web)で、**回路図やサービスマニュアルのような一次資料では未確認**。
実機か回路図が手に入ったら検算すること。PC-8001 はコンポジット出力も持つので
NTSC 準拠でないと成立しない、という傍証はある。
**PC-8801 系は別**(実測15.957kHz、NTSC非準拠)なので混同しないこと。

### ループバックで確かめられないこと

生成側と測定側で水晶は別だがドリフト量は実機と同じとは限らないし、
**ケーブル長・反射・実機の出力ドライバの鈍り**は再現できない。
実機が来たらそこは測り直す。

### 関連

- 実装: `gateware/retrocastx_drgb.py` / 試験: `gateware/sim_drgb.py`(14秒、CIでも回る)
- 経路と割当: `hardware/adc-frontend/README.md` の「デジタルRGB入力」「デバッグ端子」
- キー一覧: `host/python/retrocastx/cfg.py` の 0x0070〜0x007D

## 1. コンポジットビデオを取り込む(手組み機では3番系統で試した)

設計と手順は **[composite-video-plan.md](composite-video-plan.md)** に全部書いた
(データシートの典拠込み。あの文書だけ読めば始められる)。

**Step 1〜3 は 2026-08-14 に実機で通った。残っているのは Step 4 だけ。**

手組み試作機での実測(コンポジット):

```
MODE: YC8  htotal=1820  dotclk=28.6356 MHz  fH=15734.0 Hz   ← 8fsc NTSC ちょうど
同期チップ 127 / ブランキング 158 → 段差31コード = 40 IRE(規格どおり)
バースト 29コード p-p / 周期 8.00 サンプル = 3.5795 MHz
隣接ラインの位相差 177°  ← 180°なので2次元コム(加算でY・減算でC)が成立する
```

    python3 -m retrocastx.videoin --board 255.255.255.255 auto     # 方式を自動判別
    python3 -m retrocastx.videoin --board 255.255.255.255 status
    python3 -m retrocastx.videoin --board 255.255.255.255 probe

★`--board` は **255.255.255.255**(ブロードキャスト)を使う。ボードとPCで
サブネットが違うとユニキャストはデフォルトゲートウェイへ流れて届かない。
`discover` はL2ブロードキャストなので動いてしまい、勘違いを誘う。

### Step 4 も通った。残っているのは画質

**Viewer(`client/src/ntsc.rs`)で実機ロック済み。** 参照実装は
`host/python/retrocastx/ntsc.py`(合成6色の回帰試験つき、誤差2.1°以内)。

```
NTSC復調: 253行ロック  コム間隔2  位相差178°
2048x526  60.0 fps  468.9 Mbps  lost=0   負荷 1コアの11.9%(M4 Pro)
```

既知の色との誤差(**色相の合わせ込み係数なし**): ○決定=赤 −1.0° /
グロー=シアン +14.0° / ブラウザ=青 −18.9° / △本体設定=緑 +25.5°。

次は画質:

- **色相の絶対確認にはカラーバーの映像源が要る。** 合わせられているのは
  ○=赤 の 0°(誤差 -1.0°)だけで、他3つの期待値は写真からの目視。
  △の +25.5° がデコーダの誤差か期待値の推測ミスかを、この素材では決められない
- **2次元適応コムは試して悪化したので既定オフ**(白文字の偽色 0.0260 → 0.0428)。
  ノッチ自体は正しい(合成6色で2次元コムと同じ誤差2.1°)が、細い縦棒の輝度が
  副搬送波の近くにあるので垂直detailで切り替えると悪い方へ行く。
  本筋は時間方向を見る**3Dコム**で、それはGPU向き
- 粗ゲイン(0x5F)を 0x07(0.5倍)→ 0x17(0.6倍)でバーストが29→38コード。
  実測の映像最大が79 IREなので余裕はある(100%カラーバーの131 IREだと際どい)
- GPUオフロードも可能。**生サンプルを送る方が転送は半分**になる
  (1.9MB/フィールド 対 いまのRGBA 3.8MB)。詳細は計画書 §4

### 入力方式の切り替えは全部CONFIGで済むようになった

**v0.9.0 基板の配線**(排他。同時には繋がらない):

| モード | コネクタ | 映像 | 同期 | reg 19h | reg 0Eh |
|---|---|---|---|---|---|
| `x68k` | D-SUB(DA-15) | Rin3/Gin3/Bin3 | HSYNC_A / VSYNC_A | 0xAA | 0x52 |
| `msx` | aux 2x5 | Rin2/Gin2/Bin2 | **SOGin2** (CSYNC) | **0x55** | 0x5B |
| `composite` | J5 2x4 | **Gin1**(Yピンに CVBS) | **SOGin1**(Yから分岐) | **0x00** | 0x5B |
| `svideo` | J5 2x4 | **Gin1=Y / Rin1=C** | **SOGin1**(Yから分岐) | **0x00** | 0x5B |

★**v0.9.0 で系統の割り当てが手組み機から変わった。** 手組み機は S端子も
コンポジットも MSX も映像を3番系統に仮配線して同期だけ振り分けていたが、
v0.9.0 は**入力ごとに系統が分かれている**(`main.ato` が正)。
S端子/コンポジットは専用の2x4ヘッダ(J5)から1番系統へ、MSX等の第2入力は
2x5ヘッダから2番系統へ入る。**19h は「SOGだけ別」ではなく全ビット同じ値**になった。

<details><summary>手組みボードの配線(v0.9.0 以前・歴史的記録)</summary>

| モード | 映像 | 同期 | reg 19h | reg 0Eh |
|---|---|---|---|---|
| `x68k` | Rin3/Gin3/Bin3 | HSYNC_A / VSYNC_A | 0xAA | 0x52 |
| `msx` | Rin3/Gin3/Bin3 | **SOGin2** (CSYNC) | **0x6A** | 0x5B |
| `composite` | Gin3 (CVBS) | SOGin3 | 0xAA | 0x5B |
| `svideo` | Gin3=Y / Rin3=C | SOGin3 | 0xAA | 0x5B |

</details>

★レジスタ19h は元々ビルド時定数だったので焼き直さないと入力方式を
切り替えられなかった。key 0x69 を足して実行時に振れるようにしてある。

`videoin auto` が自動判別する。3方式は**同期がどこに来るかが違う**ので絵を見ずに
判別できる。最初の分岐に使う生HSYNC(key 0x2A)は TVP を通らない経路を sys ドメインで
数えた絶対値なので、TVPの設定に依存せず読める。
`composite`/`svideo` は同期の出方が同じなので `auto --svideo` で指定する。

★v0.9.0 は SOGIN が3本とも実配線されている(手組み機は `_1` が未接続で陰性対照に
使えた)。代わりに**3本とも測って「安定は1本だけ」を要求する**。2本以上が安定と
出たら排他配線と矛盾するので、判定器を疑って中止する。

### 入れたもの

- CONFIGキー **0x36**(pixfmt)/ **0x5E**(クランプ選択 reg10h[2:0])/
  **0x5F**(粗ゲイン reg1Bh=B/G)/ **0x65**(粗オフセット reg1Fh=G)/
  **0x67**(粗ゲイン reg1Ch=**R**)/ **0x68**(粗オフセット reg20h=R)/
  **0x69**(入力MUX reg19h)
- **pixfmt 3 = YC8**(2B/px、下位=緑ch8bit=CVBS/Y、上位=赤ch8bit=S端子のC)。
  2B/pxのままなので断片化もMTU計算も既存と同一。ViewerはYをグレースケールで出す
- `retrocastx.videoin` — 方式の一括切替・自動判別・**波形の実測判定**

★**1Bh と 1Ch はビット割りが違う**(1Bh=`[7:4]G [3:0]B` / 1Ch=`[7:4]予約 [3:0]R`)。
同じ1.2倍でも 0x77 と 0x07。S端子のCは赤chなので 1Ch が要る。

### S端子は既存のD-SUB経路で試せる

計画書 §7 の「1番系統に部品を足す」は**専用コネクタを付けるための話**で、前提条件では
ない。R/G/Bは同一の前段(75Ω+100nF+220Ω/33pF)なので、**Y→緑 / C→赤**で今日試せる。
Yを緑に入れるのは固定(SOGタップが緑にしか無い)。
YとCで独立にクランプとゲインを持てるぶん、輝度もクロマも**約2.4倍**の分解能になり、
なにより**Y/C分離が丸ごと不要**になる(Step 4 の一番難しい部分が消える)。

### 当初の計画から変わった点(重要)

- **ミッドレベルクランプ単独では成立しない。粗ゲインを同時に下げる。**
  ブランキングが512に座るので白側ヘッドルームが半分になり、既定の1.2倍のままでは
  コンポジット(1Vpp=140IRE)が飽和する。`1Bh = 0x07`(0.5倍)が出発点
- **バーストは73コードにはならない。36コードが上限**(ヘッドルーム半減のぶん)。
  それでもRGB555の4〜5段階よりは4倍以上良い
- ボトムレベルクランプでもブランキングは0ではなく**約64**(粗オフセット1Fhの既定)
- **粗オフセット(1Fh)でブランキングを動かす別解は成立しない。** 粗クランプは
  既定で無効(reg 2Dh)で、ファインクランプの帰還ループがADC前のオフセットを
  打ち消す。実測で +64→+0→-32 と振ってもブランキングが動かなかった。
  白の飽和に効いたのは**ファインゲイン(09h)**(33=1.129倍が掛かっていた)
- **「絵が出た」では合否が判定できない。** ボトムレベルならバーストの下半分が消え、
  ゲイン過大なら白が飽和する。どちらも絵は出る。だから `probe` で数値を見る

### Y/C分離は 3次元(動き適応フレームコム)まで実装した

    1次元  水平のみ(BPF/トラップ)          メモリ不要
    2次元  + 垂直(ラインコム)               1H
    3次元  + 時間(フレームコム、動き適応)  1フレーム  ← いまここ

★用語注意: 英語圏の "1H comb / 1D comb" は上下ラインを使うものを指すが、
**日本語の「1次元」は水平のみ**を指す。当初この文書は英語の言い方で
「1Dコム」と書いていたので、日本語の2次元/3次元に統一した。

**成立の根拠(実測)。** NTSCは1フレームあたり 525×227.5 = 119437.5周期で
端数0.5周期なので、1フレームで位相が180°反転する。ボードの「フレーム」は
1フィールドなので同じライン番号は2フレームおきに来る:

| ボードのフレーム差 | NTSCフレーム差 | 位相差(n=4576) | 用途 |
|---|---|---|---|
| 2 | 1 | **175.8°** | フレームコム(C を取る) |
| 4 | 2 | **4.2°** | **動き検出**(クロマが混ざらない) |

★**動き検出に1フレーム前を使ってはいけない。** 位相180°なのでクロマが差に
そのまま出て、色のある所が全部「動いている」ことになる(映像域の副搬送波成分で
9315 対 388)。2フレーム前なら位相が同じなのでクロマが消え、純粋な輝度の時間差になる。

**効果(同じフレームを両方式で復調、15フレーム平均)**:

| | 2次元 | 3次元 | |
|---|---|---|---|
| 垂直detail上位10%の彩度(偽色) | 0.1523 | **0.1447** | −0.0076 |
| 平坦部の彩度のσ(ノイズ) | 0.2583 | **0.2477** | −0.0106 |

静止部分ではフレームコムが厳密解なので、フレーム差を取っても**クロマはむしろ
綺麗になる**(ノイズが増えるという当初の懸念は外れた)。

負荷は 1コアの 15.4% → **19.6%**(M4 Pro、シングルスレッド、release)。
メモリは履歴2面ぶん +3.8MB。

実機: 263行すべてが3次元、動きと判定されたのは 1.4〜2.4%、lost 0。

### 残っているのは GPU化 ← **次のセッションの主題**

CPU実装は 2次元/3次元コム・位相ドリフト補正・S端子まで揃っていて、実機で
安定して動いている。次は GPU オフロード。

#### なぜやるか(動機が1つ増えた)

1. **CPU負荷**: 1フィールド 3.85ms = 1コアの23%(`cargo test --release --
   --ignored --nocapture ntsc::tests::timing` で測れる)
2. **転送量**: 生サンプルを送る方が半分(1.9MB/フィールド 対 いまのRGBA 3.8MB)
3. ★**publish の揺らぎが減る**(2026-08-15に判明)。表示できる新フレームの割合は
   **到着の揺らぎ σ で決まり**、その σ = 4.35ms は復調時間 3.85ms とほぼ同じ。
   publish のタイミングが処理時間のばらつきを引き継いでいる。
   **復調を軽くするのは、見に行く回数を上げるのと同じ効果を持つ。**
   根拠と確率モデルは [design-notes.md](design-notes.md)「表示レートは
   『見に行く回数』で決まる」

#### 進め方(順序に理由がある)

1. ★**読み戻し経路を先に作る。** シェーダでは printf も既存の回帰試験も使えず、
   この環境は画面収録の権限も無い。GPU出力を数値で確かめる手段が無いまま移植
   すると、間違えたときに何も分からなくなる
2. **CPU実装が正解の基準**(`client/src/ntsc.rs`)。移植の検証は CPU 出力との
   画素一致で行う。アルゴリズムはもう動いているので、移植自体は機械的
3. パス1(直交復調 + クロマLPF)から。ここが一番重く、一番素直
4. 3次元コムの履歴(`raw_p2`/`raw_p4`)はテクスチャ配列かリングにする。
   ★履歴はスロット番号で索いているので、フィールドの割り当てを変えるなら
   そこも一緒に直すこと

#### S端子ではコムが要らないことに注意

S端子(赤chのバースト検出で自動判定)では **Y は素通し、C は直交復調するだけ**で、
2次元/3次元コムも位相ドリフト補正も走らない。GPU化の効果はコンポジットの方が大きい。
逆に言えば、**S端子で使う限り復調はもう軽い**ので、GPU化を急ぐ理由は
「コンポジットも使いたい」場合に限られる。

#### 帯域を下げる案(GPU化とは別軸)

YC8 は全ライン送信なので 468 Mbps・47,000パケット/秒。内訳:

    有効映像 9.6〜62.0µs        1501サンプル  要
    カラーバースト 5.4〜7.7µs     66サンプル  要(位相基準をライン毎に測るため)
    同期チップ 0.7〜4.2µs        100サンプル  要(1 IREあたりのコード数の校正)
    バックポーチ 7.9〜9.3µs       40サンプル  要(0 IREの基準)
    その他                       113サンプル  **不要**(6.2%)

- **本当に無駄なのは 6.2%** だけ。468 → 439 Mbps にしかならない
- 効くのは **C チャネル**。3.58MHz±0.6MHz しか持たないのに 28.6MHz で運んでいる。
  ナイキストは 8.4MHz で足りるので半分に間引ける → **25%削減**(468 → 351 Mbps)。
  ただし pixfmt の追加(ゲートウェア・プロトコル・デコーダの3箇所)が要る
- ★ただし**帯域は今のところ律速ではない**。ヘッドレスでは同じ 468 Mbps で
  88万パケット lost 0。落ちるのは GUI 側の事情だった

**PCB発注前にやっておくと後で効くこと**: 1番系統(`rin_1`/`gin_1`/`sogin_1`、現在すべて
未使用終端)にS-Video用のR/Cを置いておく。既存の3つのシュントコンデンサが既にTVPピン
直近の正しい位置にあり、値を33pFに変えればアンチエイリアスとして使える。追加は0402が
9個+1×4ヘッダ+ESD1個。詳細は計画書の§5。

## 2. 個体設定をEEPROMに持たせる ── **完了(2026-09-08)**

MAC・IP・ボード名が全部コンパイル時定数だった問題は片付いた。以下は経緯の記録。
**新しく足すなら「設定ページ ver=2」を切ること**(`retrocastx_i2c.py` の
`CFG_PAGE_VER`。読み側は ver が違えば採用しないので、古いゲートウェアが
新しいページを誤読することはない)。

### 何が入ったか

| | 実装 |
|---|---|
| MAC | 基板の EUI-48 EEPROM から起動時に読む。`caps` bit0 で読めたか分かる |
| 既定IP | MAC由来のリンクローカル `169.254.<mac[4]>.<mac[5]>` |
| ボード名 | EEPROM 設定ページ 0x10..0x1F(16B)。ANNOUNCE に載る |
| 静的IP | EEPROM 設定ページ 0x04..0x07 + flags bit0。**既定オフ** |
| 版の識別 | `fw_version`(gw-vタグ由来 4/6/6)+ `build_id`(コミットSHA) |

    python3 -m retrocastx.identity --name x68k-desk --save
    python3 -m retrocastx.identity --ip auto --save

検証は `gateware/sim_eeprom_cfg.py`(EEPROMを書込みまで模擬)。CIでも回る。

### ★MACの方がIPより先に問題になった

**MACアドレスが全基板で同じ `02:52:43:58:00:01`。** 同じネットワークに2枚繋ぐと
MACが衝突してスイッチの学習テーブルが壊れ、両方まともに通信できなくなる。
**IPを変えても直らない。**

24AA025E48 には**個体ごとに世界で一意な EUI-48 が工場書込みされている**ので、
読んで使えば衝突が原理的に起きない。EEPROMを載せたのはまさにこれのため。

### 使える領域

| 候補 | 場所 | 可否 |
|---|---|---|
| **24AA025E48 ×2 (U16/U17)** | I2C **0x50 / 0x51**、TVP7002と同じバス(`tvp.sda`/`tvp.scl`)、`WP`=GND で書込み許可 | **本命**。MAC領域はHW保護、**残り約250B×2 が自由** |
| i5のSPIフラッシュ | ビットストリームと同居(`bitstore.sh flash-perm` の書込み先) | 可。ただしアドレスを間違えると起動しなくなる |
| 93LC56 (U8) | FT2232HのUSB VID/PID用。FT2232H専用ピン | **不可**。FPGAから触れない |

`main.ato` の部品定義にも「MAC領域はハードウェア書込み保護済み、残り領域(~250B)は
**個体設定(IP・ボード名等)の保存に使える**」と書いてある(設計時に織り込み済み)。

### 踏んだ落とし穴(繰り返さないため)

- ★**ANNOUNCEのペイロードがMAC/IP/nameをビルド時に焼き込んでいた。** 電線上の
  MACと自己申告が食い違う状態を一度作った。実行時の値を載せること
- ★**EEPROMの書込みは8バイトページ単位。** 2Kbit品はページ内で折り返して先頭を
  潰す。**エラーにならず静かに壊れる**
- ★**書込み中は最大5msアドレスにもACKを返さない。** ACKポーリングが要る
- ★**チェックサムが要る。** 空(全0xFF)は magic で弾けるが、書込み途中で電源が
  落ちた半端なページは magic が通ってしまう

### 残っているもの(いずれも優先度は低い)

- **Viewer から名前を変えられるようにする。** いまはCLI(`retrocastx.identity`)
  だけ。複数台を並べて使うようになってからでよい
- **DHCP。** LiteEth 同梱のクライアント(`liteeth/core/dhcp.py`)が使える。
  **入れるならリンクローカルで先に上げ、リースが取れたら乗り換える**
  (OSのAPIPAが嫌われるのは「先にDHCPを待って諦めてから」落ちるため。
  自前実装なら逆順にできる。RFC 3927 も並行動作を認めている)。
  ただし**いまのところ誰も困っていない**: 発見はブロードキャスト、映像の
  送り先はSUBSCRIBEの送信元なので、固定アドレスを必要とする経路が無い
- **出荷検査の手順書。** `python3 -m retrocastx.discover` 一発で
  MAC(caps bit0)と版が確認できるところまでは来ている

## 3. 受信バッファーの設定を利用者に要求しないようにする

**パケット落ちそのものは解決した**(NICの受信リングが既定256で溢れていた。
2048にすると 35,600 pkt/s を lost 0.0013% で捌く。経緯と測り方は
[design-notes.md](design-notes.md) の「受信の取りこぼしは NIC の受信リングだった」)。
「受信スレッドのsyscall律速」という以前の見立ては誤りで、**受信スレッドの増設も
キュー操作のまとめも不要**。

### 手作業は消した(2026-09-10)

    Set-NetAdapterAdvancedProperty -Name 'イーサネット' -RegistryKeyword '*ReceiveBuffers' -RegistryValue 2048

これを知らないと「1.7%落ちる」「音が途切れる」状態で使うことになる。順に潰した:

1. ~~**Viewerが気づかせる**~~ 完了。経路上のNICを引いてレジストリの
   `*ReceiveBuffers` を読み、小さければ名指しで警告する。読めないドライバでは
   実測のロス率で言う(`client/src/netcheck.rs`)
2. ~~**README/docs に書く**~~ 完了(`client/README.md` / `README-first.txt`)
3. ~~**手作業そのものを消す**~~ 完了。「直す(管理者)」ボタンで、`ShellExecuteW` の
   `runas` を使って**このコマンドだけ**を昇格実行する。★アプリ自体は昇格させない
   (映像を受けるだけのアプリを管理者で走らせない)。★押しただけで終わらせず、
   6秒後にレジストリを読み直して**本当に直ったか**を出す ─ UACを拒否しても
   「実行しました」と出ては意味がない

★**Windows実機では未確認**(2026-09-10 時点。開発機がmacOSで、CIはコンパイルまで)。
  UACの承諾/拒否、アダプタのリセットで映像が復帰するか、を実機で見ること。

### 残っているもの: ジャンボフレーム

**ジャンボフレームで根本的に減らす**: 1パケットに複数ラインを詰めればパケット数が
数分の1になり、リングの既定値でも溢れなくなる。プロトコル・ゲートウェア・スイッチ・
NIC(いま `ジャンボパケット 無効`)の対応が必要。帯域をさらに上げるときにも要る。

★**優先度は下がった。** 上の3つで「知らずに劣化した状態で使う」ことは無くなった。
  ジャンボは**帯域を上げたくなったとき**の話として残す。

## 4. lost / orphan lines の追跡

長時間動かすと `lost` が少しずつ増える(13469フレームで19072パケット ≒ 0.08%)。
`orphan lines`(MODEの mode_id が一致しないLINEを捨てた数)も増える。モード切替を
繰り返したセッションで増えただけなのか、定常状態でも増えるのかを切り分ける。

**両方とも片付いた見込み(2026-08-10)**:

- `orphan`: Windows で `--headless 10` を2回。1回目はMODE到着前のLINEで 25856 まで
  増え、**MODEが確定した後は1本も増えない**。2回目(モード確定済みで開始)は
  10秒/532フレームを通して **orphan=0**。増えるのは「MODEを受け取る前/モード切替
  直後」だけで、定常状態では増えない
- `lost`: NICの受信リングが原因だった(項目1)。2048にした後は
  **2704フレーム/1,727,115パケットで lost 23 = 0.0013%**、orphan 0、
  audio underruns 0。「長時間で少しずつ増える」の主因もこれだった可能性が高い

**残り**: この 23 が何かを確定する。ボードの `seq` は**宛先に関係なく**1つずつ増える
ので、他の相手へ送ったパケット(ANNOUNCE、別ホストへのCONFIG応答)は受信側では
必ず「lost」に見える。**診断ツールを別マシンから打つと lost が増える**のはこのため。
長時間観測して増え方が「1秒に1個程度」なら ANNOUNCE の分と説明がつく。

## 5. ライン長を超える断片が0.5%

各フィールドの特定位置(413行目付近と879行目付近)に集中する。HSYNCを取り逃がした行で
`x` が長く走り、非黒範囲がライン長を超えると考えている。受信側は入る分だけ書いて
凌いでいるが、ボード側で範囲をライン長で打ち切るのが本筋。

## 6. 管面の縦横比がCPU側とシェーダ側で食い違う

`tube_aspect = 0`(管面「そのまま」= 既定)のとき、両者が別の値を使う:

- CPU側(`main.rs` の CentralPanel): 切り出し範囲の比 `cw/ch`
- シェーダ側(`render.rs` の `uniforms`): 時間ベースかつ幾何が有効なら **4:3 固定**

描画callbackの矩形はCPU側の比で確保されるので、実際に映る管面はその中で
レターボックス/ピラーボックスされる。`画に合わせる` はCPU側の比でウィンドウを
決めるため、押しても管面はぴったり収まらない。

外側の色を撤去して黒に統一したので見た目には出ないが、比の計算が2か所にあること
自体が原因。本筋はシェーダに `avail` 全体を渡して管面の形をシェーダだけに決めさせ、
`画に合わせる` 用に描画サイズを返してもらうこと。

## 7. モニタプロファイル

`mon.15` / `mon.24` / `mon.31` に [H幅, H位置, V幅, V位置] を持つ。実CRTのつまみに
相当し、スライダーで合わせる。将来は CZ-600D / CZ-612D のような実在モニタの
プロファイルを外部ファイルにする案がある(オーバースキャン量、走査線の強さなど)。

信号は左右非対称(バックポーチが長い)なので `H位置 0` だと絵が右に寄る。
実測例: 15kHz Mode7 は `active 994x480 at (157,33)`, htotal 1179 → 適正な H位置は
(157 + 994/2)/1179 - 0.5 = +0.055。

## 8. CRTらしい描画(将来)

- 走査線表示(スロットの隙間を暗くする)。プログレッシブでは1ソースラインが2スロットを
  占めるので、複製せず暗くすれば走査線になる
- アパーチャグリル、グロー、曲率

## 9. pll_divide の自動決定(部分的に完了)

Viewer には3つの決め方がある。**上から順に試す**のがよい。

| | 絵を見るか | かかる時間 | 何をするか |
|---|---|---|---|
| `適用`(映像ソースの右) | 見ない | 一瞬 | fH と水晶/分周から htotal を計算。迷ったら大きい側 |
| `簡易スキャン` | 見る | 20秒ほど | **プロファイルが許す候補だけ**を測って選び、位相も振る |
| `フルスキャン` | 見る | 40秒ほど | 候補を前提にせず総当たり。未知の機種向け |

`適用` は絵の内容に一切依存しないので真っ黒でも当たるが、**同じ fH を作れる
ドットクロックが複数あると決め切れない**。X68000の31.5kHz がそれで、768x512(htotal
1104)・512x512(736)・HRL付き(552)が全部 fH 31.500kHz ちょうど。`適用` は安全側の
最大値(1104)を返すため、512x512 では1.5倍オーバーサンプルのままになる。

`簡易スキャン` はその候補集合(この例では htotal 368/552/736/1104 の4点、設定値
としては 552/736/1104 の3通り)**全部**の位相感度を測り、いちばん感度が強い
(最悪÷最良がいちばん小さい)点を採る。どれもしきい値を下回らなければ判別できて
いないので、いちばん大きい側(=過剰サンプル。眠いだけで壊れない)に倒す。
採用したら位相を1刻みで5点詰める。結果には候補ごとの位相感度を並べる。

★**「感度が立った最初の候補で止まり、降りる先を占有率で枝刈りする」形は実機で
  外した**(2026-09-04、31.5kHz の 512x512 で 1104 のまま動かず、降下が一度も
  起きていなかった)。枝刈りの根拠は「`設定値 × 占有率` は真の htotal の下限」
  だったが成り立っていなかった。真値 736 を 1104 で測ったときの占有率の理論上の
  上限は 736/1104 = 0.667 なのに実測は 0.716 出る(99%エネルギーの裾がノイズを
  拾う)。下限として使えない量で枝刈りしていたので、正解が候補から消えていた。

  判定材料の側は十分な差が出ていた(実測、真値736):

```text
    pll 1104  最良 160.25  最悪 156.58  → 98%   1.5倍オーバーサンプル
    pll  736  最良 377.11  最悪 200.92  → 53%   ★1:1
    pll  552  最良 406.15  最悪 351.23  → 87%
```

  **鮮鋭度の絶対値では選べない**(552 の最良 406 は 736 の 377 より大きい)。
  見るのは同じ設定内での比。この実測値は `quick_pick` の試験に固定してある。

★**占有率で1:1を判定してはいけない。** 一度これで実装して実機で外した
  (768x512 で 736 が選ばれた)。占有率は「1:1ならスペクトルがNyquistまで埋まる」を
  前提にするが、768x512(34.776MHz)は1ドットが白の64%までしか立たないので、
  正解の1104で測っても占有率は0.7程度。`1104 × 0.7 = 773` から736が近く見える。
  1.0倍と1.5倍を占有率で見分けるのはこの機種では原理的に無理。
  占有率は `設定値 × 占有率 = 真のhtotal × 帯域率` なので**下限**としてだけ使う
  (降りる先の枝刈り)。どの候補でも感度が立たなかったときは推測せず、
  いちばん大きい候補に戻す。

候補は**水晶の一族**でも絞る(`best()` と同じ相対誤差の判定)。15.98kHz で
69.552/4 → htotal 1088 が8の倍数のせいで残ると、正解の608(pll 1216)と1.79倍という
絵では見分けにくい相手になる。相対誤差は 9.2e-5 対 1.2e-6 と80倍違うので、
信号の側で落とす。結果、15kHz帯は候補が pll 1216 の1通りだけになる。

★候補は `profiles.rs` の水晶/分周表と fH だけから作る(`scan_candidates`)。
  **機種固有の分岐はスキャン側に一切無い**ので、機種を足すときは表を書くだけでよい。

X68000のドットクロック表は XEiJ の CRTC.java から起こした
(<https://stdkmd.net/xeij/source/xeij-CRTC.java.htm>)。69.552MHz の /2,3,4,6,8、
38.864MHz の /4,8、50.3498MHz の /2 で全モードを説明できる。

未対応:
- VGA / PC-9801 のプロファイルは数値の裏を取っていない(実機で確認が必要)
- `簡易スキャン` の位相感度版は実機で未検証(2026-09-03 時点。回帰テストのみ)。
  判定のしきい値 `PHASE_SENSITIVE = 0.85` はフルスキャン側で実機から決めた値を
  流用している。1段降りるかどうかがこの1つの数字で決まるので、実機で外すようなら
  ここを見る
- 誤った状態(PLLが外れている、絵が真っ暗など)から始めると失敗する。開始前に
  健全性を確認する仕組みが無い。ただし簡易スキャンは失敗しても最大の候補
  (=過剰サンプル)に留まるので、絵が壊れる方へは倒れない
- TVPのピクセルクロック下限(12MHz)により1:1にできないモードがある(15kHz 512x512 は
  本来の htotal 608 = 9.72MHz なので2倍の1216を使う)。簡易スキャンはこれを
  「×2オーバーサンプル」として報告する(位相感度が弱いのは異常ではない)
- CLI の `pll_tune autotune` は総当たり版のまま。簡易スキャンは移植していない

## 9b. インターレースの織り込み(2026-09-03 解決)

24kHz 1024x848 で**2つのフィールドが交互ではなく上下に積まれる**症状があった。
原因は「そもそもインターレースか」の判定を **TVPのP/I検出(reg 38h bit5)単独**に
任せていたこと。このビットはX68000の24kHzを progressive と誤答する
(実測 0x57=0x21。reg22h bit0 を立ててVSOUTをフィールドごとにしても変わらない)。
`il_det` が 0 だと `fld_pos` も `in_f2` も 0 に固定され、織り込みが丸ごと止まる。

**生同期はちゃんと動いていた。** 同じときの実測:

```
0x2A FH_RAW    = 24698 Hz      0x2C LINES_RAW = 466(=1フィールド)
0x2B FV_RAW    = 53.125 Hz     0x24 VS_X_RAW  = 715/11 を 106:94 で交互(差704 = 周期の半分)
```

直したのは3つ。

1. **`il_det` を生同期とTVPのORにした**(`retrocastx_capture.py`)。生VSYNCの半ライン
   位相が交互かどうかで判定する `il_raw` を足した。ORなのは、TVPが検出できている
   帯域の挙動を変えないため。判定はヒステリシス付き(12でセット/4でクリア)。
   切り分け用に CONFIG key **0x2D** で内訳を読める
   (bit0=生位相が交互 bit1=生同期OK bit2=TVPのP/I bit3=TVP vtotalが2フィールド分)。
2. **`field_invert`(0x66)= 1 をX68000プロファイルに入れた。** 生位相の符号が逆だった。
   実測の織り込みのずれ: 0 → 17.5 / 1 → 0.68。
3. **`sync_ctl2`(0x5B、reg22h)= 0x09 をX68000プロファイルに入れた。**
   VSOUTをフィールドごとに出させる。既定0x08だとVSOUTが2フィールドに1回になり、
   捕捉側が vtotal/2 = 465 で折り返す。折り返し点は固定なのに実フィールド長は
   半ラインのぶん465と466で1行違うので、片方が必ず1行ずれる(細い斜線が破線状に崩れる)。
   実測の織り込みのずれ: 0x08 → 4.59〜4.95 / 0x09 → 1.39〜1.44(各3回、再現あり)。

`sim_capture_interlace.py` に**この経路を通すケースを追加した**。既存の3ケースは
どれも生同期の無い構成で、生同期からの判定は一度も検証されていなかった。
新ケースは `cfg_il_detect = 0`(TVPが誤答している状況)で生VSYNCだけを与える。

未確認:
- 15kHz のインターレース(CRTMOD $01 など)で `field_invert=1` / `sync_ctl2=0x09` が
  正しいか。X68000プロファイル全体に効くので、モードを変えて確かめること
- MSX / コンポジット / S端子は `sync_ctl2` を既定0x08のままにしてある。reg22hの
  コメントにある「MSXの262ライン progressive が双安定になる」問題は 0x09 で
  直るはずだが未実測

## 10. v1.0 基板(2026-09-21 に回路を起こした)

v0.9.0 で見つかった不具合と仕様変更を取り込んだ版。**回路(main.ato)は書き終えて
`ato build` が通っている**。残りはレイアウトと、下の「発注前に確かめること」。

小亀基板(コンソール入力基板)を新設した: `hardware/console-frontend`。
S端子・コンポジット・音声L/R・実験用のコンポーネント(Pr/Pb)を載せ、
0.5mmピッチ20芯FFC(10cm)でメイン基板へ渡す。10cm×10cm、取付穴M3×5。

### 10-A. 取り込んだもの

| 項目 | 内容 |
|---|---|
| 第2映像入力 | 2x5ボックスヘッダ(J4)→ **ミニDIN8(FRAMEMEISTER互換, J13)**。自作ケーブル不要になる |
| TTL同期の受け口 | ミニDIN8にHS/VSが無いので **1x3ヘッダ(J14: HSYNC/VSYNC/GND)** を新設 |
| S端子/コンポジット | 2x4ヘッダ(J5)→ **20芯FFC(J15)で小亀基板へ** |
| コンポジットとYの共有 | 小亀基板に **2ch SPDT(TS5A23159)**。選択線はFFCのGPIO1(SO-DIMM 148=K4)。10-5 の結論どおり |
| コンポーネント入力 | スイッチのコンポジット側が **YPbPr** になる(Pr=Cと共用、Pb=予備線→BIN_1)。実験用 |
| 音声 | PCM1808 を2個→**3個**(映像系統ごとに独立)。受動加算の1.5kΩ×4を廃止 |
| 同期入力の浮き(10-5b) | D-SUB と 1x3ヘッダの HS/VS に **10kΩプルアップ**(R47-R50) |
| S/PDIF(10-3) | PLR135/**T10** へ戻してランドを小さく。電源に**フェライト+10µF**追加(データシートは47µH+0.1µFを要求。v0.9.0は0.1µFだけだった) |
| ネジ穴 | M2.6(φ2.8)→ **M3(φ3.2、パッド6.4mm)** |
| ESD | ミニDIN8 の R/G/B/CSYNC に追加(v0.9.0 の2x5経路には無かった)。小亀基板のジャックにも |
| 未使用だったBIN_1 | 実入力に昇格(Pb / 予備)。10nFの未使用終端を撤去 |

**10-2(センタータップのネット名の入れ違い)は既に直っていた。** いまの main.ato は
`jack→eth2_ct` / `jack2→eth1_ct` で、MDI の命名と揃っている(2026-09-02の修正)。
この項目の記述が古かった。

### 10-B. レイアウトでやること(回路では表せないもの)

- **10-1. RJ45 に ETH1/ETH2 のシルクを入れる。** 基板上でどちらのポートか判別できない。
  呼び名が資料間で逆なので特に混乱しやすい(`hardware/adc-frontend/README.md` の
  「GbE 差動ペアの対応」節)。J11(上)=eth2_*、J12(下)=eth1_*
- **FFCコネクタの1番ピンにシルクを打つ**(メイン基板・小亀基板の両方)。
  0.5mmピッチ20芯で1ピンずれると +5V が GPIO に当たる
- デジタルRGB(J6)を別のエッジへ移す(ohnaka 作業)
- ミニDIN8(J13)を旧J4の空き地へ。ミニDIN8は 13.45mm 幅 + 取付穴φ2.5×2
- 220Ω の LED データ抵抗(R53)は **SO-DIMM側に寄せる**(源端整合なので送り側)
- アンチエイリアスの 33pF は TVP のピン直近(v0.9.0 と同じ方針)

### 10-C. 発注前に確かめること

1. **10-4. ポゴピン(PG1-PG4)の高さ**。基板〜モジュール裏の間隙 2.6mm は推定値。
   **v0.9.0 の実機で測ってから**発注する。届かないと CH347F から FPGA へ JTAG が
   届かない(必須部品)
2. **FFCケーブルの種別(type A / type D)**。両端の接点が同じ面か反対面かで
   「n番↔n番」と「n番↔17-n番」が入れ替わる。**ネットリストはストレート前提**。
   2枚の基板の向きを決めてから種別を選び、通電前に導通試験をすること
3. **ミニDIN8のピン配置**。FRAMEMEISTER付属ケーブルをばらして確認済み
   (1=音声R 2=音声L 3=CSYNC 4=GND 5=NC 6=B 7=G 8=R、分圧や同期分離は入っていない)。
   基板側コネクタは **マル信無線 MJ-373/8B**(手実装。千石/マルツ等)。メーカー図面の
   PCB穴図から**フットプリントを自作**した(`parts/_mech/MJ373_8B.kicad_mod`)。
   ★**7番(G)だけ列からずれている**(中心線から+1.0mm、2番は+1.5mm)。等間隔だと
   思い込むと緑だけ嵌合しない基板になる。図面を画像解析して実測で確定した
4. **ミニDIN4(S端子)の3番がプラグの輝度ピンか**を現物で導通確認
5. **ミニDIN4(S端子)も マル信 MJ-373/4B**(同じハウジング枠、自作フットプリント)。
   3番=プラグの輝度ピンを現物で導通確認する
6. **RCAジャックのランド**。LCSCで在庫があるのは赤(C47118013)だけ。黄/青/灰は
   AliExpress等で買うので、現物の穴位置(中心φ1.5 / シェル3本 10.5×5.2mm)を実測する
7. **PLR135/T10 のピン機能**。1=Vcc / 2=GND / 3=Vout(PLR135ファミリ共通)。
   v0.9.0以前の /T10 定義は Vcc と Vout が逆だった(未照合のまま残っていた)。
   現物で確認してから通電すること

### 10-D. ソフト側の追随(v1.0 基板を動かすときに要る)

- 音声が3系統になる。DOUT は SO-DIMM 141(DSUB) / 139(ミニDIN8) / **129(小亀)**。
  AUDIOパケットの source 番号を増やす
- 小亀基板のスイッチ選択線 **SO-DIMM 148(K4)** をプロファイルから駆動する
  (L=コンポジット・コンポーネント / H=S端子)。予備線は150(K5)
- 小亀基板のシリアルLED(2個)のデータ線 **SO-DIMM 154(A2)**
- **ミニDIN8のプロファイルは SOGスライス閾値(CONFIG key 0x50)を下げる。**
  規格準拠ケーブルの CSYNC は 0.3Vpp で、基板の1/2分圧後は 0.15Vpp。既定の
  NTH=11(124mV)だと振幅の83%を切ってしまう。**NTH=7(79mV)が50%点**。
  MSX(1.8Vpp→0.9Vpp)は既定のままでよい

### 10-E. CSYNCのレベルについて分かったこと(2026-09-21)

FRAMEMEISTER が「複合同期 0.3Vp-p 負極性」を要求する理由を調べた。**アーケード基板の
CSYNCが低いから、ではなく逆**だった。

- 0.3Vpp は複合映像信号の同期先端の振幅 = **テレビ規格の同期レベル**。SCART/RGB21 の
  ディスプレイは同期線を75Ωで終端してこれを受ける
- 実機のコンソールは **TTL(5Vpp)のCSYNCを出すものが多い**(NTSC SNES / MD1・MD2・MD3・
  32X・CDX / Master System / Saturn など)。だから**ケーブルやRGB MOD側に直列
  330〜680Ω + DCカット**を入れて、ディスプレイの75Ωとの分圧で0.3〜0.7Vppに落とすのが
  定石。これを省くと相性問題・干渉・コンソール側ロジックICの劣化が起きる
- 例外: 日本版 Master System (MK-2000) は素で約350mV
- MSX の実測 1.8Vpp も「TTL的な出力が75Ω負荷で沈んだ値」と読むと整合する

→ **基板の1/2分圧は保護としても効いている**ので外さない(外すとTTL直結で
TVPの絶対最大2.3Vを超える)。小振幅側は SOGスライス閾値(reg 10h[7:3]、
slice_level = 350mV × NTH/31)で吸収する。TTLのCSYNCを入れたい場合は
1x3ヘッダ(J14)のHSYNCへ入れて4線モード(reg 0Eh)を使う。

## 参考: 現在の設計の要点

**幾何は同期信号だけで決まり、絵の内容に依存しない。**

```
水平位置 = (offset_px + k) / htotal      offset_px はライン内の絶対位置
垂直位置 = スロット / (slot_k × vtotal)   slot_k は mflags bit0 で伝える
```

**インターレースは設定ではなく測定で決まる。**

```
TVPの検出ビット(38h bit5) OR 生VSYNCの位相の交互性   インターレースかどうか
生VSYNCの半ライン位相      どちらのフィールドが下か(次のHSYNCまでが短い側が上)
TVP vtotal / 生ライン数の比 フィールド単位かフレーム単位か
```

★**「インターレースかどうか」を TVP の検出ビット単独に任せてはいけない。**
X68000 の 24kHz 1024x848 を progressive と誤答する(実測 0x57=0x21)。生VSYNCの
半ライン位相が交互かどうかを OR で足してある。内訳は key 0x2D で読める。経緯は 9b。

**SUBSCRIBE は各NICのサブネット宛へ出す。限定ブロードキャストは使わない。**

```
en0 192.168.11.24  → 192.168.11.255 へ2秒ごと
utun*/lo0          → 除外(point-to-point は broadcast を持たない)
```

255.255.255.255 はサブネット経路を持たないので既定経路に載る。既定経路が
point-to-point の VPN トンネルだと送信元アドレスを割り当てられず、
`Can't assign requested address` で**送信そのものが失敗する**。`.app` には
`--bind` を渡せないので、VPN接続中は接続できなかった(2026-09-04)。

サブネット宛なら経路がそのNICのサブネット経路に決まるので既定経路を参照しない。
実測: VPN接続のまま `--bind` 無しで 644フレーム / 58.8Mbps / lost 0。
ボードと別サブネット(ボード 192.168.10.50 / PC 192.168.11.24)でも届く。
NICの列挙は `if-addrs` で、Windows も同じコードで動く。

送信が1つも通らなかったときは `Shared::net_error` に理由を入れてUIへ出す。
**以前は `let _ =` で捨てていたので、症状が「何も映らない」だけだった。**

`host/python` 側は `retrocastx/netutil.py` に同じ判定を寄せてある。NICの列挙は
psutil を使い、無ければ限定ブロードキャストに落ちる(= VPN下では従来どおり
失敗するので `--bind` が要る)。標準ライブラリには getifaddrs 相当が無いため。
ボードへ送る7つのツール(`discover` / `cfg` / `pll_tune` / `line_probe` /
`span_check` / `videoin` / `vs_probe`)は全部対応済みで、`--board` も `--bind` も
省略できる。引数の宣言は `netutil.add_args()` に寄せて文言を揃えてある。
**送信の失敗でプログラムを終わらせない**のも要点で、ボードはANNOUNCEを毎秒
自発送出するので probe が出せなくても受動リッスンで見つかる。

**生同期(P4 pin155=HSYNC / pin153=VSYNC)は sysドメインで測る。** pll_divide に依存
しない絶対値が得られる(key 0x2A/0x2B/0x2C)。TVPのHSOUT/VSOUT経由の値は、TVPが
インターレースのVSYNCを間引くのでフレーム単位に畳まれている。

**pll_divide はドットクロック再生専用で、描画位置に影響しない。** hs_offset は
設定項目から撤去済み(既定0)。

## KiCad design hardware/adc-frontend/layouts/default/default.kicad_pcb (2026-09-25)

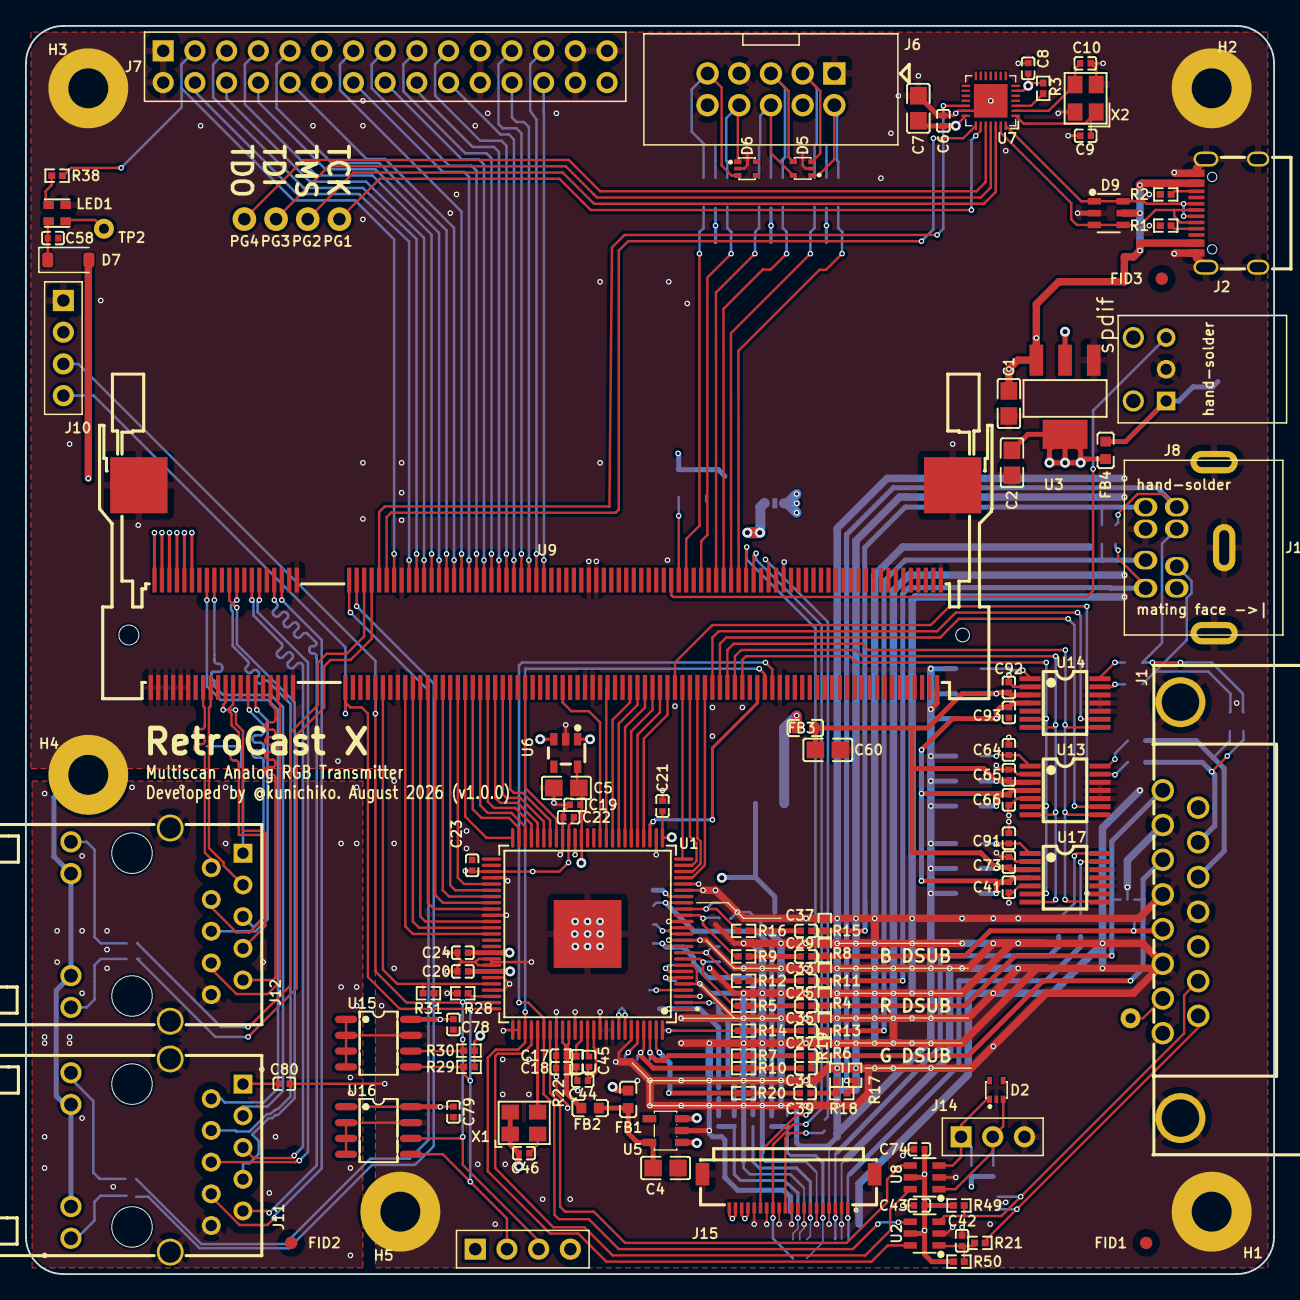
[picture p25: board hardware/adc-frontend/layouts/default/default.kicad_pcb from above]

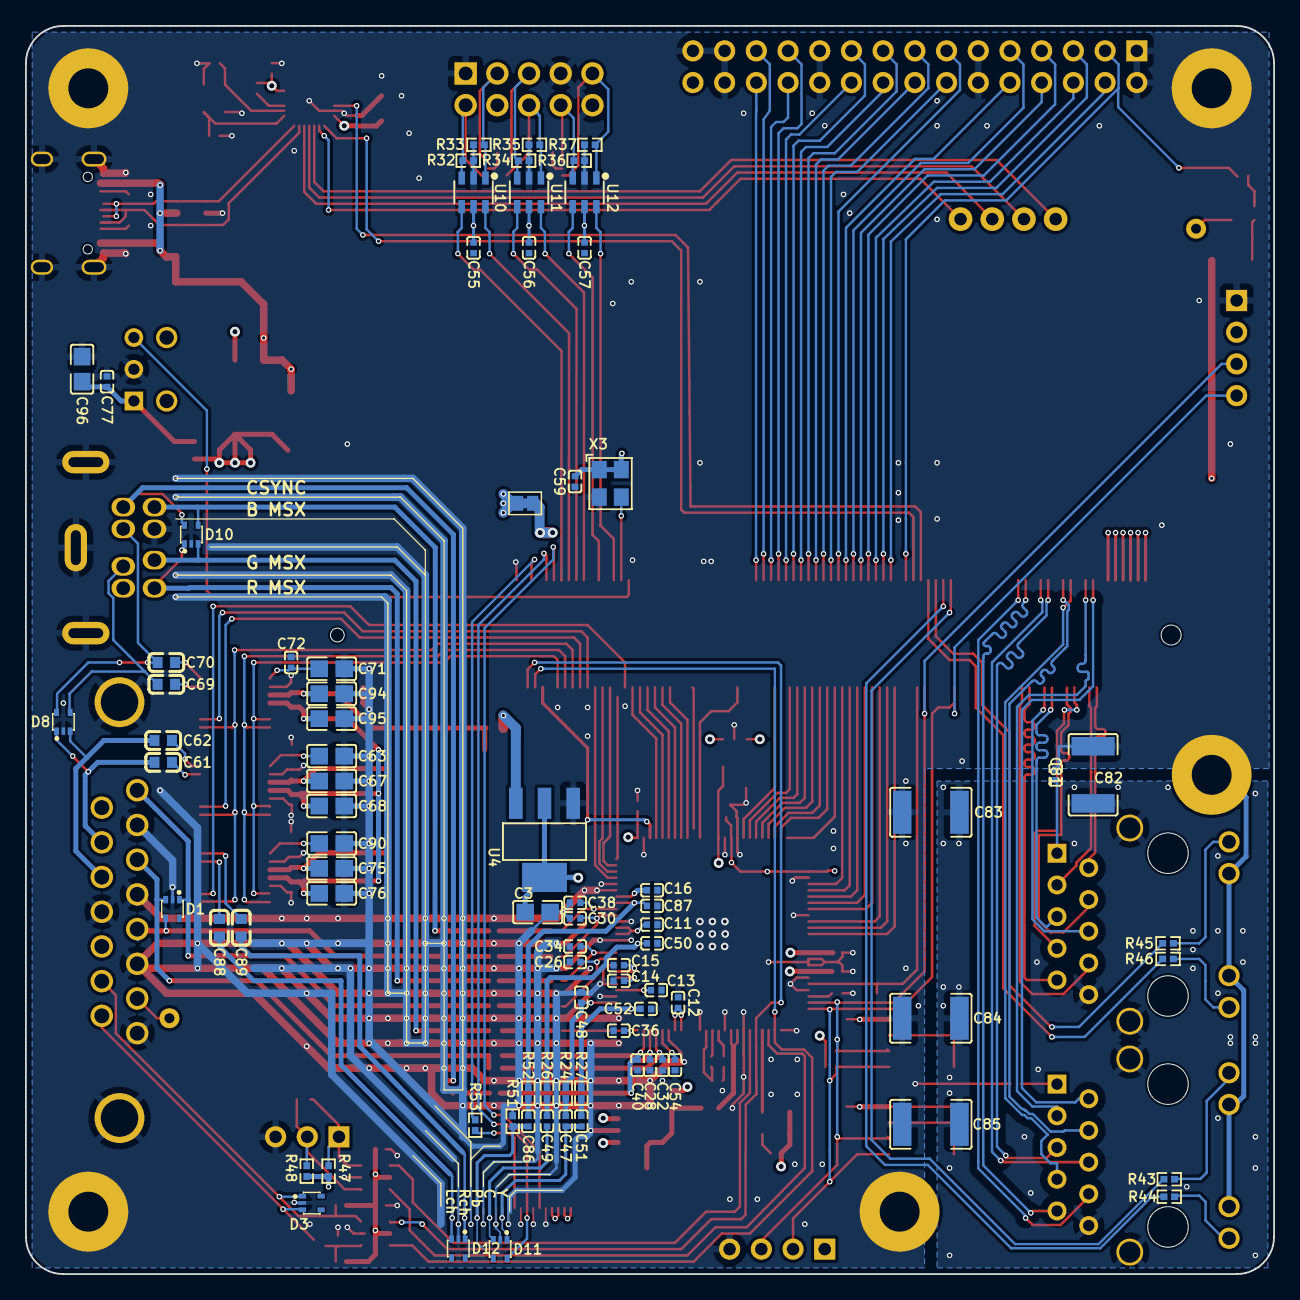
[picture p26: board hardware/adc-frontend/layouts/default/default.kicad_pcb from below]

Board: 4 copper layers, 100.0 x 100.0 mm, 205 parts (81 on the bottom side), 197 nets.

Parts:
C1, C2, C3, C4, C5, C7, C60, C63, C67, C68, C71, C75, C76, C90, C94, C95, C96: 10µF ±10%; C0805
C6, C8, C11, C12, C13, C14, C15, C16, C17, C18, C19, C20, C21, C22, C23, C24, C25, C27, C29, C31, C33, C35, C37, C39, C41, C43, C44, C46, C47, C49, C51, C55, C56, C57, C58, C59, C64, C65, C66, C72, C73, C74, C77, C78, C79, C80, C81, C86, C91, C92, C93: 100nF ±10%; C0402
C9, C10: 22pF ±5%; C0402
C26, C28, C30, C32, C34, C36, C38, C40, C48, C50, C52, C87: 33pF ±5%; C0402
C42: 1nF ±10%; C0402
C45: 4.7nF ±10%; C0402
C54: 10nF ±10%; C0402
C61, C62, C69, C70, C88, C89: 1µF ±10%; C0603
C82, C83, C84, C85: 4.7nF ±10%; C1812
D1, D2, D3, D5, D6, D8, D10, D11, D12: EMT6_L1.6-W1.2-P0.50-LS1.6-BL
D7: D_SOD-123
D9: SOT-23-6_L2.9-W1.6-P0.95-LS2.8-BL
FB1, FB2, FB3, FB4: L0603
FID1, FID2, FID3: Fiducial_1mm_Mask2mm
H1, H2, H3, H4, H5: MountingHole_3.2mm_M3_Pad
J1: DSUB-TH_DS1037-15FNAKT74-0CC
J2: USB-C_SMD-TYPE-C-31-M-12_1
J6: IDC-TH_10P-P2.54-V-R2-C5-S2.54
J7: Header_2x15_P2.54mm
J8: PLR135_T10
J9, J10: Header_1x4_P2.54mm
J11, J12: RJ45-TH_HR911130A
J13: MJ373_8B
J14: Header_1x3_P2.54mm
J15: FPC-SMD_20P-P0.50_HDGC_0.5K-1.5-20PWB
JP1: SolderJumper_2_Bridged
LED1: LED-SMD_4P-L2.0-W2.0-BR-1
PG1, PG2, PG3, PG4: PogoPin_D1.0mm
R1, R2: 5.1kΩ ±1%; R0402
R3, R32, R33, R34, R35, R36, R37, R47, R48, R49, R50: 10kΩ ±1%; R0402
R4, R6, R8, R11, R13, R15, R17, R51: 75Ω ±1%; R0402
R5, R7, R9, R10, R12, R14, R16, R20, R21, R24, R26, R27, R38, R43, R44, R45, R46, R52, R53: 220Ω ±1%; R0402
R18, R19, R22: 1.5kΩ ±1%; R0402
R28, R29, R30, R31: 2.2kΩ ±1%; R0402
TP1, TP2: TestPoint_TH1
U1: HTQFP-100_L14.0-W14.0-P0.50-LS16.0-BL-EP6.2
U2, U8, U10, U11, U12: SOT-23-6_L2.9-W1.6-P0.95-LS2.8-BL
U3, U4: SOT-223-3_L6.5-W3.4-P2.30-LS7.0-BR
U5: SOT-23-5_L3.0-W1.7-P0.95-LS2.8-BR
U6: SOT-23-5_L2.9-W1.6-P0.95-LS2.8-BR
U7: QFN-28_L4.0-W4.0-P0.40-BL-EP2.7
U9: SO-DIMM-SMD_200P-P0.60_1473005-4
U13, U14, U17: TSSOP-14_L5.0-W4.4-P0.65-LS6.4-BL
U15, U16: SOIC-8_L4.9-W3.9-P1.27-LS6.0-BL
X1, X3: OSC-SMD_4P-L3.2-W2.5-BL
X2: CRYSTAL-SMD_4P-L3.2-W2.5-BL

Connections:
154: R53.1, U9.154
A5: J2.A5, R1.1
B5: J2.B5, R2.1
aud_din8_l: C69.1, D8.4, J13.2
aud_din8_l_ac: C69.2, U14.13
aud_din8_r: C70.1, D8.5, J13.1
aud_din8_r_ac: C70.2, U14.14
aud_dsub_l: C61.1, D8.1, J1.10
aud_dsub_l_ac: C61.2, U13.13
aud_dsub_r: C62.1, D8.3, J1.11
aud_dsub_r_ac: C62.2, U13.14
aud_kokame_l: C88.1, D12.3, J15.1
aud_kokame_l_ac: C88.2, U17.13
aud_kokame_r: C89.1, D12.1, J15.3
aud_kokame_r_ac: C89.2, U17.14
aud_vref_din8: C71.1, C72.1, U14.1
aud_vref_dsub: C63.1, C64.1, U13.1
aud_vref_kokame: C90.1, C91.1, U17.1
audio_mclk_in: U9.130, X3.3
avdd: C13.1, C14.1, C15.1, C16.1, FB1.2, U1.4, U1.6, U1.7, U1.19
bck: U9.143, U13.8, U14.8, U17.8
bin1: C87.1, R52.2, U1.18
bin2: C38.1, R16.2, U1.17
bin3: C30.1, R9.2, U1.16
chassis: C82.1, C83.1, C84.1, C85.1, J11.P10, J11.SHIELD0, J11.SHIELD1, J12.P10, J12.SHIELD0, J12.SHIELD1
dataclk: U1.28, U9.151
dbg01_m1: J7.3, R38.1, U9.54
dbg02_n2: J7.4, U9.58
dbg03_n3: J7.5, U9.60
dbg04_t2: J7.6, U9.62
dbg05_m3: J7.7, U9.64
dbg06_t3: J7.8, U9.66
dbg07_r3: J7.9, U9.68
dbg08_n4: J7.10, U9.70
dbg09_m4: J7.13, U9.72
dbg10_l4: J7.14, U9.74
dbg11_l5: J7.15, U9.76
dbg12_p16: J7.16, U9.78
dbg13_j16: J7.17, U9.80
dbg14_j18_pclk: J7.18, U9.82
dbg15_j17: J7.19, U9.84
dbg16_h18: J7.20, U9.86
dbg17_h17: J7.23, U9.88
dbg18_g18: J7.24, U9.90
dbg19_h16: J7.25, U9.92
dbg20_f18: J7.26, U9.94
dn: D9.3, D9.4, J2.A7, J2.B7, U7.27
dp: D9.1, D9.6, J2.A6, J2.B6, U7.28
drgb_b: U9.142, U11.4
drgb_g: U9.144, U10.6
drgb_hs: U9.136, U12.4
drgb_i: U9.140, U11.6
drgb_r: U9.146, U10.4
drgb_vs: U9.132, U12.6
drgbi_b: D5.4, J6.5, R34.1, U11.3
drgbi_g: D5.3, J6.3, R33.1, U10.1
drgbi_hs: D6.1, J6.8, R36.1, U12.3
drgbi_i: D5.5, J6.6, R35.1, U11.1
drgbi_r: D5.1, J6.2, R32.1, U10.3
drgbi_vs: D6.3, J6.9, R37.1, U12.1
eth1_1_N: J12.P3, U9.17
eth1_1_P: J12.P2, U9.15
eth1_2_N: J12.P7, U9.21
eth1_2_P: J12.P4, U9.23
eth1_3_N: J12.P6, U9.29
eth1_3_P: J12.P5, U9.27
eth1_4_N: J12.P9, U9.33
eth1_4_P: J12.P8, U9.35
eth1_ct: C81.1, J12.P1
eth1_led_g_anode: J12.11, R45.2
eth1_led_g_gpio: R45.1, U9.46
eth1_led_y_anode: J12.14, R46.2
eth1_led_y_gpio: R46.1, U9.48
eth2_1_N: J11.P3, U9.18
eth2_1_P: J11.P2, U9.16
eth2_2_N: J11.P7, U9.22
eth2_2_P: J11.P4, U9.24
eth2_3_N: J11.P6, U9.30
eth2_3_P: J11.P5, U9.28
eth2_4_N: J11.P9, U9.34
eth2_4_P: J11.P8, U9.36
eth2_ct: C80.1, J11.P1
eth2_led_g_anode: J11.11, R43.2
eth2_led_g_gpio: R43.1, U9.42
eth2_led_y_anode: J11.14, R44.2
eth2_led_y_gpio: R44.1, U9.44
ext_clk: U1.80, X1.3
fidout: U1.22, U9.137
ft_osci: C9.1, U7.1, X2.1
ft_osco: C10.1, U7.2, X2.3
gin1: C48.1, R24.2, U1.2
gin2: C36.1, R14.2, U1.100
gin3: C28.1, R7.2, U1.98
gin4_nc: C54.1, U1.96
gnd: C1.2, C2.2, C3.2, C4.2, C5.2, C6.2, C7.2, C8.2, C9.2, C10.2, C11.2, C12.2, C13.2, C14.2, C15.2, C16.2, C17.2, C18.2, C19.2, C20.2, C21.2, C22.2, C23.2, C24.2, C26.2, C28.2, C30.2, C32.2, C34.2, C36.2, C38.2, C40.2, C41.2, C42.2, C43.2, C46.2, C48.2, C50.2, C52.2, C54.2, C55.2, C56.2, C57.2, C58.2, C59.2, C60.2, C63.2, C64.2, C65.2, C66.2, C67.2, C68.2, C71.2, C72.2, C73.2, C74.2, C75.2, C76.2, C77.2, C78.2, C79.2, C80.2, C81.2, C82.2, C83.2, C84.2, C85.2, C87.2, C90.2, C91.2, C92.2, C93.2, C94.2, C95.2, C96.2, D1.2, D2.2, D3.2, D5.2, D6.2, D8.2, D9.2, D10.2, D11.2, D12.2, H1.1, H2.1, H3.1, H4.1, H5.1, J1.2, J1.4, J1.6, J1.8, J1.12, J1.16, J1.17, J2.1, J2.2, J2.3, J2.4, J2.A1B12, J2.B1A12, J6.1, J6.4, J6.7, J6.10, J7.1, J7.2, J7.11, J7.12, J7.21, J7.22, J7.27, J7.28, J7.29, J8.2, J9.4, J10.1, J11.12, J11.13, J12.12, J12.13, J13.4, J13.9, J13.10, J13.11, J14.3, J15.2, J15.4, J15.6, J15.8, J15.10, J15.12, J15.14, J15.16, J15.21, J15.22, LED1.2, R1.2, R2.2, R4.2, R6.2, R8.2, R11.2, R13.2, R15.2, R17.2, R19.2, R28.2, R31.2, R32.2, R33.2, R34.2, R35.2, R36.2, R37.2, R51.2, U1.3, U1.5, U1.8, U1.12, U1.15, U1.20, U1.21, U1.27, U1.40, U1.42, U1.54, U1.60, U1.67, U1.68, U1.70, U1.72, U1.76, U1.77, U1.83, U1.86, U1.90, U1.91, U1.92, U1.95, U1.101, U2.2, U3.1, U4.1, U5.2, U6.2, U7.20, U7.29, U8.2, U9.1, U9.3, U9.5, U9.7, U9.9, U9.11, U9.39, U9.40, U9.55, U9.56, U9.105, U9.106, U9.107, U9.108, U9.157, U9.158, U9.199, U9.200, U9.201, U10.2, U11.2, U12.2, U13.2, U13.5, U13.10, U13.11, U13.12, U14.2, U14.5, U14.10, U14.11, U14.12, U15.1, U15.2, U15.3, U15.4, U15.7, U16.2, U16.3, U16.4, U16.7, U17.2, U17.5, U17.10, U17.11, U17.12, X1.2, X2.2, X2.4, X3.2
hsout: U1.24, U9.133
hsync: D3.1, J1.14, R49.1, U2.3
hsync_a: U1.81, U2.4, U9.155
hsync_b: U1.82, U8.4
i2ca: R28.1, U1.73
i2s_dout_din8: U9.139, U14.9
i2s_dout_dsub: U9.141, U13.9
i2s_dout_kokame: U9.129, U17.9
jtag_tck: PG1.1, U7.23
jtag_tdi: PG3.1, U7.25
jtag_tdo: PG4.1, U7.24
jtag_tms: PG2.1, U7.26
kokame_gpio2: D11.5, J15.13, U9.150
kokame_led_din: J15.11, R53.2
kokame_sw_sel: J15.15, U9.148
led_din: LED1.3, R38.2
led_dout: LED1.1, TP2.1
lrc: U9.145, U13.7, U14.7, U17.7
nRST: R3.1, U7.3
p1v9_a: C4.1, FB1.1, FB2.1, U5.5
p1v9_d: C5.1, C19.1, C20.1, U1.39, U1.69, U6.5
p3v3_a: C3.1, C11.1, C12.1, U1.13, U1.14, U1.93, U1.94, U4.2, U4.4, U5.1, U5.3
p3v3_io: C2.1, C6.1, C7.1, C8.1, C21.1, C22.1, C23.1, C24.1, C41.1, C43.1, C46.1, C55.1, C56.1, C57.1, C59.1, C66.1, C68.1, C74.1, C76.1, C78.1, C79.1, C93.1, C95.1, FB4.1, J7.30, J9.1, J10.2, J15.17, J15.18, R3.2, R29.2, R30.2, R47.2, R48.2, R49.2, R50.2, U1.26, U1.41, U1.53, U1.66, U2.5, U3.2, U3.4, U6.1, U6.3, U7.6, U7.21, U8.5, U10.5, U11.5, U12.5, U13.4, U14.4, U15.8, U16.1, U16.8, U17.4, X1.1, X1.4, X3.1, X3.4
p3v3_spdif: C77.1, C96.1, FB4.2, J8.1
p5v: C1.1, D7.2, D9.5, FB3.1, J2.A4B9, J2.B4A9, J15.19, J15.20, JP1.2, U3.3, U4.3
p5v_audio: C60.1, C65.1, C67.1, C73.1, C75.1, C92.1, C94.1, FB3.2, U13.3, U14.3, U17.3
p5v_ext: JP1.1, U9.2, U9.4, U9.6, U9.8, U9.10, U9.12
p_led_4v3: C58.1, D7.1, LED1.4
pll_avdd: C17.1, C18.1, FB2.2, U1.84, U1.85
pll_f: C44.2, C45.2, U1.89
pll_filt1: R22.1, U1.87
pll_filt2: C45.1, U1.88
pll_filt_mid: C44.1, R22.2
resetb: R31.1, U1.71, U9.51
rin1: C50.1, R26.2, U1.11
rin2: C34.1, R12.2, U1.10
rin3: C26.1, R5.2, U1.9
scki: U9.147, U13.6, U14.6, U17.6
scl: J9.3, J10.3, R30.1, U1.74, U9.49, U15.6, U16.6
sda: J9.2, J10.4, R29.1, U1.75, U9.41, U15.5, U16.5
sogin1: C52.1, R27.2, U1.1
sogin2: C40.1, R20.2, U1.99
sogin3: C32.1, R10.2, U1.97
sogout: U1.25, U9.131
spdif: J8.3, U9.128
uart_rxd: U7.22, U9.52
uart_txd: U7.19, U9.50
vd_b2: U1.36, U9.99
vd_b3: U1.35, U9.111
vd_b4: U1.34, U9.117
vd_b5: U1.33, U9.119
vd_b6: U1.32, U9.121
vd_b7: U1.31, U9.123
vd_b8: U1.30, U9.125
vd_b9: U1.29, U9.127
vd_g2: U1.50, U9.73
vd_g3: U1.49, U9.75
vd_g4: U1.48, U9.77
vd_g5: U1.47, U9.79
vd_g6: U1.46, U9.81
vd_g7: U1.45, U9.83
vd_g8: U1.44, U9.85
vd_g9: U1.43, U9.89
vd_r2: U1.63, U9.57
vd_r3: U1.62, U9.59
vd_r4: U1.61, U9.61
vd_r5: U1.59, U9.63
vd_r6: U1.58, U9.65
vd_r7: U1.57, U9.67
vd_r8: U1.56, U9.69
vd_r9: U1.55, U9.71
vin_b2: C37.1, D10.4, J13.6, R15.1
vin_b2_ac: C37.2, R16.1
vin_b3: C29.1, D1.4, J1.5, R8.1
vin_b3_ac: C29.2, R9.1
vin_c1: C49.1, D11.3, J15.7
vin_c1_ac: C49.2, R26.1
vin_csync2: D10.5, J13.3, R17.1, R18.1
vin_csync2_ac: C39.2, R20.1
vin_csync2_div: C39.1, R18.2, R19.1
vin_g2: C35.1, D10.3, J13.7, R13.1
vin_g2_ac: C35.2, R14.1
vin_g3: C27.1, C31.1, D1.3, J1.3, R6.1
vin_g3_ac: C27.2, R7.1
vin_g3_sog_ac: C31.2, R10.1
vin_hsync2: D2.1, J14.1, R47.1, U8.3
vin_pb1: C86.1, D11.4, J15.5, R51.1
vin_pb1_ac: C86.2, R52.1
vin_r2: C33.1, D10.1, J13.8, R11.1
vin_r2_ac: C33.2, R12.1
vin_r3: C25.1, D1.1, J1.1, R4.1
vin_r3_ac: C25.2, R5.1
vin_vsync2: D2.3, J14.2, R48.1, U8.1
vin_y1: C47.1, C51.1, D11.1, J15.9
vin_y1_ac: C47.2, R24.1
vin_y1_sog_ac: C51.2, R27.1
vsout: U1.23, U9.135
vsync: D3.3, J1.15, R21.1
vsync_a: U1.78, U2.6, U9.153
vsync_b: U1.79, U8.6
vsync_delayed: C42.1, R21.2, R50.1, U2.1
ys: J1.7, TP1.1

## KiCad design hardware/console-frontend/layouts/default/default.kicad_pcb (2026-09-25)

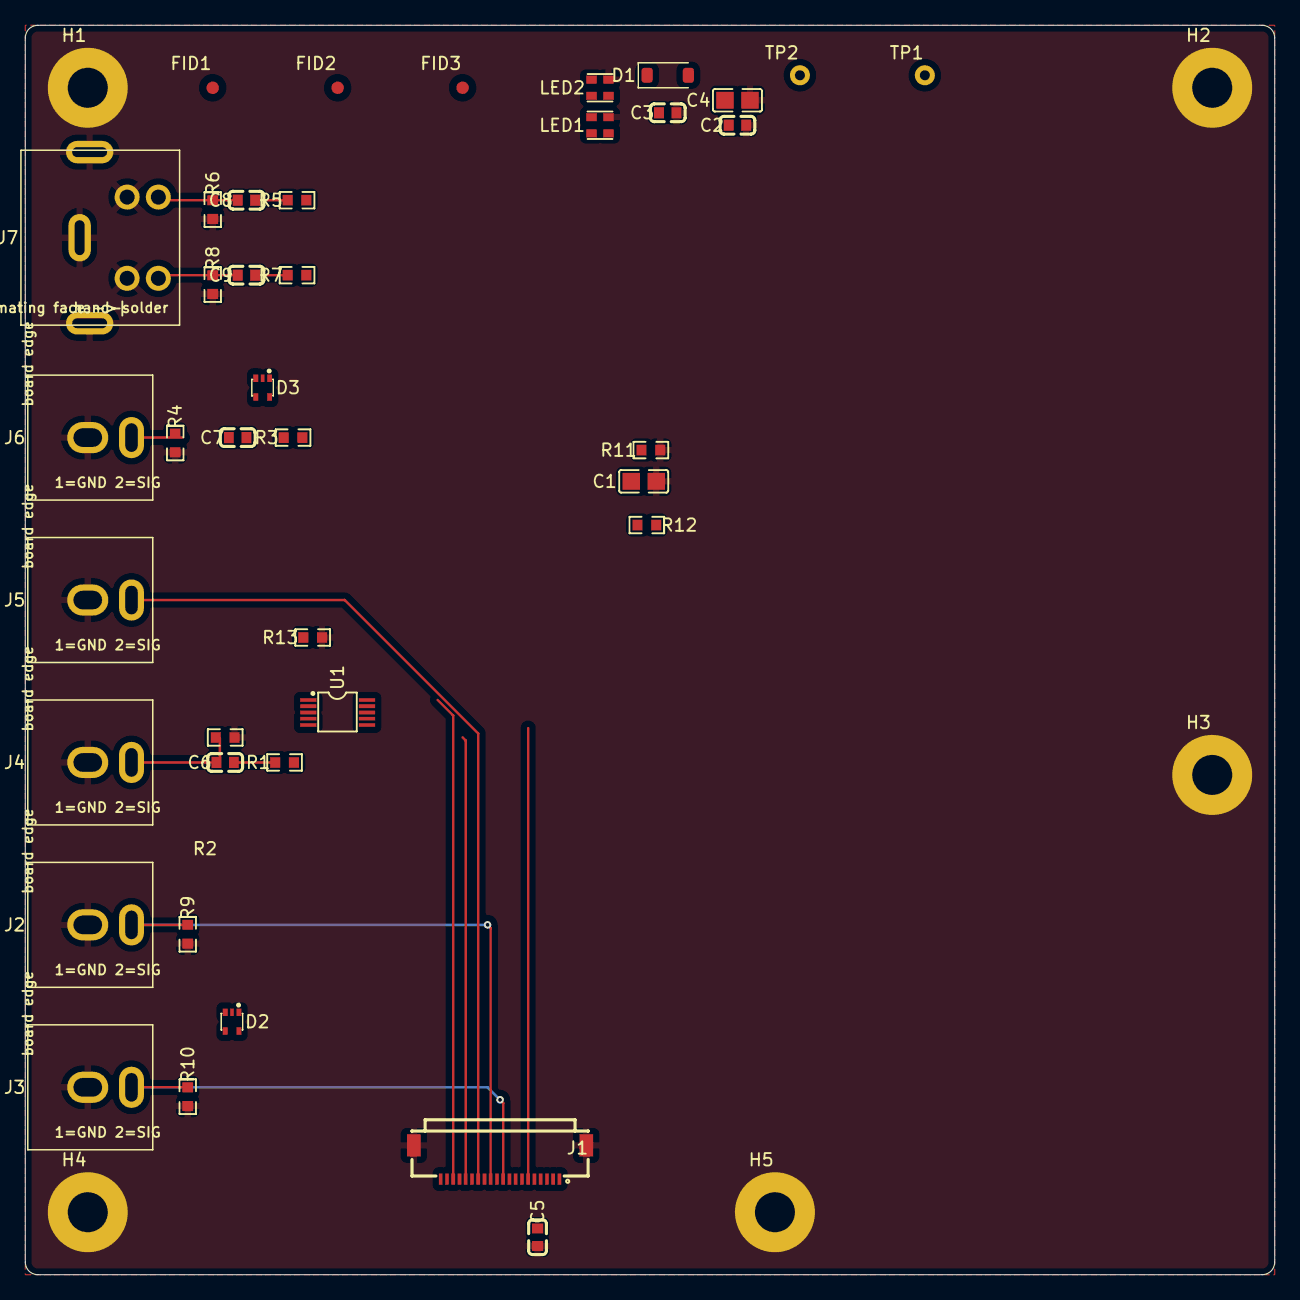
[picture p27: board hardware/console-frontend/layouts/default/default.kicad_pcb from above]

Board: 2 copper layers, 100.0 x 100.0 mm, 45 parts (0 on the bottom side), 23 nets.

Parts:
C1, C4: 10µF ±10%; C0805
C2, C3, C5, C6, C7, C8, C9: 100nF ±10%; C0603
D1: D_SOD-123
D2, D3: EMT6_L1.6-W1.2-P0.50-LS1.6-BL
FID1, FID2, FID3: Fiducial_1mm_Mask2mm
H1, H2, H3, H4, H5: MountingHole_3.2mm_M3_Pad
J1: FPC-SMD_20P-P0.50_HDGC_0.5K-1.5-20PWB
J2, J3, J4, J5, J6: RCA105
J7: MJ373_4B
LED1, LED2: LED-SMD_4P-L2.0-W2.0-BR-1
R1, R3, R5, R7, R9, R10, R11, R12, R13: 10kΩ ±1%; R0603
R2, R4, R6, R8: 75Ω ±1%; R0603
TP1, TP2: TestPoint_TH1
U1: VSSOP-10_L3.0-W3.0-P0.50-LS4.9-BL

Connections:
aud_l_out: D2.3, J1.20, J2.2, R9.1
aud_r_out: D2.4, J1.18, J3.2, R10.1
c_out: J1.14, U1.6
cvbs_ac: C6.2, R1.1, U1.9
cvbs_in: C6.1, D2.1, J4.2, R2.1
gnd: C1.2, C2.2, C3.2, C4.2, C5.2, D2.2, D3.2, H1.1, H2.1, H3.1, H4.1, H5.1, J1.5, J1.7, J1.9, J1.11, J1.13, J1.15, J1.17, J1.19, J1.21, J1.22, J2.1, J3.1, J4.1, J5.1, J6.1, J7.1, J7.2, J7.5, J7.6, J7.7, LED1.2, LED2.2, R2.2, R4.2, R6.2, R8.2, R9.2, R10.2, R11.2, R13.2, U1.3
gpio2: J1.8, TP1.1
led1_dout: LED1.1, LED2.3
led2_dout: LED2.1, TP2.1
led_din: J1.10, LED1.3
p3v3: C5.1, J1.3, J1.4, R12.1, U1.8
p5v: D1.2, J1.1, J1.2
p_led_4v3: C2.1, C3.1, C4.1, D1.1, LED1.4, LED2.4
pb_out: D3.5, J1.16, J5.2
pr_ac: C7.2, R3.1, U1.7
pr_in: C7.1, D3.4, J6.2, R4.1
sv_c_ac: C8.2, R5.1, U1.4
sv_c_in: C8.1, D3.1, J7.4, R6.1
sv_y_ac: C9.2, R7.1, U1.2
sv_y_in: C9.1, D3.3, J7.3, R8.1
sw_sel: J1.6, R13.1, U1.1, U1.5
vbias_1v65: C1.1, R1.2, R3.2, R5.2, R7.2, R11.1, R12.2
y_out: J1.12, U1.10

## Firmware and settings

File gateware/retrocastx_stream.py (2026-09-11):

#!/usr/bin/env python3
"""RetroCastX gateware step2: test-pattern streamer on Colorlight i5.

プロトコルv0の実装(ハードウェアのみ、CPU不介在):

- ANNOUNCE(TYPE_INFO): 毎秒送出 + SUBSCRIBE受信時に送信元へ即時返信
- SUBSCRIBE(type=4)受信: flags bit0(ANNOUNCE_ONLY)=0 なら映像ストリームの
  送り先をそのパケットの送信元(IP/ポート)に切替。最後のSUBSCRIBEから
  10秒で購読失効(PC側 receiver --subscribe が定期再送する)
- MODE(type=1): 購読開始時に即時 + 毎秒再送
- LINE(type=0): テストパターン(host/python の pattern.make_frame と同一の
  カラーバー+スイープライン+白枠)を RGB555 で1ライン=1パケット送出

Build:
    .venv/bin/python retrocastx_stream.py --build
Load (board via EXT DAPLink):
    openFPGALoader -c cmsisdap build/colorlight_i5/gateware/colorlight_i5.bit
Verify on PC (same L2 segment):
    python3 -m retrocastx.receiver --subscribe --dump out
Simulation (no hardware):
    .venv/bin/python sim_stream.py
"""
import argparse
import os
import struct

from migen import *

from litex.build.generic_platform import IOStandard, Pins, Subsignal, Misc
from litex.gen import LiteXModule
from litex.soc.cores.clock import ECP5PLL
from litex.soc.integration.soc_core import SoCMini
from litex.soc.integration.builder import Builder

# 既定のボード名は EEPROM を握っている側(retrocastx_i2c)を正とする。
# ★**2か所に書かない。** ANNOUNCE の初期値とEEPROM未設定時のフォールバックが
#   食い違うと、「名前を変えていないのに一覧と実機で違う」が起きる。
from retrocastx_i2c import DEFAULT_BOARD_NAME

# --- ネットワーク設定(暫定; 将来はSPIフラッシュの設定ページから読む) ---
MAC_ADDRESS = 0x025243580001          # ローカル管理アドレス "RCX"
FPGA_IP     = "192.168.10.50"
HOST_IP     = "192.168.10.1"          # SUBSCRIBE到着までのANNOUNCE宛先(初期値)
UDP_PORT    = 34600
# --- 伝送ピクセル形式(docs/protocol-v0.md / host の protocol.py と一致必須) ---
PIXFMT_RGB888 = 0             # 3B/px byte0=R byte1=G byte2=B
PIXFMT_RGB555 = 1             # 2B/px 0RRRRRGGGGGBBBBB
PIXFMT_YC8    = 3             # 2B/px 下位=緑ch8bit(CVBS/Y) 上位=赤ch8bit(S-VideoのC)
SCROLL_PX   = 4               # テストパターンのカラーバー横スクロール量[px/frame](host pattern.pyと一致必須)

# パケットタイプ(FSM内部コード。プロトコル上のtype値とは別)
_T_LINE, _T_MODE, _T_ANN, _T_AUDIO, _T_CFG = 0, 1, 2, 3, 4


def convert_ip(ip_str):
    ip = 0
    for x in ip_str.split("."):
        ip = (ip << 8) | int(x)
    return ip


def _git(*args, default=""):
    """リポジトリから情報を取る。git が無い/リポジトリ外でもビルドは通す。"""
    import subprocess
    try:
        here = os.path.dirname(os.path.abspath(__file__))
        return subprocess.check_output(["git", "-C", here, *args],
                                       stderr=subprocess.DEVNULL).decode().strip()
    except Exception:
        return default


def firmware_version() -> int:
    """ANNOUNCE に載せる版(u16)。`gw-vX.Y.Z` タグから作る。

    ★**手で上げる定数にしない。** 焼いたつもりの版と実機の版が食い違っても
      気づけない、というのが version を持つ動機なので、その version 自体が
      手作業でずれたら意味がない。

    符号化: bit15:12=major(0〜15) bit11:6=minor(0〜63) bit5:0=patch(0〜63)。

    ★**16進の桁に揃えるより範囲を優先する。** 4/4/8 なら 0.9.2 が 0x0902 と
      そのまま読めるが、パッチが 15 で頭打ちになる。実際 gw-v0.9.0〜0.9.2 を
      2日で3つ出しており、活発な時期には溢れる。表示側(discover / Viewer)が
      復号して "0.9.2" と出すので、人が16進のまま読む場面は無い。

    タグが無い/範囲外なら 0x0000。
    """
    import re
    d = _git("describe", "--tags", "--match", "gw-v*", "--abbrev=0")
    m = re.match(r"gw-v(\d+)\.(\d+)\.(\d+)$", d)
    if not m:
        return 0x0000
    major, minor, patch = (int(x) for x in m.groups())
    if major > 0xF or minor > 0x3F or patch > 0x3F:
        return 0x0000
    return (major << 12) | (minor << 6) | patch


def build_id() -> int:
    """ビルド元コミットの短縮SHA(u32)。**タグが無いビルドでも一意に指せる。**
    タグは同じでも中身が違うビットストリームを区別するために要る。"""
    h = _git("rev-parse", "--short=8", "HEAD")
    try:
        return int(h, 16) & 0xFFFFFFFF
    except ValueError:
        return 0


def make_announce_payload() -> bytes:
    """host/python/retrocastx/protocol.py の Announce と同一フォーマット(40B)。
    共通ヘッダの seq はゲートウェアが動的に差し替える。"""
    common = struct.pack("<BBBBHH", 0x52, 0x00, 3, 0, 0, 0)  # magic,ver,INFO,flags,frame,seq
    mac = bytes([0x02, 0x52, 0x43, 0x58, 0x00, 0x01])
    ip = bytes(int(x) for x in FPGA_IP.split("."))
    # fw は git のタグ由来、caps の bit0(EEPROMからMACを読めた)は実行時に差し替える
    info = struct.pack("<6s4sHHH16s", mac, ip, UDP_PORT,
                       firmware_version(), 0x0000,
                       DEFAULT_BOARD_NAME.encode()[:16])
    return common + info


class PatternPixel(LiteXModule):
    """host/python/retrocastx/pattern.py の make_frame と同一パターンの1ピクセルを
    (x, y, frame) から組み合わせ回路で生成し、RGB555(0RRRRRGGGGGBBBBB)で出力する。

    make_frame との一致条件: width/height は2のべき乗(バー幅 = width/8、
    スイープ位置 = frame % height がビットスライスで表せるため)。
    """
    def __init__(self, width, height):
        assert width & (width - 1) == 0 and width >= 8
        assert height & (height - 1) == 0
        self.x     = Signal(max=width)
        self.y     = Signal(max=height)
        self.frame = Signal(16)
        self.pix   = Signal(16)  # bit15 = 0

        # # #

        def to555(r, g, b):
            return ((r >> 3) << 10) | ((g >> 3) << 5) | (b >> 3)

        bars888 = [(255, 255, 255), (255, 255, 0), (0, 255, 255), (0, 255, 0),
                   (255, 0, 255), (255, 0, 0), (0, 0, 255), (32, 32, 32)]
        bars = Array(Constant(to555(*c), bits_sign=16) for c in bars888)
        bar_shift = log2_int(width) - 3

        # スイープラインの色 = (frame*7 % 256, 255 - frame*5 % 256, frame % 256)
        f8 = self.frame[:8]
        r8 = Signal(8)
        g8 = Signal(8)
        b8 = Signal(8)
        self.comb += [
            r8.eq((f8 * 7)[:8]),
            g8.eq(255 - (f8 * 5)[:8]),
            b8.eq(f8),
        ]

        border = ((self.x == 0) | (self.x == width - 1) |
                  (self.y == 0) | (self.y == height - 1))
        sweep = self.y == self.frame[:log2_int(height)]
        # カラーバーをフレーム毎に横スクロール(SCROLL_PX/frame)。x に frame*SCROLL_PX を
        # 加算し width幅で自動ラップ。host pattern.make_frame と同一(検証一致を維持)。
        scroll_x = Signal(max=width)
        self.comb += scroll_x.eq(self.x + self.frame * SCROLL_PX)
        self.comb += [
            If(border,
                self.pix.eq(0x7FFF),
            ).Elif(sweep,
                self.pix.eq(Cat(b8[3:], g8[3:], r8[3:])),
            ).Else(
                self.pix.eq(bars[scroll_x[bar_shift:]]),
            ),
        ]


class RetroCastXStreamer(LiteXModule):
    """プロトコルv0のTX(ANNOUNCE/MODE/LINE)とRX(SUBSCRIBE)を1本のUDPポートで捌く。

    32bitデータパス。ワード内バイト順はリトルエンディアン詰め
    (LiteX StrideConverterは下位バイトから送受する)。
    """
    def __init__(self, udp_port, sys_clk_freq, width=512, height=512, fps=30.0,
                 announce_period=1.0, mode_period=1.0, sub_timeout=10.0,
                 announce_ip=HOST_IP, udp_port_nr=UDP_PORT, my_ip=None,
                 caps=None,
                 mtu_payload=1472, interlace=False,
                 audio_sources=None, audio_nsamples=240,
                 mac_address=MAC_ADDRESS, capture=None,
                 cfg_vbp=0, cfg_hs_offset=0, cfg_pll_divide=1104,
                 cfg_in_mux1=0xAA,
                 extra_stats=None, extra_cfg=None,
                 ):
        # extra_cfg: {CONFIGキー: 書き換え可能なSignal}。SETで書き、GETで読み返す。
        #   ★**キーを1つ足すたびに配線を書かないで済むようにする。** 個体設定
        #     (0x46〜)のときは専用ポートを6本足したが、診断用の設定キーは
        #     これから増える一方なので、表で渡せる口を作っておく。
        # extra_stats: {CONFIGキー: 読み出し専用のSignal}。ストリーマの外側にある
        # 診断値(いまはARP学習)をCONFIGのGETで読めるようにするための口。
        # capture: TvpCapture(sysドメインI/F) を渡すと、テストパターンの代わりに
        #   実キャプチャライン(line_valid/line_row/line_frame/rd_*)を源にする。
        #   None の場合は従来どおり自走テストパターン。
        cap_mode = capture is not None
        # 自MAC(SUBSCRIBE/CONFIGの宛先照合とCONFIG応答に使用)。
        # リトルエンディアンのワード表現(伝送バイト順=MAC表記順)
        #
        # ★**実行時に決まる値も受ける。** EUI-48 は起動時に EEPROM から読むので、
        #   ビルド時定数とは限らない(int なら従来どおり、Signal(48) なら
        #   そのまま配線する)。48bit値の MSB 側が電線上の先頭バイト。
        # ANNOUNCE に載せる自IP。None ならビルド時定数(従来どおり)
        if my_ip is None:
            my_ip = C(convert_ip(FPGA_IP), 32)
        # caps: bit0 = MACを基板のEEPROMから読めた。
        # ★**出荷検査で「EEPROMが読めない基板」を弾くための旗。** CONFIG を
        #   往復させなくても発見の時点で分かるようにしておく。
        if caps is None:
            caps = C(0, 16)
        if isinstance(mac_address, int):
            mac_bytes = mac_address.to_bytes(6, "big")
            my_mac_lo = int.from_bytes(mac_bytes[0:4], "little")
            my_mac_hi = int.from_bytes(mac_bytes[4:6], "little")
        else:
            # b0..b5 = mac[40:48], mac[32:40], ... , mac[0:8]
            b = [mac_address[40 - 8 * i: 48 - 8 * i] for i in range(6)]
            my_mac_lo = Signal(32)
            my_mac_hi = Signal(16)
            self.comb += [
                my_mac_lo.eq(Cat(b[0], b[1], b[2], b[3])),
                my_mac_hi.eq(Cat(b[4], b[5])),
            ]
        # audio_sources: [(stream.Endpoint(AUDIO_LAYOUT/sysドメイン), rate_hz), ...]
        #   インデックスがプロトコルのsource値(0=RGB端子音声,1=LINE,2=S/PDIF)。
        #   rate_hz は int 定数(水晶由来)または Signal(32)(S/PDIF実測)
        audio_srcs = audio_sources or []
        n_aud = len(audio_srcs)
        assert 20 + 4 * audio_nsamples <= mtu_payload or n_aud == 0
        # --- タイミング諸元(host/python の sender_sim.Sender と同一の算出式) ---
        # interlace時: fpsはフィールドレート、height/vactiveはフルフレーム行数。
        # frameカウンタはフィールド毎+1、LINE.lineはフルフレーム行(protocol-v0.md)
        htotal = int(width * 1.28)
        vtotal = int(height * 1.06)
        dotclk = int(htotal * vtotal * fps) if not interlace else \
                 int(htotal * vtotal * fps / 2)
        hfreq_mhz = int(dotclk / htotal * 1000)
        vfreq_mhz = int(fps * 1000)
        mode_id = 1
        # 伝送ピクセル形式(protocol-v0.md の pixfmt)。1=RGB555 が既定。
        # 3=YC8 は同じ2B/pxで「下位=緑ch8bit / 上位=赤ch8bit」を生のまま運ぶ。
        # コンポジット/S-Video は5bitでは副搬送波の位相が推定できないので必要。
        # 2B/px は変わらないので断片化・MTU計算・受信側のバッファ確保は共通。
        pixfmt = Signal(8, reset=PIXFMT_RGB555)   # key 0x36
        # ★**伝送形式は実行時に切り替えられる**(key 0x36)。
        #   RGB888(3B/px)と RGB555・YC8(2B/px)は 1語に入る画素数が違うので、
        #   断片長・語数・xの進み・読出アドレス・語の組み立てがすべて変わる。
        #   それらをこの信号で選ぶ。
        #   ※当初ビルド時の選択にしていたが、**YC8(コンポジット/S端子)が
        #     使えなくなる**という機能の後退を伴うので実行時切替へ直した。
        #     懸念していたタイミングは実測で余裕があった
        #     (eth_rx 132.57MHz / 制約125、sys 54.94MHz / 制約45)。
        fmt888 = Signal()
        self.cfg_pixfmt = pixfmt
        # MODE の mflags。bit0 = MFLAG_INTERLACE。
        #
        # 実行時に変わる。織り込むと1VSYNC周期あたりのスロット数が半分になる
        # (プログレッシブは1ラインが2スロット、インターレースは折り返して
        #  2フィールドが交互に入るので1ラインが1スロット)。受信側はこの差を
        # 知らないと縦が2倍に引き伸ばされる。
        mflags = Signal(16, reset=1 if interlace else 0)
        self.stat_interlaced = Signal()

        lines_per_unit = height // 2 if interlace else height  # 伝送単位あたりの行数
        unit_ticks = htotal * (vtotal // 2 if interlace else vtotal)  # ts歩進/伝送単位
        assert not interlace or height % 4 == 0

        self.comb += fmt888.eq(pixfmt == PIXFMT_RGB888)

        # --- ライン断片化(host/python の protocol.fragment_line と同一の分割) ---
        #
        # ★**伝送形式は実行時に切り替える**(key 0x36)。
        #
        #     RGB555 / YC8 : 2B/px。2画素=1語
        #     RGB888       : 3B/px。4画素=3語(12バイト)
        #
        #   ピクセル数はワード整列のため4の倍数にする(3n が4の倍数になるのは
        #   n が4の倍数のときだけ。RGB555 でも4の倍数なら2の倍数を満たす)。
        # ★整列は**常に4画素**にする。RGB888 が4画素=3語なので4の倍数が要り、
        #   RGB555 でも4の倍数は2の倍数を満たすため両立する。実行時に切り替える
        #   以上、整列単位を形式で変えると断片の途中で辻褄が合わなくなる。
        PX_ALIGN = 4
        FRAG_PX_555 = ((mtu_payload - 20) // 2) & ~(PX_ALIGN - 1)
        FRAG_PX_888 = ((mtu_payload - 20) // 3) & ~(PX_ALIGN - 1)
        assert min(FRAG_PX_555, FRAG_PX_888) >= PX_ALIGN, "MTU too small"
        FRAG_PX = Signal(16)           # 1断片の最大ピクセル数(形式で決まる)
        self.comb += FRAG_PX.eq(Mux(fmt888, FRAG_PX_888, FRAG_PX_555))
        def _nw(n):                    # パターン生成側(RGB555固定)用
            return 5 + n // 2
        # パターン生成側(cap_mode でない)は RGB555 固定。断片表はビルド時に作る
        frags = []
        off = 0
        while off < width:
            n = min(FRAG_PX_555, width - off)
            frags.append((off, n))
            off += n
        assert all(n % PX_ALIGN == 0 for _, n in frags), \
            "断片のピクセル数が %d の倍数にならない (width=%d)" % (PX_ALIGN, width)
        n_frags = len(frags)
        frag_off_arr = Array(Constant(o, bits_sign=16) for o, _ in frags)
        frag_cnt_arr = Array(Constant(n, bits_sign=16) for _, n in frags)
        frag_len_arr = Array(Constant(20 + 2 * n, bits_sign=16) for _, n in frags)
        frag_nwords_arr = Array(Constant(_nw(n), bits_sign=16) for _, n in frags)
        # 実行時の値(Signal)から length / nwords を作る式。形式で分ける。
        #   RGB555/YC8: length = 20 + 2n   nwords = 5 + n/2
        #   RGB888    : length = 20 + 3n   nwords = 5 + 3n/4  (n は4の倍数)
        def _len_expr(n):
            # 20 + 2n / 20 + 3n
            return 20 + Mux(fmt888, n + Cat(C(0, 1), n), Cat(C(0, 1), n))
        def _nw_expr(n):
            # 5 + n/2 / 5 + 3n/4(n は4の倍数)
            return 5 + Mux(fmt888, n[2:] + Cat(C(0, 1), n[2:]), n[1:])
        aud_nwords = 5 + audio_nsamples
        # ★nwords / word_idx の幅は**両方の形式の最悪値**から決める。
        #
        #   捕捉モードでは断片のピクセル数が実行時に決まる(n_c = min(FRAG_PX, 幅))
        #   ので、ビルド時の frags 表(RGB555固定)だけから幅を取ると RGB888 で
        #   足りなくなる。足りないと nwords が黙って切り捨てられ、`last` が
        #   早く立って**先頭1語だけのパケット**が出る(2026-09-03 に W=16 の
        #   試験で発覚。13→4bit に対し RGB888 は 17 語で 17&0xF=1 になっていた)。
        #   width=1024 の実機ビルドは 555 が 367 語で 9bit になり 888 の 368 語が
        #   たまたま収まっていた。偶然で成立していただけなので必ず両方見る。
        px_max = ((width + PX_ALIGN - 1) // PX_ALIGN) * PX_ALIGN
        nw_555_max = _nw(min(FRAG_PX_555, px_max))
        nw_888_max = 5 + 3 * min(FRAG_PX_888, px_max) // 4
        max_nwords = max(10, 8, aud_nwords if n_aud else 0,
                         *(_nw(n) for _, n in frags),
                         nw_555_max, nw_888_max)

        line_interval = int(sys_clk_freq / (fps * lines_per_unit))
        assert line_interval >= 1

        ann_payload = make_announce_payload()
        ann_words = [int.from_bytes(ann_payload[i:i + 4], "little")
                     for i in range(0, len(ann_payload), 4)]
        n_ann_words = len(ann_words)       # 10

        # --- 状態レジスタ ---
        seq      = Signal(16)
        frame    = Signal(16)              # interlace時はフィールドカウンタ
        line     = Signal(max=max(lines_per_unit, 2))  # 伝送単位内の行番号
        field    = Signal()                # インターレースのフィールド極性(0=偶)
        frag_idx = Signal(max=max(n_frags, 2))
        # 断片パラメータは実行時に決める。ライン毎に「黒でない範囲」だけを送るので、
        # 送出開始位置も長さも一定ではない。これにより hs_offset が不要になる
        # (取り込みはラインの頭から。どこを送るかはFPGAが中身を見て決める)。
        frag_off = Signal(16)          # この断片の先頭ピクセル位置(ライン内絶対)
        frag_cnt = Signal(16)          # この断片のピクセル数
        frag_last = Signal()           # 最終断片か
        px_end = Signal(16)            # このラインで送る範囲の終端(この値は含まない)
        # RGB888(4画素=3語)の語内位相 0..2。2B/px のときは使わない
        gph = Signal(2)
        # RGB888 の語1は2エントリを跨ぐため、前エントリをラッチして持つ
        ent_prev = Signal(64)

        def _px_adv():
            """ペイロード1語を送出したときの前進動作(形式で変わる)。

            RGB555/YC8: 1語=2画素なので毎語 x += 2
            RGB888    : 4画素=3語。位相を回し、群の最後(位相2)で x += 4
            """
            return [If(fmt888,
                       If(gph == 2,
                           NextValue(gph, 0),
                           NextValue(x, x + 4),
                       ).Else(
                           NextValue(gph, gph + 1),
                       ),
                   ).Else(
                       NextValue(x, x + 2),
                   )]
        ts_frame = Signal(32)              # 現伝送単位先頭のドットクロックカウンタ
        ts_line  = Signal(32)              # 現ライン先頭(= ts_frame + line*htotal)

        # MODEで報告する諸元。capture時はFPGAが実信号から測った値を使う(ビルド時の
        # 仮定値ではない)。周波数フィールドはmHz単位なので実測Hzを1000倍する。
        mode_htotal = Signal(16); mode_vtotal = Signal(16)
        # 送出する行数。vtotalが小さいモードでは512行送ると下が空くので実測に従う
        mode_vactive = Signal(16)
        mode_dotclk = Signal(32); mode_hfreq = Signal(32); mode_vfreq = Signal(32)
        if cap_mode:
            self.comb += [
                mode_htotal.eq(capture.meas_htotal),
                # ★生の meas_vtotal ではなく、フレーム連続一致で濾した方を出す。
                #   生値には偽VSYNC由来の単発異常(実機で 210/311/367/1136/2446)が
                #   混ざり、Viewer 側はそれをモード変更と受け取ってウィンドウの
                #   リサイズと再フィットを始めてしまう。生値は CONFIG 0x23 で
                #   引けるので診断には困らない。
                mode_vtotal.eq(capture.meas_vtotal_stable),
                mode_vactive.eq(capture.out_vactive),
                mode_dotclk.eq(capture.meas_dotclk),
                mode_hfreq.eq(capture.meas_hfreq * 1000),
                mode_vfreq.eq(capture.meas_vfreq),   # 既にmHz(8秒積算で0.125Hz分解能)
            ]
        else:
            self.comb += [
                mode_htotal.eq(htotal), mode_vtotal.eq(vtotal),
                mode_vactive.eq(height),
                mode_dotclk.eq(dotclk), mode_hfreq.eq(hfreq_mhz),
                mode_vfreq.eq(vfreq_mhz),
            ]

        # 実アナログキャプチャ模擬: 源はGbEの状態に無関係に一定間隔で走り続ける。
        # cap_* が「今キャプチャ中」の位置(自走)。line/frame/ts_* は送信開始時に
        # cap_* からスナップショットする(送信中は固定)。送信FSMがビジーで間に合わ
        # なかったラインは送られない=ライン単位でドロップ(バックプレッシャしない)。
        cap_line     = Signal(max=max(lines_per_unit, 2))
        cap_frame    = Signal(16)
        cap_ts_frame = Signal(32)
        cap_ts_line  = Signal(32)

        # フルフレーム座標の行番号。capture時は送信開始時にラッチした行を使う。
        row = Signal(max=height)
        cap_row = Signal(max=height)               # capture: ラッチした送信対象行
        if cap_mode:
            self.comb += row.eq(cap_row)
        elif interlace:
            self.comb += row.eq(Cat(field, line))   # row = line*2 + field
        else:
            self.comb += row.eq(line)

        ann_ip   = Signal(32, reset=convert_ip(announce_ip))
        ann_port = Signal(16, reset=udp_port_nr)
        sub_ip   = Signal(32)
        sub_port = Signal(16)
        sub_timer = Signal(max=max(int(sys_clk_freq * sub_timeout), 2))
        sub_valid = Signal()
        self.comb += sub_valid.eq(sub_timer != 0)

        # --- RX: SUBSCRIBE(16B=4ワード) / CONFIG(24B=6ワード)。いずれも
        #     w2/w3に宛先MACを含み、自MACかFF×6(ワイルドカード)のみ受理する ---
        rx = udp_port.source
        rx_first = Signal(reset=1)
        self.comb += rx.ready.eq(1)
        self.sync += If(rx.valid, rx_first.eq(rx.last))
        rx_magic_ok = (rx.data[0:8] == 0x52) & (rx.data[8:16] == 0x00)

        in_pkt = Signal()                        # magic/version OK
        rx_type = Signal(8)
        rx_flags = Signal(8)
        rx_widx = Signal(3)                      # 先頭以降のワード番号(1..7飽和)
        rx_src_ip = Signal(32)
        rx_src_port = Signal(16)
        rx_mac_lo = Signal(32)
        cfg_target = Signal(8)
        cfg_op = Signal(8)
        cfg_key = Signal(16)
        cfg_mac_ok = Signal()                    # CONFIG: w3時点でMAC確定
        cfg_ip = Signal(32)
        cfg_port = Signal(16)

        # SUBSCRIBEはMAC上位2BがW3=最終ビートに乗るため、その場で判定する
        sub_done = rx.valid & rx.last & in_pkt & (rx_type == 4) & (rx_widx == 3)
        sub_mac_ok = (((rx_mac_lo == my_mac_lo) & (rx.data[0:16] == my_mac_hi)) |
                      ((rx_mac_lo == 0xFFFFFFFF) & (rx.data[0:16] == 0xFFFF)))
        sub_hit_any = sub_done & sub_mac_ok
        sub_hit = sub_hit_any & ~rx_flags[0]     # flags bit0 = ANNOUNCE_ONLY
        cfg_done = (rx.valid & rx.last & in_pkt & (rx_type == 5) &
                    (rx_widx == 5) & cfg_mac_ok)

        # --- 個体設定(ボード名 / 静的IP)---
        #
        # ★**値はここでは持たない。** ボード名と静的IPは EEPROM が正で、その
        #   読み書きは I2C を握っている StatusDisplay 側にある。ここで持つと
        #   「起動時にEEPROMから読んだ値」をどう初期値にするかで詰まる
        #   (Migen のリセット値は定数でなければならない)。ストリーマは
        #   CONFIG を「1枠ぶんの書き換え要求」に翻訳するだけにする。
        self.ident_set_stb  = Signal()
        self.ident_set_sel  = Signal(3)     # 0..3=name語 4=静的IP 5=flags
        self.ident_set_val  = Signal(32)
        self.ident_save_stb = Signal()
        # StatusDisplay からの読み返し(GET応答と ANNOUNCE の name に使う)
        # 繋がなければ既定名のまま(sim はここを配線しない)
        self.stat_name       = Signal(128, reset=int.from_bytes(
            DEFAULT_BOARD_NAME.encode()[:16].ljust(16, b"\0"), "little"))
        self.stat_static_ip  = Signal(32)
        self.stat_net_flags  = Signal(8)
        self.stat_save_state = Signal(2)
        self.stat_ee_status  = Signal(8)

        # CONFIG のキー → 書き換える枠。**フラットな If の並びにする**
        # (優先順位マルチプレクサになる Elif 連鎖は sys のクリティカルパスを
        #  伸ばす。同じ理由で応答側も Case にしてある)。
        _IDENT_KEYS = {0x46: 5, 0x47: 4, 0x48: 0, 0x49: 1, 0x4A: 2, 0x4B: 3}
        self.comb += [
            self.ident_set_val.eq(rx.data),
            If(cfg_done & (cfg_op == 0) & (cfg_target == 0),
                *[If(cfg_key == k,
                     self.ident_set_stb.eq(1), self.ident_set_sel.eq(sel))
                  for k, sel in _IDENT_KEYS.items()],
                If(cfg_key == 0x4C, self.ident_save_stb.eq(rx.data[0])),
            ),
        ]
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

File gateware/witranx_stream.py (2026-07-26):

#!/usr/bin/env python3
"""WiTranX gateware step1: ANNOUNCE beacon on Colorlight i5.

プロトコルv0の ANNOUNCE(TYPE_INFO)パケットを毎秒UDP送出する最小構成。
PC側の `python3 -m witranx.discover` がこれを受信できればstep1完了。
(ブロードキャスト送信はLiteEthの通常UDPパスに無いため、step1では
 HOST_IP宛ユニキャスト。step2でSUBSCRIBE受信→送り先切替を実装する)

Build:
    .venv/bin/python witranx_stream.py --build
Load (board via EXT DAPLink):
    openFPGALoader -c cmsisdap build/colorlight_i5/gateware/colorlight_i5.bit
"""
import argparse
import struct

from migen import *

from litex.gen import LiteXModule
from litex_boards.platforms import colorlight_i5

from litex.soc.cores.clock import ECP5PLL
from litex.soc.integration.soc_core import SoCMini
from litex.soc.integration.builder import Builder

from liteeth.phy.ecp5rgmii import LiteEthPHYRGMII
from liteeth.core import LiteEthUDPIPCore

# --- ネットワーク設定(暫定; 将来はSPIフラッシュの設定ページから読む) ---
MAC_ADDRESS = 0x025754580001          # ローカル管理アドレス "WTX"
FPGA_IP     = "192.168.10.50"
HOST_IP     = "192.168.10.1"
UDP_PORT    = 34600


def make_announce_packet() -> bytes:
    """host/python/witranx/protocol.py の Announce と同一フォーマット(40B)。"""
    common = struct.pack("<BBBBHH", 0x57, 0x00, 3, 0, 0, 0)  # magic,ver,INFO,flags,frame,seq
    mac = bytes([0x02, 0x57, 0x54, 0x58, 0x00, 0x01])
    ip = bytes(int(x) for x in FPGA_IP.split("."))
    info = struct.pack("<6s4sHHH16s", mac, ip, UDP_PORT, 0x0001, 0x0000, b"witranx-i5")
    return common + info


class AnnounceBeacon(LiteXModule):
    """固定40byteのANNOUNCEパケットを period_s ごとにUDP送出する。

    32bitデータパス。ワード内バイト順(リトルエンディアン詰め)は
    実機のWiresharkで要確認(逆なら struct.unpack の "<" を ">" に変える)。
    """
    def __init__(self, udp_port, dst_ip, dst_udp_port, sys_clk_freq, period_s=1.0):
        payload = make_announce_packet()
        assert len(payload) % 4 == 0
        words = [int.from_bytes(payload[i:i+4], "little") for i in range(0, len(payload), 4)]
        n_words = len(words)
        rom = Array(Constant(w, bits_sign=32) for w in words)

        word_idx = Signal(max=n_words)
        tick = Signal(32)
        period_ticks = int(sys_clk_freq * period_s)

        sink = udp_port.sink
        self.comb += [
            sink.ip_address.eq(convert_ip(dst_ip)),
            sink.src_port.eq(dst_udp_port),
            sink.dst_port.eq(dst_udp_port),
            sink.length.eq(len(payload)),
            sink.data.eq(rom[word_idx]),
            sink.last_be.eq(0b1000),
        ]

        self.fsm = fsm = FSM(reset_state="WAIT")
        fsm.act("WAIT",
            NextValue(tick, tick + 1),
            If(tick >= period_ticks - 1,
                NextValue(tick, 0),
                NextValue(word_idx, 0),
                NextState("SEND"),
            ),
        )
        fsm.act("SEND",
            sink.valid.eq(1),
            sink.last.eq(word_idx == n_words - 1),
            If(sink.ready,
                If(word_idx == n_words - 1,
                    NextState("WAIT"),
                ).Else(
                    NextValue(word_idx, word_idx + 1),
                ),
            ),
        )


def convert_ip(ip_str):
    ip = 0
    for x in ip_str.split("."):
        ip = (ip << 8) | int(x)
    return ip


class _CRG(LiteXModule):
    def __init__(self, platform, sys_clk_freq):
        self.cd_sys = ClockDomain()
        clk25 = platform.request("clk25")
        self.pll = pll = ECP5PLL()
        pll.register_clkin(clk25, 25e6)
        pll.create_clkout(self.cd_sys, sys_clk_freq)


class WiTranXStream(SoCMini):
    def __init__(self, revision="7.0", sys_clk_freq=int(50e6)):
        platform = colorlight_i5.Platform(board="i5", revision=revision,
                                          toolchain="trellis")
        SoCMini.__init__(self, platform, sys_clk_freq,
                         ident="WiTranX announce beacon (step1)")
        self.crg = _CRG(platform, sys_clk_freq)

        # Ethernet PHY (RGMII) + hardware UDP/IP core
        self.ethphy = LiteEthPHYRGMII(
            clock_pads = platform.request("eth_clocks", 0),
            pads       = platform.request("eth", 0),
            tx_delay   = 0e-9)
        self.ethcore = LiteEthUDPIPCore(
            phy         = self.ethphy,
            mac_address = MAC_ADDRESS,
            ip_address  = FPGA_IP,
            clk_freq    = sys_clk_freq,
            dw          = 32,
            # 幅変換・CRC等をsysドメインで実行(eth_rx/txドメインは8bit@125MHzの軽い経路のみ
            # にする。これ無しだとeth_rxの125MHzタイミングが閉じない: 実測93MHz)
            with_sys_datapath = True)

        udp_port = self.ethcore.udp.crossbar.get_port(UDP_PORT, dw=32)
        self.beacon = AnnounceBeacon(udp_port, HOST_IP, UDP_PORT, sys_clk_freq)


def main():
    ap = argparse.ArgumentParser()
    ap.add_argument("--build", action="store_true")
    ap.add_argument("--revision", default="7.0", help="i5 board revision")
    # タイミングは with_sys_datapath=True + sys 50MHz で収束(eth_rx 133/125MHz, sys 52/50MHz)。
    # seedは今後のリグレッション時の調整用ノブとして残す
    ap.add_argument("--seed", type=int, default=2, help="nextpnr placement seed")
    args = ap.parse_args()
    soc = WiTranXStream(revision=args.revision)
    builder = Builder(soc, output_dir="build/colorlight_i5", compile_software=False)
    builder.build(run=args.build, seed=args.seed)


if __name__ == "__main__":
    main()

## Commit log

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2026-07-26 5V給電をEXT経由(USB-C)既定に変更、README構成を整理
    - P1/P2/P4の5Vピンを束ねてSJ1経由で5Vレールへ(既定)。J7 DCジャックは
    スタンドアロン検証用(未実装可、SJ1と排他)
    - README: 古いPMOD×5表記や2×16表記を修正、節構成を整理
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2026-07-26 ゲートウェアstep2: テストパターン・ストリーマ実装、シミュレーションで検証
    - LINE/MODEパケタイザとSUBSCRIBE購読(送り先動的切替、10秒失効)を
    ハードウェア実装。テストパターンはhost側pattern.make_frameと同一を
    RGB555・512x512・30fpsで生成
    - sim_stream.py: UDPポート直結のMigenシミュレーションで、生成パケットを
    PC側protocol.py/FrameAssemblerに食わせ再構成フレームのビット一致を検証
    - receiver.py: --subscribe(2秒ごとキープアライブ)を追加。ANNOUNCEも
    共通seq空間を消費するためINFOのseqを追跡し偽ロス計上を修正
    - タイミング収束: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
    [retrocastx_stream.py, sim_stream.py]
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2026-07-29 WIP: main.atoをatomic part参照へ改修(受動15種+IC15点)
    - passives.ato: 受動部品ラッパー15種(from Resistor/Capacitor + atomic part trait)。
    値→LCSC対応をEasyEDA検証済みメタから自動生成
    - main.ato: 全 new Resistor/Capacitor をラッパーへ置換(~>接続維持)、
    IC/コネクタ15スタブに is_atomic_part+has_part_picked+prefix trait を挿入
    - 手法は最小テストでオフラインato build成功を確認済み(picking skip)
    未了: ESD(ROHM 6ピン化)、TOSLINK(DNP)、ヘッダ4種/ソルダージャンパのFP、ato build。
2026-07-29 main.ato改修完了: オフラインato buildでPCB/BOM/ネットリスト生成成功
    atopile部品API停止下で、EasyEDA取り込み部品を使い完全オフラインで
    ato buildを通した。成果物: default.kicad_pcb(104フットプリント/612ネット)、
    default.bom.csv(LCSC番号付き発注可能BOM)。
    - parts/_mech/mech.ato: 手実装機構部品(ヘッダ2x15/1x4・ソルダージャンパ・
    TOSLINK PLR135)をフットプリント同居ディレクトリに配置し is_atomic_part +
    has_part_removed(DNP: 基板にFPは載るがJLC発注除外)で定義。自作footprint/symbol生成
    - コネクタ(usbc/jack)のmanufacturer不一致修正
    - EsdArray4をROHM EMZT6.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
    [default.kicad_pcb]
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2026-07-29 発注前QA: USB-C実ピン修正、コネクタ照合結果を記録
    atopile取り込み部品のフットプリント実パッドと元・仮ピン番号を照合:
    - USB-C(TYPE-C-31-M-12): 標準USB-C配置で実パッド名(A1B12/A4B9/A5/B5/A6等)へ
    再マッピング修正。VBUS/GND/CC1/CC2が正しい実パッドに接続されることを確認
    - D-SUB15/DCジャック/PCM1808/EEPROM/IC類: 数値パッドで整合(確認済み)
    - MagJack(HR911130A): 実パッドP1-P10/SHIELD/11-14。スタブの数値1-18と不一致→要修正。
    P1-P10→MDI/CT対応はデータシート必須(PDF機械取得不可のため未解決、README詳細)
    - 3.5mmジャック(PJ-327C-4A): 実4ピン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
2026-07-30 MagJack(HR911130A)を正式ピン配置へ修正 + データシート追加
    HanRun公式データシート(datasheets/HR911130A_HanRun_MagJack.pdf)の回路図に基づき
    GbeMagJackスタブを実パッド配置へ修正:
    - チップ側MDI: P2=MDI0+ P3=MDI0- P4=MDI1+ P7=MDI1- P5=MDI2+ P6=MDI2- P8=MDI3+ P9=MDI3-
    - P1=センタータップ共通(0.1µF→GND)、P10=Bob-Smith/シャーシ基準(→chassis)
    - 11/12=緑LED, 14/13=黄LED(未接続), SHIELD0/1=シェル(→chassis)
    - 内蔵Bob-Smith(4x75Ω+1000pF/2kV)前提でCTデカップリングを4→2(各ポート1)に修正
    オフラインato build確認(MagJackのlead/pad不一致解消、電気設計検証〜bom通過)。
    残るpinout失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
2026-07-30 3.5mmジャックを実4ピンへ修正 → ato build 全ターゲット成功
    PJ-327C-4Aの実パッド(4)に合わせ AudioJack35 を5→4ピンに修正
    (tip/ring/sleeve/switch)。これで全コネクタのlead/pad不一致が解消し、
    `ato build` が pinout 含む全ターゲットで成功(Build successful)。
    成果物: default.kicad_pcb(107フットプリント/674ネット)、default.bom.csv。
    ato.yaml注記とREADMEのコネクタQA表を更新。
    残: 3.5mmジャックのtip/ring/sleeve割当のみPJ-327C-4Aデータシートで要確認。
2026-07-30 3.5mmジャック(PJ-327C-4A)を正式配置へ修正 + データシート追加 — コネクタQA完了
    HOOYA公式データシート(datasheets/PJ-327C-4A_HOOYA_3.5mmJack.pdf)の回路図・部品表どおり:
    1=CASE=Sleeve(GND), 2=Tip(L), 3=検出スイッチ(未使用), 4=Ring(R)。
    旧・仮割り当て(tip~1/ring~2/sleeve~3)を修正。
    → 全コネクタのピン配置を実データシートで確定、発注前コネクタQA完了。
    ato build 全ターゲット成功継続。
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2026-07-30 27MHz EXT_CLKを水晶→アクティブ発振器へ修正(部品選定ミス修正)
    Osc27Mが4ピン発振器配線(VCC/GND/OUT/EN)なのに、選定部品が水晶(C9008
    X322527MSB4SI)だった不整合を修正。TVP7002 EXT_CLKは単線クロック入力なので
    アクティブ発振器で駆動するのが正。YXC OT322527MJBA4SL(C725995、OSC-SMD_4P、
    3.3V CMOS、pin1=Tri-state/2=GND/3=OUT/4=VDD)へ差し替え。配線は不変。
    旧水晶partは削除。ato build全ターゲット成功、BOMにX1=OT322527MJBA4SL確認。
    [CRYSTAL-SMD_4P-L3.2-W2.5-BL-1.step, OSC-SMD_4P-L3.2-W2.5-CJ13-320001210A20.step, default.kicad_pcb]
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2026-08-05 映像バス: TVPビット順修正 + P2/P3再配置 + spdif移設
    - Tvp7002定義のR/G/Bビット順をデータシート/シンボルに合わせて修正
    (若番ピン=MSB, pin29=B9…pin38=B0)。上位8bit[9:2]を正しくキャプチャ。
    - 映像24bitをSO-DIMM昇順↔TVP物理降順の単調写像に整列(向かい合わせ配置で
    クロスなし配線)。B6-B9をP4後列→P3前列の連続run(pin117-123)へ移設。
    → ext基板でもP2(20)+P3で映像が完結。旧P4ボールE1/E4/H3/H5は空きに。
    - spdifをpin109(E19)→P3後半pin125(C17)へ移設(映像ファンアウトを横切らない)。
    gatewareのspdifピン制約も同期(E19→C17)。ネット名をs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
    [default.kicad_pcb]
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2026-08-06 SO-DIMMピン再配置: 映像をP2/P3集約 + I2C/音声整理 + DATACLKをPCLKピンへ
    - P2: SDA/SCL/RESETB(41/49/51) + R2-R9(57-71) + G2-G9(73-89)。
    - P3: B2-B9集中(99-127) + TVPタイミング。SO-DIMM昇順↔TVP降順の単調は維持。
    - 音声をP4に集約整理: SPDIF=E4, MCLK=F1, BCK=F3, LRCK=G3, DOUT=H3/H4。
    gateware _audio_io のピン制約も同期。
    - DATACLK: 指定のD3はPCLK非対応(prjtrellis iodb確認)のため、P3唯一の
    クロック対応ピン E2=PCLKC7_0(pin151)へ。SPDIFはsysオーバーサンプリング
    復号でPLL不要=E4通常GPIOで可。nextpnr実ビルドで配置配線とクロック網載りを検証。
    - docs/sodimm-pinmap.html を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
    [default.kicad_pcb]
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2026-08-06 passives: 各パッシブに値をassertで付与しKiCad Value表示を修正
    `{ℝ+}F`/`{ℝ+}Ω` の文字化けを解消。原因はatomic part(by_supplier)が
    電気値属性を持たず、has_simple_value_representationが未拘束パラメータを
    表示していたため。`param = 値`はsuperset化されず表示に反映されないので、
    `assert resistance/capacitance within lo to hi` で拘束(R=±1%, C=±5〜10%)。
    → KiCadのValueが 75Ω ±1% / 4.7nF ±10% 等に。max_power/max_voltageは
    隠しプロパティのため未拘束のまま(表示・配線に影響なし)。
    [default.kicad_pcb]
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2026-08-07 gateware: TVP初期化(入力_3選択)+ 同期/ライン/クロック計測ステータス表示
    - StatusDisplay: TVP手順を「0x19<-0xAA(SOG/R/G/B全て_3入力を選択, OSSC互換)」書込 +
    0x14(Sync Detect)/0x37:38(Lines/Frame)/0x39:3A(Clocks/Line)読出に変更。
    OLEDに TVP:ACK / SYNC / LPF / CPL / UP を表示。
    - fi(FORMATカウンタ)を Signal(4)->Signal(5) に修正(21文字化でFMT無限ループ回避)。
    ※simで検出(OLEDデータフレームに到達せず)。
    - sim_status: BFMに0x14/0x37-3A/0x19書込を反映し検証(sync/lpf/cpl一致)。
    - 実機確認: 無信号でHSD=0/VSD=0(=同期無しを正しく検出)、I2C複数レジスタ読出も安定。
    Co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
    [retrocastx_i2c.py, sim_status.py]
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2026-08-08 gateware: キャプチャ時のライン重複送信を修正(見かけfps 5倍/frame番号往復の真因)
    line_pending が sticky レジスタだったため、送信中ずっと line_valid=1 で再セット
    され、送信完了時の pop で FIFO が空になった直後に「空ヘッドの残留値」で余分な
    ラインを再送していた。残留値は古い frame 番号を持つため、受信側で frame が
    N↔N+1 を往復し、フレーム完成判定が実フレームの5倍発火(280fps)。パケットも
    1.5倍(1536/frame)出ていた。
    修正: capture時は line_pending を capture.line_valid の組合せ結果にし、FIFOに
    実データが有る間だけ送出す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
    [retrocastx_stream.py, sim_capture_stream.py]
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2026-08-08 hw: PCM1808のピン番号を修正(電源逆接・L/R逆の重大バグ) + 電源ネットの明示命名
    PCM1808 (U1/U2) のピン割り当てが「1から信号を順に並べた仮番号」のままで、
    コード自身に残っていた「注意: ピン番号は仮割り当て。データシート(SLES177)と必ず照合」
    という警告が未処理だった。データシート SLES177B の実配置と照合して修正:
    誤(仮) 正(SLES177B)
    1 scki 1 vref
    2 bck 2 agnd
    3 lrc 3 vcc (5V)
    4 dgnd 4 vdd (3.3V)
    5 vdd 5 dgnd
    6 dout 6 scki
    7 fmt 7 lrc
    8 md1 8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
2026-08-08 gateware: I2S出力をSLEWRATE=SLOW/DRIVE=4に + ノイズ量の計測ツール
    試作配線ではI2SのジャンパがアナログRGBを直交して横切っているため、出力エッジを
    鈍らせて容量結合を減らす狙いで SLEWRATE=SLOW + DRIVE=4mA を mclk_out/bck/lrck に
    設定した(最大12.288MHzなので波形品質には余裕がある)。
    ただし実機では効果が見られず、オシレータを外してMCLK/BCK/LRCKを完全に止めても
    ノイズが変わらないことを確認したので、点状ノイズの原因はI2S信号の結合ではない。
    スルーレート設定自体は害がないので残す。
    host: noise_meter.py(新規) — 暗部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
    [retrocastx_stream.py]
2026-08-08 gateware: RGB入力を1段レジスタ化 + ノイズ切り分け用フラグ + ビットストリーム保管
    点状ノイズの原因切り分けのための一連の変更。測定は host/retrocastx/noise_meter.py
    (暗部の時間差分)で数値化し、静止画面で同一条件のA/B比較を行った。
    切り分け結果(temporal_std / 255):
    旧版 8f799d1 (I2SはP4、アナログRGBを横切らない) 6.97
    現行 + MCLK出力=0 (BCK/LRCKはP3でON) 9.42
    現行 + 実測カウンタ無効 (MCLK出力ON) 12.13
    現行 (全部ON) 12.29
    → 増えたノイズ(+5.32)は全て「P3に移したI2S信号がア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
    [retrocastx_capture.py, retrocastx_stream.py, sim_capture.py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]
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2026-08-08 client: ノイズ量の測定をViewerに内蔵(Statsに noise% / lvl を表示)
    暗部のフレーム間差分から点状ノイズを測る。静止した絵は差分に出ないので内容に
    ほぼ依存せずノイズ量だけを拾える。配線やパスコンを触りながらリアルタイムに
    効果を見たいが、host/retrocastx/noise_meter.py はUDPポートを占有するため
    Viewerを閉じる必要があり、閉じるとX68000を操作できない(モードも変えられない)。
    負荷を抑えるため4フレームに1回・4画素おきにサンプルする。noise_meter.py は
    中央値からのずれ、こちらは前フレームとの差なので値は完全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
2026-08-08 vbpが効かないバグを修正 + 有効映像の実測とpll_divの推奨値算出をViewerに追加
    gateware:
    - cfg_vbp から導く値(vs_row_at_sync/vactive/vs_min_rows)を「vtotalの安定判定が
    成立した1回」の中で代入していたため、vtotalが安定している間はvbpを変えても何も
    起きなかった(hs_offset/pll_divideは直接使うので効いていた)。毎サイクル更新する
    ようにして解消。
    - 最初は組合せにしたが、sysのレジスタからpixドメインへ減算器を挟んで渡る形になり
    eth_rxが130→116MHzに悪化してシード9まで探さないと通らなくなった。レジスタのまま
    毎サイ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
    [retrocastx_capture.py]
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2026-08-09 pll_divの推奨値が発散する原因を実測で特定し修正 + 実測ツールを追加
    症状: 「→ pll」を押すたびに 899→1101→999 とトグルして収束しない。
    原因は外接矩形のしきい値。行/列を「内容あり」とみなす条件が一律4画素で、512行
    のうち4行(0.8%)しか要求していなかった。この緩さだとノイズを内容と誤認し、同じ絵
    のまま外接矩形が 634→917 まで跳ねる。幅が跳ねれば推奨値も跳ぶ。
    pll_tune.py で同じ絵をしきい値を変えながら測ると、0.008では917、0.05〜0.5では
    どれも634で一致した。比で判定するよう変更(列=全行の20%、行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
2026-08-09 インターレースのフィールド偶奇を入れ替えられるようにし、実測で自動判定できるように
    円や斜め線がギザギザに見えるという指摘。原因はフィールドの偶奇の取り違えで、
    どちらのフィールドが偶数ラインを描いているかは信号に情報が無く、決め打ちでは
    50%外れる。CONFIG key 0x15 で入れ替えられるようにした(Viewerに swap チェック
    ボックス)。
    実測で確定した(24kHz 1024x848):
    f2_row=465 swap=0: ずれ 6.437
    f2_row=465 swap=1: ずれ 4.052 ← 正解
    f2_row=466 swap=0: ずれ 4.088
    f2_row=466 swap=1: ずれ 5.251
    f2_row を1増やすのと swap を反転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
    [retrocastx_capture.py, retrocastx_stream.py]
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2026-08-09 client: インターレースの織り込み方を自動判定する auto ボタンを追加
    3通りの候補を順に試し、フィールドのずれが最小のものを採用する。1候補につき
    約2.2秒(設定が効くまで0.9秒待ってから測定)、全体で約7秒。
    試すのは4通りではなく3通り。f2_row を1増やすのと swap を反転するのはフィールドの
    相対位置に対して打ち消し合うので、(half,swap=1) と (half+1,swap=0) は同じ配置に
    なる(実機の測定値も 4.052 と 4.088 でほぼ一致した)。f2_row は half ではなく
    0(=vtotal/2を自動で使う)を送り、モードが変わっても追従させる。
    判定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
2026-08-09 client: 読み戻しが手入力を上書きしていたのを修正
    数値を直接入力してもすぐ元に戻る、という報告。ボードの現在値を毎フレーム反映して
    いたため、send を押す前の変更が上書きされていた(未送信の変更は pending に入らない
    ので、こちらの値を優先する仕組みが働かない)。
    取り込みは起動時の1回だけにした。ずれ直したときのために「読む」ボタンを置き、
    押すとボードの現在値を取り直す。
    Claude-Session: https://claude.ai/code/session_0162b9sN79AXtfsukcfLLU5Z
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2026-08-09 client: hs_offsetの入力欄の上限を動的にしていたせいで値が化けるのを修正
    Viewerの表示・ボードの値・こちらが設定した値の3つが食い違い、hs_offset が
    160 → 607 に化けていた。
    原因は入力欄(DragValue)の上限を pll_div/2 から動的に決めていたこと。DragValue は
    範囲外の値を黙って書き換えて保持するため、読み戻しや pll_div の変更で範囲が動く
    たびに hs_offset が勝手に変わり、その値が送信されていた。上限が「他のフィールドに
    依存して動く」構造そのものが誤りだった。
    入力欄は固定範囲(0〜2304)に戻し、実際の上限(pll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
2026-08-09 client: 読み戻しのレースを修正(最後に届いた値を適用しないまま完了扱いになっていた)
    ボードは hs_offset=160 なのに Viewer は 1216 を表示し、「読む」を押しても変わらない
    状態になった。interlace など他のキーは読めているのに hs_offset だけ古いまま、という
    出方だった。
    原因は、値の適用に使うスナップショットと、完了判定で見るデータが別だったこと。
    let state = config_state.lock().clone(); // スナップショット
    for (key, val) in state { ...適用... }
    if TUNE_KEYS.all(|k| config_state.lock().contains_key(k)) { synced = true }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
2026-08-09 host: MODEを毎回取り込むよう修正(mode_idが同じだと更新せず古い実測値を見ていた)
    FrameAssembler が mode_id の変化でしか self.mode を更新していなかった。ボードは
    常に mode_id=1 を送るので、Board を作った瞬間の MODE がずっと残り、htotal や
    dotclk は最初の値のまま固定されていた。
    このせいで「pll_divide を設定しても反映されない」と何度も誤判定した。実際には
    1〜2秒で正しく反映されており、Viewer では最初から正常に見えていた。疑うべきは
    測定側だった。
    バッファの作り直しは寸法(hactive/vactive)が変わったときだけに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
2026-08-09 client: フルスクリーンモードで中間調が明るくなりすぎるのを修正(sRGBの二重符号化)
    映像テクスチャを Rgba8Unorm(リニア扱い)で作っていたため、サンプル時にsRGBの復号が
    行われないまま、出力段でサーフェス(macOSでは Bgra8UnormSrgb)がリニア→sRGBに符号化
    していた。符号化が二重にかかり中間調が持ち上がる(中間の128が186相当まで浮く)。
    暗部と白は変わらないので「全体が明るい」というより中間調だけ浮く出方になる。
    通常モードのeguiは ColorImage をsRGBとして扱うので、フルスクリーンだけ見え方が
    違っていた。テ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
2026-08-09 インターレースを設定から測定へ: TVPの検出ビットと生同期の位相で織り込む
    これまで il(方式) / f2_row(折り返し点) / swap(偶奇) / field_src(極性の取得元) /
    auto(内容から判定)を人手で設定していた。どれも「行番号で並べる」実装の都合から
    生まれたもので、信号自体には無かった情報である。実機で確認して不要にした。
    ## 判定: TVPの検出ビット(38h bit5)
    データシートに記述があった。"Progressive/interlaced video detection status. Not
    dependent on the H-PLL being locked. 0 = Interlaced video detected"。しかもこの
    レジスタは元から毎周期読んで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
    [retrocastx_capture.py, retrocastx_stream.py, sim_capture_interlace.py]
2026-08-09 窓の判定を折り返す前のrowで行う: 帰線期間の行が画面下部に出るのを修正
    vbp を下げると上が見えるようになるはずが、絵が上にずれて隠れていた部分が下から
    出てくる、という症状が出ていた。
    VSYNCで row には vtotal - vbp が入り、そこから増えて vtotal で0に戻る。つまり
    VSYNC直後の vbp 本は row が大きい(vtotal 931, vbp 18 なら row 913..930)。
    インターレースの折り返しを入れると、この row が折り返し点 f2_row(=465)を超えて
    いるため「第2フィールド」と判定されて frow が小さくなり、窓の外なのに範囲内と
    見なされてしまう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
    [retrocastx_capture.py]
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2026-08-10 プログレッシブで全行が奇数スロットへ入る不具合を修正
    31kHz 768x512(プログレッシブ)で、文字列が全行同じようにずれる症状が出た。
    「X68000のテキスト画面の高さに依存するとは考えづらいのに、なぜ綺麗にずれるのか」
    という指摘を受けて測定した。
    実測:
    MODE 2048x1112 total 1104x568 fH 31.499kHz fV 55.38Hz
    mflags bit0 0 ← 織り込んでいないと正しく申告
    38h bit5 1 ← TVPはプログレッシブと正しく検出
    生VSYNC位相 12 ← ライン境界付近
    生HSYNC周期 1103 ← htotal 1104 と一致
    内容のある行 偶数スロッ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
    [retrocastx_capture.py]
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2026-08-10 インターレースの手動設定を撤去し、管面の位置合わせをCRT風のスライダーにする
    X68000のモード0〜18すべてが無調整で表示されることを実機で確認できたので、
    インターレース関連の手動設定を撤去した。
    撤去したもの(ゲートウェア/Viewer/設定ファイル/CONFIGキー):
    il 方式の指定 key 0x13
    f2_row 折り返し点 key 0x14
    swap フィールドの偶奇 key 0x15
    field_src 極性の取得元 key 0x16
    auto 内容から判定する探索(weave_err を使った総当たり)
    どれも信号から測れる量だった。判定は3つの独立した測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
    [retrocastx_capture.py, retrocastx_stream.py, sim_capture_interlace.py]
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2026-08-10 行欠け/横ずれを修正: 範囲を row/ts と同じ瞬間にFIFO先頭から取る
    実機で 525行すべて一致(span_check 100%、対照実験も100%)。Viewerの画面でも
    行欠けが消えたことを確認した。
    原因は送信側でヘッダの値の取り方が揃っていなかったこと。
    row / ts / frame 送出開始時にFIFO先頭から直接スナップショット
    offset_px 先頭を毎サイクル追いかける2段レジスタ経由 ← これ
    両者が同じFIFOエントリを指す保証がなく、範囲だけが fifo_depth ライン遅れて乗って
    いた(depth 4→4ライン、8→8ライン の2点で確認)。内容のある行が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
    [default.kicad_pcb]
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2026-08-10 設定ファイルの置き場所をWindowsでも決まるようにする
    XDG_CONFIG_HOME → HOME の順にしか見ていなかったため、両方とも無い環境
    (Windowsでは普通)で PathBuf::from(".") へ落ち、カレントディレクトリに
    retrocastx/viewer.conf を作っていた。起動した場所ごとに設定が散らばる。
    APPDATA、無ければ USERPROFILE\AppData\Roaming を見る段を足した。Unix の
    挙動は変えていない(macOSで ~/.config/retrocastx/viewer.conf のまま)。
    Windows機(11 build 26200 / rustc 1.97.1 / x86_64-pc-windows-msvc)で
    ビルドとテスト10件が通ることを確認したうえでの修正。resvg / eframe+wgpu /
    cpa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
2026-08-11 SOG分岐にアンチエイリアスRCのパターンを置く(シュントは未実装)
    RGB各チャネルには 220Ω+33pF(fc≈22MHz)が入っているのに、SOG分岐は結合容量から
    SOGIN_3へ直結で高域が素通しだった。MSXのC-SYNCをSOGで受けた実測で、スライサ由来の
    H基準が入力の2倍になるグリッチが10〜33MHz帯にあることが分かっている
    (TVP内蔵のSOG LPFを10MHzにすると消え、33MHzでは消えない)。
    現状はその内蔵LPF(reg 1Ah)を有効にするだけで解決していて、実測で残っている問題は
    無い(noise 0.0%)。測定できる改善余地が無いのに部品を増やす必要は無い。一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
    [default.kicad_pcb]
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2026-08-12 受信バッファーの警告を起動時のモーダルにする(パネルは隠せるため)
    パネル内の表示だけでは「遊ぶときのモード」で気付けない。Tab で隠せるうえ、
    --fullscreen にはそもそもパネルが無い。実機で試したら、たまたまパネルを開いて
    いたから見えていた、という状態だった。
    **モーダルにするのは設定チェックのときだけ。** 実際に設定を読んでいて
    Unsupported / Unknown では絶対に出さないので誤警告の経路が無く、直せば二度と
    出ない一度きりの修正で、放置すると確実に映像に穴が開く。一方ロス率ベースの
    警告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
2026-08-12 33pFを0402(1005)へ小型化し、第2入力に残っていた未使用入力用の10nFを外す
    ## 33pF を 0402 へ
    映像入力のアンチエイリアス(220Ω+33pF)と水晶負荷容量に使っている33pFを
    0603(1608)から0402(1005)へ小型化した。映像入力が2系統になって個数が増え、
    基板面積が逼迫したため。C0G/NP0 は維持しているので、遮断周波数と負荷容量が
    温度・電圧で動かない性質は変わらない。
    SAMSUNG CL05C330JB5NNNC (33pF ±5% 50V C0G/NP0 0402) / LCSC C70465
    パッド位置が変わるため、これらに繋がっていた配線は削除された(引き直しが必要)。
    ## 設計バグの修正: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
    [C0402_L1.0-W0.5-H0.5.step, default.kicad_pcb]
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2026-08-12 Analog_RGB ネットクラスを 0.30/0.25 → 0.20/0.20 に緩和する
    映像入力が2系統になってTVPから引き出す本数とビアが増え、ファンアウト区間
    (既に0.127mmへ緩和済み)を出た後で詰まるようになったため。
    なお **ビアは緩和不要だった**。Analog_RGB の via は元から 0.45/0.25 で Default と
    同一であり、他クラスより厳しくはなかった。JLCPCB 4層の追加費用なし下限が
    まさに 0.25/0.45 なのでこれが下限。実際に詰まっていたのは clearance 0.30mm と
    track 0.25mm。
    緩めて大丈夫な根拠(数字で確認):
    直流抵抗 線幅 0.25→0.20mm で 100mm あたり 0.194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
2026-08-13 DRCの誤検出3種を潰す(ペア内スキュー/TVP7002サーマルビア/JP3ネットタイ)
    いずれも配線の問題ではなく、ルールとフットプリントの記述漏れだった。
    KiCad 9.0.5 のヘッドレスDRC(kicad-cli pcb drc)で修正前後を実測してある。
    総違反 699 → 659
    クリアランス違反 12 → 0
    はんだマスクブリッジ 14 → 0
    ペア内スキュー 14 → 2 (残りは本物)
    --- 1. GbE_diff ペア内スキュー: (within_diff_pairs) が抜けていた ---
    KiCad の skew 制約は既定で「マッチした全ネットを1グループとみなし、その中の
    最長ネットとの差」を見る(バ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
    [default.kicad_pcb]
2026-08-13 DRCエラー0件を達成する(未配線0・除外0)
    kicad-cli pcb drc --severity-error で独立に検証:
    エラー 0 件
    未配線アイテム 0 件
    DRC除外リスト 0 件 ← 何も除外して隠していない
    回路図との不一致 0 件
    f4db678 の時点で残っていたGbEの本物の違反も解消:
    ペア内スキュー eth1_4 2.171mm / eth2_1 1.650mm → 上限0.5mm以内へ
    非結合長 eth1_2 15.267mm / eth2_2 11.561mm / eth1_4 11.066mm → 上限10mm以内へ
    配線: segment 1579→1704、arc 88→74、via 300→381、zone 7(不変)。
    --- 残っている警告 294件(すべて warning、エラーではない) ---
    185 lib_foot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
    [default.kicad_pcb]
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2026-08-15 基板外形をちょうど 100.000 x 100.000mm にする
    Edge.Cuts の矩形の左端が 87.454 という半端な値で、X方向だけ 46µm 超えていた
    (右端 187.5 はキリのいい値なので、右端をグリッドに合わせた時に左端が残ったと思われる)。
    修正前 start 87.454, 49 → end 187.5, 149 = 100.046 x 100.000
    修正後 start 87.5, 49 → end 187.5, 149 = 100.000 x 100.000
    JLCPCB の4層は 100x100mm が価格の区切りなので、この46µmで一段上の枠になっていた。
    左端を動かしたので両端が 0.5mm グリッドに乗り、今後同じ食い違いが起きにくい。
    配線には影響なし(segment 1712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
    [default.kicad_pcb]
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2026-08-15 配線を仕上げてDRCエラー0件・未配線0件にする
    ファイルの塗りのまま error=0 / warning=200 / 未配線0
    ゾーン塗り直し後 error=0 / warning=200 / 未配線0 ← 同じ = 塗りは保存済み
    前回残っていた2件(C63とgndビアが0.1147mm、C41とC63が0.15mm)と未配線3件が解消。
    配線: segment 1788→1786、arc/via/zone/footprint は不変。
    --- .kicad_pro: シルク検査2種を ignore にした ---
    silk_edge_clearance warning → ignore
    silk_over_copper warning → ignore
    どちらも元から warning でエラーではないので、エラー0件の結論には影響しない。
    silk_overlap と text_height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
    [default.kicad_pcb]
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2026-08-17 配線を追加する(via 399→440、segment 1786→1794)
    GbE 354本 x 163.7〜174.2 / y 52.8〜104.7 総長637.4mm 基板外0本、
    generated 0個、FID1-3 も健在。等長配線の再発は無し。
    --- connection_width 1件は「直せない」ことが分かった ---
    ゾーンの輪郭の角を 0.5mm 面取りして試したところ、**指摘が面取りで作った新しい頂点へ
    そのまま移動した**だけだった:
    面取り前 (187.093749, 148.500144) 元の頂点 0.0789mm
    面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
    [default.kicad_pcb]
2026-08-17 v0.9.0 の製造データを出した時点のレイアウトを記録する
    CH347F への差し替えに入る前の区切りとして、いまのレイアウトをそのまま残す。
    segment=1793 via=440 footprint=202 zone=7
    DRC error=0 / 未配線0
    --- 製造データを一緒に追跡する ---
    Fabrication Toolkit で JLCPCB 向けの出力が生成されていたので、**発注した実物との
    対応が後から辿れるように**リポジトリに入れる:
    production/RetroCast_X_v0.9.0.zip ガーバー+ドリル
    production/bom.csv JLC実装用BOM
    production/positions.csv 実装座標(CPL)
    production/designators.csv
    p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
    [bom.csv, default.kicad_pcb, designators.csv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]
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2026-08-18 CH347F 周辺を配置・配線する(DRCエラー0件・未配線0件)
    ファイルの塗りのまま error=0 / warning=190 / 未配線0
    ゾーン塗り直し後 error=0 / warning=190 / 未配線0 ← 同じ = 塗りは保存済み
    segment 1793→1730 via 440→424 footprint 202→189
    基板外の未配置部品なし
    FT2232H を消した跡に残っていた未配線21件・宙ぶらりん配線25件・isolated_copper 1件も解消。
    残る警告は lib_footprint_issues 189件(製造に影響しない)と connection_width 1件
    (ゾーン隅の丸め由来。角がある限り出るので除外するしかない既知のもの)。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
    [default.kicad_pcb]
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2026-08-18 USB ESD(D9)を配置・配線する(DRCエラー0件・未配線0件)
    ファイルの塗りのまま error=0 / warning=191 / 未配線0
    ゾーン塗り直し後 error=0 / warning=191 / 未配線0 ← 同じ = 塗りは保存済み
    D9 (100.75, 134.00) 回転90° segment 1730→1743 via 424→426
    ## pin1-6 / pin3-4 の配線について(私の説明の誤りを訂正)
    USBLC6-2SC6 は pin1/pin6 が同じ I/O1 ノード、pin3/pin4 が同じ I/O2 ノードで、
    パッケージ内部で短絡されている。KiCad が出していたラッツネストは
    「同じネットなのに銅で繋がっていない」という指摘で、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
    [default.kicad_pcb]
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2026-08-19 生基板 v0.9.0 を発注し、デジグネータを凍結する
    基板 100.000 x 100.000mm / 4層 / 1.6mm / ENIG
    部品 190個
    DRC error 0件 / warning 192件 / 未配線 0件
    (ファイルの塗りのまま・ゾーン塗り直し後とも同じ = 塗りは保存済み)
    製造データ layouts/default/production/RetroCast_X_v0.9.0.zip
    ## デジグネータを凍結した
    tools/lock_designators.py --freeze v0.9.0 で190部品を designator_lock.json に記録。
    接頭辞13種の最大値: C85 D9 FB3 FID3 H5 J12 JP1 LED1 PG4 R46 TP2 U16 X3
    以後 ato build のたびに tools/lock_designators.py を走らせれば、一度使った番号は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
    [6.STEP, bom.csv, default.kicad_pcb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]
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2026-09-02 litex の eth index とコネクタ表記の入れ替わりを訂正する
    v0.9.0 で J11 に繋いだところ、**L1 リンクは上がるのに ARP も ping も
    返らない**という形で出た。原因は eth index の取り違えで、gateware と
    main.ato の両方が逆に書いていた。
    litex_boards の colorlight_i5.py に明記されている:
    "The order of the two PHYs is swapped with the naming of the connectors
    on the board so to match with the configuration of their PHYA[0] pins."
    したがって正しい対応は:
    platform.request("eth", 0) = コネクタ ETH2 = eth2_*(偶数ピン) = J11
    platform.request("eth", 1) = コネクタ ETH1 = eth1_*(奇数ピ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
    [retrocastx_stream.py]
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2026-09-03 bitstore.sh のJTAGケーブルを CH347 にする
    v0.9.0 基板はポゴピン経由の CH347 アダプタで繋ぐ。オンボードの CMSIS-DAP は
    手組みボード時代のもので、もう使わない。決め打ちのままだと
    "JTAG init failed with: Error: no USB backend available" で止まり、
    原因が分かりにくいので CABLE= で上書きできるようにもしておく。
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2026-09-03 下端の階調が消える原因を特定し、黒判定の閾値を実行時に振れるようにする
    X68000 の32階調のうち下2段が受信側で 0 になる件。アナログでもクランプでも
    なく、**送出範囲を決める非黒判定**が原因だった。
    self.cfg_black_th = Signal(5, reset=2)
    return ((p[3:8] > self.cfg_black_th) | ...) # p[3:8] = code>>3
    code>=24 でないと非黒にならないので、暗い「絵の中身」が範囲から外れる。
    範囲外の画素は送信されないため受信側は 0 のまま。画素は失われる前に、
    そもそも送られていなかった。
    ## 切り分け
    RGB888 に切り替えて段ごとの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
    [retrocastx_capture.py, retrocastx_stream.py]
2026-09-03 ゲイン既定の実効値を直す + 校正ツールに読み戻しを実装する
    ## ゲインの既定が効いていなかった
    細ゲインの既定を 64/61/57 に揃えたつもりだったが、焼き直してもボードは
    39/33/35 のままだった。**四箇所目があった:**
    gateware/retrocastx_stream.py cfg_gain_r/g/b ★電源投入時の実効値
    gateware/retrocastx_i2c.py cfg_gain_r/g/b 上に comb で上書きされる(死んでいる)
    client/src/profiles.rs REGS_X68000
    client/src/main.rs tune_gain_*
    SoC の結線に `status.cfg_gain_* <- streamer.cfg_gain_*` が平文の comb であり、
    i2c 側の reset は毎サイクル上書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
    [retrocastx_i2c.py, retrocastx_stream.py]
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2026-09-05 タイミング検査がルーティング後の最終値だけを見るようにする
    初回の CI 実行(手動)が、**タイミングを満たしているビルドを落とした**。
    nextpnr は Max frequency を2回出す。配置後の見積りと、ルーティング後の最終値。
    見積りの方は通っているビルドでも普通に FAIL していて、実際こうなっていた:
    配置後の見積り crg_clkout 44.62 MHz (FAIL at 45.00 MHz)
    ルーティング後 crg_clkout 55.27 MHz (PASS at 45.00 MHz) ← 本当の結果
    検査がログ全体を grep していたので、見積りの FAIL を拾って落としていた。
    retrocastx_stream.py の --seed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
2026-09-05 Viewer を 0.2.0 にする
    v0.1.0 (2026-08-12) 以降、client/ に 50 コミット入っているが、Cargo.toml の
    version が 0.1.0 のままでリリースタグが打たれていなかった。破壊的変更は無く
    機能追加が複数なので 0.2.0 とする。
    主な未リリース分:
    - 簡易スキャン(全候補を測って位相感度が最強の点を採る)
    - ドット復元、細ゲイン調整UI、伝送形式の表示と切り替え、RGB888のドット復元
    - SUBSCRIBE を NIC ごとのサブネット宛に出す(VPN下で届かない件)
    - --bind オプション
    - 768x512 が 768x1024 と表示される不具合の修正
    - 暗部が潰れる件(映像テクスチ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
2026-09-06 Viewer 0.2.1
    viewer-release.yml は client/Cargo.toml の version をバージョンの正としていて、
    タグと食い違うと prepare で止まる。v0.2.1 を打つ前に上げておく。
    内容はフィールド極性の修正一式(コンポジット/S端子で no_raw_phase を書く、
    電源投入直後の pll_divide 上書きの修正、同期まわりの診断表示)。
    ★ゲートウェアと**対で出す必要がある**。Viewer が CONFIG key 0x6A を書かないと
    ゲートウェア側は既定0のままで、フィールド極性の修正が効かない。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
2026-09-22 フットプリントの実寸化とシルクの修正、差し替え手順のツール化
    ## ミニDIN8(J13)のランドが隣と短絡していた
    マル信 MJ-373/8B の図面どおり φ1.2 の穴に**円形 φ2.0 のランド**を付けていたが、
    **最小ピン間隔は 1.75mm**(5↔2 / 1↔3 / 4↔6)なので銅が 0.25mm 食い込んでいた。
    変更前 φ2.0 円形 / drill 1.2 リング0.40 隙間 -0.25 ✗
    変更後 1.9 x 1.5 オーバル / drill 1.1 リング0.20 隙間 +0.25 ✓
    端子は 0.8 x 0.4 の平打ち(部品表 C5191 t=0.4)で対角 0.894mm。JLCのPTH穴公差
    ±0.076 で最悪 1.024mm でも 0.13mm の余裕がある(φ1.0 まで詰めると最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
    [default.kicad_pcb]
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2026-09-25 PLR135/T10 のランドの向きを直す(取付穴が信号列の逆側だった)
    取付穴は**信号列と光ポート開口部の「あいだ」**にある。信号列がいちばん奥で、
    そこから +2.62mm が取付穴、+11.11mm が開口面。信号列の後ろには 2.39mm しか
    胴体が無い。`PLR135_T10.kicad_mod` はこれを -2.62mm 側に描いていたので、
    現物のポストが入らない。
    修正前 信号列 Y=0 取付穴 Y=-2.63 胴体 -3.85 .. +9.65 幅 8.60
    修正後 信号列 Y=0 取付穴 Y=+2.62 胴体 -2.39 .. +11.11 幅 9.70
    `PLR135_T.kicad_mod`(v0.9.0 の /T 版)は取付穴を +3.95mm と正しく描けていた
    ので、**/T1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
2026-10-09 NTSC で映像が壊れる2件を直す(vtotal 安定判定 / TVP RESETB のグリッチ) (#36)
    * vtotal の安定判定が NTSC で成立せず映像が出ないのを直す
    #34 で入れた「VSYNC ごとに vtotal が4回連続で完全一致したら採用」は、
    NTSC(コンポジット/S端子)ではフィールドごとに 262/263 が交互に来るため
    一度も成立せず、meas_vtotal_stable が 0 のまま残ってモードが決まらず
    映像が出なかった(音は出る)。X68000(プログレッシブ)でしか確かめて
    いなかった。
    ±1 の違いは同じとみなし、候補は大きい方を取る。cfg_vtotal 側が
    「交互の大きい方に張り付け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
    [retrocastx_capture.py, retrocastx_i2c.py, sim_vtotal_glitch.py]
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2026-10-09 Viewer: 前面で映像を受けている間は OS をスリープさせない
    ゲームはパッドで操作するので Mac/PC 側には入力が無く、しばらく遊んで
    いるとアイドル扱いで画面が消えてスリープに入っていた。動画プレイヤーと
    同じ流儀で、Viewer のどれかの窓が前面にあり、その窓が映像を受けている
    間だけ止める(src/awake.rs)。
    - macOS: IOKit の電源アサーション PreventUserIdleDisplaySleep。
    `pmset -g assertions` に "RetroCast X (showing video)" で出る。
    名前を日本語にすると pmset に空で表示されたので ASCII にした
    - Windows: SetThreadExecutionState(ES_DISPLAY_R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
2026-10-10 TODO: PS2 コンポジットの縦揺れは SOG 測定の凍結だったと記録する
    10〜20秒周期の揺れは gw-v0.9.4 で RESETB のグリッチとして直したが、
    2026-10-10 の再発は SOG の垂直検出が HSOUT と重なって凍る別の原因だった。
    見分け方(sog_vlines / sog_vphase)を残す。
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2026-10-12 CI: macOS の staple を再試行する
    公証済みチケットを CloudKit から取る段階が "The network connection was lost"
    (Error 68)で落ちることがあり、v0.9.0 では2回続けて落ちた。30秒おきに5回まで
    やり直す。
    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
2026-10-25 JLC の BOM/CPL 警告を消す(手ハンダ部品とフィデューシャルの除外属性)
    - 小亀基板: 手ハンダの J2-J6(RCA105)、J7(MJ373_4B)、TP1/TP2 の
    フットプリントに exclude_from_bom を付けた。BOM は LCSC 品番のある
    部品だけになる。ato build は手作業のシルク修正を戻すので、基板上の
    8個は属性だけを直接書き換えた
    - 両基板: フィデューシャル FID1-FID3 に exclude_from_pos_files を追加。
    BOM からは除外済みなのに CPL にだけ載っていたため、JLC が
    「FID1,FID2,FID3 designators don't exist in the BOM file」と警告していた。
    フィデューシャルは銅箔とし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
